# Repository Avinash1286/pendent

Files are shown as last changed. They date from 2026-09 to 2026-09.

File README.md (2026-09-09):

# AURA / pendent

**Capture the context of your life.**

[Explore the A03 showcase](https://pendent-eight.vercel.app) · [Watch the A03 film](https://pendent-eight.vercel.app/film/aura-launch.mp4) · [Download the A03 release](https://github.com/Avinash1286/pendent/releases/tag/a03-context-dev) · [Run the notes portal](portal/README.md)

An open product-development project for a compact necklace AI note-taking device. Electronics, printable industrial design, chip firmware, local transcription, a Next.js / Convex notes portal, an interactive Three.js showcase and a Hyperframes launch film live together here.

## A04 circular redesign — in progress

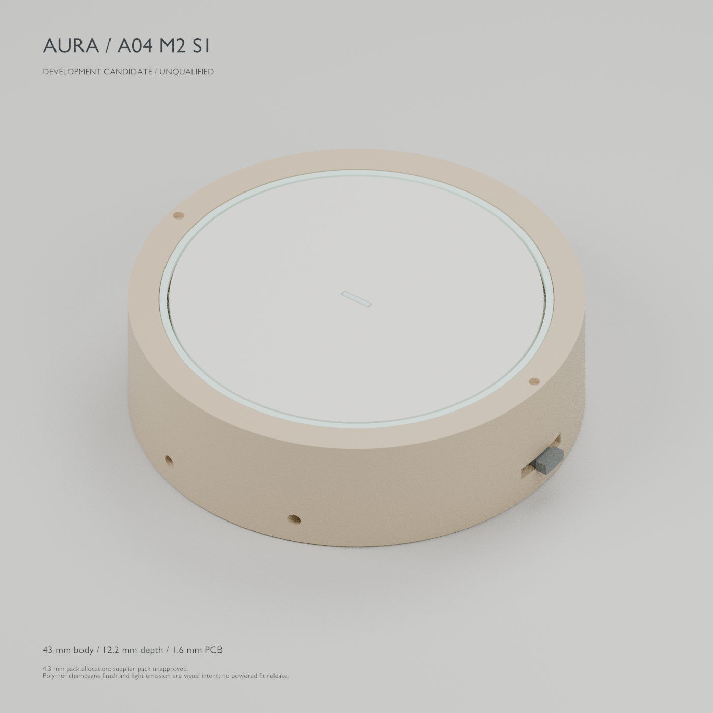
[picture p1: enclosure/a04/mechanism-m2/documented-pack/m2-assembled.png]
AURA A04 M2 S1: actual 43 mm circular development mechanism, pale face and champagne-looking polymer finish; unqualified engineering candidate


A04 is a fresh circular design created through **KiCad MCP**, with a physical microphone disconnect, separate update-storage hardware and a source-preserving audio protocol. The current M2 mechanism is **43 mm across and 12.2 mm deep**, accommodating the actual 1.6 mm draft PCB and a 4.3 mm pack allowance. An 11.2 mm variant requires an unselected thinner pack. The earlier 40 × 10 mm goal remains an aspiration, not the dimensions of these files. **A04 is not ready to fabricate, print as a complete device, wear or sell.**

[Full objective and evidence gates](docs/a04/requirements.md) · [New KiCad project](hardware/a04/aura-a04.kicad_pro) · [Mechanical contract](docs/a04/industrial-design.md) · [Software contract and recovery tests](docs/a04/software-contract.md) · [Omi source review](docs/research/omi-review.md)

The current checkpoint includes a **72-reference schematic candidate**, monitored microphone driver, bounded audio FIFO, recorder, shared C/Python Opus archive, recoverable NAND journal and SPI command core. The [storage owner and release outbox](firmware/a04/STORAGE.md) now reserve capture identities and release explicitly authorized recordings through a durable grant, with real C/Python audio round trips on modeled NAND. The nRF52840 DK build records linked memory and symbols in [the current wired-bench ELF resource report](firmware/a04/bench/verification/arm-resources.json). Host checks cover driver faults, privacy/stop ordering, capture boundaries, interrupted writes and preserved audio during storage reuse. The companion passes 131 tests; the earlier portal checkpoint retains 24. The schematic still has one ERC error, nine warnings and three net-name mismatches; the board is not placed or routed. [Native capture evidence](docs/a04/native-capture-verification.json) · [Firmware and audio evidence](firmware/a04/README.md) · [Route to your first physical wearable](docs/research/aura-first-wearable.md).

The working local software path now takes a **real C-generated audio archive through local Whisper transcription into Next.js/Convex**. It preserves the original capture, exact audio duration, bookmarks and transcript provenance. Interrupted captures remain explicit, and token rotation does not duplicate an existing source. These checks use synthetic speech; microphone, Bluetooth and worn-device behavior still need physical validation. [Try the archive importer](companion/README.md#a04-archive-import--040) · [Read the verification](companion/VERIFICATION.md) · [Portal provenance and recovery](docs/a04/portal-provenance.md).

The new [first spoken-note bench](firmware/a04/bench/README.md) provides a separate nRF52840 DK application, reviewed microphone/NAND wiring and a UART capture/export tool. It connects the actual drivers and storage code, with explicit recording permission and verified local publication. The image cross-builds; 31 host-client tests and five C orchestration groups cover its software behavior. **No physical audio has been recorded or board flashed.** This prepares the hardware experiment needed before the custom PCB and wearable can be qualified.

The [native Android companion](mobile/android/README.md) provides a local recording library: select an A04 archive, validate its original bytes and Opus audio, listen back, write context, and explicitly copy/share that context with an AI chat. The new [durable download store](mobile/android/DOWNLOADS.md) commits exact source records and resume metadata together, replays saved prefixes after reopening, and passes completed downloads through the library's actual decoder and publication checks. The current [development APK](https://github.com/Avinash1286/pendent/releases/tag/a04-android-recovery-dev) passed **29 Android emulator cases / 428 assertions**, with zero lint findings. The shared complete/incremental validator and transfer codecs pass **30 JVM groups / 82,213 checks**, including six incremental groups / 49,471 checks and 19 complete C-generated archives. The real Android GATT path also passed **four virtual-link cases / 33 assertions at each of MTU 23 and 517**, including a second connection without duplicate library entries. The peripheral is a Python fixture, not Zephyr firmware or physical radio. Original recordings and physical-OPEN provenance remain preserved. The Activity still exposes file import; Bluetooth download is not yet a user-facing feature. [Verification](mobile/android/VERIFICATION.md).

A [bounded journal cursor](firmware/a04/JOURNAL-CURSOR.md) prepares pendant-to-phone recovery: exact-record resume, at most one NAND read per step, source checks before streaming and again before completion, and cancellation that preserves the original recording. It is exercised through the wired DK export path. A portable [transfer command owner](docs/a04/transfer-wire-v1.md) adds ordered retries, owned capture selection and protection against stale response callbacks; 12 C test groups pass. Android now has the durable source store, library handoff and [foreground recovery owner with a native GATT client](mobile/android/RECOVERY.md). The device radio DK adapter is now implemented separately; owner enrollment, matching Android proof integration and consumer UI remain, followed by physical recovery and OS background qualification. [Transport integration plan](docs/a04/mobile-transport.md).

The new [authenticated Bluetooth DK application](firmware/a04/radio/README.md) integrates the actual transfer engine with the recording/storage owner. It adds a physically bounded pairing window, authenticated LE Secure Connections and fresh owner proof before archive access. Eighteen GATT/transfer groups, twelve C authentication groups and nine pairing-policy groups pass with their documented modeled boundaries. The ARM image uses 243,652 bytes RAM, leaving 18,492 bytes unallocated; runtime headroom is unmeasured. [Download the DK development build](https://github.com/Avinash1286/pendent/releases/tag/a04-radio-dk-dev). Consumer enrollment, the matching Android proof exchange and physical radio/capture trials remain; the older Android/Bumble tests do not execute this firmware.

The **M2 S1 mechanism** keeps the removable bezel and supported PCB, replacing inadequate resin bending links with a separate steel shoe/support and insulating contact pad. Each depth variant contains **12 polymer part models, three hardware form models and two unpowered gauges**. The metal/film forms are not functional resin-print instructions. Mesh and sampled motion checks cover the revised assembly; analytical force screening supports further unpowered joint testing. Materials, tolerances, switch endpoints, all 72 native PCB features, the battery and real assembly remain unqualified. [Blender source, parts and checks](enclosure/a04/mechanism-m2/README.md) · [Steel development drawings and 1:1 DXF profiles](enclosure/a04/mechanism-m2-manufacturing/README.md) · [Earlier process coupon kit](enclosure/a04/coupon/README.md).

<details>
<summary>Inspect the A04 M2 experimental parts</summary>

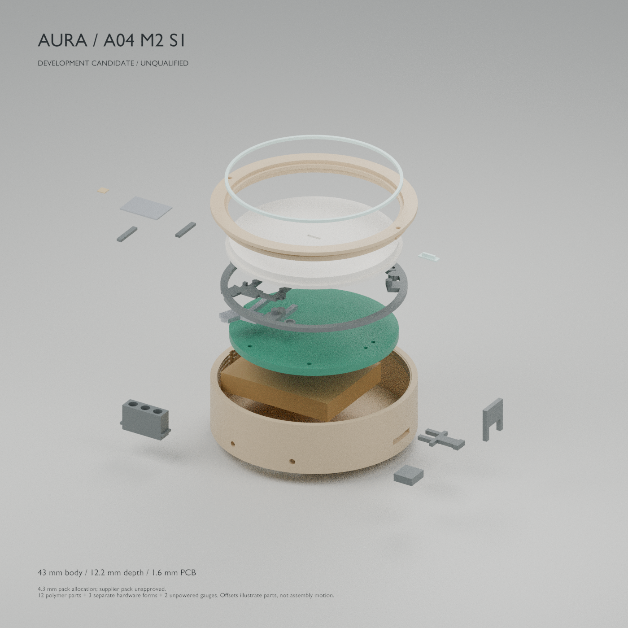
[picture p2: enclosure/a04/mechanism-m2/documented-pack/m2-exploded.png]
Actual A04 M2 S1 experimental part meshes; green board and ochre pack are unpowered fit gauges, not electronics


The exploded offsets show individual parts; separate motion reports check sampled assembly paths. Read the [remaining assembly and release gates](enclosure/a04/mechanism-m2/README.md#assembly-and-release-gates) before using these files. The [M1 experiment and its failures](enclosure/a04/mechanism/README.md) and [original 40 mm appearance study](enclosure/a04/study/aura-a04-study.png) remain available as earlier work.

</details>

The website, film, PCB and eight-part print kit linked below belong to the earlier **A03 development release**. They are retained for reproducibility and are not A04 deliverables.

## A03 development release

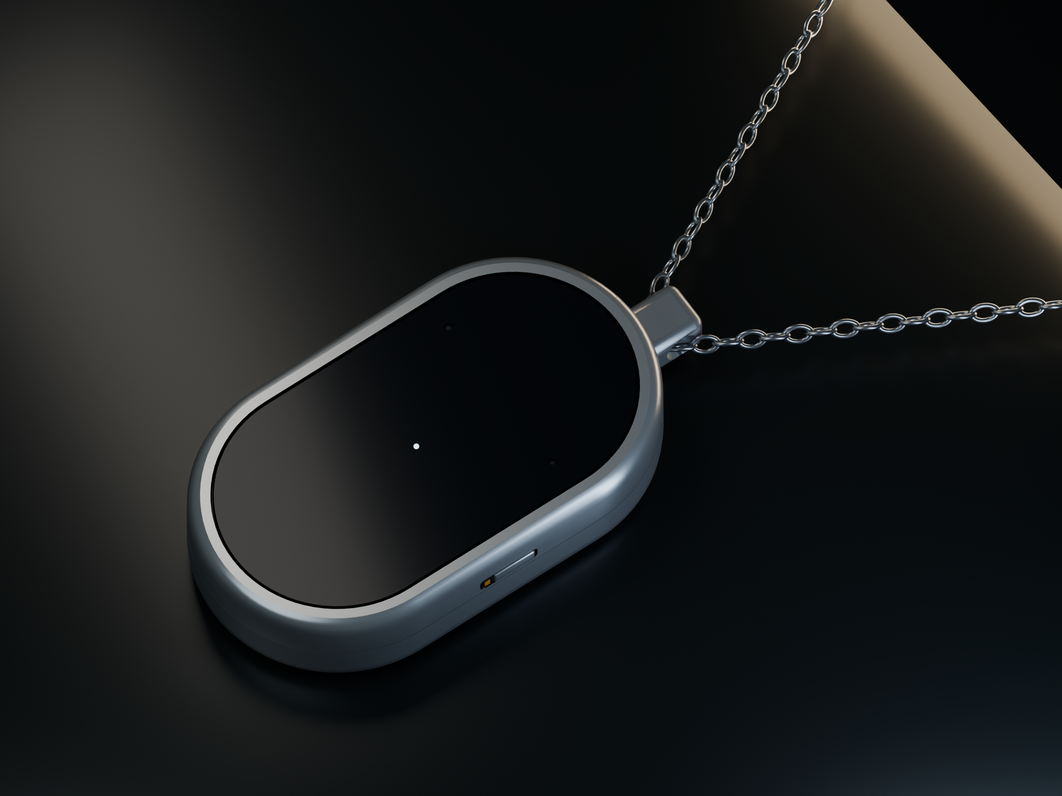
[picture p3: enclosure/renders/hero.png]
AURA A03 capsule pendant with a glossy black recording face, satin surround and necklace chain (https://pendent-eight.vercel.app)


## Launch film

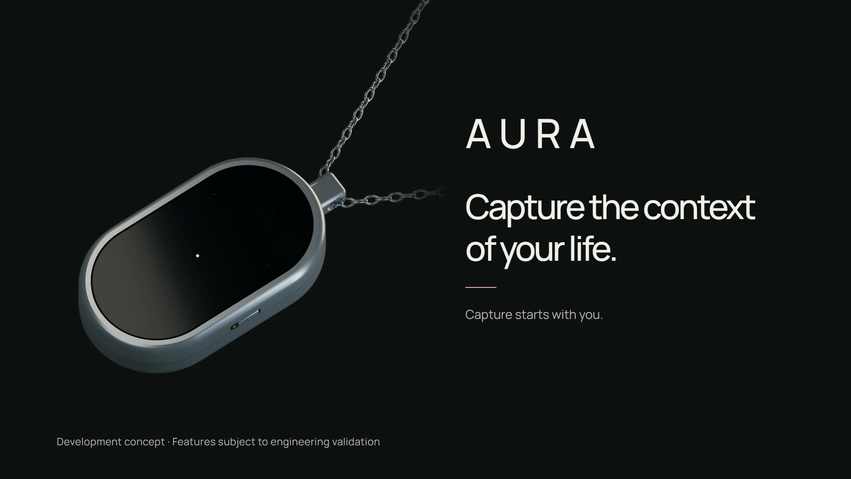
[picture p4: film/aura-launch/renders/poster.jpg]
Play the AURA launch film — Capture the context of your life (https://pendent-eight.vercel.app/film/aura-launch.mp4)


**[▶ Watch the 44-second film](https://pendent-eight.vercel.app/film/aura-launch.mp4)** · [Download the 1080p MP4](https://github.com/Avinash1286/pendent/releases/download/a03-context-dev/aura-launch.mp4) · [Hyperframes source](film/aura-launch/README.md)

See the pendant from the outside in, including its interior and assembly animation. Click the poster to play.

## 3D-printable parts

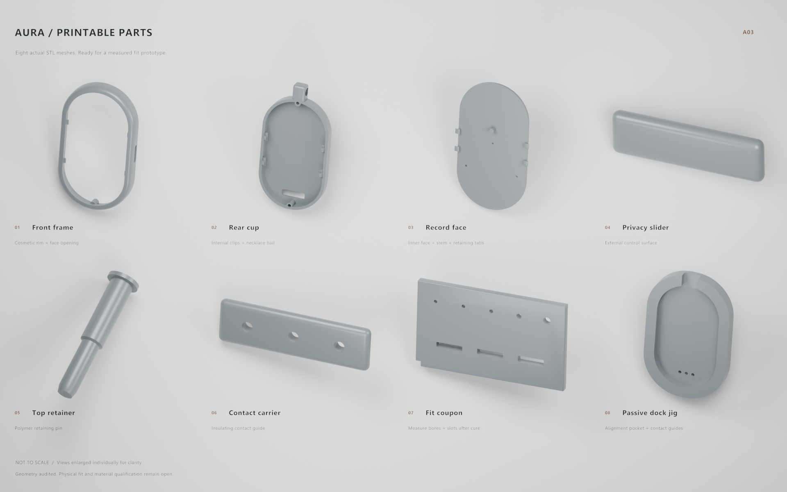
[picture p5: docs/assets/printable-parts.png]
The eight printable AURA parts: front shell, rear shell, recording face, privacy slider, top retainer, contact carrier, fit coupon and dock alignment jig


Rendered from the actual STL files; individual views are not to scale. The kit includes six device parts and two fit/alignment tools. STL units are millimetres; print orientation and material guidance are in the assembly guide.

[Download all eight STL files](enclosure/aura-a03-print-kit.zip) · [Print and assembly guide](enclosure/PRINTING.md) · [Editable Blender scene](enclosure/aura-product.blend)

## PCB

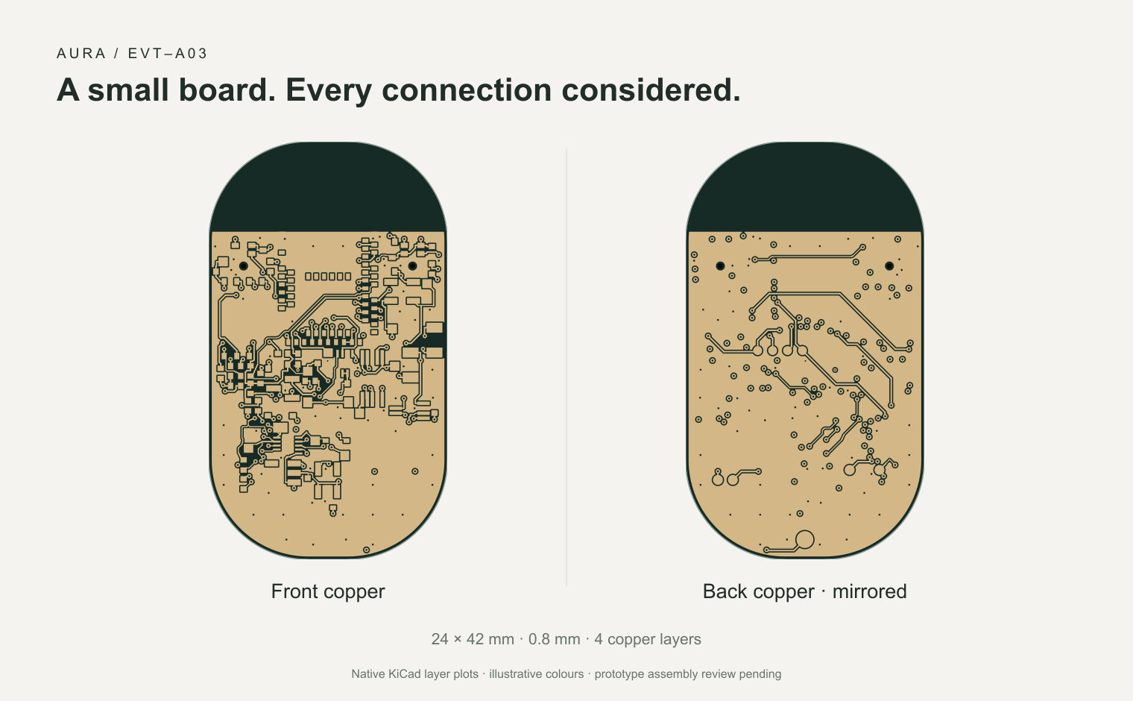
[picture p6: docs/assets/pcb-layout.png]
AURA A03 PCB front and mirrored back copper layouts, exported from the released KiCad board


The **24 × 42 × 0.8 mm, four-layer board**, shown directly from its native KiCad copper layers with illustrative colours. These are prototype files; the 78 courtyard findings still require assembly review.

[Editable KiCad project](hardware/native/aura-a03.kicad_pro) · [Prototype fabrication ZIP](hardware/output/aura-a03-prototype-fabrication.zip) · [Schematic and review files](hardware/native/review/)

## Project status

**A03 context and assembly edition.** [Prototype fabrication files](hardware/native/README.md) are exported from the paired KiCad project: zero unconnected items, schematic mismatches, ERC findings or bare-board DRC errors. **78 unsuppressed courtyard overlaps remain for assembly review.** The case has printable meshes with geometric audits; real fit, battery, acoustic and RF tests remain. Firmware is compiled for the nRF52840 but has not run on an assembled AURA. The notes portal uses real local Convex; cloud setup awaits account terms acceptance. This is not a manufactured or certified device, and no orders or payments are accepted. See the [current release guide](docs/release-a03-context.md) for downloads and verification.

## Project map

New: [Omi codebase review and AURA first-wear plan](docs/research/omi-review.md), with a source-based comparison, all 78 assembly collisions classified, and companion recovery improvements. This review identifies a real component-tolerance conflict that requires an A04 placement revision; it does not qualify A03 for assembled-unit ordering.

| Directory | Contents |
| --- | --- |
| `hardware/` | tscircuit source, routed native KiCad board, readable schematic, BOM and validation evidence |
| `enclosure/` | Blender source, editable generator, printable enclosure meshes, GLB and product renders |
| `firmware/` | Zephyr nRF52840 firmware, reproducible tool setup, flashable build artifacts and native tests |
| `companion/` | Bluetooth sync, CRC verification, local Whisper transcription and optional portal upload |
| `mobile/android/` | Native Kotlin local import, durable download storage and replay, verified playback, private context and explicit sharing; A04 wireless integration pending |
| `portal/` | Next.js / Convex private notes, profiles, Context Pack and read-only MCP endpoint |
| `website/` | Interactive React / Three.js product presentation, deployed directly to Vercel |
| `film/` | Hyperframes composition, original soundtrack and rendered launch video |
| `docs/` | Hardware and product engineering notes |

## Design direction

- 48 × 28 × 10 mm capsule body, 54 mm tall including the bail; 24 × 42 mm PCB.
- A glossy black recording paddle in a satin polymer surround, a bookmark gesture, visible microphone-power indication and a physical privacy slider.
- A physical microphone power disconnect, offline local audio storage and Bluetooth transfer to the companion.
- Dual digital microphones, a protected rechargeable-cell candidate and rear contacts for a magnetic charging dock; the complete dock remains to be designed and qualified.
- Local computer transcription and optional notes upload are implemented. The A04 Android source-import and durable download-storage foundation is available; device-to-phone wireless integration remains future work.
- 16 kHz mono PCM storage has an ideal capacity of about 66 minutes before bad blocks and metadata; battery runtime is unmeasured.

## Start exploring

- [Product and interaction specification](docs/product-design.md)
- [Hardware source and validation](hardware/README.md)
- [Print and assembly guide](enclosure/PRINTING.md) · [eight-part print kit](enclosure/aura-a03-print-kit.zip) · [editable Blender scene](enclosure/aura-product.blend)
- [Firmware build / flash / bring-up](firmware/README.md)
- [Install the local companion](companion/README.md)
- [Run AURA Notes and connect any AI](portal/README.md)
- [Launch film and reproducible Hyperframes source](film/aura-launch/README.md)

The portable **Context Pack** combines your selected notes, source excerpts, personal background and current goals into reviewed Markdown. Copy or attach it in ChatGPT, Claude, Gemini, Grok, or another chat. Compatible MCP clients can instead read explicitly approved live context through a revocable bearer token. Provider buttons do not send data automatically.

## Publication

Sources and generated deliverables are shared here. Website deployment uses Vercel directly; this project does not use GitHub Actions. Dependencies, signing keys, tokens, private local recordings and database files are intentionally excluded. Each workstream documents reproducible setup and the checks actually completed.

## Upstream tools

[tscircuit documentation](https://docs.tscircuit.com/) · [Blender](https://www.blender.org/) · [Three.js](https://threejs.org/docs/) · [Hyperframes](https://github.com/heygen-com/hyperframes) · [Vercel](https://vercel.com/docs)

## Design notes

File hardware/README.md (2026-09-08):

# AURA pendant electronics · EVT-A03

Start with the [paired native KiCad project and manufacturing guide](native/README.md). It contains the routed 24 × 42 × 0.8 mm four-layer board and readable six-sheet schematic for the 48 × 28 × 10 mm capsule.

**The board is connected; assembly qualification remains open.** Native schematic verification matches 61 references, 43 intended nets, 208 connected pins and 37 intentional NC pins, with zero ERC findings. Final native DRC, exports and their exact limitations are in [`native/review/`](native/review/). Courtyard/assembly findings remain visible. A connected board and valid fabrication files do not establish a qualified assembled wearable.

## Open or manufacture a prototype

Open [`native/aura-a03.kicad_pro`](native/aura-a03.kicad_pro) in KiCad 10. See [fabrication files](native/fabrication/), [BOM, positions and stencil files](native/assembly/) and [review PDFs/reports](native/review/). Read the native manufacturing guide before sending any files to a supplier. Use the matched Gerbers, PTH/NPTH drills and stack specification from the same package.

The native project carries exact per-reference footprint snapshots, portable library paths and schematic/PCB UUID links. The tscircuit export is a placement reference; it is not a substitute for the completed native routing. Keep the native project as the authority when changing copper, and reconcile source/firmware/enclosure contracts when changing circuitry or component placement.

## Reproduce the authored design

```sh
npm ci
npm run build
npm run export
npm run verify-export
npm run verify
```

Node 22+ and the project-local Bun runtime build the authored tscircuit schematic/placement and logical checks. The native reconstruction repairs the converter's electrical-label, NC, electrical-type and library-reference omissions; see the [schematic audit](../docs/schematic-audit.md). The generated `output/aura.kicad_sch` remains a superseded converter diagnostic, not the current schematic.

KiCad MCP was used for native schematic work. Its SES import returned an unexplained cancellation. The user explicitly authorized the source/CLI fallback, after which the native session was imported and the remaining routes, antenna exclusion and ground connectivity were completed. Historical KRT/Freerouting attempts are retained as evidence; they are not the current fabrication files.

## Files and verification

- `src/design.ts`, `AuraPendant.tsx`, `placement-overrides.json`: selected components, logical pin maps, mechanical contract and current component positions.
- `native/`: paired editable release project and its manufacturing/review exports.
- `library/`, `library.pretty/`, `pcb-snapshot.pretty/`: original lands, authored custom contacts/SiCap lands and exact native snapshots. [Attribution](library/NOTICE.md).
- `output/aura-a03-native-routing.kicad_pcb`: frozen working route used to create the paired project.
- `output/aura-a03-electrical.kicad_sch`: original native reconstruction, retained with its independent ERC and exact netlist audit.
- `scripts/pair-native-project.py`, `scripts/export-native-package.py`: native project pairing and guarded export entry points. KiCad's Python provides `pcbnew`.
- `scripts/package-status.mjs`, `scripts/package-native-archive.py`: verify current export hashes and produce the portable [prototype fabrication ZIP](output/aura-a03-prototype-fabrication.zip) with its [checksum report](output/aura-a03-prototype-fabrication-manifest.json).
- `scripts/audit-native-pad-spacing.py`, `scripts/audit-native-via-apertures.py`: actual native copper/paste geometry checks; both accept `--board native/aura-a03.kicad_pcb`.
- [Hardware dossier](../docs/hardware.md), [electrical review](../docs/electrical-review.md), [thermal review](../docs/thermal-review.md): rationale, source evidence and physical qualification work.

Optional routing-analysis scripts use the pinned packages in `requirements-native.txt`, installed into the ignored `tools/python/` directory with Python 3.11. They are dependencies, not design artifacts. The original routing experiments also use [Freerouting 2.4.1](https://github.com/freerouting/freerouting/releases/tag/v2.4.1) and Java 25. The JAR SHA-256 is `251101c3eeac22d7e7dfcf6796603279e5d1000283eb82d8f093780f7afc6aa9`; keep it in `tools/`. It is excluded from Git. See `scripts/route-freerouting.ps1` for bounded execution and optimization settings.

The [firmware](../firmware/README.md) performs local recording, recoverable storage and Bluetooth transfer. The [desktop companion](../companion/README.md) performs local transcription and optional transcript upload to [AURA Notes](../portal/README.md). No language model runs on the pendant. Physical power, battery, audio, RF, fit and security qualification remain outstanding; the supplied firmware keeps charging and haptics disabled pending those measurements.

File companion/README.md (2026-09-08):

# AURA local companion

Python3.12, Bleak3 and faster-whisper. The companion transfers committed audio from AURA, checks each packet and the complete recording, creates a normal WAV, and transcribes locally. It runs on Windows, macOS and Linux with a supported Bluetooth adapter. It is a desktop companion; this package is not an iOS/Android app.

## A04 archive import — 0.4.0

The new local file path connects the C Opus encoder's **experimental revision-3 archive** to verified audio, transcription and portal provenance. It does not provide A04 Bluetooth or firmware for a physical pendant. A03 `scan`/`sync` commands below still use their original v1 protocol; old experimental v2 and AOC1 test-container bytes are rejected by this importer.

From `companion/`, with the pinned dependencies installed:

```sh
uv run --locked aura import-capture ../firmware/a04/fixtures/capture-20ms.aura --output recordings
uv run --locked aura import-capture ../firmware/a04/fixtures/capture-20ms.aura --output recordings --transcribe --model tiny.en --language en
```

These checked-in fixtures contain synthetic test speech. The second command runs real local Whisper transcription; initial model download may require network access. Add `--upload` only when you want the resulting text and provenance sent to your configured portal. `--upload` requires `--transcribe`. Raw audio remains local.

Import verifies a bounded archive snapshot, commits the complete source and terminal receipt in SQLite, exports Ogg Opus/mono 16 kHz WAV and publishes `.capture.json` last. The `.aur`, `.wav`, `.capture.json` and `.receipts/` files together preserve the source and its verification; `.opus` is a portable listening export. Keep the bundle and back it up. A file-level commit does not establish physical flash/power-loss guarantees, and this command sends no receipt or deletion request to a pendant.

Each filename binds the device, capture and terminal revision digest. Repeat imports verify and reuse a committed bundle without re-decoding it. New exports record decoder/library versions. A missing final sidecar after interrupted publication can be repaired by reimport; conflicting or corrupt existing files are preserved and rejected. One OS-held lock serializes import into each output directory. The input bound is 320 MiB, the protocol payload bound 256 MiB and the metadata bound 1,000 bookmarks; production mobile/storage limits still need measurement.

Interrupted source recovery is explicit:

```sh
uv run --locked aura import-capture ../firmware/a04/fixtures/capture-20ms-interrupted.aura --output recordings --allow-interrupted
```

Only complete verified records are retained. The original total duration remains unknown; a bookmark in lost encoder-tail audio is labelled unavailable. A recovered prefix and a later finalized source remain separate local revisions. The portal currently returns a source conflict for those differing revisions under one capture identity until an explicit review/promotion workflow is implemented.

Transcription rechecks the sibling source archive, receipt, exact WAV hash/dimensions and recovery metadata before attaching provenance. Notes preserve segments, method/model/version, capture time confidence and bookmarks. Unknown time stays unknown. Existing note JSON is saved under `.note-revisions/` before a different current note replaces it, including when a sidecar was accidentally removed. Hashes and capture IDs detect inconsistency; they do not authenticate a physical device.

Inference reads a private WAV snapshot verified against the initial source, then rechecks the original bundle before attaching that identity. Temporary snapshots are removed on normal/error exit; an abrupt process termination may leave one in the operating system's temporary directory. Revision publication flushes files and, on POSIX, their directory chain before replacing the current note. Windows uses file flush and atomic replacement without an equivalent directory-persistence guarantee here. Preserve backups; these operations have not been physically power-cut qualified.

[Wire specification and C implementation](../firmware/a04/ARCHIVE.md) · [Portal source contract](../docs/a04/portal-provenance.md) · [Real synthetic transcription fixture](tests/assets/a04-capture.note.json) · [Local portal integration evidence](../portal/verification/a04-provenance-local.json).

## Install and run

Install [uv](https://docs.astral.sh/uv/getting-started/installation/), then from this directory:

```sh
uv sync --locked
uv run aura --help
uv run aura scan
uv run aura status --device DEVICE_ADDRESS
uv run aura sync --device DEVICE_ADDRESS --output recordings --transcribe
```

Hold the idle pendant's recording face for three seconds to open its pairing window. The operating system may ask to pair. Replace DEVICE_ADDRESS with the value returned by scan; on macOS this may be an OS-assigned UUID. A03 firmware implements the [shared protocol](../docs/ble-protocol.md). Real Bluetooth/board operation requires the hardware bring-up checks; tests here use a simulated GATT peer.

`sync` saves `.wav` and verified metadata `.json`. Stop recording and wait for saving to finish before syncing; A03 rejects audio reads during an active capture. It keeps partial PCM for resuming interrupted transfers and never deletes device recordings. Rerunning sync checks an existing WAV's complete PCM checksum, length, format and matching recording metadata, then reuses it without transferring its audio again. A missing WAV is downloaded even if a receipt exists. Corrupt or conflicting files are preserved and rejected; inspect them or choose a separate output directory before retrying.

Filenames contain the **recording ID** and audio CRC, not a unique hardware identity. Use a separate output directory for each pendant and one sync process per directory. AURA v1 does not provide an authenticated device identifier. CRC detects accidental corruption; it is not a cryptographic authenticity guarantee.

If a previous run stopped after writing the WAV but before publishing its receipt, sync verifies the WAV against the device's current recording metadata and repairs the missing receipt. Files are flushed before atomic publication. The device copy remains available until you explicitly delete it; file-level replacement does not guarantee an atomic transaction across all files or survival of every filesystem/power fault.

## Local transcription and notes

```sh
uv run aura transcribe recordings/your-recording.wav
uv run aura transcribe recordings/your-recording.wav --model tiny.en --language en
```

The default multilingual `base` Whisper model runs on the CPU with8-bit inference. The first transcription downloads model files from the upstream model host; after the cache is populated, audio processing is local. No audio is uploaded by these commands. `--model` can point to a local CTranslate2 Whisper model directory for an offline installation. Adding the explicit `--upload` flag uploads the resulting text note, as described below; the original audio stays local.

Each transcription creates `.note.json` and Markdown with timestamps. The default summary is an explicitly labeled extractive baseline that selects original sentences; it does not pretend to be an LLM. Suggested actions match explicit phrases in the speaker's words and remain drafts.

During `sync --transcribe`, the companion first transfers the recordings, closes the Bluetooth session, then processes verified WAVs locally. Slow transcription or an upload failure cannot keep the radio session open or prevent already downloaded later notes from being processed. Failures still produce a nonzero result with recovery guidance. Rerunning `sync --transcribe` reuses verified audio but currently processes the notes again; it is not an automatic work-queue service. To retry just an upload, run `aura upload PATH.note.json`.

A `.sync.json` receipt records the last processing stage and its started/completed/failed status with a bounded error code. It contains no transcript, credential or raw exception. “Completed” refers to the named stage, not necessarily the whole pipeline; a run interrupted after transcription may still need note generation. The receipt does not schedule uploads or retries.

Each note file is written through a flushed temporary file and atomic replacement. The `.note.json` file is authoritative, while Markdown is a regenerable presentation of it; the pair is not a multi-file filesystem transaction.

For a more flexible local summary, install [Ollama](https://ollama.com/) and a suitable model separately, then pass its installed name:

```sh
uv run aura transcribe recordings/your-recording.wav --ollama YOUR_INSTALLED_MODEL
```

This optional request goes only to `http://127.0.0.1:11434`. The result is schema-checked and labeled as model-generated. Review names, dates, numbers and suggested actions against the audio. No tasks, messages or calendar events are created automatically.

## Explicit deletion

```sh
uv run aura delete --device DEVICE_ADDRESS --metadata recordings/VERIFIED_RECORDING.json --confirm
```

The companion rechecks the local WAV's format, size and CRC before sending a deletion request. Firmware must also match the recording ID, length and CRC. Local audio is retained. Keep a separate backup before deleting an irreplaceable device recording.

## Reuse device storage

The first firmware release uses an append-only journal. Individual deletion adds a tombstone; capacity is reclaimed through explicit maintenance after every recording has been exported and deleted. It never automatically erases a live recording.

1. Sync and verify all recordings, then use `delete --metadata ... --confirm` for each one.
2. Hold the idle pendant face for ten seconds. This grants maintenance permission for thirty seconds; the hold alone does not erase anything.
3. Run the command below. Keep the unit on its reviewed power supply while all NAND blocks are erased and verified.

```sh
uv run aura format --device DEVICE_ADDRESS --confirm
```

The companion requires an empty device STATUS, and the firmware independently requires no active capture, committed deletion of all notes, and the recent physical hold. It retains Bluetooth bonds, recording-ID continuity and all local files. The operation can take up to ten minutes. If disconnected or timed out, do not automatically repeat the command: keep power connected and reconnect to inspect recovery. The MCU stores erase intent before starting and resumes an interrupted erase before exposing notes again. Do not mass-erase the MCU's NVS partition while that recovery is pending. This maintenance operation does not guarantee secure erasure of data in failed NAND blocks.

## Explicit portal upload

The portal stores text notes in its Next.js/Convex backend. Configure its private ingestion credential in your environment; never commit a real token. `.env.example` lists the names. `uv run --env-file .env.local ...` can load a local file, or set variables in your shell:

```powershell
$env:AURA_PORTAL_URL = 'https://YOUR-PORTAL.vercel.app'
$env:AURA_INGEST_TOKEN = 'YOUR-PRIVATE-INGESTION-TOKEN'
uv run aura upload recordings/your-recording.note.json
```

You can opt into upload after local processing:

```sh
uv run aura transcribe recordings/your-recording.wav --upload
uv run aura sync --device DEVICE_ADDRESS --output recordings --transcribe --upload
```

`sync --upload` requires `--transcribe`. There is no upload by default. The companion sends title, transcript, summary, suggested actions, tags and a recording timestamp to `/api/ingest` with a bearer token; it never sends the WAV. For legacy notes without capture provenance, the upload identity is a SHA-256 of the sibling WAV, so retrying or editing a note's title does not create another identity. If its audio file is absent, a canonical note hash supplies a stable fallback. Prefer retaining the WAV for a consistent identity across edits. Legacy `recordedAt` comes from explicit note metadata, then the verified recording's time, then source-file modification time when the capture time is unknown. A04 captured notes instead retain their manifest time/confidence (including unknown time as zero), immutable device/capture identity, archive receipt digest, segments, transcription method and bookmarks. Token rotation deduplicates these captures within the authenticated owner; a conflicting source revision is rejected for review. No source authenticity is inferred from an ID or checksum.

The client permits HTTPS, plus loopback HTTP for local development, and refuses redirects entirely so the bearer token cannot be forwarded to a different origin. A successful response must explicitly confirm `{id, stored:true}`. A failure preserves local files and is not silently retried. Public demonstration portals may lack private ingestion configuration; the command requires your configured backend credential.

## Verification

```sh
uv run python -m unittest discover -s tests -v
uv run aura transcribe tests/assets/sample.wav --model tiny.en --language en
```

Tests cover corrupt packets, metadata validation, interrupted-transfer resume, verified download reuse, incomplete-publication recovery, WAV formatting, complete CRC verification, atomic-file failure handling, no automatic device deletion, processing after disconnect, extractive-note provenance, explicit maintenance confirmation/magic/timeout, stable upload identity, URL validation and an actual loopback HTTP upload with redirect refusal. See [verification results](VERIFICATION.md) for the latest executed count. The synthetic speech fixture was generated locally through Windows speech synthesis solely for the transcription smoke test. These checks do not establish acoustic quality, the physical BLE link or a deployed production Convex backend.

Upstream: [Bleak](https://bleak.readthedocs.io/en/latest/) and [faster-whisper](https://github.com/SYSTRAN/faster-whisper). Installed versions are pinned by `uv.lock`.

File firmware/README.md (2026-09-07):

# AURA A03 firmware

An actual Zephyr application for the **Raytac MDBT50Q-1MV2 / nRF52840** on the A03 PCB. It records without a phone, saves recoverable audio to W25N01GV SPI NAND, and serves recordings over encrypted Bluetooth to the [companion](../companion/). This firmware does not run transcription or an LLM on the pendant.

This is engineering firmware, not a claim of tested physical hardware. The release image keeps charging permission and haptics disabled until the assembled battery, thermistor, charger and motor are qualified. The application, host tests, board source and resulting ARM artifacts are included for reproduction and bring-up.

## Build and flash

The tested Windows toolchain is Zephyr **v4.2.0** (`413b789deb391d3a37d06b463288a5fe765ee57e`), Zephyr SDK **0.17.2**, ARM GCC **12.2.0**, Python **3.12**, West **1.4.0**, CMake **3.31.6** and Ninja **1.11.1.4**. Setup downloads official pinned Zephyr modules and verifies SHA-256 hashes of the SDK archives. It needs Git, `uv`, Windows `tar` and `curl` on PATH. Tools and intermediates go in the repository's ignored `.tools/zephyr` directory.

From the repository root in PowerShell:

```powershell
./firmware/scripts/setup.ps1
./firmware/scripts/test.ps1
./firmware/scripts/build.ps1
```

The default build writes `release/aura-a03.hex`, `.bin`, `.elf`, `.map`, `build.config` and a SHA-256 manifest. HEX includes absolute MCU flash addresses; raw BIN starts at address `0x00000000`. ELF retains debugging information. The final 32 KiB of MCU flash is reserved for Bluetooth bonds and maintenance state. Do not mass-erase that partition during an interrupted storage format: its erase-intent marker protects recovery.

Connect a compatible SWD probe to J3: pad 1 target-reference 3.0 V, pad 2 SWDIO, pad 3 SWCLK, pad 4 RESET, pads 5/6 GND. A probe's target-reference input is not necessarily a power output. Use the reviewed current-limited supply arrangement during bring-up. With SEGGER J-Link and its software installed:

```powershell
$env:PATH = (Resolve-Path .tools/zephyr/venv/Scripts).Path + ';' + $env:PATH
west flash -d .tools/zephyr/build-aura --runner jlink
```

SWD flashing is implemented; signed boot, authenticated DFU and debug locking are not. Do not ship this image as a consumer security release. Reproduce on Linux/macOS by using the same Zephyr commit/modules and matching host SDK, then `west build -b aura_a03/nrf52840 firmware`; the included automation is Windows-specific.

## What the code does

| Area | Implemented behavior |
|---|---|
| Capture | Two interleaved PDM channels, arithmetic mono mix, PCM16 LE output at 16 kHz. Audio runs in its own thread with eight DMA buffers. |
| Clock | Module LFRC with Zephyr calibration. PDM is constrained to 1.280 MHz (32 MHz / 25) and Zephyr selects RATIO80, producing exactly 16,000 input samples/s. This falls within the microphone's standard-mode clock range. No resampling is needed. A 50 ms rail delay plus two discarded 40 ms DMA blocks allow microphone/decimator startup. |
| Gesture | Debounced face paddle; single press starts/stops after a 300 ms double-press window; double press while recording journals a bookmark; idle three-second hold opens pairing for 60 seconds. Ten-second hold opens maintenance permission for 30 seconds. |
| Privacy | OFF is P1.08 HIGH. The switch physically removes microphone power; a GPIO interrupt also drops microphone enable. Firmware never exposes a remote start command. The amber indicator is powered by the microphone rail. |
| Storage | Correct SPI NAND commands, JEDEC `EF AA 21` check, internal ECC, factory bad-block scan, readback after every page program, CRC-protected page journal and interrupted-note recovery. No overwrite of unique audio. |
| Transfer | Encrypted GATT, long reads, per-chunk CRC and full-record CRC, exact size/CRC deletion guard. Only completed or recovered notes are listed. The peripheral requests MTU 247; default-MTU clients can still use long reads. Stop recording before transferring audio. |
| Reuse | Explicit maintenance erase after all notes were explicitly deleted; MCU NVS intent guarantees interrupted erase resumes before notes become visible. Recording ID floor persists across maintenance. |
| Power | MAX17048 voltage reads, start threshold 3.5 V, active-record stop below 3.3 V or on gauge failure. Microphones are gated outside capture. Charger permission is default LOW, with a separate hardware hot cutoff. |
| Watchdog | 8-second reset watchdog after storage recovery; feeds require audio-thread progress. Privacy remains physically independent. |
| Haptic | Optional C08-00A initialization and auto-calibration, reduced engineering voltage targets, short RTP pulse. Disabled in the distributed image until measured qualification. |

At 32,000 PCM bytes/s, the ideal capacity is about **66 minutes** before note/marker overhead, factory bad blocks and reserve pages. This is an arithmetic upper bound, not measured endurance or battery runtime. At most 128 journaled note IDs are indexed per maintenance cycle, including deleted notes. Deletion hides a note and appends a tombstone; storage capacity returns only after the explicit maintenance erase. This conservative implementation does not claim wear leveling or online garbage collection.

Bookmarks are preserved as byte offsets in journal records. Protocol v1 does not yet export bookmark records; the transferred WAV contains the audio only. Time is set by the companion and advances from uptime. Before time synchronization, timestamp zero means unknown. Time does not survive full power loss; recording IDs and committed audio do.

## Pin map

| Signal | MCU pin | A03 function |
|---|---|---|
| PDM clock / data | P0.04 / P0.05 | Dual PDM microphones through Ioff buffer |
| Microphone enable | P0.06 | HIGH permits recording regulator |
| Record paddle | P0.08 | Active LOW |
| Privacy OFF | P1.08 | HIGH means microphones OFF |
| SPI MOSI / MISO | P0.14 / P0.13 | NAND |
| SPI SCK / CS | P0.16 / P0.15 | NAND, mode 0, 8 MHz |
| I2C SCL / SDA | P0.27 / P0.26 | MAX17048 at 0x36, DRV2605L at 0x5A |
| Haptic enable | P0.17 | Default LOW |
| Gauge alert | P0.19 | Routed; baseline polls voltage |
| Charge status 1 / 2 | P0.21 / P0.20 | Routed; not interpreted by baseline UI |
| Charge permission | P0.23 | HIGH only permits the independent thermal gate |
| Reset | P0.18 | SWD reset |

The authoritative circuit is [hardware/src/design.ts](../hardware/src/design.ts). The custom board does not inherit development-kit LEDs or UART pins that collide with NAND. There is no external LF crystal in this assembly.

## Storage and power-loss behavior

Each 2,048-byte NAND page contains a 40-byte header and up to 2,008 bytes of payload. A header identifies revision, record type, note ID, PCM offset, payload length, time, expected record CRC and flags. CRC32 covers the first 36 header bytes plus payload. Types are START, DATA, END, DELETE and MARK. Each page is programmed once and read back. The first two pages of every block remain unused so manufacturer main-area and spare-area bad-block markers stay intact.

Boot scans every usable page; an erased hole is not assumed to be the end of data. START creates an index entry. Contiguous valid DATA pages extend its size and CRC. A valid matching END commits it. Missing/torn END or last DATA page leaves a recovered note containing prior valid pages, flagged as interrupted. Uncorrectable ECC returns an error; the code does not silently recalculate a new CRC and pretend corrupted committed audio is intact. Runtime program/read failures stop capture and retain recoverable data. Faulty used blocks are not erased or remapped while they may contain unique audio.

The scan and full maintenance verification read the entire device and may take minutes; startup currently favors conservative recovery over instant readiness. Storage speed, read disturb, wear distribution, new bad-block retirement and crash injection on real NAND remain release work. Do not rely on this prototype as the sole copy of irreplaceable recordings.

READ is rejected with FORBIDDEN while capture is active or starting. This prevents a distant random seek from holding the NAND mutex long enough to exhaust audio DMA buffers. During a permitted read the unit briefly reports saving/busy and does not accept a new capture. Sequential requests retain a page cursor. An interrupted long seek can be retried after the previous command completes; no audio is deleted by a read timeout.

## Bluetooth and maintenance

The exact base contract is [docs/ble-protocol.md](../docs/ble-protocol.md). A03 adds opcode **6 FORMAT**, request payload little-endian `u32 0x53415245` (bytes `ERAS`), empty successful response. It is forbidden unless the unit is idle, every recording has a committed explicit-delete tombstone, and the user held the face paddle for ten seconds within the previous thirty seconds. Each attempt consumes that permission. Normal command timeout is 30 seconds; FORMAT may need up to 600 seconds while erasing and verifying every usable block. A disconnect does not cancel an accepted format. If power fails, reconnect after recovery; do not automatically resend a destructive command.

Before any erase, the MCU's NVS stores the next-ID floor and durable format intent. Recovery checks this state before mounting/exposing NAND notes. A failed/interrupted erase leaves intent set and resumes on reboot. Completion clears intent only after all good blocks were erased, read back and mounted as an empty journal. Bonds are preserved. Factory-bad blocks are skipped. This is not a cryptographic secure erase: data remnants in bad NAND blocks may remain.

Only physically opened pairing windows allow new Secure Connections bonds. Otherwise advertising uses the bonded-address accept list. The device has no display and uses Just Works association, so encryption is **not authenticated MITM protection**. Audio at rest in NAND and bond secrets in MCU flash are not protected against physical extraction. Secure boot, at-rest authenticated encryption, provisioning, debug lockdown, signed updates and a defined factory-reset policy are still required for a consumer release.

## Charging and haptic qualification

The distributed `prj.conf` intentionally has both `CONFIG_AURA_CHARGE_QUALIFIED=n` and `CONFIG_AURA_HAPTIC_QUALIFIED=n`. This image will not recharge a battery or vibrate. Its recording/transfer functions can be brought up with a reviewed, current-limited supply or already charged qualified pack. A deliberately separate configuration enables these paths:

```powershell
./firmware/scripts/build.ps1 -QualifiedHardware
```

That command builds into `build-aura-qualified`; it does not replace the default distributed release. Enable only after completing the following measurements and saving their evidence:

1. Confirm exact protected-pack dimensions, 4.221 V maximum charger acceptance, allowed peak system current and NTC attachment. Scope P0.23 LOW through boot/reset/brownout and the comparator-valid delay. Review [thermal-review.md](../docs/thermal-review.md).
2. Measure charge current and terminal voltage. Inject open/short NTC and hot/cold conditions in the closed enclosure. Confirm the independent TLV6700 path prevents firmware from overriding the hot stop. Confirm stable adapter-mode TS bias and thermal lag.
3. Verify depleted-cell startup from SYS and recovery through the qualified voltage range. The baseline inhibits charging if gauge reads fail or reports below 2.0 V/above 4.25 V; pack protection and BQ precharge/recovery behavior require bench verification. Do not defeat that guard to recover a damaged cell.
4. Verify the exact C08-00A variant, motor wiring, 240 Hz resonance and DRV2605L auto-calibration. The candidate is rated 1.2 Vrms, maximum 1.25 Vrms; source targets approximately 0.84 Vrms with a conservative clamp. Scope RMS and peak waveform throughout calibration and RTP playback; register arithmetic alone is not a voltage measurement. Qualify comfortable pulses and enclosure acoustics before enabling feedback.

## Verification and remaining bring-up

[verification/host-tests.txt](verification/host-tests.txt) records 14 actual native test cases using the same journal, gesture, PCM mixer and maintenance C code used in the firmware. Cases include known CRC vector, cross-page read, wrong delete metadata, missing END, torn program, uncorrectable ECC, bad block skip, capacity reserve, bounce/hold/double press, signed PCM mixing and interrupted erase. [verification/nand-tests.txt](verification/nand-tests.txt) adds four cases executing the production NAND serializer against a strict simulated SPI chip: JEDEC/features/markers, program order/readback, ECC/program failures and erase verification. These simulations do not test actual SPI silicon, soldering, RF performance or battery.

Bring up in this order: unpowered inspection; current-limited rails; SWD; gauge; NAND ID/features/markers; program/read/ECC injection; microphone OFF leakage and signal back-power; actual PDM timing and acoustic capture; repeated unplug during DATA/END/DELETE/FORMAT; BLE pairing/bond persistence and interrupted long reads; qualified charging and haptics; closed-enclosure thermal/RF/acoustic/ESD testing; measured sleep/capture/sync endurance. Verify the transfer/capture mutual-exclusion policy under rapid button presses and incoming requests. Run stack high-water instrumentation and long recordings before accepting the 4 KiB audio thread stack.

## Sources and licensing

Application code is MIT under the repository license. Zephyr is Apache-2.0 and includes separately licensed modules; the release links Nordic HAL, Mbed TLS and the SDK C library under their upstream terms. The setup pins upstream sources instead of checking third-party SDK binaries into GitHub. Release notices are in [THIRD_PARTY_NOTICES.md](THIRD_PARTY_NOTICES.md).

- [Zephyr 4.2.0 source and sample](https://github.com/zephyrproject-rtos/zephyr/tree/v4.2.0/samples/drivers/audio/dmic)
- [Zephyr SDK 0.17.2](https://github.com/zephyrproject-rtos/sdk-ng/releases/tag/v0.17.2)
- [Winbond W25N-GV official product/documentation](https://www.winbond.com/hq/product/code-storage-flash/qspi-nand/w25n-gv/index.html?__locale=en)
- [MAX17048 datasheet](https://www.analog.com/media/en/technical-documentation/data-sheets/MAX17048-MAX17049.pdf)
- [DRV2605L datasheet](https://www.ti.com/lit/ds/symlink/drv2605l.pdf)
- [BQ25185 datasheet](https://www.ti.com/lit/ds/symlink/bq25185.pdf)

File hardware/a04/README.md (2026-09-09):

# AURA A04 — fresh KiCad MCP project

Status: **incomplete engineering design, not a fabrication release**. This project starts from a new native KiCad project, schematic hierarchy and board; it does not import the routed A03 board as a template. All new CAD mutations are made through KiCad MCP. Existing exact-MPN library definitions may be consulted or reused after verification.

The [full A04 objective](../../docs/a04/requirements.md) includes the circular pendant, real manufacturing and printable-part checks, firmware, mobile/context workflow, website, film and physical launch qualification. These files are one workstream toward that objective.

## Native state

- `aura-a04.kicad_pro`, `aura-a04.kicad_sch` and `aura-a04.kicad_pcb` are the new project.
- Three primary subsheets separate power/charging, radio/storage and microphones/controls, with three nested sheets for battery/thermal sensing, NAND and interaction.
- The initial circular outline is Ø35.2 mm at native datum (100,100) mm, with four copper layers. Its native thickness is currently **1.6 mm**. The mechanical 0.8 mm target has not been applied.
- The schematic contains all **72 candidate PCB references** and is checked against **239 intended connected endpoints**. Three MCU net names still differ from the contract; the schematic is incomplete. The PCB has no imported components, placement, tracks or zones yet. Do not interpret an empty-board check as design verification.
- `AuraA04.kicad_sym` contains the MCP-authored BQ25186DLHR symbol, with eleven physical pads checked against TI SLUSF69A, plus four copper-contact symbols. `AuraA04.pretty` holds their newly authored contact footprints. See the [pin evidence](../../docs/a04/pin-definitions.json).
- `review/schematic/` contains an MCP export of a work-in-progress schematic, not an approved drawing.
- [The seven-page candidate PDF](review/a04-schematic-candidate.pdf) is the current complete-sheet export; `review/a04-candidate-2.net` is the current MCP XML netlist. Earlier small SVG exports are retained as development snapshots.

The separately authored [CUS-22TB candidate footprint](AuraA04.pretty/Nidec_CUS22TB_Candidate.kicad_mod) is **unassigned**. Its ten numbered lands and two locating holes were created through MCP and inspected with KiCad's native parser. [The review and M1 errata](../../docs/a04/cus22-candidate-review.md) document the proposed underside orientation, actuator offset, ground-tab uncertainty and an old mounting-notch collision. Native SW1 remains JS202011JCQN; candidate creation does not establish substitution, placement or fabrication readiness.

## Checks and unresolved tooling

KiCad declined `set_design_rules` twice with `cancelled: true`, `action: decline` and no reason. The second request only tightened clearance and courtyard checking. Neither request was executed; no alias, file patch or approval-setting change was used to bypass the decline. Routing is not authorized by a presumed rule set. The available MCP metadata exposes no board-thickness or dielectric-stackup setter.

During visual cleanup, `delete_schematic_net_label` was also declined. The first cleanup loop checked only the outer MCP error flag and missed the nested cancellation, then added outward-facing labels. The exported power sheet revealed eleven duplicate label pairs at U2. An inspected single-operation response confirmed the decline. These same-net duplicates and the inward-facing labels must be resolved before drawing approval; the loop was stopped and no equivalent deletion path was used. Subsequent operations inspect nested `success`/`cancelled` results as well as the outer error flag.

`update_symbol_from_library` was declined once as well, leaving four contact-symbol library mismatch warnings unresolved. These tool responses give no reason; they are recorded as unresolved operations, not proof that a particular approval policy rejected the design. Existing CAD was not patched through another route.

Project symbol registration currently writes **absolute local library URIs**. Embedded schematic symbols remain in the native schematic, but the library table is not yet a portable release configuration. On another machine, the corresponding libraries must be registered through KiCad MCP with that checkout's actual paths. Do not assume this work-in-progress table resolves unchanged after cloning.

The current native ERC reports **one error and nine warnings**, independently reproduced by KiCad CLI 10.0.4. [The raw report](../../docs/a04/native-erc.json) retains all findings. [The read-only capture audit](../../docs/a04/audit-native-capture.py) compares the MCP-exported XML netlist to the design contract and deliberately returns nonzero for the three net mismatches and eleven duplicate label positions. [Its report](../../docs/a04/native-capture-verification.json) binds those findings to source hashes. Intentional unused pins have explicit no-connect markers; power flags identify actual external or switched supply paths, not invented drivers for signal errors.

There is no DRC, assembly-clearance, copper/paste/drill, populated-board fit or supplier CAM sign-off. There are no A04 fabrication Gerbers or a manufacturing ZIP. The earlier A03 release remains separate.

The [assembly-attribute audit](../../docs/a04/assembly-attributes-review.md) identifies seven export risks among the 72 assignments: purchased D2/C3/C4 lack footprint-level SMD classification, while J1–J4 copper contact features retain component BOM/position inclusion. The expected purchased PCB set is 68 references, with four additional copper features. MCP `set_footprint_type` supports future placed-board corrections; actual saved-instance and exported BOM/CPL checks remain required. The audit's integrity passes while its assembly-policy result deliberately remains false.

Visual inspection of the candidate PDF also found reference/value text close to some symbol boundaries and long LED labels entering the interaction sheet's title area. Drawing layout cleanup remains part of the schematic gate. The current geometrical checks do not imply a professional final drawing or an assembled fit.

Before manufacturing: complete exact-part selection and schematic review, establish valid rules and actual stackup, verify footprint pads/courtyards/tolerances, import and place the circuit, route and inspect all nets, check real populated geometry against the case, then obtain the required qualified battery/RF review and supplier/first-article evidence. A successful export alone is not fabrication readiness.

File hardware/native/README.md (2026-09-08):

# AURA A03 native prototype project

Open **`aura-a03.kicad_pro` in KiCad 10**. This directory is the paired editable PCB and schematic used for the manufacturing exports. The working routing record remains in `../output/aura-a03-native-routing.kicad_pcb`; the original native schematic reconstruction remains in `../output/aura-a03-electrical.kicad_sch`.

The paired project preserves the verified copper and pads, links every footprint to its actual schematic sheet/symbol UUID, and uses project-relative `AURA_PCB` snapshots. Schematic footprint fields match those snapshots. The 37 intentional NC pads receive their schematic singleton net names while remaining physically isolated; internal numeric net codes may change. `project-linkage.json` records the source and packaged board hashes, unchanged routed geometry and unchanged assignments of all 208 intended connected pins. The source paths follow [KiCad's native netlist identity convention](https://docs.kicad.org/doxygen/common_2netlist__reader_2kicad__netlist__reader_8cpp_source.html).

After editing this paired project, regenerate its exports directly. Rebuilding the tscircuit placement does **not** reproduce the completed native routing and must not overwrite it. Review proposed changes in KiCad's Update PCB from Schematic dialog before applying them; preserve the paired UUIDs and exact snapshot land patterns.

## Manufacturing status

These are connected **prototype fabrication and assembly-review files**. Read `review/manufacturing-checks.json` and `review/drc.json` before submitting them. Native ERC, schematic parity, board connectivity and bare-board DRC each have **zero findings**. The complete DRC report retains **78 `courtyards_overlap` errors** for assembly review. This is not an assembly-approved or qualified consumer-device release.

| Directory / file | Purpose |
| --- | --- |
| `fabrication/gerbers/` | Four copper layers, front/back mask and silkscreen, routed outline and Gerber job metadata |
| `fabrication/drills/` | Separate metric plated/nonplated Excellon files, drill maps and tool report |
| `fabrication/aura-a03.ipc` | IPC-D-356 electrical test netlist |
| `assembly/stencil/` | Separate front/back solder-paste Gerbers; stencil/process review required |
| `assembly/bom.csv` | 57 component candidates with MPNs; the four custom copper-contact features are excluded |
| `assembly/component-centres.csv` | Component body/reference positions and source rotations, corrected for the converter origin offsets |
| `assembly/native-footprint-origins.csv` | Raw KiCad origins for audit; includes custom contacts and must not be substituted blindly for component centres |
| `review/board-layers.pdf` / `review/schematic.pdf` | Readable board layers and six schematic sheets |
| `review/erc.json` / `review/drc.json` | Native, unsuppressed check output |
| `review/native-smd-pad-spacing-audit.json` | 25,158 different-net SMD pad pairs checked against 0.15 mm; zero violations |
| `review/native-via-aperture-audit.json` | 177 vias and 88,500 comparisons against actual SMD copper/paste; zero intersections |
| `review/manufacturing-checks.json` | Final export scope, via inventory and file hashes |

All fabrication Gerbers, Excellon drills and component-centre coordinates use the board centre as origin, with positive Y toward the necklace bail. Do not mirror the bottom drill file or apply an additional origin offset. Confirm component zero-angle conventions, underside contact soldering, stencil apertures, panel rails and dense-placement acceptability with the selected assembler.

## Board specification

- Outline: 24 × 42 mm, R10 corners, nominal 0.8 mm FR-4, four copper layers.
- Stack: **JLC04081H-3313** — 35 µm outer copper / 99.4 µm 3313 prepreg / 15.2 µm inner copper / 500 µm core / 15.2 µm inner copper / 99.4 µm 3313 prepreg / 35 µm outer copper. Material sum 0.7992 mm, nominal finished-board order 0.8 mm. No controlled-impedance claim is made.
- Finish: ENIG; green solder mask; white legend. Use a nonconductive enclosure finish over the antenna region.
- Authored minimum trace width 0.10 mm, copper spacing 0.12 mm, hole-to-copper 0.20 mm, hole-to-hole 0.25 mm and copper-to-outline 0.30 mm. Actual different-net SMD pad spacing is separately checked against 0.15 mm.
- Routing vias use **175 plated 0.20 mm drills and two plated 0.15 mm drills**; the microphones also require two 0.50 mm NPTH holes. Order capability for these actual mixed tools, not a blanket 0.20 mm minimum. The smaller tool can incur a supplier surcharge. Vias are tented; no epoxy fill or copper cap is claimed.
- Ground lands use solid connections. Account for thermal mass in stencil/reflow and exposed-pad soldering; do not assume default thermal reliefs.
- The top antenna exclusion applies to copper on all four layers. Chain, enclosure, battery and wearing-position RF tests remain outstanding.

The stack and limits were checked against [JLCPCB's published capabilities](https://jlcpcb.com/capabilities/pcb-capabilities), its [stackup calculator](https://jlcpcb.com/impedance), and [component-spacing guidance](https://jlcpcb.com/help/article/minimum-spacing-for-smd-components). The preserved stackup response is `../sources/jlc-4layer-08mm-stackups.json`. These sources do not constitute factory approval of this particular design. This small board needs supplier-approved panelization and assembly access.

## Prototype bring-up

Use the [firmware bring-up guide](../../firmware/README.md) with current-limited supplies and verified parts. Charging and haptics remain disabled in the distributed firmware pending measurements with the selected battery, NTC and actuator. Battery voltage tolerance, thermal cutoff, audio, RF, physical fit and power consumption remain unqualified. The PCB contacts and alignment jig are supplied; a complete charging-dock production design is not included.

## Reproduce the package

Use KiCad's Python, which includes `pcbnew`, and KiCad 10's CLI. From `hardware/`, after a verified native routing/library freeze:

```powershell
$boardHash = (Get-FileHash output/aura-a03-native-routing.kicad_pcb).Hash
& 'C:/Program Files/KiCad/10.0/bin/python.exe' scripts/pair-native-project.py --expected-sha256 $boardHash
& 'C:/Program Files/KiCad/10.0/bin/python.exe' scripts/audit-native-pad-spacing.py --board native/aura-a03.kicad_pcb
& 'C:/Program Files/KiCad/10.0/bin/python.exe' scripts/audit-native-via-apertures.py --board native/aura-a03.kicad_pcb
& 'C:/Program Files/KiCad/10.0/bin/python.exe' scripts/export-native-package.py
node scripts/package-status.mjs
python scripts/package-native-archive.py
```

The pairing step is for rebuilding the packaged project from the frozen working sources; it overwrites generated files in this directory. For subsequent edits in the paired project, rerun the two clearance audits and the exporter without pairing again. The exporter rejects stale audit hashes and fails on unconnected nets, schematic mismatch, ERC findings or non-assembly DRC errors. The final commands verify file hashes and rebuild the portable prototype archive. These commands do not purchase boards, submit files to a factory, or deploy software.

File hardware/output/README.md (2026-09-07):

# A03 engineering outputs — unreleased

**This directory does not contain a fabrication-ready PCB release.** Do not order the placement export or standalone session.

| File | What it establishes |
|---|---|
| `engineering-package-manifest.json` | Byte hashes for 37 source/output files, explicit unreleased status and current routing/ERC evidence |
| `design-manifest.json`, `logical-netlist.json`, `logical-checks.json` | 61 authored references, 43 nets and checked logical invariants |
| `aura-placement.circuit.json` | Authored tscircuit placement/circuit data |
| `aura-placement.kicad_pcb` | Four-layer native placement only: zero tracks and vias |
| `export-checks.json` | 208 authored connected logical pins retain the intended numeric-pad net assignments in that placement |
| `kicad-a03-final-placement-drc.json` | 65 non-copper findings and 167 unconnected items; no copper/pad/hole/edge violation in the unrouted placement |
| `aura.kicad_sch`, `kicad-a03-schematic-erc.json` | Native schematic interchange draft; 968 ERC findings, including 220 unconnected-pin errors. It is not a validated connected native schematic |
| `aura-placement.schematic.svg` | tscircuit schematic drawing; drawing appearance is not ERC evidence |
| `aura-a03.dsn`, `aura-a03-routing-inputs.json` | Exact native routing input and source hashes |
| `aura-a03-route-attempt.ses` | First actual standalone A03 route: 542 wire paths / 109 vias, incomplete |
| `aura-a03-route-freerouting-drc.json` | Fresh first-session reload: nine disconnected net groups and one dangling-via warning |
| `aura-a03-route-refine.ses`, `aura-a03-refine-freerouting-drc.json` | Latest refined session: 545 wire paths / 109 vias. Router log: 10 gaps / 4 violations; reload DRC: eight disconnected net groups / one dangling-via warning |
| `aura-a03-routing-status.json` | Latest inspected standalone session, checksums and exact status |
| `aura-a03-route-study.svg`, `.png` | Actual standalone route geometry, explicitly marked unfinished |
| `assembly-plan.svg`, `.png` | Mechanical placement reference; does not display routed copper |
| `assembly-bom.csv`, `cpl-top.csv`, `external-bom.csv` | Candidate assembly/procurement review material; four PCB pad-feature references are excluded from the 57 SMT references |
| `fabrication-review-notes.md` | Manufacturing intent and outstanding release contents, expressly on HOLD |
| `attempts/` | Historical and superseded attempts, not current manufacturing evidence |

See `../../docs/hardware.md` for charging, cell, RF, acoustic, mechanical and software qualification limits. The earlier connector SES import was cancelled without an explanation. No alternative import was performed to bypass it. A standalone routing session is not an independently checked routed KiCad board.

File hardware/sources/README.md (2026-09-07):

# Component documentation provenance

Manufacturer PDFs downloaded for local review are excluded from this repository.
Use these original sources to reproduce the review. Retrieval took place on
7–8 September 2026; obtain the current revision before procurement.

| Source | Review scope / limitation |
|---|---|
| [tscircuit documentation](https://docs.tscircuit.com/) | Installation, CLI, board/chip/footprint/keepout APIs |
| [Raytac MDBT50Q-1MV2](https://www.raytac.com/product/ins.php?index_id=24) | Exact module selection; manufacturer PDF hosted by [Espruino](https://www.espruino.com/datasheets/MDBT50Q-1M.pdf) supplements a blocked direct download |
| [BQ25185 Rev.B, August 2026](https://www.ti.com/lit/ds/symlink/bq25185.pdf) | Power-path pins, 4.2 V setting, 53.38 mA nominal charge, TS thresholds and capacitor requirements |
| [TLV755P](https://www.ti.com/lit/ds/symlink/tlv755p.pdf) | 3V regulator family; final package/pin inspection required |
| [DRV2605L](https://www.ti.com/lit/ds/symlink/drv2605l.pdf) | Haptic driver pins and LRA interface |
| [SN74LVC2G125](https://www.ti.com/lit/ds/symlink/sn74lvc2g125.pdf) | Buffer pinout and partial-power-down Ioff behavior |
| [MAX17048 / MAX17049](https://www.analog.com/media/en/technical-documentation/data-sheets/max17048-max17049.pdf) | Gauge pin functions and application topology |
| [W25N01GV documentation index](https://www.winbond.com/hq/support/documentation/?__locale=en&pno=W25N01GV), [Winbond Rev.R PDF mirror](https://www.marthel.pl/katalog/W25N01GV%20Rev%20R%20070323.pdf) | Manufacturer content, 3 July 2023: pins and ZE 8 × 6 mm WSON, exposed pad 3.4 × 4.3 mm; EP may float or connect to ground; no exposed vias underneath |
| [Winbond 2025 selection guide](https://www.winbond.com/export/sites/winbond/product-selection-guide/file/2025-Product-Selection-Guide-Winbond-Code-Storage-Flash-Memory.pdf) | Confirms W25N01GVZEIG uses 8 × 6 mm WSON |
| [SPH0641LU4H-1 official Rev.B link](https://www.knowles.com/docs/default-source/model-downloads/sph0641lu4h-1-revb.pdf), [Knowles Rev.A PDF mirror](https://xonstorage.z8.web.core.windows.net/pdf/knowles_sph0641lu4h1_apr22_xonlink.pdf) | Official link unavailable. Manufacturer Rev.A content confirms pinout, timing and Class II capacitor warning; original KiCad land retained. Current revision/supply status remains a review item |
| [TLV6700 Rev.B](https://www.ti.com/lit/ds/symlink/tlv6700.pdf) | DDC pin map, comparator truth table, input-current/threshold bounds and 450 µs startup maximum |
| [DMG2302UK](https://www.diodes.com/assets/Datasheets/DMG2302UK.pdf) | SOT-23 gate/source/drain numbering and on-resistance at 2.5 V |
| [Semitec AT thermistor](https://www.semitec-global.com/uploads/2022/01/P12-13-AT-Thermistor.pdf) | 103AT-2 nominal resistance table. Assembled ±3% acceptance at 0°C/40°C is a design requirement, not an asserted vendor guarantee |
| [TI TS bias FAQ](https://e2e.ti.com/support/power-management-group/power-management/f/power-management-forum/1603144/faq-bq2518x-how-does-the-ts-pin-work-for-battery-temperature-moni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), [TI threshold discussion](https://e2e.ti.com/support/power-management-group/power-management/f/power-management-forum/1472003/bq25185-ntc-temperature-threshold) | Adapter-mode TS bias and why simple series/parallel compensation does not independently set both limits |
| [FPBattery DNK302025-150 preliminary sheet](https://www.fpbattery.com/wp-content/uploads/2024/06/fpbattery-302025-3.7V-150mAh-Lithium-Polymer-Battery-Specification.pdf) | Protected pack candidate, actual 27 ± 1 mm length including PCM, 75 mA charge maximum and 0–45°C range; controlled tolerances/NTC/voltage acceptance unresolved |
| [Precision Microdrives C08-00A](https://www.precisionmicrodrives.com/datasheets/C08-00A%20-%20datasheet%20-%20002.pdf) | 8 mm LRA candidate; 1.2 Vrms rated, 1.25 Vrms maximum, 240 Hz; prototype supply and drive calibration require qualification |
| [C&K KMR2](https://www.ckswitches.com/media/1479/kmr2.pdf), [KMR211NGULCLFS product](https://www.ckswitches.com/products/switches/product-details/Tactile/KMR2/KMR211NGULCLFS%C2%A0/) | No-ground-tab, ultra-low-current variant; 1.2 N and 0.20 ± 0.10 mm electrical travel |
| [Murata BBSC 0402 100 nF Rev.3.00](https://www.murata.com/products/productdata/8814108606494/SICAP-BBSC424610.pdf?1632454218000=), [manufacturer-page mirror](https://www.alldatasheet.com/html-pdf/1397988/MURATA1/939113424610-T3N/2141/6/939113424610-T3N.html) | Exact 939113424610-T3N order code, 3.8 V rating, 1.2 × 0.7 × 0.4 mm die and 0.7 mm pad pitch; direct PDF intermittently unavailable |
| [Murata reflow assembly Rev.1.42](https://www.murata.com/-/media/webrenewal/products/capacitor/siliconcapacitors/assemblynotepdf/assembly-reflow.ashx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) | Mask-defined/NSMD guidance and Table 1 minimum land dimensions. Authored land requires actual mask-registration and stencil qualification |
| [KEMET C0805C106K8PACTU](https://search.kemet.com/download/specsheet/C0805C106K8PACTU) | Exact 10 µF / 10 V / 0805 X5R SYS reservoir candidate; effective biased capacitance and aging remain validation requirements |
| [Freerouting 2.4.1](https://github.com/freerouting/freerouting/releases/tag/v2.4.1), [CLI source](https://github.com/freerouting/freerouting/blob/v2.4.1/docs/command_line_arguments.md) | Local headless routing, DSN/SES interchange, bounded passes and standalone DRC |

Ordinary resistor selection uses Yageo RC0402FR 1% parts. Manufacturer sheets follow `https://yageogroup.com/component-documentation/download/specsheet/<MPN>`; examples checked include RC0402FR-0710KL, RC0402FR-07100KL, RC0402FR-074K7L, RC0402FR-071KL and RC0402FR-0733RL. Values added for the reviewed thermal circuit follow the same ordering system and require purchasing confirmation.

Ordinary capacitor candidates are KEMET C0402C104K4RACTU, C0402C103K5RACTU, C0603C105K4RACTU, C0603C225K8RACTU and C0603C475K8PACTU. Manufacturer spec sheets are under `https://yageogroup.com/download/specsheet/<MPN>`. Do not substitute a smaller package or dielectric without electrical, bias and acoustic review.

The public repository includes authored design sources and review reports, plus
KiCad footprints with their upstream library license/attribution in
[`../library/NOTICE.md`](../library/NOTICE.md). Inclusion is not a purchasing,
manufacturing or certification approval.

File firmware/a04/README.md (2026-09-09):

# AURA A04: microphone ingress, Opus capture and recoverable storage

This directory contains a monitored PDM driver, bounded reader FIFO, serialized recorder, actual libopus encoder, revision-3 archive writer, recoverable NAND journal and W25N01GV command core/Zephyr SPI adapter. A serialized storage owner combines authenticated release commands, durable identity reservations and control snapshots for host-tested capture reclamation. A matching Python reader, durable receiver and release outbox complete the tested source-to-release path. Host failure/round-trip tests and a Cortex-M4 integration build exercise these layers. It is **not the complete A04 wearable firmware**. It does not alter the published A03 firmware or establish physical microphones, NAND storage, BLE, signed updates or measured battery life.

The separate [first spoken-note bench](bench/README.md) now connects these layers to the nRF52840 DK's actual PDM/SPI/GPIO drivers and a bounded local UART host. It has explicit microphone permission, recording, cold-open recovery and verified archive export. The [wiring review](bench/WIRING.md) names microphone fixtures matching A04 and a W25N01GV fixture; the [bench ELF report](bench/verification/arm-resources.json) checks the separate target and pins. Its 31 UART-client tests and five C orchestration groups cover the new integration. It has been cross-built, **not flashed or physically tested**. The original ARM probe below remains a different synthetic integration target.

## Implemented behavior

The separate [authenticated radio DK application](radio/README.md) now connects
the same physical-driver/storage owner to the actual transfer command engine.
It includes a bounded pairing window, L4 enforcement, per-connection ASC1 owner
proof, immutable GATT responses and immediate revocation. This is development
source with host-tested boundaries, not an executed physical radio link or
consumer enrollment. The wired bench and the synthetic ARM probe remain
separate targets; their existing resource reports do not measure this radio image.

- The [storage owner](STORAGE.md) durably reserves capture IDs, verifies exact finalized source and [RLS1 authentication](RELEASE-AUTH.md), then commits original release extents through [control snapshots](CONTROL-LEDGER.md) before invoking a privileged erase. It preserves unacknowledged recordings and supports catalog reuse in the host model. The W25N adapter separately supports restricted control-block rotation; a production populated-audio erase callback and secure owner enrollment remain unimplemented. An interrupted authority write can require recovery and block further operations. Authentication success alone never permits deletion.
- The [microphone adapter](AUDIO.md) separates its higher-priority PDM reader from the encoder/storage owner with a bounded FIFO. The local Zephyr/nrfx driver exposes sticky faults and DMA ownership; overflow, missing blocks, privacy cancellation or uncertain STOP completion cannot masquerade as a clean recording. Startup, publication and cutoff ordering have deterministic host tests. Real interrupt latency and microphone continuity remain unmeasured.
- The [recorder](RECORDER.md) binds each block to an epoch, sequence and exact source offset. A clean stop checks the producer's final watermark before flushing and sealing; interrupted captures retain their verified complete-packet prefix. It reports separate source and storage-close errors and prevents retrying PCM already consumed on a failed call.
- Arbitrary mono PCM16 chunks are accumulated into 16 kHz frames. The selected profile is 32 kbps constrained VBR, complexity 3, wideband, `OPUS_APPLICATION_RESTRICTED_LOWDELAY`; 20 ms is the primary profile and 10 ms is also tested. DTX and in-band FEC are disabled. This chooses the CELT low-delay mode, so it must be compared against the speech-optimized Opus modes on actual voices before the product profile is locked.
- The application queries `opus_encoder_get_size(1)` and initializes caller-provided, correctly aligned memory. It never hard-codes Omi's older, modified encoder-state sizes. The current fixed-point host build reports **15,268 bytes**. A 32 KiB upper-bound reservation is checked before initialization.
- A failed sink commit retains the exact encoded packet for retry. New input waits while that packet is pending. `*consumed` tells the producer exactly which PCM samples were copied before a failure; resubmit only the unconsumed remainder. The sink must make retries idempotent by stream identity, sequence and payload hash.
- Finish flushes the encoder lookahead and partial final frame. The seal records source length, encoded length, pre-skip and end-trim. Repeated finish after a commit failure does not re-encode that packet. No further source audio is accepted after closing begins.
- The archive layer binds immutable device/capture metadata, packet CRCs, SHA256 chain, source bookmarks and the exact finalized/interrupted terminal seal. It retains exact bytes and file offsets across uncertain sink writes. A real host file sink flushes each committed record; a Python SQLite receiver batches import into one transaction and returns its receipt only after commit. [ARCHIVE.md](ARCHIVE.md) defines the complete byte contract and integration API.
- The [packed NAND journal](NAND-JOURNAL.md) uses separate staged initializers, full page readback and replay-derived committed receipts, metadata-only mount, strict gap/checkpoint recovery, and lazy full verification before export. Version-2 allocation headers/checkpoints bind storage incarnation and generation to each part. Its host model covers power-cut program/erase cases. A [Zephyr SPI adapter](W25N-ADAPTER.md) accepts the eventual reviewed board configuration without choosing GPIOs. Media-full stops recording; connecting the authorized reclamation path to physical audio storage remains a product gap.
- Allocation and scratch storage are bounded in the embedded application. The upstream fixed-point implementation uses stack `alloca`; the probe provides a separate 48 KiB codec thread stack, initializes stack memory and enables the MPU guard and stack-space query. Runtime stack headroom is still unmeasured.

The capture object and sink have **one serialized owner**. They are not ISR-safe or thread-safe. The audio adapter provides a separate bounded queue and an explicit overflow policy; the embedding product still needs its real task scheduler. Pending codec audio survives a retry in RAM. The codec-only test sink stores in memory; the archive test sink performs host file writes and `_commit`/`fsync`; the synthetic embedded probe uses a small volatile RAM NAND and discards only its verified export. It retains the physical SPI adapter without initializing a flash device. Host file tests do not establish NAND persistence on a physical device. Persist the returned seal before treating a recording as closed.

## Reproduce on the existing Windows toolchain

From the repository root:

```powershell
# Once, if the repository's pinned Zephyr tools are not installed:
./firmware/scripts/setup.ps1

# Installs/verifies the local Opus dependency, then builds and tests:
./firmware/a04/scripts/build.ps1 -Mode all

# Independent subsets:
./firmware/a04/scripts/build.ps1 -Mode host
./firmware/a04/scripts/build.ps1 -Mode arm

# Once when migrating an older generated codec-only build:
./firmware/a04/scripts/build.ps1 -Mode arm -Pristine
```

The setup uses Python 3.12, Zephyr v4.2.0, SDK 0.17.2, CMake 3.31.6, Ninja 1.11.1.4 and Zig 0.14.1 from the existing repository setup. Host round trips additionally require `ffmpeg` on PATH. Build products stay under `.tools/a04-opus/`; the scripts do not flash, copy artifacts into `firmware/release/`, or change A03 board files. First builds compile the full unmodified source and take several minutes.

The ARM target is `nrf52840dk/nrf52840`. It checks the MCU ABI and linker budget while the A04 hardware contract is being finalized; **do not flash this DK probe onto AURA**. On a matching Nordic DK, a future manual run will print codec version, state size, worst encode time, late frames and stack free space to the console. No such run has been performed for the checked-in evidence.

## Verification and inspectable audio

The integrated verification covers **25 SPI command/integration groups, 19 journal groups, 13 storage-owner groups (745 cases), 10 recorder groups, 10 audio-adapter groups, 20 monitored-driver groups and 33 Python archive/receiver tests**. Six real-Opus journal recovery cases and five recorder cases pass export, SQLite restart/replay and independent FFmpeg decode. The additional [storage round trip](verification/storage-roundtrip.json) sends real C-encoded audio through a committed Python receiver and persisted release outbox back to C, proving exact authorization, cold recovery, reclaimed-block reuse and byte-identical retained audio. The complete [companion suite](../../companion/verification/release.json) passes 131 tests, including 36 release tests. The [adapter report](verification/audio-host.json) and [driver report](drivers/tests/verification.json) bind their tested sources. These are host tests with simulated boundaries; none establishes physical flash or microphone operation.

The host test covers state size/alignment, unsupported profiles, missing sink, empty capture, arbitrary chunk boundaries, repeated sink failure, byte-identical retry, failure while flushing a final partial frame, exact duration and rejection of input after closing. The speech fixture is encoded using the real fixed-point encoder, decoded by the linked libopus decoder, then independently decoded by FFmpeg through standards-compatible Ogg Opus files.

| Profile | Packets | Payload | Payload bitrate on this fixture | Exact decoded samples | Source-to-host waveform SNR |
|---|---:|---:|---:|---:|---:|
| 10 ms | 756 | 27,365 bytes | 28.98 kbps | 120,847 | 11.981 dB |
| 20 ms | 378 | 26,998 bytes | 28.60 kbps | 120,847 | 11.918 dB |

Both use 40 samples of pre-skip and 73 samples of final trim at 16 kHz for this 7.553-second synthetic speech input. Constrained VBR is not a constant packet-size guarantee. Waveform SNR is only a regression check for this exact fixture; it does not establish perceptual quality or transcription accuracy. FFmpeg outputs have the same exact duration. Full metrics, hashes and exclusions are in [host-roundtrip.json](verification/host-roundtrip.json).

The current synthetic nRF52840 probe links the new transfer owner and all nine
of its APIs: **227,488 bytes of flash (21.70%)** and **224,768 bytes of RAM
(85.74%)**, leaving 37,376 bytes unallocated in this specific configuration.
The [resource report](verification/arm-resources.json) binds the actual ARM ELF
and [unchanged build inputs](verification/arm-inputs.json). The owner occupies
**4,440 bytes** on ARM, including its cursor and response buffer, and remains
uninitialized in this probe. This establishes compilation and allocation, not
transfer execution or production Bluetooth headroom. The probe also contains
synthetic RAM NAND and a maximum control snapshot reservation.

The separate [wired bench report](bench/verification/arm-resources.json) covers
actual peripheral-driver code and cursor-based UART EXPORT; it does not include
the new command owner. Neither report measures physical runtime timing or stack
high-water, and neither is a complete wearable firmware budget. Production
Bluetooth, enrollment, audio-release capability, signed updates and real
workload measurements remain outstanding.

The [bounded export cursor](JOURNAL-CURSOR.md) adds exact-record resume, an owned
page buffer and at most one NAND read per step. It independently verifies source
before streaming and again before completion. Its host tests check source
mutation, interrupted tails, chunk sizes, exact resume boundaries and volatile
cancellation. The wired bench uses it for EXPORT; its UART protocol still has
no resumable command or concurrent command preemption.

The portable [transfer command owner](include/aura_transfer.h) adds HELLO, LIST,
SELECT, READ, FINISH and CANCEL above that cursor. Its
[exact wire contract](../../docs/a04/transfer-wire-v1.md) separates immutable
response delivery from durable phone storage, binds exports to owned allocation
identities and rejects stale connection/source/delivery callbacks. Its
[12 host test groups](verification/transfer-host.json) exercise real journal and
cursor code with modeled NAND, unchanged Opus packets and generation-derived
identities. Tests generate [exact replies and fragments](verification/transfer-wire-golden.tsv)
for the matching Android codec. Reproduce with
`python firmware/a04/scripts/verify_transfer.py` after configuring the host build;
the normal `scripts/build.ps1 -Mode host` loop includes it. This new owner is
linked as a resource reservation in the synthetic ARM probe and is now integrated
into the separate radio DK application's owner loop. The wired bench still uses
its UART cursor. Durable phone download and the Android GATT client exist with
virtual-peripheral tests; matching ASC1 client integration, consumer enrollment
and a physical hardware-to-phone recovery trial remain outstanding.

Listen or inspect: [input WAV](fixtures/source-speech-16k.wav), [20 ms Opus](fixtures/speech-20ms.opus), [20 ms independent decode](fixtures/speech-20ms-ffmpeg.wav), [10 ms Opus](fixtures/speech-10ms.opus). Host-generated `.aoc` files retain individual packets for debugging. Ogg files use 48 kHz granule units and encode both pre-skip and exact final length.

The `.aoc` container is **AOC1, a codec-debug format only**. Integers are little-endian: header `<4sHHIQQIHH>` contains magic, version, frame milliseconds, rate, source samples, encoded samples, packet count, pre-skip and end-trim; each packet uses `<IQHH>` for sequence, encoded sample offset, sample count and payload bytes, followed by that payload. It has no journal CRC, identity or durable receipt mechanism. It is rejected by the real archive reader.

The real `.aura` fixtures use [experimental wire revision 3](ARCHIVE.md): [10 ms finalized](fixtures/capture-10ms.aura), [20 ms finalized](fixtures/capture-20ms.aura), [20 ms interrupted](fixtures/capture-20ms-interrupted.aura) and [20 ms unsealed prefix](fixtures/capture-20ms-open.aura). Their adjacent `.receipt` files are independently serialized by C. Python verifies the exact C terminal receipts, imports/replays after restart, and reconstructs Opus for independent FFmpeg decode. Finalized fixtures preserve exactly 120847 source samples; interrupted fixtures retain 120600 samples with original duration unknown. A tail bookmark at sample 120640 remains recorded but unavailable in the interrupted audio. [archive-roundtrip.json](verification/archive-roundtrip.json) records exact file/terminal/prefix hashes and results. This is an explicit version change; there is no revision-2 conversion or BLE wire compatibility claim.

## Evidence required before wearable integration

The underlying primitives add **13 authentication groups and four independent Python comparisons**, plus **12 control-ledger groups covering 712 fault/rotation cases**. [Authentication evidence](verification/release-auth.json) covers standard HMAC vectors, every message-bit mutation, canonical fields, exact receipts and replay checks. [Control evidence](verification/control-ledger.json) covers power cuts, stale contexts, bounded output, generation conflicts and preserved unrelated source, with independent wire/hash decoding. The storage-owner tests combine these layers, but secure enrollment and physical audio-release integration remain outstanding.

1. Final A04 pin map and Zephyr board definition, actual PDM mono/channel selection, clocking, gain, DC/clipping behavior and microphone power gating.
2. Device measurements of encode latency and stack high-water with representative voice, long recordings, flash writes and concurrent BLE; tune complexity/profile only from those results.
3. Physically validate the implemented journal/SPI adapter, power-loss reconstruction and media-full behavior; integrate the separate authorized audio-erase driver capability, trusted enrollment and recovery of ambiguous control/unassociated blocks. The current 128-live-capture bound and short-block tail waste are quantified in NAND-JOURNAL.md. Test storage stalls against the PCM queue budget and measure control-block wear.
4. Actual BLE fragmentation, flow control, disconnect/reconnect and mobile-background recovery against the receiving implementation; the codec wrapper does not supply transport.
5. Signed boot/OTA, authenticated ownership, privacy controls, indication/haptics, bookmarks and orderly battery/charger shutdown integrated with the hardware contract.
6. End-to-end transcription, memory/context provenance, search/tasks, live and offline flows, controlled continuous capture and phone/earbud interaction. These remain part of AURA's full feature objective; this encoder experiment does not replace them.

## Sources and license

The [official Opus downloads page](https://opus-codec.org/downloads/) supplies the pinned 1.6.1 checksum; the [encoder API reference](https://opus-codec.org/docs/opus_api-1.6/group__opus__encoder.html) documents supported frame lengths, state sizing, lookahead and low-delay behavior. The actual selected controls were also checked against the 1.6.1 headers. [Third-party notices](THIRD_PARTY_NOTICES.md) and [the full upstream license](licenses/Opus-COPYING.txt) accompany this integration.

The Omi comparison used [`BasedHardware/omi` at f42089f53c8010dd971b3702ece05a231c9c0c66](https://github.com/BasedHardware/omi/tree/f42089f53c8010dd971b3702ece05a231c9c0c66). Its 10 ms, 32 kbps, complexity-3 fixed-point approach informed the profile experiment. AURA uses an unmodified current upstream dependency and queried state sizes; no Omi codec source was copied.

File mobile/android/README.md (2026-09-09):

# AURA for Android

A native, local library for experimental A04 recordings: import an original archive, listen to its verified audio, add your own context, and choose what to copy or share with an AI chat. Android 10 / API 29 or newer is required.

[Download the development APK](https://github.com/Avinash1286/pendent/releases/download/a04-android-recovery-dev/aura-a04-android-debug.apk) · [Release files and checksums](https://github.com/Avinash1286/pendent/releases/tag/a04-android-recovery-dev) · [Verification](VERIFICATION.md)

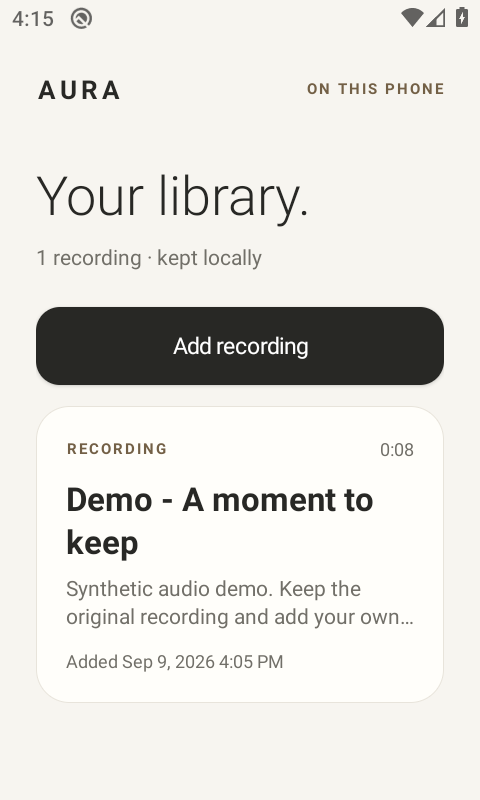
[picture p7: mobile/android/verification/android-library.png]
Actual Android local library with a clearly labeled synthetic demo recording
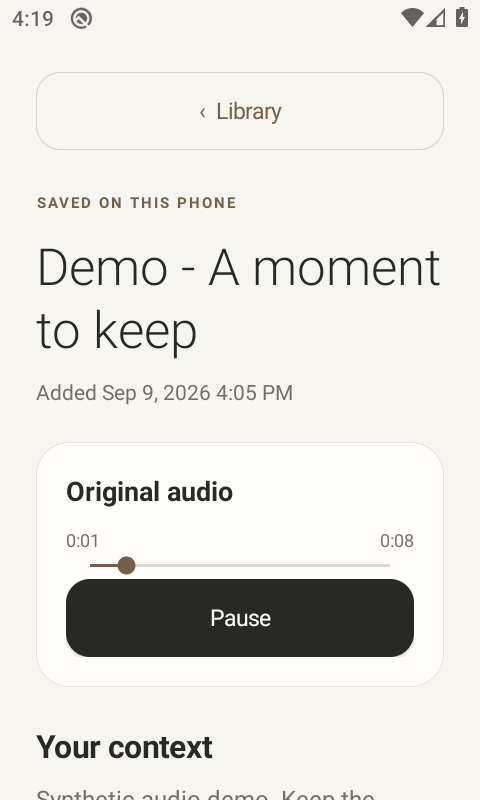
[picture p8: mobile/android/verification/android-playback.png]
Actual playback of the synthetic demo recording on Android
 

The consumer Activity remains the phone-side file-import foundation for A04. It does **not** yet connect to a pendant over BLE, enroll a device, download recordings over the air, transcribe speech, sync with the web portal, or record in the background. The implemented transport components and remaining integration are documented in [mobile-transport.md](../../docs/a04/mobile-transport.md). This app is not evidence that a fabricated wearable is ready to use.

The current APK also contains the [durable download store](DOWNLOADS.md): validated transfer records and resume metadata commit together in SQLite, and a completed source can enter this same playable library. Its storage and decoding paths have passed Android runtime checks. The new [foreground recovery owner and Android GATT client](RECOVERY.md) connect that storage foundation to a serialized transport lifecycle. The separate [Zephyr radio DK service](../../firmware/a04/radio/README.md) is now implemented and requires [ASC1 owner proof](../../docs/a04/session-auth-v1.md). Android still needs that proof exchange, trusted owner-context custody, consumer enrollment and Activity integration before accessing the DK service. See the [verification record](VERIFICATION.md) for the executed scripted-link and virtual-radio scope; those earlier tests do not execute the Zephyr service, its proof handshake or physical pairing. The screenshots above show the earlier local-import UI, which this change does not replace.

## Use the local library

1. Tap **Add recording**. In Android's document picker, select one complete A04 archive and, optionally, its matching physical receipt in the same selection. Typical filenames are `.aura` and `.physical.ack3`; the app identifies **AUR3** and **ACK3** bytes, not a filename or MIME type.
2. Wait for validation. The app first copies the selected sources into private storage. For nonempty Opus recordings, it validates the complete archive, builds a derived Ogg, decodes through the platform decoder's output end-of-stream, and verifies the exact retained sample count before publishing playable audio.
3. Open the recording to play, pause, seek, and edit its title or **Your context**. Context is written by you; the app does not invent a transcript. A valid empty capture is retained and explicitly has no playable audio.
4. Use **Copy context for AI** to paste into ChatGPT, Claude, Gemini, Grok, or another text interface. **Share context…** opens Android's chooser. Both actions send only the context you chose, with the original archive's SHA-256, retained duration, and an interrupted-recording qualification when applicable. They do not automatically contact an AI service or attach audio.
5. Use **Export original recording…** to write the unchanged archive to a destination you choose. This exports the archive only: editable context and the optional physical receipt are not included. Keep the original receipt separately and copy/share context you want to preserve outside the app.

Playback is tied to the visible activity. Leaving the app stops playback. The implementation releases audio focus when playback ends, pauses on focus loss, and pauses when headphones disconnect so a pending or playing recording does not deliberately continue through the phone speaker. The API 29 UI check exercised playback to completion; physical headset routing and other-app audio-focus behavior still need the broader runtime checks described below.

## Understand recording and receipt status

The archive's terminal seal and a physical device receipt answer different questions:

| Imported evidence | Meaning shown or retained by the app |
| --- | --- |
| Complete finalized archive, no physical receipt | The file declares an exact completed duration; device-side termination provenance remains unknown. |
| Complete interrupted archive | Only the retained portion is known. The original recording's full duration is unknown. |
| Matching finalized or interrupted physical ACK3 | The supplied receipt must exactly match the independently verified terminal archive receipt. |
| Physical **OPEN** ACK3 plus a complete interrupted export | The physical receipt covers the unsealed prefix before the export's derived interrupted seal. It does not establish that the device physically wrote that seal. |

A raw unsealed prefix is not a complete importable archive. The Android parser rejects it, along with truncated records, trailing bytes, malformed metadata, and mismatched receipts; it does not silently repair the source.

If you later obtain a receipt for an already imported archive, select **the same archive and that receipt together**. An exact retry is idempotent. Unknown physical provenance can acquire a strictly matching receipt; a conflicting receipt is refused. Different terminal digests are distinct capture revisions. CRCs and SHA-256 establish byte consistency, not authenticated device identity. Importing or exporting a file does not issue a device durable-ACK or authorize deletion from a pendant.

The byte contract is defined in [ARCHIVE.md](../../firmware/a04/ARCHIVE.md), with parser details in the [Kotlin core guide](core/README.md).

## Storage, recovery, and limits

The app stores its library under Android's private `noBackupFilesDir/captures`:

```text
captures/
  inventory.sqlite               # Editable titles/context and source inventory
  store.lock                     # Serialized publisher/recovery ownership
  .pending/<unique-import>/      # Copied sources awaiting successful publication
  complete/<device>_<capture>_<terminal-digest>/
    source.aura                  # Unchanged original
    physical.ack                 # Optional strictly matched receipt
    bundle.json                  # Source identity and completed decode metadata
    source.opus                  # Derived Ogg Opus, for nonempty captures
    playback.wav                 # Validated PCM playback, for nonempty captures
```

One worker owns app operations, with a process/file lock around store mutations. The publication sequence syncs completed files, renames the private bundle, syncs the affected directories, and then commits its SQLite inventory row with FULL-or-stronger synchronization. A late physical receipt is a new validated sidecar; it does not rewrite the original archive or base bundle metadata. Title and context edits change SQLite only.

On a fresh store opening, recovery scans published complete bundles, revalidates original hashes/receipts and retained playback metadata/files, and rebuilds missing inventory rows. Existing title/context edits are preserved when their database is readable. A changed source, missing previously known receipt, or conflicting bundle is retained and excluded from the usable inventory. Rebuilding an absent database can recover capture inventory from complete bundles, but cannot reconstruct lost manual notes.

An import that fails parsing, decoding, limits, or publication leaves its private pending files in place; bytes already copied from an oversized or interrupted input are retained too. Selected external files are never rewritten. Exact duplicate retries also leave the extra pending copy. There is currently no automatic pending cleanup or in-app pending recovery/export interface, so repeated retries and long decoded recordings consume storage. Recovery ordering is implemented and testable; it is not a claim that sudden power loss has been physically tested.

| Bound | Current implementation |
| --- | --- |
| Selected inputs | One `content://` archive, optionally one receipt; at most two selections |
| Archive copy/file size | 128 MiB; combined input allowance is 128 MiB plus 94 receipt bytes |
| Physical receipt | Exactly 94 bytes |
| Archive records | At most 1,000,000 audio/bookmark records |
| App playback format | A04 mono Opus at a 16 kHz source rate; PCM archives are retained as failed imports with an unsupported-format message |
| Derived Ogg | At most 160 MiB, further bounded by archive payload and record limits |
| Derived WAV | At most 2 GiB including its 44-byte header; preflight allows for the platform's possible 48 kHz PCM output |
| Platform decode | PCM16 mono at 16 or 48 kHz, complete output EOS, exact retained duration, one remaining terminal trim when required |
| Decode time | Ten-second no-progress bound and a duration-based total budget capped at ten minutes |
| Editable text | Title up to 120 characters; context up to 20,000 characters |

The library is excluded from Android cloud backup and device transfer through `noBackupFilesDir`, `allowBackup=false`, and extraction rules. **Uninstalling the app or clearing its storage removes private recordings, pending imports, and manual context.** Keep independent copies using the explicit export/copy/share actions and retain your original external receipts. The app's private storage is not an external backup.

## Build on Windows

Run these commands from the repository root. The provided scripts use a workspace-local JDK, Gradle, Android SDK, and caches under `.tools/android`; they do not require Android Studio or an NDK.

Prerequisites are PowerShell, `curl.exe`, [`uv`](https://docs.astral.sh/uv/getting-started/installation/), and a working `ffmpeg` on `PATH`. The default verification command uses the locked companion Python environment, whose Python requirement is 3.12 or 3.13. Internet access is needed for the initial tool and dependency downloads.

```powershell
.\mobile\android\setup.ps1
.\mobile\android\build.ps1
```

`setup.ps1` verifies the pinned JDK, Gradle, and command-line-tools archives, accepts the SDK licenses as part of installation, and installs platform 37.0, build tools 36.0.0, and platform tools. It does not select a phone, flash firmware, or change Windows virtualization settings. Version and download background is in [TOOLCHAIN.md](TOOLCHAIN.md) and [toolchain-lock.json](toolchain-lock.json); that review document describes its earlier inspection, not a later runtime result.

`build.ps1` first runs the cross-language core verification, then builds the debug app, builds the test APK, and runs Android lint. The outputs are:

```text
mobile/android/app/build/outputs/apk/debug/app-debug.apk
mobile/android/app/build/outputs/apk/androidTest/debug/app-debug-androidTest.apk
mobile/android/app/build/reports/lint-results-debug.html
```

For a focused rebuild after unchanged core checks have already passed:

```powershell
.\mobile\android\build.ps1 -SkipCore
```

`-SkipCore` skips verification; it is not evidence that those checks passed. The debug APK uses local development signing and is not a Play Store/release-signed artifact. SDKs, caches, local signing material, and build outputs belong outside Git.

To retain the exact build inputs, APK hashes, lint result and runtime output in the verification directory:

```powershell
uv run --project companion --locked python mobile/android/scripts/verify_android.py build
uv run --project companion --locked python mobile/android/scripts/verify_android.py runtime --serial '<device-serial>'
```

The runtime command first checks that the current sources and APKs match the successful build report, then installs both development APKs on that explicit target and runs the isolated instrumentation. It does not wipe or uninstall the target. It refuses a failed or missing instrumentation result even when `adb` itself returns zero.

To install on a deliberately selected emulator or Android phone with debugging enabled:

```powershell
$auraAdb = '.\.tools\android\sdk\platform-tools\adb.exe'
& $auraAdb devices -l
& $auraAdb -s '<device-serial>' install -r '.\mobile\android\app\build\outputs\apk\debug\app-debug.apk'
```

Replace `<device-serial>` with the intended listed target. Installation over an existing compatible app preserves its private library; uninstalling to resolve a signing mismatch does not.

## Verification status and runtime checks

The current [JVM transcript](core/verification/jvm-host.txt) records **30 groups / 82,213 checks**, including 49,471 incremental-validator checks, 32,159 response-fragment checks, 338 transfer-wire checks and 245 complete-archive checks. It uses **19 complete C-generated archives** and rejects an additional raw prefix. File import and partial-download replay share one canonical validator. The [source-bound report](core/verification/kotlin-core.json) compares C archives and receipts, an independent Python parser/muxer, the Kotlin parser/muxer, exact Ogg bytes, and actual FFmpeg decoded sample counts. The transfer codec checks 14 actual C-generated replies and four SELECT fragment chains, alongside malformed identity/length/CRC/receipt cases. JVM/host checks remain separate from Android storage and MediaCodec evidence; neither establishes a working BLE link.

**Android API 29 emulator execution passed: 19 cases / 366 assertions.** The real `OMX.google.opus.decoder` produced 48 kHz mono PCM with exact retained durations. The original nine library cases pass alongside ten download cases covering complete-record resume, actual SQLite transaction rollback, corruption retention, session ownership and finalized/OPEN handoff to the playable library. Physical OPEN provenance and byte-identical source exports remain intact after publication. Both APKs build with zero Android lint findings. [Build report](verification/android-build.json) · [Runtime report](verification/android-runtime.json) · [Detailed verification and limits](VERIFICATION.md). These checks use synthetic C fixtures on an emulator; physical-phone, Bluetooth and wearable qualification remain open.

The [Android smoke instrumentation guide](app/src/androidTest/README.md) describes tests against real Android SQLite, filesystem synchronization, MediaExtractor, and MediaCodec. They use public synthetic C fixtures and a test-only content provider, with a separate private test namespace; they do not operate on the user's library. After building and installing both APKs on the selected target:

```powershell
& $auraAdb -s '<device-serial>' install -r '.\mobile\android\app\build\outputs\apk\androidTest\debug\app-debug-androidTest.apk'
& $auraAdb -s '<device-serial>' shell am instrument -w -r com.aura.notes.test/com.aura.notes.SmokeInstrumentation
```

Require the instrumentation's final `Activity.RESULT_OK` and `resultdetailJSON.passed == true`, not just a successful `adb` launch. The runner checks full decode/sample counts, source preservation, receipt upgrades and conflicts, idempotent imports, manual edits, and concrete cold-recovery conditions. It does not simulate an actual sudden power failure, validate a physical pendant, or establish BLE/background behavior. Separately verify document-picker interactions, audio focus, headset removal, rotation, Back navigation, copy/share, and exported bytes on the target Android versions before relying on the app with personal recordings.

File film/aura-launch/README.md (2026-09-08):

# AURA launch film

An original 44-second product concept film built around **“Capture the context of your life.”** The story connects life's passing thoughts and moments with personal choice and new possibilities. Hyperframes 0.8.31, actual A03 Blender enclosure renders, a real animated inside view, and an original local soundtrack preserve the quiet, cinematic presentation.

## Deliverables

- `renders/aura-launch.mp4` — final 1920×1080, 30 fps H.264/AAC video.
- `captions.vtt` — English captions describing the on-screen message and illustrative note.
- `renders/poster.jpg`, `renders/contact-sheet.jpg` — website poster and scene overview.
- `index.html` — editable Hyperframes composition, one paused seekable GSAP timeline.
- `STORYBOARD.md`, `BRIEF.md`, `frame.md` — narrative, product constraints, and visual direction.
- `assets/aura-score.wav`, `scripts/score.mjs` — original soundtrack and reproducible source.
- `assets/aura-device.glb`, `scripts/assembly-scene.mjs`, `scripts/assembly-model.mjs` — actual enclosure geometry and seekable Three.js assembly shot.
- `qa/` — visual and tool validation evidence.

Final output metadata, strict Hyperframes checks, full decoding, audio, captions, and visual verification are recorded in `qa/VERIFICATION.md`.

Verified final MP4: **44.000 seconds, 1,320 frames, 13,469,070 bytes**. SHA-256: `1F208827348028C6ABA7508524E1D1DA0FFA45779663BF3BF75E97FB6CDFAEE0`. Strict checks have zero findings; all frames decode successfully.

## Reproduce locally

Requires Node.js 22+ and FFmpeg/FFprobe on PATH. From this directory:

```powershell
npm ci
npx hyperframes browser ensure
npm run score
npm run build:assembly
node scripts/verify-context.mjs
npm run check
npm run render
npm run dev
```

The preview command starts managed Hyperframes Studio in the background. The final film uses only staged local assets and a packaged font; rendering requires no HeyGen account, voice service, remote music catalog, or media generation API.

To regenerate the detail and profile photographs, `scripts/render_a03_still.py` loads the saved `../../enclosure/aura-product.blend` scene in Blender 5.2.1 LTS. Run each view in its own Blender process using the commands in that script's header. It changes only camera, render visibility, and output settings; it does not rebuild or save geometry. Source-scene hashes, camera poses, output sizes, and image hashes are recorded in `qa/plate-detail.json` and `qa/plate-profile.json`.

On the installed Windows environment, Blender is at `C:/Program Files/Blender Foundation/Blender 5.2/blender.exe`. For example, from this directory:

```powershell
& 'C:/Program Files/Blender Foundation/Blender 5.2/blender.exe' --background '../../enclosure/aura-product.blend' --python 'scripts/render_a03_still.py' -- detail
```

Replace `detail` with `profile` for the second plate.

## Design truth

The object and its controls come from the actual A03 Blender case built alongside the PCB. The complete black front face is the recording paddle; the physical microphone disconnect is on the silver side frame. The film presents intended interactions and an explicitly illustrative phone-and-cloud notes interface. It makes no claim of production readiness, validated battery life, certification, availability, or a shipping date.

The verified original A01 film and complete source are preserved in `../archive/A01`. The unreleased A02 source draft is preserved in `../archive/A02-draft`. The current source is A03.

The preceding A03 film and source remain in Git commit `1569645a292b8bd147bb208ccc96d9fe8081adc5`. This revision preserves the product photographs and established scene motion, adds an eight-second inside/assembly sequence, and extends the original score. It creates no additional media archive. The latest-CLI probe confirmed Hyperframes 0.8.31 remains current.

## Audio

Original stereo ambient score: 48 kHz/16-bit PCM, 44 s. A locally synthesized suspended harmonic progression, sparse bell tones, and controlled delay, with no sampled music, external voices, or unlicensed audio. Fades are baked into the source to make output deterministic; final encoded levels are recorded in `qa/VERIFICATION.md`.

## Inside and assembly sequence

The actual A03 GLB opens into five opaque groups, holds an angled view of its board and cell, then reassembles. Group classification and local-axis separation match the website's assembly explorer. The camera and part transforms are pure functions of film time, making reverse and random seeks repeatable. The sequence illustrates design structure; internal shapes include reference component envelopes and do not prove production fit.

The latest model incorporates the frozen nine-component PCB placement corrections and dimension-driven internal package proxies. Its 89 nodes preserve the same five animation groups. The case's eight print files are byte-for-byte unchanged; the enclosure package independently verifies 56 exported package transforms and 50 body dimensions. This film refresh changes only the internal model and its rendered sequence. The story, exterior photographs, score, timing and captions remain unchanged. See [mechanical package details](../../enclosure/PACKAGE-ENVELOPES.md) and [final film verification](qa/VERIFICATION.md).

The subsequent C18 orientation-only source correction records 270° while retaining its symmetric visual body at 90°. The model audit explicitly reports **55 exact rotations plus one proven C18 body-symmetry match**, with no unintended deviations. Complete triangle and shading-normal invariance is verified in all three GLBs. The saved models and this already-verified film remain byte-for-byte unchanged; PCB pin orientation remains explicit in the hardware source.

The prior assembly film/source checkpoint is Git commit `4d62c6b2f379fb410dc97941b622431bd6104f9b`. Current model/media handoff hashes are in [mechanical-sync-release.json](qa/mechanical-sync-release.json). No additional video archive was created for this sync.

Three.js and its addons are bundled locally with esbuild. A fixed studio environment is prefiltered once and stored locally as a half-float texture. This preserves the reflections and avoids procedural environment convolution during video rendering. `npm run bake:environment` regenerates it using the bundled Chrome runtime (or a `CHROME_PATH` override); ordinary rendering uses the supplied texture. Strict checking remains enabled. No diagnostic overlays appear in the movie.

## Sources

- Hyperframes: https://github.com/heygen-com/hyperframes
- Hyperframes quickstart: https://hyperframes.heygen.com/quickstart
- Manrope: https://github.com/google/fonts/tree/main/ofl/manrope

See `LICENSES.md` for asset provenance. No public publishing command was executed.

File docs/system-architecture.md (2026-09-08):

# From a thought to useful context

```mermaid
flowchart LR
  A[Face paddle + physical privacy switch] --> B[nRF52840: dual PDM capture]
  B --> C[Recoverable PCM journal in NAND]
  C -->|Encrypted BLE + CRC| D[Local Python companion]
  D --> E[Verified WAV + local Whisper]
  E --> F[Transcript + editable note]
  F -->|Explicit upload / add-only token| G[Convex owner-scoped storage]
  H[Next.js AURA Notes] <-->|Authenticated realtime queries| G
  H --> I[Selected notes + personal profile]
  I --> J[Reviewed Markdown Context Pack]
  J -->|Copy or attach| K[ChatGPT / Claude / Gemini / Grok / any chat]
  G -->|Approved notes / read-only token| L[MCP get_aura_context]
  L --> M[Compatible AI client]
```

The pendant captures audio; transcription runs on the local computer. The portal receives text only through the supplied upload path. Nothing opens an AI provider or sends context merely because a recording is captured. The owner controls live-note inclusion; a device token may opt future uploads into live context only when created with that explicit choice. A context token can read the profile and enabled notes but cannot write them.

## Interfaces

- [Hardware and physical pin mapping](hardware.md)
- [Bluetooth command, response and CRC contract](ble-protocol.md)
- [Firmware storage recovery and maintenance](../firmware/README.md)
- [Companion installation, transcription and upload](../companion/README.md)
- [Portal setup, HTTP schema and MCP connection](../portal/README.md)

## Data lifecycle

Capture closes on a physical press, privacy cutoff, low voltage or storage error. Committed journal pages can recover an interrupted recording. Sync copies bytes, verifies per-chunk and whole-record CRC, then writes a WAV. The device copy remains until an explicit verified delete. Reclaiming NAND requires every record to be deleted plus a physical maintenance hold and confirmed command.

Companion 0.3.1 revalidates previously saved WAVs and capture metadata to avoid repeat radio downloads. Missing receipts can be repaired after validating the whole WAV. The Bluetooth session closes before local transcription and optional upload, with individual processing failures retained for explicit recovery. Notes and receipts use atomic file replacement. These improvements do not add mobile background sync or automatic device deletion. See the [Omi comparison and first-wear plan](research/omi-review.md) for the evidence and remaining hardware work.

Whisper produces a local transcript. Default summaries are extractive; optional local Ollama output stays editable. Upload sends a note with a stable source identity, making retries idempotent within the configured ingestion token. Uploaded originals are stored independently from exported Context Packs. Archiving removes a note from live context immediately and can be reversed.
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

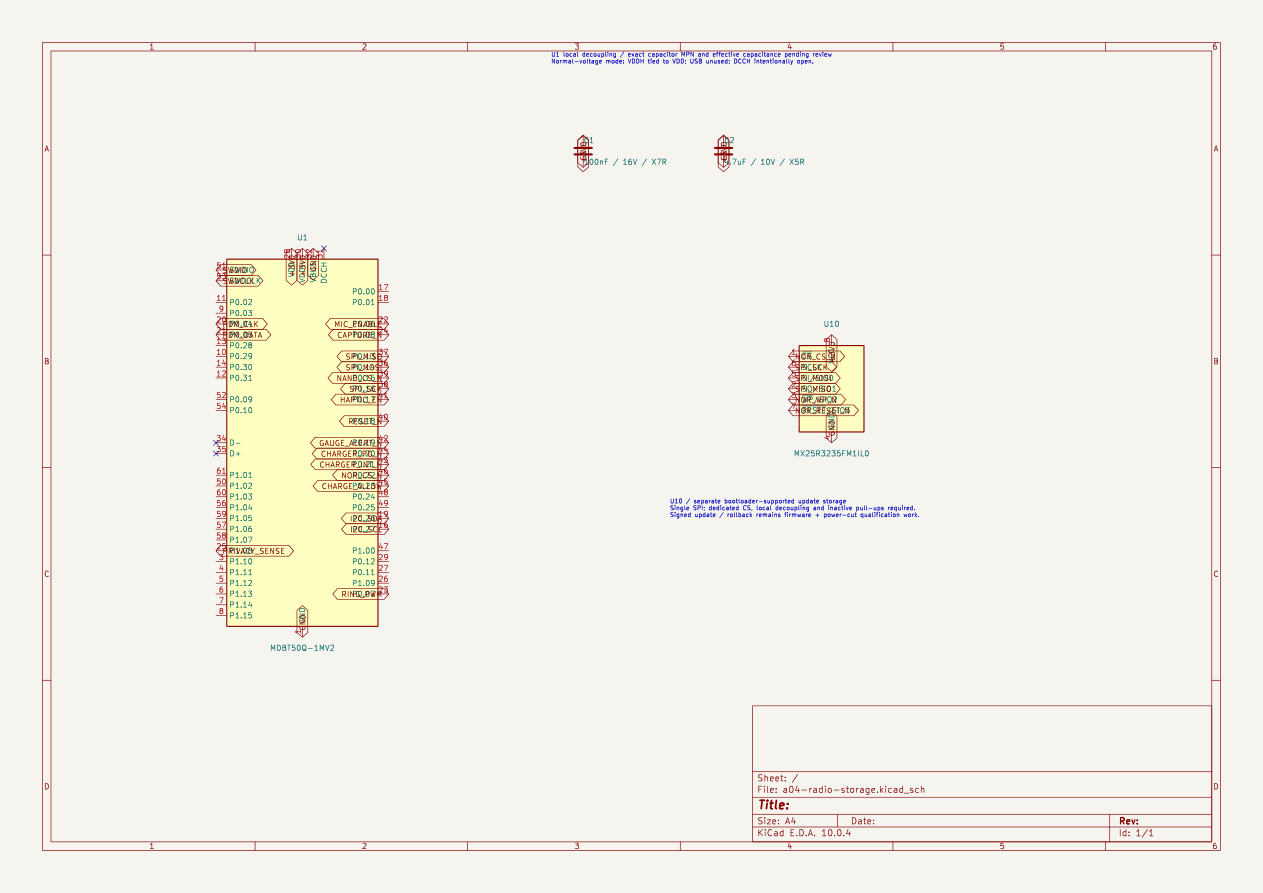
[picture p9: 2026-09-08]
hardware/a04/review/radio-storage/a04-radio-storage.png

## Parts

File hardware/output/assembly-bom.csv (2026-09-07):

References | Quantity | ManufacturerPartNumber | Description | FootprintKey | Status | ReviewNotes
U1 | 1 | MDBT50Q-1MV2 | nRF52840 BLE module | radio | ENGINEERING CANDIDATE - NOT APPROVED FOR PURCHASE | Normal-voltage mode: VDD and VDDH tied3.0V; DCCH open; unused VBUS grounded; internal LFRC initial firmware. Antenna keepout Y>11.95 per Raytac Version L.
MK1 MK2 | 2 | SPH0641LU4H-1 | Left PDM microphone | mic | ENGINEERING CANDIDATE - NOT APPROVED FOR PURCHASE
U2 | 1 | W25N01GVZEIG | 1Gbit SPI NAND /128MiB | flash | ENGINEERING CANDIDATE - NOT APPROVED FOR PURCHASE | Corrected ZE package8×6mm, EP3.4×4.3mm. RevR permits EP floating or GND; GND chosen. No exposed vias under EP. Internal ECC/bad-block handling required.
U3 | 1 | BQ25185DLHR | 53mA Li-ion powerpath charger | charger | ENGINEERING CANDIDATE - NOT APPROVED FOR PURCHASE | R_ISET5.62k gives53.38mA nominal. R22 seriesNTC and U9 hardwarehot cutoff; Q1 requires firmwarepermission, defaultoff. Thermal calculation is conditional on selected NTC and pack qualification.
U4 U7 | 2 | TLV75530PDBVR | 3.0V system regulator | ldo | ENGINEERING CANDIDATE - NOT APPROVED FOR PURCHASE
U5 | 1 | MAX17048G+T10 | ModelGauge fuel gauge | gauge | ENGINEERING CANDIDATE - NOT APPROVED FOR PURCHASE
U6 | 1 | DRV2605LDGSR | LRA closed-loop haptics | haptic | ENGINEERING CANDIDATE - NOT APPROVED FOR PURCHASE
U8 | 1 | SN74LVC2G125DCUR | Ioff protected PDM isolation | buffer | ENGINEERING CANDIDATE - NOT APPROVED FOR PURCHASE
U9 | 1 | TLV6700DDCR | Independent charge hot cutoff | comparator | ENGINEERING CANDIDATE - NOT APPROVED FOR PURCHASE | INB- above400mV sinks OUTB; falling below~394.5mV opens chargepermission. Require1ms stableVSYS before CHG_ALLOW. C18 bypass nearVDD.
Q1 | 1 | DMG2302UK-7 | Default-off charge permission | nmos | ENGINEERING CANDIDATE - NOT APPROVED FOR PURCHASE | Gate1 drivenMCUwithR3pulldown; source2 comparatorOUTB; drain3 active-lowchargerCE. Bodydiode source-to-drain prevents OFF drain pullinglow.
SW1 | 1 | JS202011JCQN | Mechanical DPDT microphone OFF | privacy | ENGINEERING CANDIDATE - NOT APPROVED FOR PURCHASE | Center commons2,5. OFF connects2-3 and5-6. Break-before-make; verify actuator orientation on first article.
SW2 | 1 | KMR211NGULCLFS | Flush face record / stop | record | ENGINEERING CANDIDATE - NOT APPROVED FOR PURCHASE | C&K KMR211 NG ULC: no groundtab, lowcurrent contacts,1.2N,0.20±0.10mm electricaltravel,1.9mm actuatorheight. A03 face0.35mm travel/.02mm restgap; returngasket/overtravel needqualification. Singlepressrecord/stop,doublepressbookmark.
D1 | 1 | BAT54WS-7-F | Reverse-dock Schottky | diode | ENGINEERING CANDIDATE - NOT APPROVED FOR PURCHASE
D2 | 1 | PESD5V0S1BA,115 | Dock transient suppression | diode | ENGINEERING CANDIDATE - NOT APPROVED FOR PURCHASE
LED1 | 1 | LTST-C190KFKT | Amber hard recording indicator | led | ENGINEERING CANDIDATE - NOT APPROVED FOR PURCHASE | Indicator receives microphone rail power, has no independent firmware-off command.
R1 | 1 | RC0402FR-075K62L | 5.62k | r0402 | ENGINEERING CANDIDATE - NOT APPROVED FOR PURCHASE | YageoRC0402 1%,63mW at70C,50V,100ppm/C. Manufacturer series/specsheet crosscheck; supplier availability to confirm.
R2 | 1 | RC0402FR-0724KL | 24k | r0402 | ENGINEERING CANDIDATE - NOT APPROVED FOR PURCHASE | YageoRC0402 1%,63mW at70C,50V,100ppm/C. Manufacturer series/specsheet crosscheck; supplier availability to confirm.
R3 R4 R5 R11 R13 R18 R19 R20 R21 R23 | 10 | RC0402FR-0710KL | 10k | r0402 | ENGINEERING CANDIDATE - NOT APPROVED FOR PURCHASE | YageoRC0402 1%,63mW at70C,50V,100ppm/C. Manufacturer series/specsheet crosscheck; supplier availability to confirm.
R6 R7 | 2 | RC0402FR-074K7L | 4.7k | r0402 | ENGINEERING CANDIDATE - NOT APPROVED FOR PURCHASE | YageoRC0402 1%,63mW at70C,50V,100ppm/C. Manufacturer series/specsheet crosscheck; supplier availability to confirm.
R8 R9 R10 R15 | 4 | RC0402FR-07100KL | 100k | r0402 | ENGINEERING CANDIDATE - NOT APPROVED FOR PURCHASE | YageoRC0402 1%,63mW at70C,50V,100ppm/C. Manufacturer series/specsheet crosscheck; supplier availability to confirm.
R14 | 1 | RC0402FR-071KL | 1k | r0402 | ENGINEERING CANDIDATE - NOT APPROVED FOR PURCHASE | YageoRC0402 1%,63mW at70C,50V,100ppm/C. Manufacturer series/specsheet crosscheck; supplier availability to confirm.
R16 R17 | 2 | RC0402FR-0733RL | 33 | r0402 | ENGINEERING CANDIDATE - NOT APPROVED FOR PURCHASE | YageoRC0402 1%,63mW at70C,50V,100ppm/C. Manufacturer series/specsheet crosscheck; supplier availability to confirm.
R22 | 1 | RC0402FR-073K3L | 3.3k | r0402 | ENGINEERING CANDIDATE - NOT APPROVED FOR PURCHASE | YageoRC0402 1%,63mW at70C,50V,100ppm/C. Manufacturer series/specsheet crosscheck; supplier availability to confirm.
C1 C5 C11 C16 C18 | 5 | C0402C104K4RACTU | 100nF | c0402 | ENGINEERING CANDIDATE - NOT APPROVED FOR PURCHASE | KEMET candidate,10% tolerance;1uF/100nF16V,10nF50V,2.2uF/4.7uF10V.4.7uF is X5R; other assigned parts X7R. Verify effective capacitance at bias/temperature;10uF part remains unqualified.
C2 C6 C8 | 3 | C0603C475K8PACTU | 4.7uF | c0603 | ENGINEERING CANDIDATE - NOT APPROVED FOR PURCHASE | KEMET candidate,10% tolerance;1uF/100nF16V,10nF50V,2.2uF/4.7uF10V.4.7uF is X5R; other assigned parts X7R. Verify effective capacitance at bias/temperature;10uF part remains unqualified.
C3 C4 | 2 | 939113424610-T3N | 100nF silicon | sicap | ENGINEERING CANDIDATE - NOT APPROVED FOR PURCHASE | Murata BBSC silicon,100nF±15%,3.8V rated,1.2×0.7×0.4mm. Replaces ClassII ceramic at mic. Rev3.00 pads/MPN and assemblyRev1.42 checked; mask/paste registration, assembly leakage and acousticperformance needqualification.
C7 C10 | 2 | C0603C225K8RACTU | 2.2uF | c0603 | ENGINEERING CANDIDATE - NOT APPROVED FOR PURCHASE | KEMET candidate,10% tolerance;1uF/100nF16V,10nF50V,2.2uF/4.7uF10V.4.7uF is X5R; other assigned parts X7R. Verify effective capacitance at bias/temperature;10uF part remains unqualified.
C9 | 1 | C0805C106K8PACTU | 10uF | c0805 | ENGINEERING CANDIDATE - NOT APPROVED FOR PURCHASE | KEMET candidate,10% tolerance;1uF/100nF16V,10nF50V,2.2uF/4.7uF10V.4.7uF is X5R; other assigned parts X7R. Verify effective capacitance at bias/temperature;10uF part remains unqualified.
C12 C13 C14 C15 | 4 | C0603C105K4RACTU | 1uF | c0603 | ENGINEERING CANDIDATE - NOT APPROVED FOR PURCHASE | KEMET candidate,10% tolerance;1uF/100nF16V,10nF50V,2.2uF/4.7uF10V.4.7uF is X5R; other assigned parts X7R. Verify effective capacitance at bias/temperature;10uF part remains unqualified.
C17 | 1 | C0402C103K5RACTU | 10nF | c0402 | ENGINEERING CANDIDATE - NOT APPROVED FOR PURCHASE | KEMET candidate,10% tolerance;1uF/100nF16V,10nF50V,2.2uF/4.7uF10V.4.7uF is X5R; other assigned parts X7R. Verify effective capacitance at bias/temperature;10uF part remains unqualified.

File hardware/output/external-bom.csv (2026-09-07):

Item | Qty | Candidate | Status
Protected 150mAh pack | 1 | FPBattery/DNK302025-150 | Preliminary pack drawing; voltage tolerance, maximum dimensions, swelling and supplier approval unresolved
Pack temperature sensor | 1 | Semitec103AT-2 | Thermal attachment, assembled R/T acceptance and lead routing unqualified
LRA motor | 1 | Precision MicrodrivesC08-00A | Prototype datasheet; source availability and calibrated drive unqualified
Rear contact assembly | 1 | Custom 3-contact carrier/tails | Exact contacts/material/retention/current/wear not selected
Magnetic dock | 1 | Custom keyed 5V100mA dock | Electrical/mechanical design and qualification incomplete

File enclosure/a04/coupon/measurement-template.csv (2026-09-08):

specimen | quantity | nominal_mm | measured_direction_1_mm | measured_direction_2_mm | instrument_uncertainty_mm | process_material_orientation | finish_stage | fit_observation | operator_date
F352 | working_face_diameter | 35.20
R15 | bore_diameter | 35.50
R20 | bore_diameter | 35.60
R25 | bore_diameter | 35.70
R30 | bore_diameter | 35.80
10 | wall_thickness | 1.00
12 | wall_thickness | 1.20
15 | wall_thickness | 1.50
B26 | transverse_bore | 2.60
P24 | straight_shaft_diameter | 2.40
P25 | straight_shaft_diameter | 2.50
P26 | straight_shaft_diameter | 2.60

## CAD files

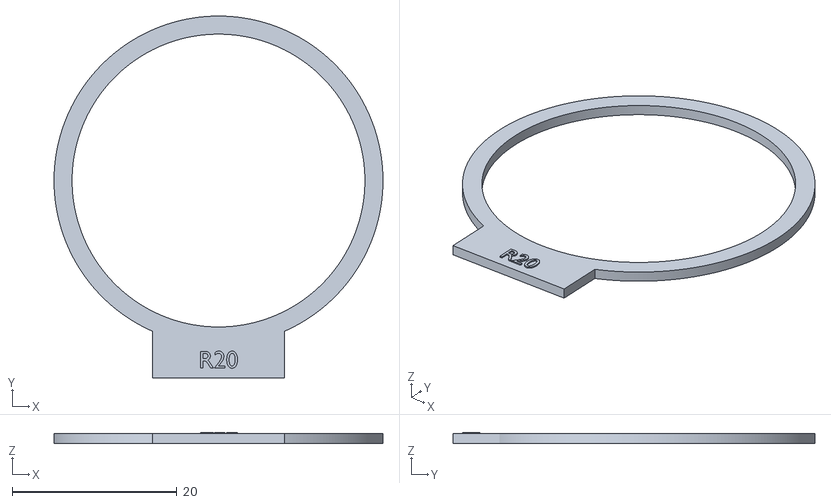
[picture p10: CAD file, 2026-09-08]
enclosure/a04/coupon/a04-face-ring-r20.stl
40.0 x 44.0 x 1.35

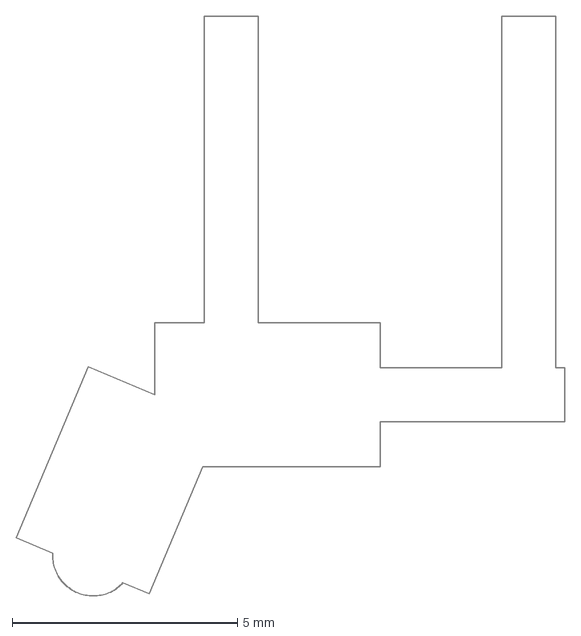
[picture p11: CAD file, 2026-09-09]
enclosure/a04/mechanism-m2-manufacturing/m2-s1-lower-support-profile.dxf
12.2 x 12.9 mm

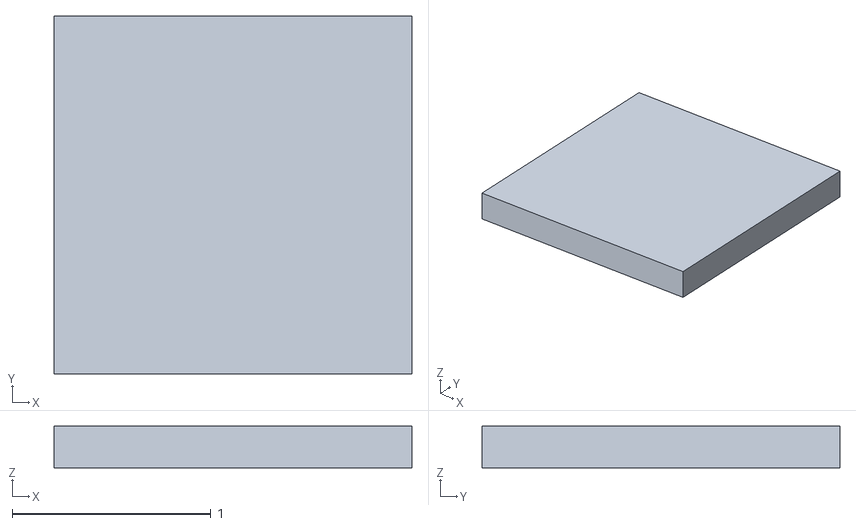
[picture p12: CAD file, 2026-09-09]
enclosure/a04/mechanism-m2/documented-pack/14_insulating_contact_pad.stl
1.80 x 1.80 x 0.21

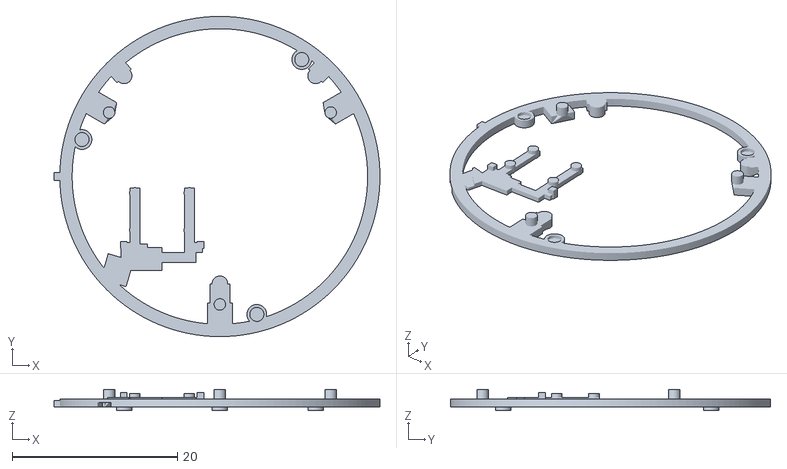
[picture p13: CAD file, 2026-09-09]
enclosure/a04/mechanism-m2/thin-cell/03_pcb_clamp_and_face_guide.stl
39.5 x 38.8 x 2.55

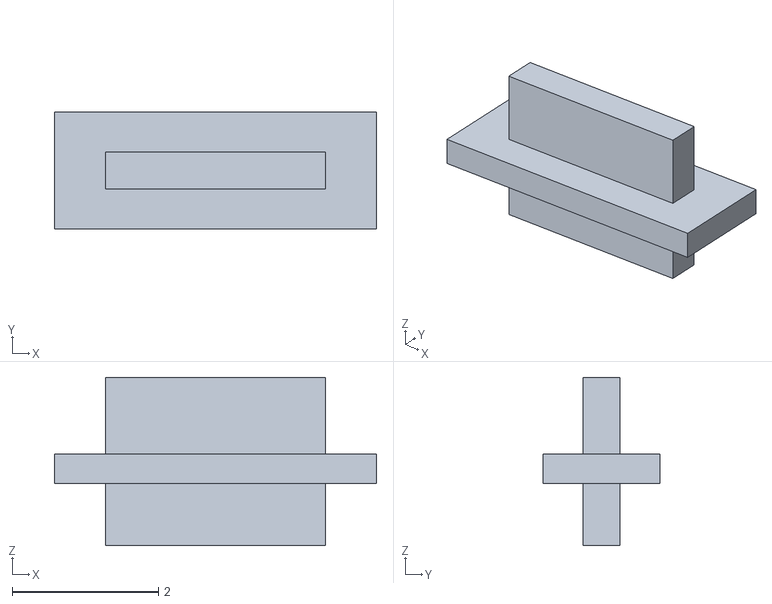
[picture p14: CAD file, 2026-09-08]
enclosure/a04/mechanism/documented-pack/05_moving_status_lightpipe.stl
4.40 x 1.60 x 2.30

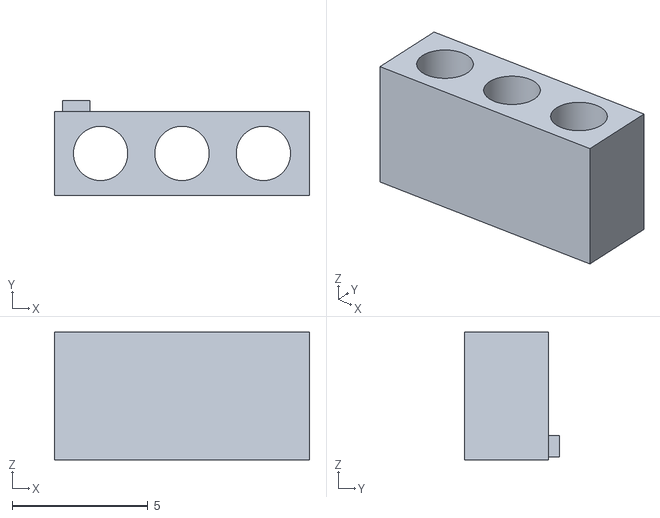
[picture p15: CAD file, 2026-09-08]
enclosure/a04/mechanism/thin-cell/10_dock_contact_access_carrier.stl
9.40 x 3.50 x 4.70

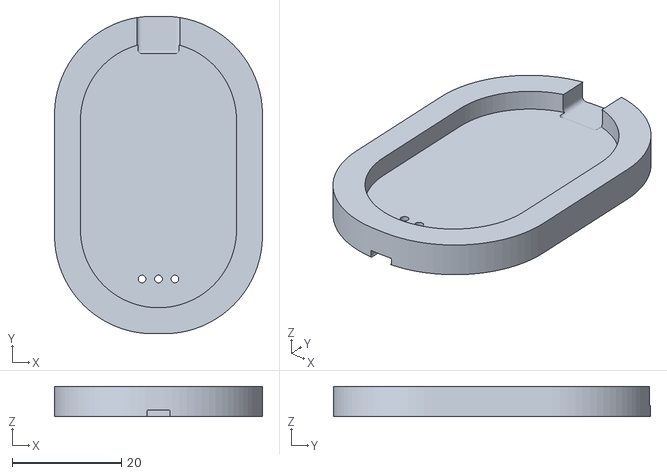
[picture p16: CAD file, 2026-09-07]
enclosure/aura-dock-alignment-jig.stl
38.0 x 58.0 x 5.50

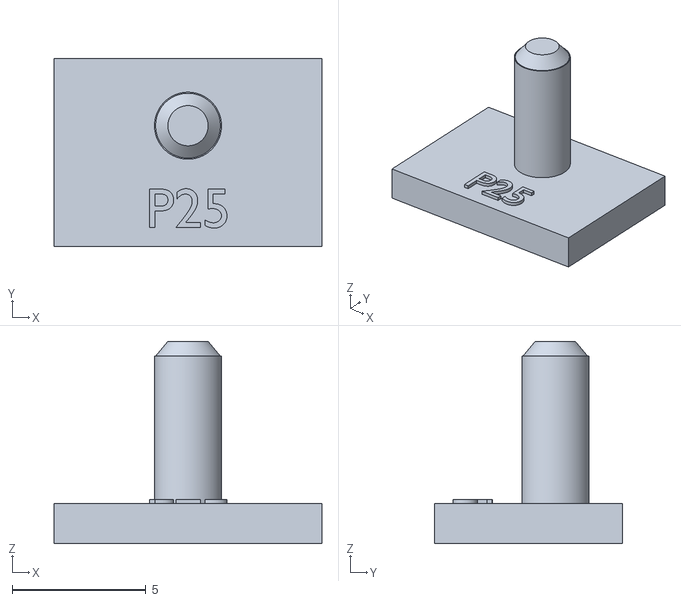
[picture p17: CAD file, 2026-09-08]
enclosure/a04/coupon/a04-relative-pin-25.stl
10.0 x 7.00 x 7.55

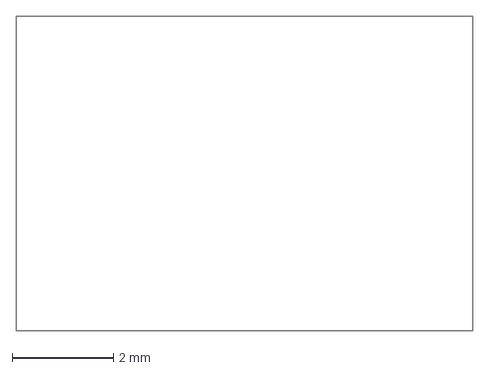
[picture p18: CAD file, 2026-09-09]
enclosure/a04/mechanism-m2-manufacturing/m2-s1-shoe-profile.dxf
9.00 x 6.20 mm

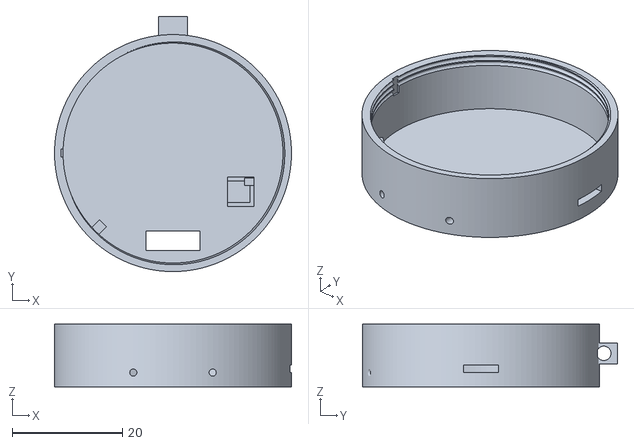
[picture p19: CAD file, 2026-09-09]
enclosure/a04/mechanism-m2/documented-pack/01_fixed_cup.stl
43.0 x 46.3 x 11.4

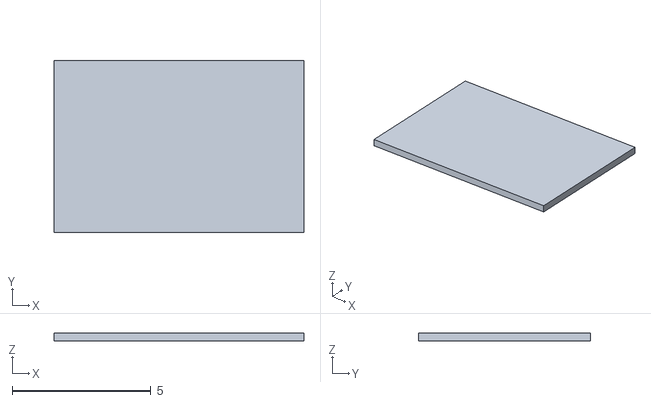
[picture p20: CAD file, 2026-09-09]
enclosure/a04/mechanism-m2/thin-cell/08_measured_plunger_shoe.stl
9.00 x 6.20 x 0.3

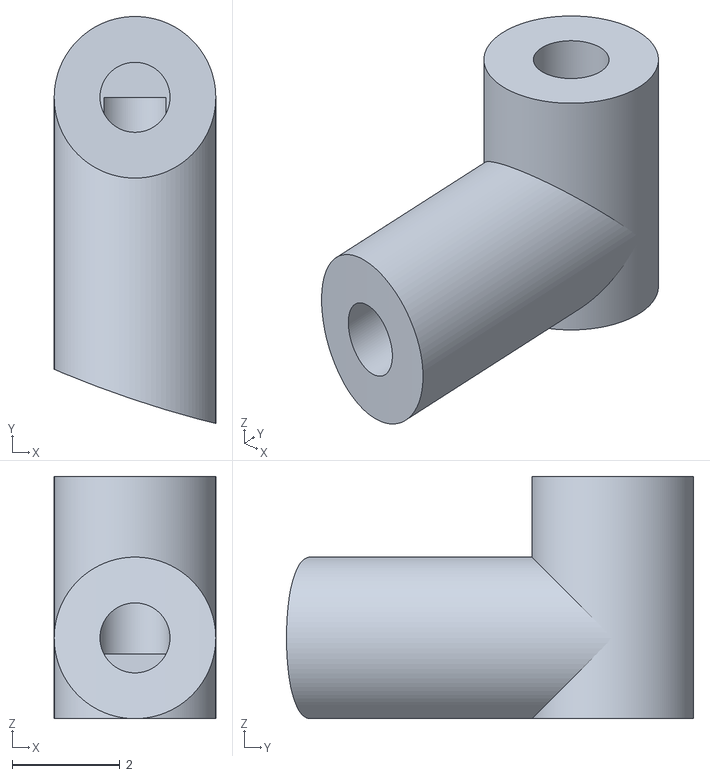
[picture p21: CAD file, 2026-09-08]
enclosure/a04/mechanism/documented-pack/09_acoustic_duct_left.stl
3.00 x 7.56 x 4.50

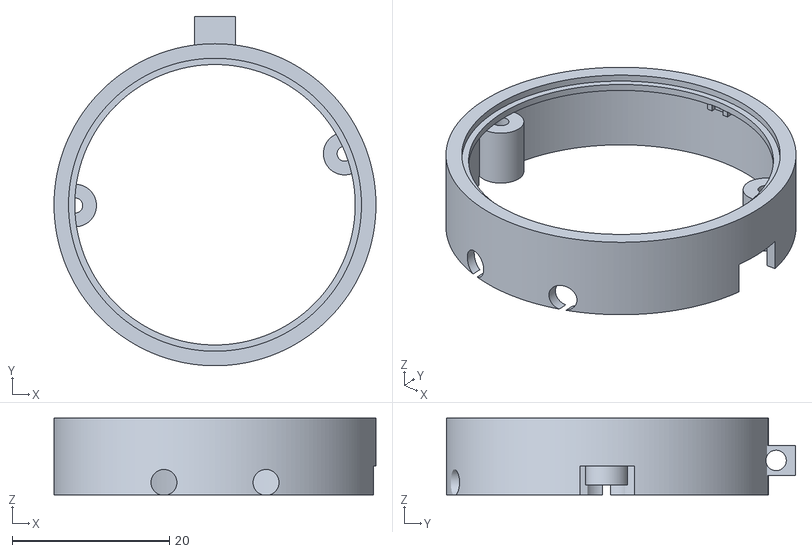
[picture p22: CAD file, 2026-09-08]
enclosure/a04/mechanism/thin-cell/01_front_housing_with_bail.stl
41.0 x 44.5 x 9.80

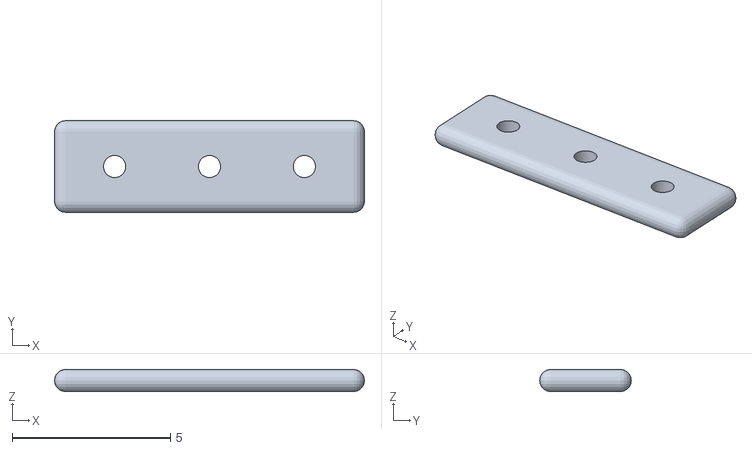
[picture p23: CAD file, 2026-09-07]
enclosure/aura-contact-carrier.stl
9.80 x 2.90 x 0.7

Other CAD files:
enclosure/a04/coupon/a04-face-ring-r30.stl
enclosure/a04/mechanism-m2/documented-pack/07_cartridge_keeper_left.stl
enclosure/a04/mechanism-m2/thin-cell/13_lower_steel_stiffener.stl
enclosure/a04/mechanism/documented-pack/11_right_lower_sensor_carrier.stl
enclosure/a04/coupon/a04-coupon-layout.blend
enclosure/a04/coupon/a04-face-gauge-35p2.stl
enclosure/a04/coupon/a04-face-ring-r15.stl
enclosure/a04/coupon/a04-face-ring-r25.stl
enclosure/a04/coupon/a04-relative-pin-24.stl
enclosure/a04/coupon/a04-relative-pin-26.stl
enclosure/a04/coupon/a04-wall-bail-card.stl
enclosure/a04/mechanism-m2/documented-pack/02_threaded_bezel.stl
enclosure/a04/mechanism-m2/documented-pack/03_pcb_clamp_and_face_guide.stl
enclosure/a04/mechanism-m2/documented-pack/04_captive_face.stl
enclosure/a04/mechanism-m2/documented-pack/05_flush_status_window.stl
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

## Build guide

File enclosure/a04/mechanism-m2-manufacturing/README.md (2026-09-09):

# M2 S1 steel development drawings and cutting profiles

**For development quoting and unpowered fixtures only. No fabrication, strength, native PCB fit or wearable release.** These artifacts are derived from the two actual frozen S1 steel meshes. They do not revise the enclosure or substitute new geometry.

The two-sheet `m2-s1-steel-development-drawings.pdf` shows top and edge views, nominal dimensions, material/process notes and hashes. The separate `m2-s1-shoe-profile.dxf` and `m2-s1-lower-support-profile.dxf` are 1:1 millimetre cutting profiles. Matching SVGs provide a simple 1:1 visual profile. The PDF is an 8:1 view at A4 / 100%; dimensions are nominal and the mesh-derived DXF controls the contour. Do not scale a print to create toolpaths.

| Form | Mesh thickness reference | Defined actual incoming metal acceptance | Exterior profile |
|---|---:|---:|---|
| 08 metal plunger shoe | 0.300 mm | 0.28-0.32 mm | 9.000 x 6.200 mm rectangle, 4 vertices |
| 13 lower steel support | 1.000 mm | 0.95-1.00 mm | 12.174617 x 12.864318 mm envelope, 71 vertices |

These thickness values concern the separate steel, before adhesive and insulation. Preserve the minimum finished metal thickness and net CAD section after processing. Numerical extraction/round-trip tolerances in the verifier are computational checks, not approved manufacturing tolerances.

## Profile coordinates and exact source correspondence

Each DXF has one closed R2000 `LWPOLYLINE`, no holes, no extra construction entities, and `$INSUNITS=4` / `$MEASUREMENT=1`. The coordinates use a lower-left XY envelope origin, which is not a physical machined datum. CAD +Y is up, viewed from +Z. Restore assembly coordinates with `CAD XY = profile XY + origin`:

- Shoe origin: (-11.500000, -7.600000) mm.
- Support origin: (-15.074617, -14.264318) mm.

SVG Y is reflected for normal screen display; the DXF coordinate system is unchanged. The 71-vertex support includes the frozen mesh's faceted root curve. No new radius, smoothing, corner relief, kerf offset or geometric compensation has been applied. Quote any proposed contour/edge change for engineering review before manufacture.

`extract_profiles.py` reads the original BLEND files without saving them. It matches the two selected world-geometry hashes to each source manifest, extracts actual top-cap boundary edges, confirms a single closed boundary and two-plane extrusion, compares top and bottom profiles, checks volume against area times thickness, and independently compares the exported STL cap after its recorded transformation. It also verifies that both depth variants share the same XY forms. Full coordinates and source hashes are in `profiles.json`.

`manufacturing-verification.json` records independent ezdxf 1.4.4 reading without recovery, zero audit fixes/errors, one closed polyline per file, no self-intersections, area agreement and vertex round-trip error below 0.000001 mm. The PDF has two A4 landscape pages, required text and an explicit visual review of both final Poppler renders. It binds all supplied outputs plus their frozen source files. This proves digital correspondence only.

## Material, processing and interfaces

The candidate is cold-rolled ASTM A666 Type 301 / UNS S30100 half-hard, explicitly ordered and lot-certified for 0.2% yield at least 110 ksi / 758 MPa. A temper/hardness description alone is insufficient: the manufacturer's standard production guarantee can be tensile strength, yield or hardness. The listed 0.02-1.57 mm strip capability encompasses both thicknesses but is not a verified stock lot, width, MOQ or supply commitment. See [Elgiloy 301 material data](https://www.elgiloy.com/wp-content/uploads/2024/06/301-Alloy-Stainless-Steel-Data-Sheet-06042024.pdf) and [strip capability](https://www.elgiloy.com/wp-content/uploads/2024/05/ESM-Stainless-Strip-LineCard-DIGITAL-5.30.2024-compressed-1.pdf).

Preserve the supplied cold-worked temper. Controlled cold blanking or cool machining/deburring are proposed engineering process choices, without universal approved tool settings. No anneal, weld or hot straightening is credited without requalification; laser/EDM edges require finished-edge/property qualification. Parent-stock certification does not establish heat-affected edge properties. [Ulbrich discusses loss of cold-work strength with annealing](https://www.ulbrich.com/blog/understanding-the-difference-between-annealing-and-tempering/); [Alleima discusses welding effects for a 301-equivalent strip](https://www.alleima.com/en/technical-center/material-datasheets/strip-steel/alleima-12r11/).

No numeric XY tolerance, flatness, burr-height or edge-radius limit has been approved. Request the achievable values and proposed edge condition for review; do not silently add a general tolerance. No sharp edge or burr may damage the fitted insulation. Perform metal work before adhesive/dielectric assembly, preserving the net source section and accepted thickness.

The insulating contact pad and liner are excluded from these two cutting profiles. Existing S1 interface allocations remain references: the shoe contact pad is nominally 0.21 mm including adhesive and must be measured/finished per mounted switch. The nominal remaining allocation is 0.19-0.23 mm before printed and mounted-height uncertainty. The lower support liner is proposed at 0.08-0.10 mm, with a 1.10 mm nominal root packet and measured 0-0.07 mm shim allocation. These figures do not approve actual coverage, dielectric performance, edge protection, retention, flatness, clamp preload or assembled fit.

All 72 native PCB features / 68 purchased PCB references, actual board fit, supplier pack, root-joint displacement, switch endpoint and physical structural qualification remain open. The frozen S1 strength screening and its limitations still apply. No supplier message, order or fabrication instruction has been sent.

## Reproduce and verify

From this folder, use Blender 5.2 for extraction and Python with ReportLab for drawing creation:

```powershell
blender -b -t 2 --python extract_profiles.py
python make_drawings.py
```

A full data audit uses `pypdf` and `ezdxf==1.4.4` and requires a fresh exact-PDF visual review record after regenerating the PDF. Poppler `pdftoppm` creates the review images. The extraction script deliberately requires the frozen S1 readiness hash; a different source checkpoint needs a new engineering review, not a bypassed assertion.

To verify the delivered package and its source bindings with standard Python only:

```powershell
python verify_manufacturing.py --verify
```

The original M2 package remains untouched and still has its separate `package_m2.py --verify` check. Fabrication, material lot/process, native fit and physical qualification flags remain false throughout this package.

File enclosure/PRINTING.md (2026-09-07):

# AURA A03 — printing and assembly

Start with a mechanical fit prototype. All eight STL parts use millimetres at 100% scale. Closed meshes do not prove process accuracy, material strength, skin-contact suitability or electrical safety.

## Parts and print setup

| Part / quantity | Initial print orientation and process |
|---|---|
| Front frame /1 | Tough SLA/MSLA or comparable detail service; tilt 25–40°, support hidden inner/rear surfaces, protect cosmetic rim and small openings. |
| Rear cup /1 | Tough SLA/MSLA, tilt 25–40° with cavity open; support bail as needed. Keep PCB shelves, clips and fastener bores clean. |
| Record face /1 | Tough opaque resin; supplied face-down atZ0, stem/tabs up. Use a sacrificial support arrangement if direct-bed peel distorts it; tilted printing may improve flatness but needs cosmetic finishing. |
| Privacy slider /1 | Tough resin; flat inner face toward bed and exterior face up in export. Only the exterior part is provided; internal switch coupling remains engineering. |
| Top retainer /1 | Tough dimensionally stable polymer, head atZ0 and shank up. Brittle decorative resin is unsuitable for press-fit retention. |
| Contact carrier /1 | Tough insulating polymer; flat outer face atZ0. Inspect the 0.7 mm body for warp and preserve lead-hole insulation. |
| Fit coupon /1 | Same resin, exposure/cure and orientation class as small features. Print flat and measure after full cure. |
| Passive dock jig /1 | PETG or tough resin, flat bottom.28.5×48.5 pocket gives 0.25 mm side allowance. Contact guides are nominalØ1.4 and must match selected pins. |

Use qualified printer exposure and cure settings;25–50µm resin layers are an initial resolution target. Measure actual XY accuracy. Ordinary 0.4 mm-nozzle FDM is a poor match for 0.3 mm tabs,0.2 mm face gaps,0.62 mm LED opening and 0.96 mm pilots. The passive dock may be printed by FDM separately. Compensate individual dimensions in source rather than scaling the whole assembly to fix a hole.

Nominal walls: face 0.9 mm, rear 1.0 mm, straight sides 1.2 mm. Retaining tabs and clip lips are 0.3 mm prototype features; they may need thickening for the chosen process. The 0.11 mm seam and 0.20 mm paddle gap must remain free after cure/finish. No process-specific tolerance validation has been done.

Coupon datum is the lower-left notch. Top row bores, left-to-right:Ø0.90,0.96,1.02,1.36,2.04. Lower row:7 mm-long slots of widths 1.4,1.6,1.8. Use pin gauges and fit trials; do not force a retainer into a shrunken pilot.

## Mechanical BOM

| Item | Provisional specification |
|---|---|
| Printed parts | One of each eight STLs; coupon is a process aid. |
| Lower case screw | One M1.2-class micro screw, approximately 6 mm under-head length. Select exact pitch/head/profile; head must fitØ2.04 seat. Check engagement and avoid bottoming out. |
| Upper polymer retainer | Supplied printable geometry; approximatelyØ1.0 gripping shank inØ0.96 pilot is an intentional 0.04 mm diametral interference trial. Tune on coupon. |
| Face return gasket | Custom compliant nonconductive gasket, modeled 0.47 mm height. Durometer, preload and compression remain unqualified. |
| Seam gasket |0.08 mm visual reference; select a film/adhesive or redesign a molded seal. No IP rating. |
| Microphone boots /2; lightpipe /1 | Custom compliant sealed interfaces; Blender routing curves are only proxies. |
| Cell insulation |0.05 mm film; fixation must not constrain cell swelling. |
| Haptic carrier |0.05 mm insulating adhesive underØ8.1 motor; validate vibration coupling. |
| Protected cell |150 mAh target; provisional 20.5×28×3.3 allowance, not a qualified cell part. |
| Rear contacts /3 |Ø1.7 visible contact area at 3 mm pitch; actual contact/tail, travel and current rating unresolved. |
| Chain and breakaway | Render uses~0.46 mm wire links. Select a tested wearable breakaway and validate RF. |
| Finish | Fully cured, suitable skin-contact material; nonconductive silver frame and polished black face. Qualification pending. |

## Assembly and checks

1. Wash, cure, deburr and measure empty prints. Verify body 28×48×10, flatness, intact tabs, free face motion and shell mating. Remove supports without unpredictably enlarging gaps.
2. Insert the face from behind the frame. Tabs capture under the ledge; check target 0.35 inward travel against all four stops. Fit the selected return gasket and verify off-axis presses cannot reach components.
3. Start with a nonpowered dummy PCB and cell gauge. PCB24×42×0.8R10 sits on four shelves; clip underside is 0.15 above board top. Check flex/insertion forces without bending a populated board.
4. Fit contact carrier atY−19 below the cell, then select/terminate real contacts and validate polarity/insulation against hardware documentation. The passive dock contains no power electronics.
5. Install qualified cell fixation, insulation, board, haptic film, acoustic boots, lightpipe and engineered privacy linkage. Keep cell/PCM/leads clear of screws, clips and contact tails. KeepY>11.95 free of conductive material near antenna.
6. Close the rear cup with polymer upper retainer and selected lower screw at low torque. Stop if force is needed or the cell becomes a structural spacer. Verify remaining space against supplier swelling limits.
7. Qualify an instrumented test unit for switch feel, recording indication, true mic disconnect, acoustics, thermal shutdown/charge behavior, drop/chain loads and worn RF before treating it as a wearable product.

`assembly-audit.json` reports nominal digital checks only. A physical assembled prototype has not been printed or tested. Battery capacity, control behavior and sealing remain design targets until qualified.

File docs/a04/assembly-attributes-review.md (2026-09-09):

# A04 assembly attributes review

Read-only native audit, 2026-09-09. **Seven references need assembly-attribute corrections before manufacturing exports:** D2/C3/C4 lack the footprint-level SMD classification, and J1–J4 copper contact features remain included in BOM/position intent. The current design has **72 assigned PCB references, comprising 68 purchased PCB components and four copper-contact features**. It is not ready for an assembly release.

[The reproducible audit](audit-assembly-attributes.py) reads the candidate 2 netlist, all seven native schematic files, the actual assigned footprint files and the native board. KiCad `pcbnew` 10.0.4 parses the 25 assigned footprint definitions and board; a structural S-expression parser distinguishes schematic instances from cached library symbols. [The JSON evidence](assembly-attributes-verification.json) records each reference, definition, native flags and SHA256 identities. All 38 recorded source files remained unchanged during execution. The script writes only that JSON; its successful exit means the audit completed consistently, not that the attribute policy passed. `assembly_attribute_policy_pass` is **false**.

| References | Actual native footprint attributes | Native paste geometry | Assembly implication |
|---|---|---|---|
| D2 — `AuraA04:TI_DYA0002A_TPD1E10B06` | `0`: neither SMD nor through-hole; no position/BOM exclusions | Two front-paste pads | Purchased SMD diode can be omitted by the SMD-only placement filter |
| C3, C4 — `AuraVerified:AURA_SiCap_1.2x0.7mm_P0.7mm` | `0`: neither SMD nor through-hole; no position/BOM exclusions | Two front-paste pads per definition | Purchased silicon capacitors can be omitted by the same filter |
| J1, J2, J3, J4 — DockContacts, BatteryPads, SWDPads, MotorPads | `0`; no position/BOM exclusions | No paste pads or paste graphics | Unfiltered component lists can include four fictitious connector purchases/placements |
| Remaining 65 purchased references / 19 definitions | `2`: `FP_SMD` set | Recorded per definition in JSON | SMD classification is present; this is not an orientation or process qualification |

Pad-level `smd` geometry does not set the footprint-level `FP_SMD` bit. KiCad's SMD-only position filter uses the footprint fabrication attribute, while the position exclusion flag suppresses a footprint independently. This makes omission of D2/C3/C4 a prediction **if these library attributes reach placed board instances**, not a verified CPL export result. [KiCad 10 PCB Editor manual, component placement files](https://docs.kicad.org/10.0/en/pcbnew/pcbnew.pdf)

All 72 native schematic instances explicitly have `in_bom=yes`, `on_board=yes`, `in_pos_files=yes`, `dnp=no`. J1–J4's library and cached symbols say `in_bom=no`, but their placed schematic instances override that intent to `yes`. Those four references must retain their PCB copper and `on_board=yes`, while component BOM and position exclusions must be made explicit and preserved through schematic-to-board synchronization. Their labels describe lands, not four procured connectors. The actual motor, protected battery pack, mating dock and programming-fixture hardware require separate product/fixture BOM accounting.

The native board still contains **zero footprints** and has **1.6 mm thickness**. No placement file or BOM was exported or inspected by this audit; no placement, side, rotation, stackup, solder-process, electrical or enclosure-fit approval follows. `AuraA04:Nidec_CUS22TB_Candidate` is **unassigned and excluded from the 72-reference count**, with its own [separate candidate review](cus22-candidate-review.md).

The exposed MCP schemas provide a supported future board-instance correction: `set_footprint_type` accepts a placed PCB reference, `type` (`smd`, `through_hole` or `unspecified`), and optional `exclude_from_bom` and `exclude_from_pos_files`. The separate `create_footprint` and `edit_footprint_pad` schemas do not expose a **library footprint-level** attribute setter. This audit only inspected those tool descriptions; it made no MCP calls or CAD edits. Native library correction therefore remains a separate capability question; direct file patching is not a substitute in this workflow.

After the 72 references are placed through the authorized native workflow, set/read back D2/C3/C4 as SMD and J1–J4 as excluded from component BOM/position files while retaining their copper features. Verify the saved board instances after schematic synchronization and library refresh. Then compare actual BOM and CPL reference sets against the intended **68 purchased PCB references**; confirm D2/C3/C4 are present, J1–J4 absent, and all expected quantities, sides, rotations and origins match the assembler's requirements. This must use real exported files, not the current library-derived count.

To reproduce from the repository root in PowerShell:

```powershell
& 'C:/Program Files/KiCad/10.0/bin/python.exe' 'docs/a04/audit-assembly-attributes.py'
```

The optional `--stock-library-root` accepts a different installed KiCad footprint directory. Repository source keys use relative slash paths; `kicad_stock/` keys are relative to the reported stock-library root. Actual footprint bytes are hashed, so another installation can identify any source differences before relying on the result.

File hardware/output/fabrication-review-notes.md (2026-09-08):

# AURA EVT-A03 fabrication review notes

Historical notes for the earlier placement/session package. The current connected native project, exports, stack and remaining assembly-review constraints are in [the native manufacturing guide](../native/README.md). The HOLD and routing status below describe the superseded pre-import snapshot.

**HOLD — engineering intent only. Do not submit the present placement board or standalone session for fabrication.** The session has not been imported into KiCad, copper completion and independent routed-board DRC are outstanding, and battery/RF/assembly qualification remains incomplete. The authoritative status is `aura-a03-routing-status.json` together with `kicad-a03-final-placement-drc.json` and `../../docs/hardware.md`.

## Board intent

| Feature | Authored intent / review requirement |
|---|---|
| Outline | 24 × 42 mm rounded rectangle, R10 corners; no mounting holes |
| Thickness | 0.80 mm finished target; fabricator tolerance and complete enclosure stack must be approved together |
| Copper layers | F.Cu, In1.Cu, In2.Cu, B.Cu; layer functions and continuous return planes are not yet released |
| Smallest routing rule | 0.15 mm track width, 0.12 mm clearance; power widths and thermal paths still require review |
| Through via | 0.45 mm diameter / 0.20 mm drill routing intent; manufacturing drill/plating capability must be approved |
| Board-edge clearance | 0.30 mm minimum intent |
| RF exclusion | No copper on any layer above Y11.95 to the board top Y21; inspect module ground-pad boundary at Y11.95 |
| Contact finish | ENIG candidate on J1 rear contacts; actual contact mating material, wear and skin/environmental exposure are unqualified |
| Acoustic holes | Two Ø0.50 mm NPTH at (−8.5, 8.5) and (8.5, 8.5); no solder, paste, adhesive or cleaning residue may obstruct them |
| NAND exposed pad | Correct ZE 8 × 6 mm WSON, 3.4 × 4.3 mm exposed pad on GND; no exposed vias under the pad |

A fabricator-approved four-layer stackup, copper weights, material, surface finish thickness, soldermask registration, finished-hole tolerance, impedance/return-path strategy and panel tooling are not supplied as approved specifications. A numerical router clearance is not a supplier process qualification.

## Assembly review

`assembly-bom.csv` groups 57 candidate SMT references. `cpl-top.csv` gives their authored body-centre coordinates and rotations. J1–J4 are custom PCB features and intentionally excluded from SMT purchase/placement quantities. `external-bom.csv` lists the battery pack, attached NTC, motor and contact/dock qualification items separately.

The CPL coordinates use board centre (0,0), with positive Y toward the necklace loop. Before assembly, reconcile this convention and rotations against the released Gerber origin and the assembler's machine. Do not infer pin 1 from a body-centre rendering. Review IC, diode, LED, microphone, switch and SiCap orientations against exact manufacturer drawings.

C3/C4 Murata 939113424610-T3N silicon capacitors use an authored mask-defined footprint. Copper is 0.50 × 0.70 mm on 0.70 mm pitch, with intended 0.40 × 0.60 mm mask openings and 0.30 × 0.50 mm paste apertures. Check those dimensions in the eventual manufacturing outputs; approve stencil thickness and process with the assembler. Other nearby Class II capacitors still need the acoustic-placement review described in the hardware report.

The native microphone annular ground land and four paste arcs must be retained. The portable tscircuit ring approximation alone is not the final stencil geometry. Protect the bottom sound ports and qualify reflow, board cleaning, acoustic gasket adhesive and leak performance against the microphone documentation.

The cell candidate is a protected FPBattery/DNK302025 150 mAh pack, with a separate Semitec 103AT-2 NTC. The 20.5 × 28 × 3.3 mm enclosure allowance is an engineering allowance, not an approved assembled pack drawing. Supplier approval of maximum width/thickness/swelling, attached sensor/leads and 4.221 V worst-case charging voltage is required. Charging and haptics remain inhibited in the unqualified firmware build. Do not energize an assembled pack before the thermal and power review gates are completed.

## Required release contents

After resolving the current HOLD, generate and review Gerbers for all copper, soldermask, paste, legend and board-outline layers; separate PTH/NPTH drill outputs; the exact source revision and checksums; IPC netlist if supported; approved stackup and notes; assembly drawings; approved BOM and CPL; stencil files; and a clean independent imported-board connectivity/DRC report. No empty or placement-only copper exports are provided as a substitute for this release.

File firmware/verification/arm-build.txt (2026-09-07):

Loading Zephyr default modules (Zephyr base (cached)).
-- Application: F:/circuit/firmware
-- CMake version: 3.31.6
-- Cache files will be written to: F:/circuit/.tools/zephyr/zephyr/.cache
-- Zephyr version: 4.2.0 (F:/circuit/.tools/zephyr/zephyr)
-- Found west (found suitable version "1.4.0", minimum required is "0.14.0")
-- Board: aura_a03, qualifiers: nrf52840
-- Found host-tools: zephyr 0.17.2 (F:/circuit/.tools/zephyr/zephyr-sdk-0.17.2)
-- Found toolchain: zephyr 0.17.2 (F:/circuit/.tools/zephyr/zephyr-sdk-0.17.2)
-- Could NOT find Dtc (missing: DTC) (Required is at least version "1.4.6")
Hint: The project() command has not yet been called.  It sets up system-specific search paths.
-- Found BOARD.dts: F:/circuit/firmware/boards/aura/aura_a03/aura_a03.dts
-- Generated zephyr.dts: F:/circuit/.tools/zephyr/build-aura/zephyr/zephyr.dts
-- Generated pickled edt: F:/circuit/.tools/zephyr/build-aura/zephyr/edt.pickle
-- Generated devicetree_generated.h: F:/circuit/.tools/zephyr/build-aura/zephyr/include/generated/zephyr/devicetree_generated.h
Parsing F:/circuit/firmware/Kconfig
Loaded configuration 'F:/circuit/.tools/zephyr/build-aura/zephyr/.config'
No change to configuration in 'F:/circuit/.tools/zephyr/build-aura/zephyr/.config'
No change to Kconfig header in 'F:/circuit/.tools/zephyr/build-aura/zephyr/include/generated/zephyr/autoconf.h'
-- Found gen_kobject_list: F:/circuit/.tools/zephyr/zephyr/scripts/build/gen_kobject_list.py
CMake Warning at F:/circuit/.tools/zephyr/zephyr/CMakeLists.txt:2240 (message):
  __ASSERT() statements are globally ENABLED

-- Configuring done (81.1s)
-- Generating done (1.8s)
-- Build files have been written to: F:/circuit/.tools/zephyr/build-aura
[0/1] Re-running CMake...
[1/238] Generating misc/generated/syscalls.json, misc/generated/struct_tags.json
[2/232] Building C object zephyr/CMakeFiles/offsets.dir/arch/arm/core/offsets/offsets.c.obj
[3/232] Generating include/generated/zephyr/offsets.h
[4/232] Building C object zephyr/CMakeFiles/zephyr.dir/lib/os/printk.c.obj
[5/232] Building C object zephyr/CMakeFiles/zephyr.dir/lib/os/sem.c.obj
[6/232] Building C object zephyr/CMakeFiles/zephyr.dir/lib/os/thread_entry.c.obj
[7/232] Building C object CMakeFiles/app.dir/src/nand.c.obj
[8/232] Building C object zephyr/CMakeFiles/zephyr.dir/lib/os/clock.c.obj
[9/232] Building C object CMakeFiles/app.dir/src/protocol.c.obj
[10/232] Building C object zephyr/CMakeFiles/zephyr.dir/lib/heap/heap.c.obj
[11/232] Building C object zephyr/CMakeFiles/zephyr.dir/lib/os/cbprintf_packaged.c.obj
[12/232] Building C object zephyr/CMakeFiles/zephyr.dir/lib/os/cbprintf_complete.c.obj
[13/232] Building C object CMakeFiles/app.dir/src/main.c.obj
[14/232] Building C object zephyr/CMakeFiles/zephyr.dir/lib/os/poweroff.c.obj
[15/232] Building C object zephyr/CMakeFiles/zephyr.dir/lib/os/reboot.c.obj
[16/232] Building C object zephyr/CMakeFiles/zephyr.dir/lib/os/assert.c.obj
[17/232] Building C object zephyr/CMakeFiles/zephyr.dir/lib/utils/notify.c.obj
[18/232] Building C object zephyr/CMakeFiles/zephyr.dir/lib/utils/rb.c.obj
[19/232] Building C object zephyr/CMakeFiles/zephyr.dir/subsys/mem_mgmt/mem_attr.c.obj
[20/232] Linking C static library app\libapp.a
[21/232] Building C object zephyr/CMakeFiles/zephyr.dir/lib/utils/bitarray.c.obj
[22/232] Building C object zephyr/CMakeFiles/zephyr.dir/lib/utils/onoff.c.obj
[23/232] Building C object zephyr/CMakeFiles/zephyr.dir/subsys/storage/flash_map/flash_map.c.obj
[24/232] Building C object zephyr/CMakeFiles/zephyr.dir/subsys/storage/flash_map/flash_map_layout.c.obj
[25/232] Building C object zephyr/CMakeFiles/zephyr.dir/subsys/fs/nvs/nvs.c.obj
[26/232] Building C object zephyr/CMakeFiles/zephyr.dir/subsys/storage/flash_map/flash_map_default.c.obj
[27/232] Building C object zephyr/CMakeFiles/zephyr.dir/subsys/tracing/tracing_none.c.obj
[28/232] Building C object zephyr/CMakeFiles/zephyr.dir/subsys/settings/src/settings_store.c.obj
[29/232] Building C object zephyr/CMakeFiles/zephyr.dir/subsys/settings/src/settings_init.c.obj
[30/232] Building C object zephyr/CMakeFiles/zephyr.dir/subsys/settings/src/settings_line.c.obj
[31/232] Building C object zephyr/CMakeFiles/zephyr.dir/subsys/settings/src/settings.c.obj
[32/232] Building C object zephyr/arch/common/CMakeFiles/isr_tables.dir/isr_tables.c.obj
[33/232] Building C object zephyr/arch/common/CMakeFiles/arch__common.dir/sw_isr_common.c.obj
[34/232] Building C object zephyr/CMakeFiles/zephyr.dir/subsys/settings/src/settings_nvs.c.obj
[35/232] Building C object zephyr/CMakeFiles/zephyr.dir/drivers/flash/flash_util.c.obj
[36/232] Generating linker_zephyr_pre0.cmd
[37/232] Building C object zephyr/arch/arch/arm/core/CMakeFiles/arch__arm__core.dir/fatal.c.obj
[38/232] Building C object zephyr/arch/arch/arm/core/CMakeFiles/arch__arm__core.dir/nmi.c.obj
[39/232] Building C object zephyr/arch/arch/arm/core/cortex_m/CMakeFiles/arch__arm__core__cortex_m.dir/exc_exit.c.obj
[40/232] Building ASM object zephyr/arch/arch/arm/core/cortex_m/CMakeFiles/arch__arm__core__cortex_m.dir/reset.S.obj
[41/232] Linking C static library zephyr\arch\common\libisr_tables.a
[42/232] Building C object zephyr/arch/arch/arm/core/CMakeFiles/arch__arm__core.dir/tls.c.obj
[43/232] Building C object zephyr/arch/arch/arm/core/cortex_m/CMakeFiles/arch__arm__core__cortex_m.dir/fpu.c.obj
[44/232] Building C object zephyr/arch/arch/arm/core/cortex_m/CMakeFiles/arch__arm__core__cortex_m.dir/scb.c.obj
[45/232] Building C object zephyr/arch/arch/arm/core/cortex_m/CMakeFiles/arch__arm__core__cortex_m.dir/fault.c.obj
[46/232] Building C object zephyr/arch/arch/arm/core/cortex_m/CMakeFiles/arch__arm__core__cortex_m.dir/thread_abort.c.obj
[47/232] Linking C static library zephyr\libzephyr.a
[48/232] Building ASM object zephyr/arch/arch/arm/core/cortex_m/CMakeFiles/arch__arm__core__cortex_m.dir/swap_helper.S.obj
[49/232] Building C object zephyr/arch/arch/arm/core/cortex_m/CMakeFiles/arch__arm__core__cortex_m.dir/irq_manage.c.obj
[50/232] Linking C static library zephyr\arch\common\libarch__common.a
[51/232] Linking C static library zephyr\arch\arch\arm\core\libarch__arm__core.a
[52/232] Building C object zephyr/arch/arch/arm/core/cortex_m/CMakeFiles/arch__arm__core__cortex_m.dir/prep_c.c.obj
[53/232] Building C object zephyr/arch/arch/arm/core/cortex_m/CMakeFiles/arch__arm__core__cortex_m.dir/irq_init.c.obj
[54/232] Building C object zephyr/arch/arch/arm/core/cortex_m/CMakeFiles/arch__arm__core__cortex_m.dir/thread.c.obj
[55/232] Building C object zephyr/arch/arch/arm/core/cortex_m/CMakeFiles/arch__arm__core__cortex_m.dir/cpu_idle.c.obj
[56/232] Building C object zephyr/arch/arch/arm/core/cortex_m/CMakeFiles/arch__arm__core__cortex_m.dir/isr_wrapper.c.obj
[57/232] Building C object zephyr/arch/arch/arm/core/mpu/CMakeFiles/arch__arm__core__mpu.dir/arm_mpu_regions.c.obj
[58/232] Building C object zephyr/arch/arch/arm/core/mpu/CMakeFiles/arch__arm__core__mpu.dir/arm_core_mpu.c.obj
[59/232] Building C object zephyr/arch/arch/arm/core/mpu/CMakeFiles/arch__arm__core__mpu.dir/arm_mpu.c.obj
[60/232] Building C object zephyr/lib/libc/picolibc/CMakeFiles/lib__libc__picolibc.dir/cbprintf.c.obj
[61/232] Building C object zephyr/lib/libc/picolibc/CMakeFiles/lib__libc__picolibc.dir/assert.c.obj
[62/232] Building C object zephyr/lib/libc/picolibc/CMakeFiles/lib__libc__picolibc.dir/chk_fail.c.obj
[63/232] Building C object zephyr/lib/libc/picolibc/CMakeFiles/lib__libc__picolibc.dir/errno_wrap.c.obj
[64/232] Building C object zephyr/lib/libc/picolibc/CMakeFiles/lib__libc__picolibc.dir/exit.c.obj
[65/232] Building C object zephyr/lib/libc/picolibc/CMakeFiles/lib__libc__picolibc.dir/locks.c.obj
[66/232] Building C object zephyr/lib/libc/common/CMakeFiles/lib__libc__common.dir/source/stdlib/abort.c.obj
[67/232] Building C object zephyr/lib/libc/picolibc/CMakeFiles/lib__libc__picolibc.dir/stdio.c.obj
[68/232] Linking C static library zephyr\arch\arch\arm\core\cortex_m\libarch__arm__core__cortex_m.a
[69/232] Building C object zephyr/lib/libc/common/CMakeFiles/lib__libc__common.dir/source/stdlib/malloc.c.obj
[70/232] Linking C static library zephyr\arch\arch\arm\core\mpu\libarch__arm__core__mpu.a
[71/232] Building C object zephyr/soc/soc/nrf52840/CMakeFiles/soc__nordic.dir/validate_base_addresses.c.obj
[72/232] Building C object zephyr/soc/soc/nrf52840/CMakeFiles/soc__nordic.dir/validate_enabled_instances.c.obj
[73/232] Building C object zephyr/soc/soc/nrf52840/CMakeFiles/soc__nordic.dir/nrf52/soc.c.obj
[74/232] Building C object zephyr/lib/net_buf/CMakeFiles/lib__net_buf.dir/buf.c.obj
[75/232] Building C object zephyr/soc/soc/nrf52840/CMakeFiles/soc__nordic.dir/common/reboot.c.obj
[76/232] Building C object zephyr/soc/soc/nrf52840/CMakeFiles/soc__nordic.dir/common/poweroff.c.obj
[77/232] Building C object zephyr/lib/net_buf/CMakeFiles/lib__net_buf.dir/buf_simple.c.obj
[78/232] Linking C static library zephyr\lib\libc\picolibc\liblib__libc__picolibc.a
[79/232] Linking C static library zephyr\lib\libc\common\liblib__libc__common.a
[80/232] Building C object zephyr/subsys/random/CMakeFiles/subsys__random.dir/random_entropy_device.c.obj
[81/232] Building C object zephyr/subsys/bluetooth/common/CMakeFiles/subsys__bluetooth__common.dir/dummy.c.obj
[82/232] Building C object zephyr/subsys/bluetooth/common/CMakeFiles/subsys__bluetooth__common.dir/bt_str.c.obj
[83/232] Building C object zephyr/subsys/bluetooth/common/CMakeFiles/subsys__bluetooth__common.dir/rpa.c.obj
[84/232] Linking C static library zephyr\soc\soc\nrf52840\libsoc__nordic.a
[85/232] Building C object zephyr/subsys/bluetooth/host/CMakeFiles/subsys__bluetooth__host.dir/long_wq.c.obj
[86/232] Linking C static library zephyr\lib\net_buf\liblib__net_buf.a
[87/232] Building C object zephyr/subsys/bluetooth/host/CMakeFiles/subsys__bluetooth__host.dir/buf.c.obj
[88/232] Building C object zephyr/subsys/bluetooth/host/CMakeFiles/subsys__bluetooth__host.dir/settings.c.obj
[89/232] Linking C static library zephyr\subsys\random\libsubsys__random.a
[90/232] Building C object zephyr/subsys/bluetooth/host/CMakeFiles/subsys__bluetooth__host.dir/data.c.obj
[91/232] Building C object zephyr/subsys/bluetooth/host/CMakeFiles/subsys__bluetooth__host.dir/hci_common.c.obj
[92/232] Linking C static library zephyr\subsys\bluetooth\common\libsubsys__bluetooth__common.a
[93/232] Building C object zephyr/subsys/bluetooth/host/CMakeFiles/subsys__bluetooth__host.dir/ecc.c.obj
[94/232] Building C object zephyr/subsys/bluetooth/host/CMakeFiles/subsys__bluetooth__host.dir/adv.c.obj
[95/232] Building C object zephyr/subsys/bluetooth/host/CMakeFiles/subsys__bluetooth__host.dir/hci_core.c.obj
[96/232] Building C object zephyr/subsys/bluetooth/host/CMakeFiles/subsys__bluetooth__host.dir/id.c.obj
[97/232] Building C object zephyr/subsys/bluetooth/host/CMakeFiles/subsys__bluetooth__host.dir/l2cap.c.obj
[98/232] Building C object zephyr/subsys/bluetooth/host/CMakeFiles/subsys__bluetooth__host.dir/conn.c.obj
[99/232] Building C object zephyr/subsys/bluetooth/host/CMakeFiles/subsys__bluetooth__host.dir/keys.c.obj
[100/232] Building C object zephyr/subsys/bluetooth/crypto/CMakeFiles/subsys__bluetooth__crypto.dir/bt_crypto_psa.c.obj
[101/232] Building C object zephyr/subsys/bluetooth/host/CMakeFiles/subsys__bluetooth__host.dir/att.c.obj
[102/232] Building C object zephyr/subsys/bluetooth/controller/CMakeFiles/subsys__bluetooth__controller.dir/util/memq.c.obj
[103/232] Building C object zephyr/subsys/bluetooth/crypto/CMakeFiles/subsys__bluetooth__crypto.dir/bt_crypto.c.obj
[104/232] Building C object zephyr/subsys/bluetooth/controller/CMakeFiles/subsys__bluetooth__controller.dir/util/dbuf.c.obj
[105/232] Building C object zephyr/subsys/bluetooth/controller/CMakeFiles/subsys__bluetooth__controller.dir/util/mayfly.c.obj
[106/232] Building C object zephyr/subsys/bluetooth/controller/CMakeFiles/subsys__bluetooth__controller.dir/util/util.c.obj
[107/232] Building C object zephyr/subsys/bluetooth/host/CMakeFiles/subsys__bluetooth__host.dir/smp.c.obj
[108/232] Building C object zephyr/subsys/bluetooth/controller/CMakeFiles/subsys__bluetooth__controller.dir/ll_sw/ll_feat.c.obj
[109/232] Building C object zephyr/subsys/bluetooth/controller/CMakeFiles/subsys__bluetooth__controller.dir/ll_sw/ll_addr.c.obj
[110/232] Linking C static library zephyr\subsys\bluetooth\crypto\libsubsys__bluetooth__crypto.a
[111/232] Building C object zephyr/subsys/bluetooth/controller/CMakeFiles/subsys__bluetooth__controller.dir/ll_sw/lll_common.c.obj
[112/232] Building C object zephyr/subsys/bluetooth/controller/CMakeFiles/subsys__bluetooth__controller.dir/ll_sw/ll_tx_pwr.c.obj
[113/232] Building C object zephyr/subsys/bluetooth/host/CMakeFiles/subsys__bluetooth__host.dir/gatt.c.obj
[114/232] Building C object zephyr/subsys/bluetooth/controller/CMakeFiles/subsys__bluetooth__controller.dir/ll_sw/ull.c.obj
[115/232] Building C object zephyr/subsys/bluetooth/controller/CMakeFiles/subsys__bluetooth__controller.dir/ticker/ticker.c.obj
[116/232] Building C object zephyr/subsys/bluetooth/controller/CMakeFiles/subsys__bluetooth__controller.dir/hci/hci_driver.c.obj
[117/232] Building C object zephyr/subsys/bluetooth/controller/CMakeFiles/subsys__bluetooth__controller.dir/ll_sw/ull_llcp_enc.c.obj
[118/232] Linking C static library zephyr\subsys\bluetooth\host\libsubsys__bluetooth__host.a
[119/232] Building C object zephyr/subsys/bluetooth/controller/CMakeFiles/subsys__bluetooth__controller.dir/ll_sw/ull_llcp_phy.c.obj
[120/232] Building C object zephyr/subsys/bluetooth/controller/CMakeFiles/subsys__bluetooth__controller.dir/ll_sw/ull_adv.c.obj
[121/232] Building C object zephyr/subsys/bluetooth/controller/CMakeFiles/subsys__bluetooth__controller.dir/ll_sw/ull_llcp.c.obj
[122/232] Building C object zephyr/subsys/bluetooth/controller/CMakeFiles/subsys__bluetooth__controller.dir/ll_sw/ull_conn.c.obj
[123/232] Building C object zephyr/subsys/bluetooth/controller/CMakeFiles/subsys__bluetooth__controller.dir/hci/hci.c.obj
[124/232] Building C object zephyr/subsys/bluetooth/controller/CMakeFiles/subsys__bluetooth__controller.dir/ll_sw/ull_llcp_common.c.obj
[125/232] Building C object zephyr/subsys/bluetooth/controller/CMakeFiles/subsys__bluetooth__controller.dir/ll_sw/ull_llcp_pdu.c.obj
[126/232] Building C object zephyr/subsys/bluetooth/controller/CMakeFiles/subsys__bluetooth__controller.dir/ll_sw/ull_llcp_local.c.obj
[127/232] Building C object zephyr/subsys/bluetooth/controller/CMakeFiles/subsys__bluetooth__controller.dir/ll_sw/ull_llcp_conn_upd.c.obj
[128/232] Building C object zephyr/subsys/bluetooth/controller/CMakeFiles/subsys__bluetooth__controller.dir/crypto/crypto.c.obj
[129/232] Building C object zephyr/subsys/bluetooth/controller/CMakeFiles/subsys__bluetooth__controller.dir/ll_sw/ull_llcp_chmu.c.obj
[130/232] Building C object zephyr/subsys/bluetooth/controller/CMakeFiles/subsys__bluetooth__controller.dir/ll_sw/lll_chan.c.obj
[131/232] Building C object zephyr/subsys/bluetooth/controller/CMakeFiles/subsys__bluetooth__controller.dir/ll_sw/ull_llcp_remote.c.obj
[132/232] Building C object zephyr/subsys/bluetooth/controller/CMakeFiles/subsys__bluetooth__controller.dir/ll_sw/ull_peripheral.c.obj
[133/232] Building C object zephyr/subsys/bluetooth/controller/CMakeFiles/subsys__bluetooth__controller.dir/flash/soc_flash_nrf_ticker.c.obj
[134/232] Building C object zephyr/subsys/bluetooth/controller/ll_sw/nordic/CMakeFiles/subsys__bluetooth__controller__ll_sw__nordic.dir/lll/lll_clock.c.obj
[135/232] Building C object zephyr/subsys/bluetooth/controller/CMakeFiles/subsys__bluetooth__controller.dir/ll_sw/ull_filter.c.obj
[136/232] Building C object zephyr/subsys/bluetooth/controller/ll_sw/nordic/CMakeFiles/subsys__bluetooth__controller__ll_sw__nordic.dir/lll/lll.c.obj
[137/232] Building C object zephyr/subsys/bluetooth/controller/ll_sw/nordic/CMakeFiles/subsys__bluetooth__controller__ll_sw__nordic.dir/lll/lll_peripheral.c.obj
[138/232] Building C object zephyr/subsys/bluetooth/controller/ll_sw/nordic/CMakeFiles/subsys__bluetooth__controller__ll_sw__nordic.dir/hal/nrf5/cntr.c.obj
[139/232] Building C object zephyr/subsys/bluetooth/controller/ll_sw/nordic/CMakeFiles/subsys__bluetooth__controller__ll_sw__nordic.dir/lll/lll_adv.c.obj
[140/232] Building C object zephyr/subsys/bluetooth/controller/ll_sw/nordic/CMakeFiles/subsys__bluetooth__controller__ll_sw__nordic.dir/hci/hci_vendor.c.obj
[141/232] Building C object zephyr/subsys/bluetooth/controller/ll_sw/nordic/CMakeFiles/subsys__bluetooth__controller__ll_sw__nordic.dir/hal/nrf5/mayfly.c.obj
[142/232] Building C object zephyr/subsys/bluetooth/controller/ll_sw/nordic/CMakeFiles/subsys__bluetooth__controller__ll_sw__nordic.dir/lll/lll_conn.c.obj
[143/232] Building C object zephyr/subsys/bluetooth/controller/ll_sw/nordic/CMakeFiles/subsys__bluetooth__controller__ll_sw__nordic.dir/hal/nrf5/ticker.c.obj
[144/232] Building C object zephyr/subsys/bluetooth/controller/ll_sw/nordic/CMakeFiles/subsys__bluetooth__controller__ll_sw__nordic.dir/hal/nrf5/ecb.c.obj
[145/232] Linking C static library zephyr\subsys\bluetooth\controller\libsubsys__bluetooth__controller.a
[146/232] Building C object zephyr/drivers/flash/CMakeFiles/drivers__flash.dir/flash_page_layout.c.obj
[147/232] Building C object zephyr/drivers/entropy/CMakeFiles/drivers__entropy.dir/entropy_nrf5.c.obj
[148/232] Building C object zephyr/drivers/clock_control/CMakeFiles/drivers__clock_control.dir/nrf_clock_calibration.c.obj
[149/232] Building C object zephyr/drivers/clock_control/CMakeFiles/drivers__clock_control.dir/clock_control_nrf.c.obj
[150/232] Building C object zephyr/subsys/bluetooth/controller/ll_sw/nordic/CMakeFiles/subsys__bluetooth__controller__ll_sw__nordic.dir/hal/nrf5/radio/radio.c.obj
[151/232] Building C object zephyr/drivers/audio/CMakeFiles/drivers__audio.dir/dmic_nrfx_pdm.c.obj
[152/232] Building C object zephyr/drivers/flash/CMakeFiles/drivers__flash.dir/soc_flash_nrf.c.obj
[153/232] Building C object zephyr/drivers/hwinfo/CMakeFiles/drivers__hwinfo.dir/hwinfo_weak_impl.c.obj
[154/232] Building C object zephyr/drivers/i2c/CMakeFiles/drivers__i2c.dir/i2c_common.c.obj
[155/232] Building C object zephyr/drivers/hwinfo/CMakeFiles/drivers__hwinfo.dir/hwinfo_nrf.c.obj
[156/232] Linking C static library zephyr\drivers\entropy\libdrivers__entropy.a
[157/232] Linking C static library zephyr\drivers\clock_control\libdrivers__clock_control.a
[158/232] Building C object zephyr/drivers/i2c/CMakeFiles/drivers__i2c.dir/i2c_nrfx_twim.c.obj
[159/232] Building C object zephyr/drivers/gpio/CMakeFiles/drivers__gpio.dir/gpio_nrfx.c.obj
[160/232] Building C object zephyr/drivers/pinctrl/CMakeFiles/drivers__pinctrl.dir/common.c.obj
[161/232] Linking C static library zephyr\subsys\bluetooth\controller\ll_sw\nordic\libsubsys__bluetooth__controller__ll_sw__nordic.a
[162/232] Linking C static library zephyr\drivers\flash\libdrivers__flash.a
[163/232] Linking C static library zephyr\drivers\audio\libdrivers__audio.a
[164/232] Linking C static library zephyr\drivers\hwinfo\libdrivers__hwinfo.a
[165/232] Building C object zephyr/drivers/i2c/CMakeFiles/drivers__i2c.dir/i2c_nrfx_twim_common.c.obj
[166/232] Building C object zephyr/drivers/pinctrl/CMakeFiles/drivers__pinctrl.dir/pinctrl_nrf.c.obj
[167/232] Building C object zephyr/drivers/timer/CMakeFiles/drivers__timer.dir/sys_clock_init.c.obj
[168/232] Building C object zephyr/drivers/sensor/nordic/temp/CMakeFiles/drivers__sensor__nordic__temp.dir/temp_nrf5.c.obj
[169/232] Linking C static library zephyr\drivers\gpio\libdrivers__gpio.a
[170/232] Building C object zephyr/drivers/timer/CMakeFiles/drivers__timer.dir/nrf_rtc_timer.c.obj
[171/232] Building C object modules/hal_nordic/nrfx/CMakeFiles/modules__hal_nordic__nrfx.dir/F_/circuit/.tools/zephyr/modules/hal/nordic/nrfx/mdk/system_nrf52840.c.obj
[172/232] Building C object zephyr/drivers/watchdog/CMakeFiles/drivers__watchdog.dir/wdt_nrfx.c.obj
[173/232] Building C object zephyr/drivers/spi/CMakeFiles/drivers__spi.dir/spi_nrfx_common.c.obj
[174/232] Linking C static library zephyr\drivers\i2c\libdrivers__i2c.a
[175/232] Linking C static library zephyr\drivers\sensor\nordic\temp\libdrivers__sensor__nordic__temp.a
[176/232] Building C object modules/hal_nordic/nrfx/CMakeFiles/modules__hal_nordic__nrfx.dir/nrfx_glue.c.obj
[177/232] Linking C static library zephyr\drivers\pinctrl\libdrivers__pinctrl.a
[178/232] Building C object modules/hal_nordic/nrfx/CMakeFiles/modules__hal_nordic__nrfx.dir/F_/circuit/.tools/zephyr/modules/hal/nordic/nrfx/helpers/nrfx_flag32_allocator.c.obj
[179/232] Linking C static library zephyr\drivers\timer\libdrivers__timer.a
[180/232] Linking C static library zephyr\drivers\watchdog\libdrivers__watchdog.a
[181/232] Building C object modules/hal_nordic/nrfx/CMakeFiles/modules__hal_nordic__nrfx.dir/F_/circuit/.tools/zephyr/modules/hal/nordic/nrfx/helpers/nrfx_ram_ctrl.c.obj
[182/232] Building C object modules/hal_nordic/nrfx/CMakeFiles/modules__hal_nordic__nrfx.dir/F_/circuit/.tools/zephyr/modules/hal/nordic/nrfx/drivers/src/nrfx_clock.c.obj
[183/232] Building C object modules/hal_nordic/nrfx/CMakeFiles/modules__hal_nordic__nrfx.dir/F_/circuit/.tools/zephyr/modules/hal/nordic/nrfx/drivers/src/nrfx_nvmc.c.obj
[184/232] Building C object modules/hal_nordic/nrfx/CMakeFiles/modules__hal_nordic__nrfx.dir/F_/circuit/.tools/zephyr/modules/hal/nordic/nrfx/drivers/src/nrfx_wdt.c.obj
[185/232] Building C object modules/hal_nordic/nrfx/CMakeFiles/modules__hal_nordic__nrfx.dir/F_/circuit/.tools/zephyr/modules/hal/nordic/nrfx/drivers/src/nrfx_spim.c.obj
[186/232] Building C object modules/hal_nordic/nrfx/CMakeFiles/modules__hal_nordic__nrfx.dir/F_/circuit/.tools/zephyr/modules/hal/nordic/nrfx/drivers/src/nrfx_pdm.c.obj
[187/232] Building C object modules/mbedtls/CMakeFiles/mbedTLSBase.dir/zephyr_init.c.obj
[188/232] Building C object modules/hal_nordic/nrfx/CMakeFiles/modules__hal_nordic__nrfx.dir/F_/circuit/.tools/zephyr/modules/hal/nordic/nrfx/drivers/src/nrfx_twi_twim.c.obj
[189/232] Building C object zephyr/drivers/spi/CMakeFiles/drivers__spi.dir/spi_nrfx_spim.c.obj
[190/232] Building C object zephyr/kernel/CMakeFiles/kernel.dir/main_weak.c.obj
[191/232] Building C object modules/mbedtls/CMakeFiles/mbedTLSBase.dir/zephyr_entropy.c.obj
[192/232] Building C object modules/hal_nordic/nrfx/CMakeFiles/modules__hal_nordic__nrfx.dir/F_/circuit/.tools/zephyr/modules/hal/nordic/nrfx/drivers/src/nrfx_twim.c.obj
[193/232] Building C object zephyr/kernel/CMakeFiles/kernel.dir/banner.c.obj
[194/232] Building C object zephyr/kernel/CMakeFiles/kernel.dir/device.c.obj
[195/232] Building C object zephyr/kernel/CMakeFiles/kernel.dir/busy_wait.c.obj
[196/232] Building C object zephyr/kernel/CMakeFiles/kernel.dir/errno.c.obj
[197/232] Building C object modules/hal_nordic/nrfx/CMakeFiles/modules__hal_nordic__nrfx.dir/F_/circuit/.tools/zephyr/modules/hal/nordic/nrfx/drivers/src/nrfx_gpiote.c.obj
[198/232] Linking C static library zephyr\drivers\spi\libdrivers__spi.a
[199/232] Building C object zephyr/kernel/CMakeFiles/kernel.dir/fatal.c.obj
[200/232] Building C object zephyr/kernel/CMakeFiles/kernel.dir/init.c.obj
[201/232] Linking C static library modules\mbedtls\libmbedTLSBase.a
[202/232] Building C object zephyr/kernel/CMakeFiles/kernel.dir/idle.c.obj
[203/232] Building C object zephyr/kernel/CMakeFiles/kernel.dir/float.c.obj
[204/232] Building C object zephyr/kernel/CMakeFiles/kernel.dir/mem_slab.c.obj
[205/232] Building C object zephyr/kernel/CMakeFiles/kernel.dir/kheap.c.obj
[206/232] Building C object zephyr/kernel/CMakeFiles/kernel.dir/mailbox.c.obj
[207/232] Linking C static library modules\hal_nordic\nrfx\libmodules__hal_nordic__nrfx.a
[208/232] Building C object zephyr/kernel/CMakeFiles/kernel.dir/queue.c.obj
[209/232] Building C object zephyr/kernel/CMakeFiles/kernel.dir/msg_q.c.obj
[210/232] Building C object zephyr/kernel/CMakeFiles/kernel.dir/mutex.c.obj
[211/232] Building C object zephyr/kernel/CMakeFiles/kernel.dir/system_work_q.c.obj
[212/232] Building C object zephyr/kernel/CMakeFiles/kernel.dir/sem.c.obj
[213/232] Building C object zephyr/kernel/CMakeFiles/kernel.dir/stack.c.obj
[214/232] Building C object zephyr/kernel/CMakeFiles/kernel.dir/condvar.c.obj
[215/232] Building C object zephyr/kernel/CMakeFiles/kernel.dir/spinlock_validate.c.obj
[216/232] Building C object zephyr/kernel/CMakeFiles/kernel.dir/thread.c.obj
[217/232] Building C object zephyr/kernel/CMakeFiles/kernel.dir/xip.c.obj
[218/232] Building C object zephyr/kernel/CMakeFiles/kernel.dir/timeslicing.c.obj
[219/232] Building C object zephyr/kernel/CMakeFiles/kernel.dir/pipe.c.obj
[220/232] Building C object zephyr/kernel/CMakeFiles/kernel.dir/work.c.obj
[221/232] Building C object zephyr/kernel/CMakeFiles/kernel.dir/sched.c.obj
[222/232] Building C object zephyr/kernel/CMakeFiles/kernel.dir/timeout.c.obj
[223/232] Building C object zephyr/kernel/CMakeFiles/kernel.dir/mempool.c.obj
[224/232] Building C object zephyr/kernel/CMakeFiles/kernel.dir/dynamic_disabled.c.obj
[225/232] Building C object zephyr/kernel/CMakeFiles/kernel.dir/poll.c.obj
[226/232] Building C object zephyr/kernel/CMakeFiles/kernel.dir/timer.c.obj
[227/232] Linking C static library zephyr\kernel\libkernel.a
[228/232] Linking C executable zephyr\zephyr_pre0.elf
[229/232] Generating linker.cmd
[230/232] Generating isr_tables.c, isr_tables_vt.ld, isr_tables_swi.ld
[231/232] Building C object zephyr/CMakeFiles/zephyr_final.dir/isr_tables.c.obj
[232/232] Linking C executable zephyr\zephyr.elf
Memory region         Used Size  Region Size  %age Used
           FLASH:      219108 B       992 KB     21.57%
             RAM:       83452 B       256 KB     31.83%
        IDT_LIST:          0 GB        32 KB      0.00%
Generating files from F:/circuit/.tools/zephyr/build-aura/zephyr/zephyr.elf for board: aura_a03
{
  "revision": "A03",
  "status": "ARM-built engineering firmware; not bench validated",
  "zephyr": "v4.2.0",
  "zephyr_commit": "413b789deb391d3a37d06b463288a5fe765ee57e",
  "sdk": "0.17.2",
  "target": "aura_a03/nrf52840",
  "charging_enabled": false,
  "haptics_enabled": false,
  "source_sha256": "f44413b52d016c7da7478ea33288dd66d249a48c7aa6e394ef470873895e77ce",
  "files": {
    "aura-a03.bin": {
      "bytes": 219108,
      "sha256": "cf3b32c688537ce48575260b3c993c980eae5410aef9a080df693749f4b707cf"
    },
    "aura-a03.elf": {
      "bytes": 3993676,
      "sha256": "3d52c3f219cad8a8c8bcc179b4cc4e736866a49ea54467e29ac3f7cf49ab409b"
    },
    "aura-a03.hex": {
      "bytes": 616429,
      "sha256": "94a72d7d68decde347c0619d4564a80548defff8fb68da6ce57a53e4a12192f8"
    },
    "aura-a03.map": {
      "bytes": 1214117,
      "sha256": "956d46fced1feb34baf7d464e4b6af534965a1dfbc33fe34b28f3677d9263a41"
    },
    "build.config": {
      "bytes": 55180,
      "sha256": "e093f31f9de70fe385ecf37da48d861c5d7372dafe32f45cb3fb3778b3bb6eba"
    }
  }
}

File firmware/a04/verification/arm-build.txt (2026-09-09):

-- west build: generating a build system
Loading Zephyr default modules (Zephyr base (cached)).
-- Application: F:/circuit/firmware/a04
-- CMake version: 3.31.6
-- Cache files will be written to: F:/circuit/.tools/zephyr/zephyr/.cache
-- Zephyr version: 4.2.0 (F:/circuit/.tools/zephyr/zephyr)
-- Found west (found suitable version "1.4.0", minimum required is "0.14.0")
-- Board: nrf52840dk, qualifiers: nrf52840
-- Found host-tools: zephyr 0.17.2 (F:/circuit/.tools/zephyr/zephyr-sdk-0.17.2)
-- Found toolchain: zephyr 0.17.2 (F:/circuit/.tools/zephyr/zephyr-sdk-0.17.2)
-- Could NOT find Dtc (missing: DTC) (Required is at least version "1.4.6")
Hint: The project() command has not yet been called.  It sets up system-specific search paths.
-- Found BOARD.dts: F:/circuit/.tools/zephyr/zephyr/boards/nordic/nrf52840dk/nrf52840dk_nrf52840.dts
-- Found devicetree overlay: F:/circuit/firmware/a04/drivers/probe/nrf52840dk_nrf52840.overlay
-- Generated zephyr.dts: F:/circuit/.tools/a04-opus/arm/zephyr/zephyr.dts
-- Generated pickled edt: F:/circuit/.tools/a04-opus/arm/zephyr/edt.pickle
-- Generated devicetree_generated.h: F:/circuit/.tools/a04-opus/arm/zephyr/include/generated/zephyr/devicetree_generated.h
Parsing F:/circuit/firmware/a04/Kconfig
Loaded configuration 'F:/circuit/.tools/a04-opus/arm/zephyr/.config'
No change to configuration in 'F:/circuit/.tools/a04-opus/arm/zephyr/.config'
No change to Kconfig header in 'F:/circuit/.tools/a04-opus/arm/zephyr/include/generated/zephyr/autoconf.h'
-- Found gen_kobject_list: F:/circuit/.tools/zephyr/zephyr/scripts/build/gen_kobject_list.py
CMake Warning at F:/circuit/.tools/zephyr/zephyr/CMakeLists.txt:1028 (message):
  No SOURCES given to Zephyr library: drivers__audio

  Excluding target from build.

CMake Warning at F:/circuit/.tools/zephyr/zephyr/CMakeLists.txt:2240 (message):
  __ASSERT() statements are globally ENABLED

CMake Warning at F:/circuit/.tools/zephyr/zephyr/CMakeLists.txt:2271 (message):

        The CMake build type was set to 'Release', but the optimization flag was set to '-Os'.
        This may be intentional and the warning can be turned off by setting the CMake variable 'NO_BUILD_TYPE_WARNING'

-- Opus package version from package_version file: 1.6.1
-- Opus project version: 1.6.1
-- Performing Test VLA_SUPPORTED -- failed to compile
-- The following features have been enabled:

 * OPUS_DISABLE_INTRINSICS, disable all intrinsics optimizations.
 * OPUS_FIXED_POINT, compile as fixed-point (for machines without a fast enough FPU).
 * OPUS_HARDENING, run-time checks that are cheap and safe for use in production.
 * OPUS_USE_ALLOCA, use alloca for stack arrays (on non-C99 compilers).

-- The following OPTIONAL packages have been found:

 * HostTools
 * TargetTools
 * Deprecated
 * Git

-- The following REQUIRED packages have been found:

 * Python3 (required version >= 3.10)
 * Zephyr-sdk (required version >= 0.16)
 * GnuLd
 * Zephyr

-- The following features have been disabled:

 * OPUS_BUILD_SHARED_LIBRARY, build shared library.
 * OPUS_BUILD_TESTING, build tests.
 * OPUS_CUSTOM_MODES, enable non-Opus modes, e.g. 44.1 kHz & 2^n frames.
 * OPUS_BUILD_PROGRAMS, build programs.
 * OPUS_ENABLE_FLOAT_API, compile with the floating point API (for machines with float library).
 * OPUS_FLOAT_APPROX, enable floating point approximations (Ensure your platform supports IEEE 754 before enabling).
 * OPUS_ASSERTIONS, additional software error checking.
 * OPUS_FUZZING, causes the encoder to make random decisions (do not use in production).
 * OPUS_CHECK_ASM, enable bit-exactness checks between optimized and c implementations.
 * OPUS_DNN_FLOAT_DEBUG, Run DNN computations as float for debugging purposes.
 * OPUS_INSTALL_PKG_CONFIG_MODULE, install pkg-config module.
 * OPUS_INSTALL_CMAKE_CONFIG_MODULE, install CMake package config module.
 * OPUS_DRED, enable DRED.
 * OPUS_OSCE, enable OSCE.
 * OPUS_FIXED_POINT_DEBUG, debug fixed-point implementation.
 * OPUS_VAR_ARRAYS, use variable length arrays for stack arrays.
 * OPUS_NONTHREADSAFE_PSEUDOSTACK, use a non threadsafe pseudostack when neither variable length arrays or alloca is supported.
 * OPUS_FAST_MATH, enable fast math (unsupported and discouraged use, as code is not well tested with this build option).
 * OPUS_STACK_PROTECTOR, use stack protection.
 * OPUS_FORTIFY_SOURCE, add protection against buffer overflows.

-- The following OPTIONAL packages have not been found:

 * Dtc (required version >= 1.4.6)
 * ScaTools

-- Configuring done (15.9s)
-- Generating done (0.9s)
-- Build files have been written to: F:/circuit/.tools/a04-opus/arm
-- west build: building application
[1/141] Generating misc/generated/syscalls.json, misc/generated/struct_tags.json
[2/14] Building C object CMakeFiles/app.dir/src/aura_recorder.c.obj
[3/14] Building C object CMakeFiles/app.dir/src/aura_journal.c.obj
F:/circuit/firmware/a04/src/aura_journal.c: In function 'allocation':
F:/circuit/firmware/a04/src/aura_journal.c:43:5: warning: this 'if' clause does not guard... [-Wmisleading-indentation]
   43 |     if(out)*out=id;return true;
      |     ^~
F:/circuit/firmware/a04/src/aura_journal.c:43:20: note: ...this statement, but the latter is misleadingly indented as if it were guarded by the 'if'
   43 |     if(out)*out=id;return true;
      |                    ^~~~~~
F:/circuit/firmware/a04/src/aura_journal.c: In function 'scan':
F:/circuit/firmware/a04/src/aura_journal.c:506:5: warning: this 'if' clause does not guard... [-Wmisleading-indentation]
  506 |     if(!r&&identity)*identity=walk.identity;return r;
      |     ^~
F:/circuit/firmware/a04/src/aura_journal.c:506:45: note: ...this statement, but the latter is misleadingly indented as if it were guarded by the 'if'
  506 |     if(!r&&identity)*identity=walk.identity;return r;
      |                                             ^~~~~~
[4/14] Building C object CMakeFiles/app.dir/src/aura_storage.c.obj
F:/circuit/firmware/a04/src/aura_storage.c: In function 'reload':
F:/circuit/firmware/a04/src/aura_storage.c:85:5: warning: this 'if' clause does not guard... [-Wmisleading-indentation]
   85 |     if(r)return fail(s,r);s->bytes=bytes;
      |     ^~
F:/circuit/firmware/a04/src/aura_storage.c:85:27: note: ...this statement, but the latter is misleadingly indented as if it were guarded by the 'if'
   85 |     if(r)return fail(s,r);s->bytes=bytes;
      |                           ^
[5/14] Building C object CMakeFiles/app.dir/src/aura_audio_zephyr.c.obj
[6/14] Building C object CMakeFiles/app.dir/src/aura_transfer.c.obj
[7/14] Building C object CMakeFiles/app.dir/src/zephyr_probe.c.obj
[8/14] Generating linker_zephyr_pre0.cmd
[9/14] Linking C static library app\libapp.a
[10/14] Linking C executable zephyr\zephyr_pre0.elf
[11/14] Generating linker.cmd
[12/14] Generating isr_tables.c, isr_tables_vt.ld, isr_tables_swi.ld
[13/14] Building C object zephyr/CMakeFiles/zephyr_final.dir/isr_tables.c.obj
[14/14] Linking C executable zephyr\zephyr.elf
Memory region         Used Size  Region Size  %age Used
           FLASH:      227488 B         1 MB     21.69%
             RAM:      224768 B       256 KB     85.74%
        IDT_LIST:          0 GB        32 KB      0.00%

Generating files from F:/circuit/.tools/a04-opus/arm/zephyr/zephyr.elf for board: nrf52840dk

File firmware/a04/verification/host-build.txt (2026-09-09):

[1/24] Building C object CMakeFiles/aura_recorder_test.dir/F_/circuit/firmware/a04/src/aura_recorder.c.obj
[2/24] Building C object CMakeFiles/aura_recorder_test.dir/host_recorder.c.obj
[3/24] Building C object CMakeFiles/aura_w25n01gv_host.dir/F_/circuit/firmware/a04/src/aura_journal.c.obj
[4/24] Building C object CMakeFiles/aura_journal_test.dir/F_/circuit/firmware/a04/src/aura_journal.c.obj
[5/24] Building C object CMakeFiles/aura_w25n01gv_host.dir/host_w25n01gv.c.obj
[6/24] Building C object CMakeFiles/aura_journal_test.dir/host_journal.c.obj
[7/24] Linking C executable aura_w25n01gv_host.exe
[8/24] Building C object CMakeFiles/aura_audio_test.dir/F_/circuit/firmware/a04/src/aura_recorder.c.obj
[9/24] Building C object CMakeFiles/aura_audio_test.dir/F_/circuit/firmware/a04/src/aura_audio_zephyr.c.obj
[10/24] Building C object CMakeFiles/aura_recorder_test.dir/F_/circuit/firmware/a04/src/aura_journal.c.obj
[11/24] Linking C executable aura_journal_test.exe
[12/24] Building C object CMakeFiles/aura_audio_test.dir/host_audio.c.obj
[13/24] Linking C executable aura_recorder_test.exe
[14/24] Building C object CMakeFiles/aura_storage_test.dir/F_/circuit/firmware/a04/src/aura_storage.c.obj
[15/24] Building C object CMakeFiles/aura_storage_roundtrip.dir/host_storage_roundtrip.c.obj
[16/24] Building C object CMakeFiles/aura_audio_test.dir/F_/circuit/firmware/a04/src/aura_journal.c.obj
[17/24] Building C object CMakeFiles/aura_storage_test.dir/host_storage.c.obj
[18/24] Building C object CMakeFiles/aura_storage_test.dir/F_/circuit/firmware/a04/src/aura_journal.c.obj
[19/24] Linking C executable aura_audio_test.exe
[20/24] Building C object CMakeFiles/aura_storage_roundtrip.dir/F_/circuit/firmware/a04/src/aura_storage.c.obj
[21/24] Building C object CMakeFiles/aura_storage_roundtrip.dir/F_/circuit/firmware/a04/src/aura_recorder.c.obj
[22/24] Linking C executable aura_storage_test.exe
[23/24] Building C object CMakeFiles/aura_storage_roundtrip.dir/F_/circuit/firmware/a04/src/aura_journal.c.obj
[24/24] Linking C executable aura_storage_roundtrip.exe

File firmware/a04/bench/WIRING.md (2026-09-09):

# A04 external bench wiring review

This is an **unpowered design review for an nRF52840 DK bench fixture**, dated 2026-09-09. No fixture has been assembled, powered, flashed or measured. These connections are not the AURA PCB pinout, a fabrication release or permission to wear a battery-powered prototype. The separate bench application must remain an explicitly selected build target.

The first useful experiment is two external PDM microphones recording into a real W25N01GV, with physical microphone power control and UART export. Use a USB-powered DK and a common low-voltage rail; no battery, charger or dock is part of this experiment.

## Pins agreed with the bench application

Signal names, rather than physical header pin numbers, are authoritative. Match the actual PCA10056 board revision and silkscreen before wiring. Nordic identifies P1 as the power/ground connector and P2–P6/P24 as GPIO access; default UART, crystal, NFC, button/LED and onboard flash connections must be preserved. [Nordic connector reference](https://docs.nordicsemi.com/r/bundle/ug_nrf52840_dk/page/ug/dk/connector_if.html)

| Function | DK GPIO / Arduino name | External connection | Reset / idle requirement |
| --- | --- | --- | --- |
| PDM clock | P0.30 / A4 | Clock-buffer input A; buffer output to both mic CLK pins | External 100 kΩ pulldown at A; firmware stops PDM before normal power-off |
| PDM data | P0.31 / A5 | Both mic DAT pins, shared stereo bus | Input only, no MCU pull-up; 100 kΩ pulldown on the shared bus |
| NAND SCK | P1.15 / D13 | W25N CLK | SPI mode 0; begin characterization at 1 MHz |
| NAND MOSI | P1.13 / D11 | W25N DI / IO0 | No other bus master |
| NAND MISO | P1.14 / D12 | W25N DO / IO1 | Input only |
| NAND CS | P1.12 / D10 | W25N /CS | Active low; external 10 kΩ pull-up to NAND VCC |
| Mic power command | P1.03 / D2 | Physical allow contact, then load-switch ON | Active high; load-switch ON has an external 100 kΩ pulldown |
| Physical permission sense | P1.04 / D3 | Second linked contact to GND | Pull-up; low means allow, high/open means privacy or disconnected switch |
| Capture status | P0.13 / onboard LED1 (`led0`) | Existing DK LED/resistor | Active low; no extra external LED load |
| UART console | P0.06 TX, P0.08 RX, P0.05 RTS, P0.07 CTS | Existing interface MCU / USB virtual serial port | UART0 at 115200; do not connect these to the fixture |

The SPI mapping is Zephyr's `spi3` Arduino mapping. Disable default `spi1`, whose pinctrl otherwise claims P0.30/P0.31, and disable `pwm0`, which otherwise claims the status LED. Keep `i2c1` and `uart1` disabled. Do not share these pins with shields, trace outputs or another overlay. The original PDM sample enables PDM without disabling `spi1`; copying that sample alone is insufficient for this combined application. [Zephyr 4.2.0 DK DTS](https://raw.githubusercontent.com/zephyrproject-rtos/zephyr/v4.2.0/boards/nordic/nrf52840dk/nrf52840dk_nrf52840.dts), [pinctrl](https://raw.githubusercontent.com/zephyrproject-rtos/zephyr/v4.2.0/boards/nordic/nrf52840dk/nrf52840dk_nrf52840-pinctrl.dtsi), [PDM sample](https://raw.githubusercontent.com/zephyrproject-rtos/zephyr/v4.2.0/samples/drivers/audio/dmic/boards/nrf52840dk_nrf52840.overlay).

Do not substitute the DK's onboard MX25R64 QSPI NOR for W25N01GV NAND. Its wiring, command set and storage geometry differ. This fixture does not require cutting the onboard-memory solder bridges. [Nordic onboard-memory reference](https://docs.nordicsemi.com/r/bundle/ug_nrf52840_dk/page/ug/dk/hw_external_memory.html)

## Supply and actual component route

Use the DK's **VDD and GND**, with its SoC supply selection in the VDD position and normal USB/interface operation. Confirm the actual revision's switch names against its manual. The USB-derived VDD supply is nominally 3 V. Do not connect the fixture to 5 V, VDDH, a lithium cell, or an independently powered 3.3 V rail while the DK GPIO rail remains 3 V. All fixture grounds return to DK GND. The initial supply check target is **2.85–3.15 V at each powered device**; this is a project bench window, not a manufacturer tolerance. Measure at load, including NAND program/erase transients. [Nordic DK power description](https://infocenter.nordicsemi.com/pdf/nRF52840_DK_User_Guide_v1.4.1.pdf)

| Item | Named route | Review result |
| --- | --- | --- |
| Microphones | One **KAS-700-0164** two-pack of SPH0641LU4H-1 microphones on flex, with **two KCA2733** assembled flex-to-coupon adapters | Matches MK1/MK2 in the actual A04 schematic and architecture. Explicit output-level specifications permit a positive static DAT margin at the common 3 V rail. |
| NAND | W25N01GVSFIG, 16-pin SOIC, on a passive pin-numbered SOIC16-to-header adapter | Winbond operating supply 2.7–3.6 V. Identify the package and orientation; do not use the eight-pad WSON numbering for SOIC16. |
| Mic load switch | TPS22918DBVR on a passive SOT23-6 adapter or an electrically equivalent reviewed fixture | GPIO controls ON only; the switched current comes from VDD. |
| Clock isolation | SN74LVC1G125DBVR on a passive SOT23-5 adapter | Buffer supply follows MIC_VDD. Its powered-off protection is required for the proposed physical power cut. |

The KAS-700-0164 two-pack is listed as the assembled SPH0641LU4H-1 flex route; KCA2733 provides its passive adapter. Both were listed in stock when checked on 2026-09-09 (32 packs and 194 adapters). This is availability evidence, not a reservation or delivery guarantee. No parts have been ordered. [Exact microphone kit](https://www.digikey.com/en/products/detail/syntiant/KAS-700-0164/17878612), [exact adapter](https://www.digikey.com/en/products/detail/syntiant/KCA2733/16644481), [manufacturer kit selection guide](https://www.knowles.com/docs/default-source/default-document-library/mic-selection-guide-v121222.pdf).

Use the **KCA2733 six-position coupon interface**, not the eight-position flex connector numbering:

| Coupon contact | Marking / signal | Bench connection |
| --- | --- | --- |
| 1 | P / power | MIC_VDD |
| 2 | O / digital DATA | Shared DAT to P0.31 |
| 3 | G / ground | Common GND |
| 4 | LR / SELECT | GND on one adapter, MIC_VDD on the other |
| 5 | Unused for PDM | Leave disconnected |
| 6 | K / bit clock | Isolated clock-buffer output |

AN18 explicitly defines this pinout and distinguishes the assembled KCA2733 from its bare KCB2734 PCB. It includes a 100 nF bypass capacitor. Use the adapter's marked contacts with strain-relieved flying wires, or the specified Sullins EBM03DSEN-S243 mating connector; confirm continuity to the marked nets before applying power. [Manufacturer AN18, pages 1–2](https://www.knowles.com/docs/default-source/default-document-library/an18-knowles-flex-circuit-and-coupons-for-testing_updated.pdf). Insert each flex with copper contacts face down and latch closed as shown in the [manufacturer Muskie guide, page 5](https://www.mouser.com/catalog/specsheets/knowles%20corp_06052019_KAS-33100-0004%20Muskie%20Users%20Guide%20rev29may19.pdf). The Muskie controller itself is not needed and must not simultaneously drive these nets.

The selected microphone accepts 1.62–3.6 V. Normal PDM clock is **1.024–2.475 MHz**, with 40–60% duty below 2.4 MHz and a 3 ns maximum clock edge time. Startup allowance is 50 ms. A 1.032 MHz or 1.280 MHz PDM setting is within that range; **1.000 MHz is not**. NAND SCK remains a separate 1 MHz signal. Verify the compiled driver's selected clock/decimation and actual PCM rate; a requested 16 kHz alone does not prove either. Keep acoustic ports clear, retain local 100 nF bypassing, and characterize both channels separately. [Knowles SPH0641LU4H-1 Rev B, electrical/interface tables](https://www.mouser.com/datasheet/2/218/sph0641lu4h_1_revb-3313002.pdf)

The same interface table specifies DATA **VOH ≥ MIC_VDD − 0.45 V** and **VOL ≤ 0.45 V** at 2 mA. Against Nordic's VIH ≥0.7×VDD and VIL ≤0.3×VDD, the equal-rail static high and low margins are each `0.3 × VDD − 0.45 V`, at least **0.405 V** for VDD≥2.85 V. Requiring MIC_VDD to remain no more than 50 mV below DK VDD leaves **0.355 V** high margin; ground shift, noise and transient loading consume that budget. These are calculated interface margins using published limits, not measurements or a full-temperature production guarantee. Scope the actual DATA half-cycles and clock edges, confirm load/current limits, and measure rail difference. [Nordic GPIO limits](https://docs-be.nordicsemi.com/bundle/nRF52-Series-PS/raw/resource/enus/nRF52840_PS_v1.0.pdf?save_local=true).

The initially considered Adafruit/MP34DT01-M route is **not selected**: its combined 0.65×VDD /0.35×VDD I/O table did not establish positive margin against Nordic's input limits. It must not be substituted without a new interface review. [ST MP34DT01-M table 3](https://www.st.com/resource/en/datasheet/mp34dt01-m.pdf)

## Physical microphone privacy fixture

Use a **mechanically linked two-pole maintained switch**, wired so both contacts close only in the allow position. An ordinary momentary button or a firmware input alone does not implement this power cut.

```text
DK VDD ---- TPS22918 VIN             VOUT ---- MIC_VDD ---- both adapters P
DK GND ---- TPS22918 GND                         +--------- clock-buffer VCC
P1.03 ----- switch pole A ---- ON
                             +-- 100 kΩ -- GND
P1.04 ----- switch pole B ---- GND
  +-------- pull-up to DK VDD (configured GPIO; external 10 kΩ recommended)

P0.30 ----- buffer A          buffer Y --------- both microphone CLK
  +-- 100 kΩ -- GND           +-- 100 kΩ -- GND
                             buffer /OE ------- GND
                             buffer GND ------- GND
```

TPS22918 DBV pins are VIN1, GND2, ON3, CT4, QOD5, VOUT6. Place at least 1 µF ceramic on VIN, leave CT unconnected for the first fixture, and connect QOD to VOUT. Keep total switched capacitance below 200 µF for this QOD connection; the proposed microphone and adapter bypassing is below that limit. Its ON thresholds are ≥1 V high and ≤0.5 V low. The external pulldown makes reset and an open contact disable the switch. Check adapter orientation and continuity before power. [TI TPS22918 Rev C, pin functions and QOD](https://www.ti.com/lit/ds/symlink/tps22918.pdf)

SN74LVC1G125 DBV pins are /OE1, A2, GND3, Y4, VCC5. Add 100 nF directly across VCC/GND. The buffer operates from 1.65–5.5 V and specifies powered-off leakage with VCC=0; this prevents treating a live MCU clock wired directly to an unpowered mic as valid isolation. It does **not** prove isolation throughout rail decay, contact bounce, or every component fault. Measure cutoff timing and backfeed with P0.30 deliberately toggling while the physical switch is off. The application's normal stop sequence remains necessary. [TI SN74LVC1G125 Rev U, sections 5 and 7.3.2](https://www.ti.com/lit/ds/symlink/sn74lvc1g125.pdf)

Privacy sense is fail-closed for an open wire; a short to ground is not diagnosed by this two-wire sense. DAT is directly connected to a high-impedance MCU input in this fixture: accidentally configuring that pin as an output or enabling a pull-up can back-power the microphones and is not covered by the clock buffer. A04's proposed dual buffer also isolates DATA; this bench fixture has not implemented that additional fault boundary. The status LED reports application state and is not an independent electrical witness of microphone power. Do not claim instantaneous cutoff, fault-tolerant privacy, or verified recording indication from this wiring review.

## W25N01GV connections

For the **SOIC16 SF package only**: /HOLD1 and /WP9 each get 10 kΩ to VCC2; GND10 goes to common ground; /CS7 goes to P1.12; DO8 to P1.14; DI15 to P1.13; CLK16 to P1.15. Leave NC3–6 and NC11–14 disconnected. Place 100 nF ceramic and 4.7 µF local bulk bypass across VCC/GND as fixture starting values. These capacitance values and the initial 1 MHz bus are engineering choices requiring measurement, not a vendor-qualified layout. Keep wiring short with adjacent ground returns.

Use standard single-data-line SPI, mode 0, active-low CS. Pulling WP/HOLD high avoids unintentional hold/protection assertions; it does not override software/OTP protection. The driver must validate chip identity, ECC/configuration, factory bad-block markers and BBM state. Preserve unknown source contents; never mass-erase a populated chip to make initialization pass. [Winbond manufacturer datasheet Rev R, sections 3.4, 4 and 7, hosted by Mouser](https://www.mouser.com/datasheet/2/949/Winbond_Electronics_09072023_W25N01GV_Rev_R_070323-3313374.pdf)

## Evidence required before calling the bench functional

1. Record exact DK revision, component markings, adapter continuity, opposite SEL straps, supply polarity and absence of shorts with power removed.
2. Measure VDD/MIC_VDD and current with microphones disabled, enabled, and during NAND traffic. Verify rail limits, local decoupling and absence of backfeed. A shared USB console is not a wearable power measurement.
3. Scope clock frequency/duty/edge integrity and DAT setup/hold plus high/low levels at the receiving pin. Confirm the calculated static budget survives actual rail difference, loading and noise; a decoded audio file alone does not prove those conditions.
4. Verify the physical switch removes mic power despite a stuck-high software command and a toggling upstream clock, then verify firmware stops capture on a rising/open permission input. Record measured cutoff and rail discharge timing; no result is assumed here.
5. Capture distinguishable left/right sound, export the actual NAND-backed archive, independently decode it, compare exact receipts and repeat cold recovery without deleting the original capture. Apply power-fault tests only to explicitly disposable test recordings.

The local source identities and the unmeasured review status are recorded in [wiring-review.json](wiring-review.json). Supply compatibility and pin ownership have been reviewed; complete electrical, acoustic, privacy, flash-endurance and physical operation remain unverified.

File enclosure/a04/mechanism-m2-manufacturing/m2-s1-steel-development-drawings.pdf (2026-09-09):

# AURA / A04 M2 S1

### METAL PLUNGER SHOE | MFG-D01 | SHEET 1 OF 2

## DEVELOPMENT

QUOTE / UNPOWERED FIXTURE ONLY

TOP VIEW FROM +Z / CAD +Y UP / NO HOLES | MATERIAL / CERTIFICATE
| ASTM A666 Type 301 / UNS S30100, HALF-HARD. Explicit lot certificate: 0.2% yield >= 110 ksi (758 MPa). Temper or hardness alone is insufficient.
| THICKNESS / DEFINED ACCEPTANCE
| Actual incoming metal: 0.28-0.32 mm. Preserve this minimum finished metal thickness after processing. Mesh thickness is a geometry gauge.
| CUTTING / EDGES
| Preserve the supplied cold-worked temper. Quote cold cutting or cool machining and deburring. No anneal, weld or hot straightening without requalification. Thermal-cut edges require retained-property qualification.
| PROFILE / FLATNESS
| No kerf compensation is included. Exact source facets are retained; no fitted arcs, fillets or chamfers are authorized. Preserve net CAD section after finishing. Quote achievable XY tolerance, edge condition and flatness for review; no numeric limits are approved here.
| INSULATION / RELEASE GATES
| No burr or sharp edge may damage fitted insulation. Complete metal work before adhesive/insulation assembly. Coverage, retention, dielectric adequacy and finished packet fit remain unqualified. Native PCB fit and physical strength are not approved.
| SUPPLIER DATA / NO STOCK CONFIRMATION
| 0.02-1.57 mm strip capability covers these thicknesses. This does not establish stock, lot, width, MOQ or process acceptance. R1 - Elgiloy 301 material data (https://www.elgiloy.com/wp-content/uploads/2024/06/301-Alloy-Stainless-Steel-Data-Sheet-06042024.pdf) R2 - Elgiloy strip capability (https://www.elgiloy.com/wp-content/uploads/2024/05/ESM-Stainless-Strip-LineCard-DIGITAL-5.30.2024-compressed-1.pdf)

9.000

6.200

O

O = lower-left envelope intersection; not a machined datum.

EDGE VIEW / NO BENDS

t = 0.300 MESH REF

VIEW SCALE 8:1 AT A4 / 100%. NOMINAL DIMENSIONS IN mm; DO NOT SCALE FOR FABRICATION.

Origin in assembly CAD XY: -11.500000, -7.600000 mm. DXF is 1:1, INSUNITS = 4 (mm).

BLEND SHA256 3409634192e4be88350e3d758d46225f96e341f8e857ea225b55178e15054cd9
DXF SHA256 | 6669b0bb49ea843bb250d72d0fa6c623d7b310a487fc08e510ff3ea9aa35dcea
Frozen source profiles verified against both depth variants and STL caps. Full concordance: profiles.json / manufacturing-verification.json. | 1/2

# AURA / A04 M2 S1

### LOWER STEEL SUPPORT | MFG-D01 | SHEET 2 OF 2

## DEVELOPMENT

QUOTE / UNPOWERED FIXTURE ONLY

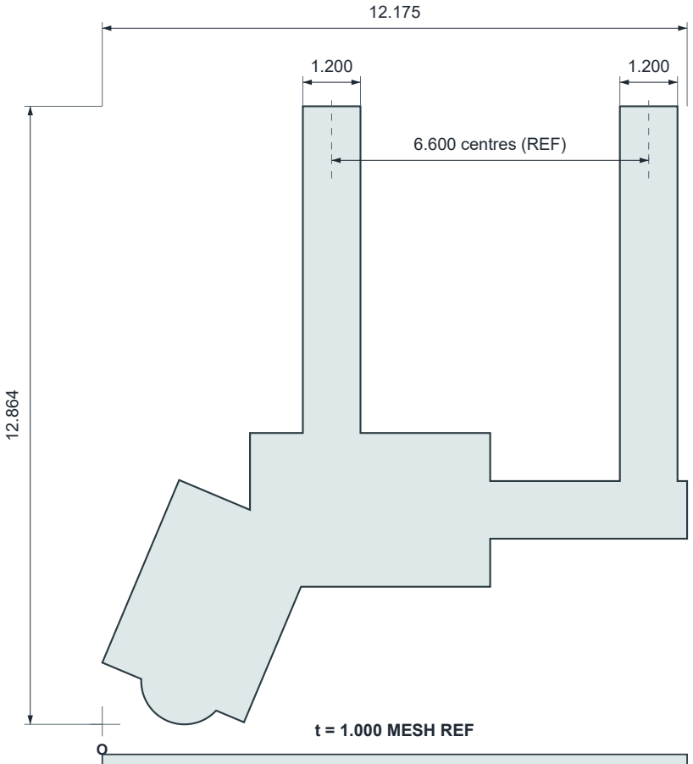
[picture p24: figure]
6.600 centres (REF); t = 1.000 MESH REF

TOP VIEW FROM +Z / CAD +Y UP / NO HOLES | MATERIAL / CERTIFICATE
| ASTM A666 Type 301 / UNS S30100, HALF-HARD. Explicit lot certificate: 0.2% yield >= 110 ksi (758 MPa). Temper or hardness alone is insufficient.
| THICKNESS / DEFINED ACCEPTANCE
| Actual incoming metal: 0.95-1.00 mm; no plus tolerance beyond 1.00 mm. Preserve this minimum finished metal thickness after processing. Mesh thickness is a geometry gauge.
| CUTTING / EDGES
| Preserve the supplied cold-worked temper. Quote cold cutting or cool machining and deburring. No anneal, weld or hot straightening without requalification. Thermal-cut edges require retained-property qualification.
| PROFILE / FLATNESS
| No kerf compensation is included. Exact source facets are retained; no fitted arcs, fillets or chamfers are authorized. Preserve net CAD section after finishing. Quote achievable XY tolerance, edge condition and flatness for review; no numeric limits are approved here.
| INSULATION / RELEASE GATES
| No burr or sharp edge may damage fitted insulation. Complete metal work before adhesive/insulation assembly. Coverage, retention, dielectric adequacy and finished packet fit remain unqualified. Native PCB fit and physical strength are not approved.
| SUPPLIER DATA / NO STOCK CONFIRMATION
| 0.02-1.57 mm strip capability covers these thicknesses. This does not establish stock, lot, width, MOQ or process acceptance. R1 - Elgiloy 301 material data (https://www.elgiloy.com/wp-content/uploads/2024/06/301-Alloy-Stainless-Steel-Data-Sheet-06042024.pdf) R2 - Elgiloy strip capability (https://www.elgiloy.com/wp-content/uploads/2024/05/ESM-Stainless-Strip-LineCard-DIGITAL-5.30.2024-compressed-1.pdf)

O = lower-left envelope intersection; not a machined datum.

EDGE VIEW / NO BENDS

VIEW SCALE 8:1 AT A4 / 100%. NOMINAL DIMENSIONS IN mm; DO NOT SCALE FOR FABRICATION.

Origin in assembly CAD XY: -15.074617, -14.264318 mm. DXF is 1:1, INSUNITS = 4 (mm).

BLEND SHA256 3409634192e4be88350e3d758d46225f96e341f8e857ea225b55178e15054cd9
DXF SHA256 | 77bcf16addb7a588ffd2e97a96ff95e48bdbd65f98982af6cd2d5ca0d71a4b86
Frozen source profiles verified against both depth variants and STL caps. Full concordance: profiles.json / manufacturing-verification.json. | 2/2

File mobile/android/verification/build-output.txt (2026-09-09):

To honour the JVM settings for this build a single-use Daemon process will be forked. For more on this, please refer to https://docs.gradle.org/9.4.1/userguide/gradle_daemon.html#sec:disabling_the_daemon in the Gradle documentation.
Daemon will be stopped at the end of the build 
Reusing configuration cache.
> Task :app:preBuild UP-TO-DATE
> Task :core:checkKotlinGradlePluginConfigurationErrors SKIPPED
> Task :app:preDebugBuild UP-TO-DATE
> Task :app:mergeDebugNativeDebugMetadata NO-SOURCE
> Task :core:processResources NO-SOURCE
> Task :app:generateDebugResources UP-TO-DATE
> Task :app:packageDebugResources UP-TO-DATE
> Task :app:processDebugNavigationResources UP-TO-DATE
> Task :app:parseDebugLocalResources UP-TO-DATE
> Task :core:compileKotlin UP-TO-DATE
> Task :app:generateDebugRFile UP-TO-DATE
> Task :core:compileJava NO-SOURCE
> Task :core:classes UP-TO-DATE
> Task :app:javaPreCompileDebug UP-TO-DATE
> Task :app:generateDebugAssets UP-TO-DATE
> Task :app:mergeDebugAssets UP-TO-DATE
> Task :app:compressDebugAssets UP-TO-DATE
> Task :core:jar UP-TO-DATE
> Task :app:generateDebugGlobalSynthetics UP-TO-DATE
> Task :app:checkDebugDuplicateClasses UP-TO-DATE
> Task :app:desugarDebugFileDependencies UP-TO-DATE
> Task :app:mergeExtDexDebug UP-TO-DATE
> Task :app:mergeLibDexDebug UP-TO-DATE
> Task :app:checkDebugAarMetadata UP-TO-DATE
> Task :app:mapDebugSourceSetPaths UP-TO-DATE
> Task :app:compileDebugNavigationResources UP-TO-DATE
> Task :app:mergeDebugResources UP-TO-DATE
> Task :app:createDebugCompatibleScreenManifests UP-TO-DATE
> Task :app:extractDeepLinksDebug UP-TO-DATE
> Task :app:processDebugMainManifest UP-TO-DATE
> Task :app:processDebugManifest UP-TO-DATE
> Task :app:processDebugManifestForPackage UP-TO-DATE
> Task :app:processDebugResources UP-TO-DATE
> Task :app:mergeDebugJniLibFolders UP-TO-DATE
> Task :app:mergeDebugNativeLibs NO-SOURCE
> Task :app:stripDebugDebugSymbols NO-SOURCE
> Task :app:validateSigningDebug UP-TO-DATE
> Task :app:writeDebugAppMetadata UP-TO-DATE
> Task :app:writeDebugSigningConfigVersions UP-TO-DATE
> Task :app:preDebugAndroidTestBuild SKIPPED
> Task :app:generateDebugAndroidTestResources UP-TO-DATE
> Task :app:packageDebugAndroidTestResources UP-TO-DATE
> Task :app:processDebugAndroidTestNavigationResources UP-TO-DATE
> Task :app:parseDebugAndroidTestLocalResources UP-TO-DATE
> Task :app:generateDebugAndroidTestRFile UP-TO-DATE
> Task :app:javaPreCompileDebugAndroidTest UP-TO-DATE
> Task :app:generateDebugAndroidTestAssets UP-TO-DATE
> Task :app:mergeDebugAndroidTestAssets UP-TO-DATE
> Task :app:compressDebugAndroidTestAssets UP-TO-DATE
> Task :app:generateDebugAndroidTestGlobalSynthetics UP-TO-DATE
> Task :app:checkDebugAndroidTestDuplicateClasses UP-TO-DATE
> Task :app:desugarDebugAndroidTestFileDependencies UP-TO-DATE
> Task :app:mergeExtDexDebugAndroidTest UP-TO-DATE
> Task :app:mergeLibDexDebugAndroidTest UP-TO-DATE
> Task :app:checkDebugAndroidTestAarMetadata UP-TO-DATE
> Task :app:mapDebugAndroidTestSourceSetPaths UP-TO-DATE
> Task :app:compileDebugAndroidTestNavigationResources UP-TO-DATE
> Task :app:mergeDebugAndroidTestResources UP-TO-DATE
> Task :app:processDebugAndroidTestManifest UP-TO-DATE
> Task :app:processDebugAndroidTestResources UP-TO-DATE
> Task :app:mergeDebugAndroidTestJniLibFolders UP-TO-DATE
> Task :app:mergeDebugAndroidTestNativeLibs NO-SOURCE
> Task :app:stripDebugAndroidTestDebugSymbols NO-SOURCE
> Task :app:validateSigningDebugAndroidTest UP-TO-DATE
> Task :app:writeDebugAndroidTestSigningConfigVersions UP-TO-DATE
> Task :app:extractProguardFiles UP-TO-DATE
> Task :app:preDebugUnitTestBuild UP-TO-DATE
> Task :app:compileDebugKotlin
> Task :app:compileDebugJavaWithJavac NO-SOURCE
> Task :app:processDebugJavaRes UP-TO-DATE
> Task :app:mergeDebugJavaResource UP-TO-DATE
> Task :app:bundleDebugClassesToCompileJar
> Task :app:dexBuilderDebug
> Task :app:mergeProjectDexDebug
> Task :app:packageDebug
> Task :app:createDebugApkListingFileRedirect UP-TO-DATE
> Task :app:assembleDebug
> Task :app:generateDebugAndroidTestLintModel
> Task :app:generateDebugLintReportModel
> Task :app:generateDebugUnitTestLintModel
> Task :app:compileDebugAndroidTestKotlin
> Task :app:compileDebugAndroidTestJavaWithJavac UP-TO-DATE
> Task :app:processDebugAndroidTestJavaRes UP-TO-DATE
> Task :app:mergeDebugAndroidTestJavaResource UP-TO-DATE
> Task :app:dexBuilderDebugAndroidTest
> Task :app:mergeProjectDexDebugAndroidTest
> Task :app:packageDebugAndroidTest
> Task :app:createDebugAndroidTestApkListingFileRedirect UP-TO-DATE
> Task :app:assembleDebugAndroidTest
> Task :app:lintAnalyzeDebug
> Task :app:lintAnalyzeDebugAndroidTest
> Task :app:lintAnalyzeDebugUnitTest
> Task :app:lintReportDebug
> Task :app:lintDebug

BUILD SUCCESSFUL in 1m 42s
76 actionable tasks: 17 executed, 59 up-to-date
Configuration cache entry reused.

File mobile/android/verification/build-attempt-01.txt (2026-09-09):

To honour the JVM settings for this build a single-use Daemon process will be forked. For more on this, please refer to https://docs.gradle.org/9.4.1/userguide/gradle_daemon.html#sec:disabling_the_daemon in the Gradle documentation.
Daemon will be stopped at the end of the build 
Reusing configuration cache.
> Task :core:checkKotlinGradlePluginConfigurationErrors SKIPPED
> Task :app:preBuild UP-TO-DATE
> Task :app:preDebugBuild UP-TO-DATE
> Task :app:mergeDebugNativeDebugMetadata NO-SOURCE
> Task :core:processResources NO-SOURCE
> Task :core:compileKotlin UP-TO-DATE
> Task :core:compileJava NO-SOURCE
> Task :core:classes UP-TO-DATE
> Task :core:jar UP-TO-DATE
> Task :app:processDebugNavigationResources
> Task :app:generateDebugResources
> Task :app:javaPreCompileDebug UP-TO-DATE
> Task :app:generateDebugAssets UP-TO-DATE
> Task :app:mergeDebugAssets UP-TO-DATE
> Task :app:compressDebugAssets UP-TO-DATE
> Task :app:generateDebugGlobalSynthetics UP-TO-DATE
> Task :app:checkDebugDuplicateClasses UP-TO-DATE
> Task :app:desugarDebugFileDependencies UP-TO-DATE
> Task :app:mergeExtDexDebug UP-TO-DATE
> Task :app:mergeLibDexDebug UP-TO-DATE
> Task :app:checkDebugAarMetadata UP-TO-DATE
> Task :app:mapDebugSourceSetPaths
> Task :app:compileDebugNavigationResources UP-TO-DATE
> Task :app:packageDebugResources
> Task :app:parseDebugLocalResources
> Task :app:mergeDebugResources
> Task :app:createDebugCompatibleScreenManifests UP-TO-DATE
> Task :app:extractDeepLinksDebug UP-TO-DATE
> Task :app:generateDebugRFile
> Task :app:processDebugMainManifest UP-TO-DATE
> Task :app:processDebugManifest UP-TO-DATE
> Task :app:processDebugManifestForPackage UP-TO-DATE
> Task :app:processDebugResources
> Task :app:mergeDebugJniLibFolders UP-TO-DATE
> Task :app:mergeDebugNativeLibs NO-SOURCE
> Task :app:stripDebugDebugSymbols NO-SOURCE
> Task :app:validateSigningDebug UP-TO-DATE
> Task :app:writeDebugAppMetadata UP-TO-DATE
> Task :app:writeDebugSigningConfigVersions UP-TO-DATE
> Task :app:preDebugAndroidTestBuild SKIPPED
> Task :app:generateDebugAndroidTestResources UP-TO-DATE
> Task :app:packageDebugAndroidTestResources UP-TO-DATE
> Task :app:processDebugAndroidTestNavigationResources UP-TO-DATE
> Task :app:parseDebugAndroidTestLocalResources UP-TO-DATE
> Task :app:generateDebugAndroidTestRFile UP-TO-DATE
> Task :app:javaPreCompileDebugAndroidTest UP-TO-DATE
> Task :app:generateDebugAndroidTestAssets UP-TO-DATE
> Task :app:mergeDebugAndroidTestAssets UP-TO-DATE
> Task :app:compressDebugAndroidTestAssets UP-TO-DATE
> Task :app:generateDebugAndroidTestGlobalSynthetics UP-TO-DATE
> Task :app:checkDebugAndroidTestDuplicateClasses UP-TO-DATE
> Task :app:desugarDebugAndroidTestFileDependencies UP-TO-DATE
> Task :app:mergeExtDexDebugAndroidTest UP-TO-DATE
> Task :app:mergeLibDexDebugAndroidTest UP-TO-DATE
> Task :app:checkDebugAndroidTestAarMetadata UP-TO-DATE
> Task :app:mapDebugAndroidTestSourceSetPaths UP-TO-DATE
> Task :app:compileDebugAndroidTestNavigationResources UP-TO-DATE
> Task :app:mergeDebugAndroidTestResources UP-TO-DATE
> Task :app:processDebugAndroidTestManifest UP-TO-DATE
> Task :app:processDebugAndroidTestResources UP-TO-DATE
> Task :app:mergeDebugAndroidTestJniLibFolders UP-TO-DATE
> Task :app:mergeDebugAndroidTestNativeLibs NO-SOURCE
> Task :app:stripDebugAndroidTestDebugSymbols NO-SOURCE
> Task :app:validateSigningDebugAndroidTest UP-TO-DATE
> Task :app:writeDebugAndroidTestSigningConfigVersions UP-TO-DATE
> Task :app:extractProguardFiles UP-TO-DATE
> Task :app:preDebugUnitTestBuild UP-TO-DATE
> Task :app:compileDebugKotlin
> Task :app:compileDebugJavaWithJavac NO-SOURCE
> Task :app:processDebugJavaRes UP-TO-DATE
> Task :app:mergeDebugJavaResource UP-TO-DATE
> Task :app:bundleDebugClassesToCompileJar
> Task :app:compileDebugAndroidTestKotlin
> Task :app:compileDebugAndroidTestJavaWithJavac NO-SOURCE
> Task :app:processDebugAndroidTestJavaRes UP-TO-DATE
> Task :app:mergeDebugAndroidTestJavaResource UP-TO-DATE
> Task :app:dexBuilderDebugAndroidTest UP-TO-DATE
> Task :app:mergeProjectDexDebugAndroidTest UP-TO-DATE
> Task :app:packageDebugAndroidTest UP-TO-DATE
> Task :app:createDebugAndroidTestApkListingFileRedirect UP-TO-DATE
> Task :app:assembleDebugAndroidTest UP-TO-DATE
> Task :app:generateDebugAndroidTestLintModel
> Task :app:generateDebugLintReportModel
> Task :app:generateDebugUnitTestLintModel
> Task :app:dexBuilderDebug
> Task :app:mergeProjectDexDebug
> Task :app:packageDebug
> Task :app:createDebugApkListingFileRedirect UP-TO-DATE
> Task :app:assembleDebug
> Task :app:lintAnalyzeDebug
> Task :app:lintAnalyzeDebugAndroidTest
> Task :app:lintAnalyzeDebugUnitTest
> Task :app:lintReportDebug
> Task :app:lintDebug

BUILD SUCCESSFUL in 1m 18s
75 actionable tasks: 22 executed, 53 up-to-date
Configuration cache entry reused.

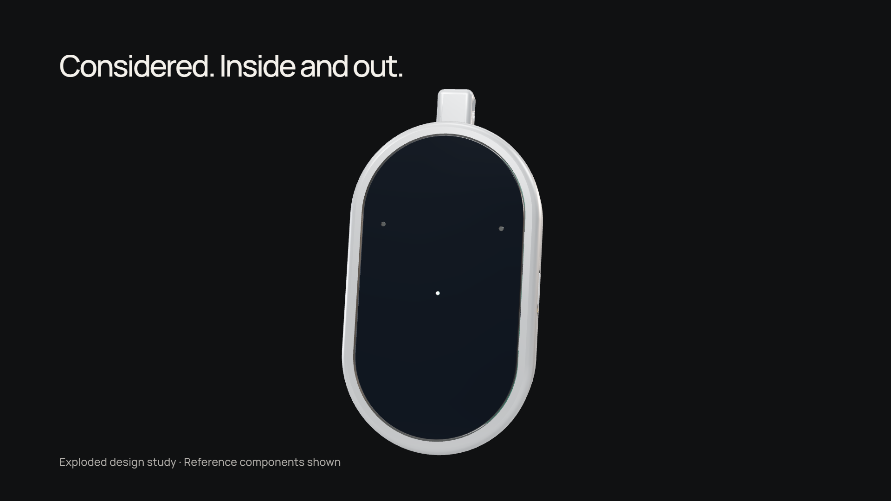
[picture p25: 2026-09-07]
film/aura-launch/qa/assembly-snapshots-final/frame-02-at-28.4s.png

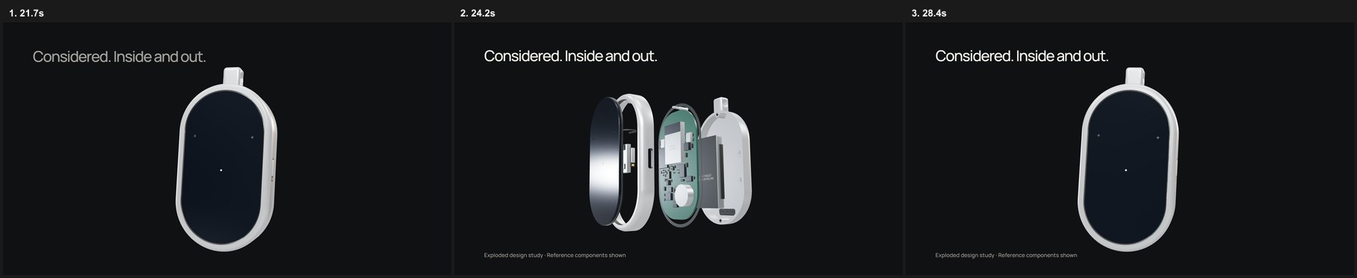
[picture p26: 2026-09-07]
film/aura-launch/qa/assembly-snapshots-final/contact-sheet.jpg

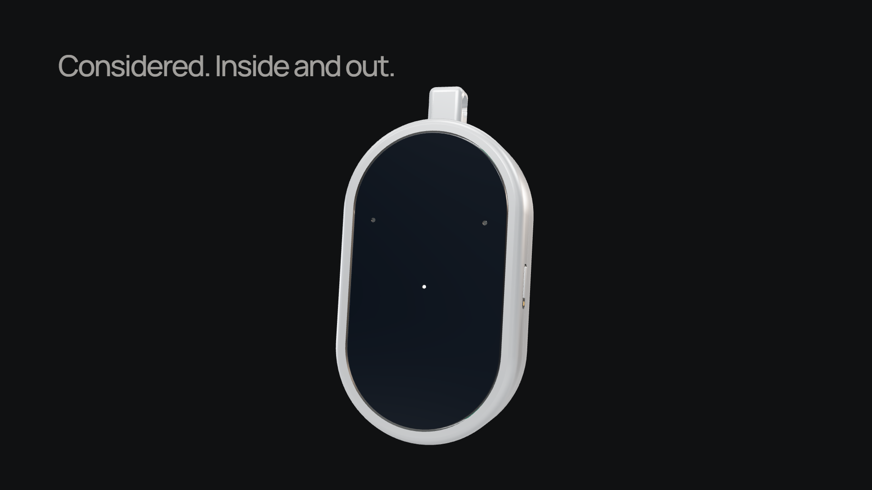
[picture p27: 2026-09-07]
film/aura-launch/qa/assembly-snapshots/frame-00-at-21.7s.png

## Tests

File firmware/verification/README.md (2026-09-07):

# A03 engineering firmware verification

Verified locally on 2026-09-08. No physical PCB was connected.

| Check | Result |
|---|---|
| Actual ARM build | PASS, Zephyr v4.2.0 / SDK 0.17.2 / ARM GCC 12.2.0, custom `aura_a03/nrf52840` board |
| Application flash | **219,108 bytes / 992 KiB** (21.57%); final 32 KiB reserved for persistent settings |
| Static RAM and configured stacks/buffers | **83,452 bytes / 256 KiB** (31.83%); runtime stack high-water remains a bench check |
| Shared C journal/gesture/PCM/maintenance tests | **14 passed** |
| Production NAND command serializer tests | **4 passed** against a strict simulated SPI device |
| Release identity/configuration checks | **5 passed**, including matching ELF/HEX/BIN and safe qualification gates |
| Physical audio/BLE/NAND/charger/haptic/thermal tests | **Not performed** |

Evidence: `arm-build.txt`, `host-tests.txt`, `nand-tests.txt` and `release-checks.txt`. `../release/manifest.json` contains the exact hashes; source hashing normalizes CRLF to LF, and `.gitattributes` preserves binary release bytes through Git.

The checked BIN is 219,108 bytes, SHA-256 `cf3b32c688537ce48575260b3c993c980eae5410aef9a080df693749f4b707cf`. The HEX SHA-256 is `94a72d7d68decde347c0619d4564a80548defff8fb68da6ce57a53e4a12192f8`.

The final configuration requests 1.280 MHz PDM with RATIO80 for exactly 16 kHz, two channels mixed to mono, 50 ms rail settling and two discarded 40 ms startup DMA blocks. The nRF52840's documented ratio capability was checked in the pinned Nordic MDK and Zephyr driver; the clock is within the microphone's retrieved standard-mode limits. First-article scope/acoustic measurements are still required.

The distributed image disables charge permission and haptics. It requires physical pairing, encrypted characteristics and a separate physical hold plus explicit command for storage reuse. Firmware code, successful compilation and simulated fault tests do not establish a safe assembled battery product, manufacturing readiness, or consumer security certification.

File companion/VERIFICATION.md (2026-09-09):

# Companion verification

## A04 explicit release outbox — 2026-09-09

The current complete suite passes **131 tests**, including **36 release/outbox tests** and the existing **33 archive/receiver tests**. [Source-bound evidence and exact commands](verification/release.json) record the runtime and successful no-skip results. Run `./.venv/Scripts/python.exe scripts/verify_release.py --report verification/release.json` from `companion/` to reproduce.

The [release module](RELEASE.md) requires explicit permission for an exact finalized capture, revalidates its committed SQLite source, and durably stores the authenticated command before returning it. Tests cover source corruption, concurrent issuance, transaction interruption, lost replies, exact retries, floor exhaustion and completed-history integrity. The separate [firmware storage integration](../firmware/a04/STORAGE.md) exercises real C-encoded audio through this receiver/outbox back to the actual C release controller on modeled NAND. Neither suite supplies secure enrollment, authenticated Bluetooth completion, mobile recovery or physical-device evidence. The 0.4.0 importer checkpoint below remains historical evidence for its earlier 95-test suite.

## 0.4.0 — real archive import and source preservation, 2026-09-09

The complete suite passed **95 tests** on Python **3.12.13**: 28 baseline, 33 revision-3 protocol/receiver, 11 import/decode/publication and 23 source/notes/upload tests. The actual command and result are retained in [companion-integration.txt](../firmware/a04/verification/companion-integration.txt). These tests use the companion environment, including pinned PyAV 18.1.0; the firmware tool environment alone does not include the desktop decoder.

The new path reads actual C-generated Opus archives, verifies immutable manifests/packets/seals, commits their records to an on-disk SQLite transaction, compares the C receipt, publishes a verified raw archive/WAV/source bundle, and checks exact duration. Independent FFmpeg decoding agrees with the desktop decoder. Finalized 10/20 ms fixtures retain exactly **120,847 samples**; the interrupted fixture retains **120,600 samples** with the original duration explicitly unknown. Synthetic source audio and checked-in fixtures make this reproducible without private recordings.

Fault tests cover interrupted publication and repair, corrupt existing files, decoder failure, exclusive importer ownership, replay after reopening, torn archives, preserved interrupted/final revisions, source-metadata substitution and preservation of previous note JSON. An independent review caught a temporary SQLite database accepting a receipt; empty/in-memory paths are now rejected and regression-tested. SQLite/file flush calls are exercised, but these tests do not qualify a storage device against physical power loss.

The final independent review added 11 regressions for source replacement during inference and revision publication ordering. Transcription now consumes a private snapshot matching the initially verified WAV; changing the original source or its sidecar cannot attach another identity. A swap-and-restore during lazy inference cannot change the snapshot consumed by the model. Prior note revisions are flushed and their POSIX directory chain synced before the current note is replaced. Preparation failures preserve the current note, and retries verify/resync an existing revision. POSIX call ordering/failure handling was simulated on this Windows host; Windows file flush and replacement were exercised directly, without a directory-durability or physical power-loss guarantee. A repeat real Whisper run after these fixes produced the identical public fixture hash below.

The actual CLI imported `firmware/a04/fixtures/capture-20ms.aura` and ran local **faster-whisper 1.2.1 / tiny.en**. The resulting [synthetic note fixture](tests/assets/a04-capture.note.json) retains source identity, unknown capture time, bookmarks at samples 8,000 and 32,000, transcript segments and method metadata. Its SHA-256 is `dc0af0515c69fec8a981fac732c1d9e056559b1de547e89d4c642618024c652c`.

The real Python uploader then sent that note through local Next.js and Convex. [The integration report](../portal/verification/a04-provenance-local.json) records successful owner authentication, token rotation without duplication, token revocation, owner isolation, source-conflict rejection, retained original text after owner edits and consent-controlled context retrieval. This exercised the real local services and synthetic HTTP account flow; it was not a browser or production-cloud test. Synthetic notes were archived, tokens revoked and sessions signed out.

Run the suite from `companion/` with `uv run --locked python -m unittest discover -s tests -v`. [Import commands and bundle/recovery semantics](README.md#a04-archive-import--040) describe the working path. A04 PDM/NAND/BLE, mobile lifecycle, physical-device identity, account cloud deployment and real pendant execution remain outstanding. No importer operation sends an ACK or deletion request to a pendant.

`uv build --out-dir ../.scratch/omi-review/companion-dist` built the **0.4.0 source distribution and wheel** successfully. The importer help command and pinned lockfile also resolve successfully; generated packages are local reproducible build outputs.

## 0.3.1 — recovery changes, 2026-09-09

`uv run --locked python -m unittest discover -s tests -v` passed **28 tests** on Python **3.12.13**: the 12 previous cases, eight download/publication recovery cases and eight CLI lifecycle cases. The new suite verifies repeat sync without Bluetooth audio reads, corrupt/truncated WAV rejection, conflicting receipt rejection, missing-WAV re-download, repair after interrupted receipt publication, and preservation of a previous file when atomic replacement fails.

CLI tests use a fake async connection and synthetic model/upload functions. They verify that all transfers and disconnect precede processing, later records continue after a failure at each processing stage, interrupted inventory preserves already verified work, disconnect cleanup failure prevents processing, active capture blocks sync, and plain sync never processes or uploads. Failure receipts and aggregate errors exclude injected transcript/token strings. These are controlled failure simulations, not physical power-cut or radio tests.

`uv build --out-dir ../.scratch/omi-review/companion-dist` successfully built the **0.3.1 source distribution and wheel**. `uv run --locked aura sync --help` also passed. Dependency versions stayed fixed; only the local package version changed in the lockfile.

Sync writes a `.sync.json` receipt describing the **last processing stage**, its started/completed/failed status and a bounded error code. A completed transcription stage alone does not mean notes or cloud storage completed. A status receipt is not a scheduler: no upload or retry is initiated on restart. WAVs, notes and the pendant's recordings remain available for explicit recovery. Markdown and JSON replacement are individually atomic, not a multi-file transaction.

The code received a separate static review with no must-fix data-loss regressions found within these changes. Independent writers to one output directory, physical filesystem/power-loss durability, mobile behavior and production backend operation remain outside this verification.

## Earlier baseline — 2026-09-08

On 2026-09-08, `uv run --locked python -m unittest discover -s tests -v` completed **12 tests successfully** on Python 3.12. The tests include five existing transfer/transcription-structure cases and seven maintenance/upload cases.

The upload integration test started an actual loopback HTTP server, sent the JSON contract and bearer header, checked the confirmed note ID, then returned a redirect and verified no redirected request was made. Source WAV hashing is stable across note-title edits. A missing WAV uses a canonical note hash. Unsafe HTTP origins, embedded URL credentials, malformed note arrays and missing upload configuration are rejected.

Maintenance tests confirm that no FORMAT is sent without explicit confirmation and an empty idle STATUS. The accepted request contains exactly `ERAS` and uses the special 600-second timeout. Firmware independently enforces the physical hold and committed tombstones.

`aura --help`, `aura format --help` and `aura upload --help` were exercised. The earlier locally synthesized speech fixture and Whisper transcription smoke result remain under `tests/assets/`.

No physical pendant, radio transfer or deployed Convex backend was exercised by these tests. Live portal integration requires the matching server route and private ingestion credential; it is not silently replaced by a mock in the shipping companion.

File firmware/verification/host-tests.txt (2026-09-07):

PASS CRC IEEE known vector and incremental chaining
PASS record, bookmark, commit, mount and cross-page read
PASS EOF and explicit size/CRC matching tombstone
PASS power loss without end preserves pages and unique next ID
PASS torn page is skipped and prior committed PCM recovered
PASS uncorrectable ECC cannot silently repair recording CRC
PASS factory bad block skipped across recording and replay
PASS full storage reserves END page and never overwrites audio
PASS button bounce, delayed single press and no duplicate event
PASS three second hold does not become record press on release
PASS double press emits one bookmark gesture
PASS dual-microphone mono mix preserves signed range without overflow
PASS maintenance refuses live audio and no erase before durable intent
PASS interrupted erase resumes before mount and restores recording capacity
14 tests passed

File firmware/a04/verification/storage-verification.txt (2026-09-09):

PASS storage 1 durable grant precedes erase; exact retry and retained source survive reboot
PASS storage 2 capture generation committed before binding; cancellation/reset never reuses IDs or formats audio
PASS storage 3 forged/replayed/gapped/nonfinal commands and missing erase capability cannot release
PASS storage 4 260 acknowledged releases recycle bounded catalog while unacknowledged source remains unchanged
PASS storage 5 wrapped multiblock grant fences every extent until durable completion
PASS storage 6 every grant header/body/commit program cut preserves source before committed permission
PASS storage 7 released-block erase cuts resume only the committed fenced set, with no early reuse
PASS storage 8 completion-write cuts preserve unrelated source and never publish an uncertain old floor
PASS storage 9 a coherent newer allocation at an old grant block is never erased
PASS storage 10 private output aliases fail before IO; overwritten input scratch and caller in-place manifests are copied safely
PASS storage 11 provision copies trusted authority before blank-media scans overwrite journal scratch
PASS storage 12 foreign surviving checkpoints/data defeat stale grants despite original, erased or damaged headers and page gaps
PASS storage 13 prepared capture and failed counter/reopen/reload/provision transitions invalidate buffered export without changing retained source
RESULT storage groups=13 cases=745 owner_context=288 journal_context=36048 snapshot_bytes=45408
READY durable receiver authorization required
PASS real storage roundtrip samples=120847 erased_blocks=1 reused_block=1 retained_catalog=2
PASS retained: 120847 samples, SNR 11.919 dB
PASS release: 120847 samples, SNR 11.919 dB
PASS replacement: 120847 samples, SNR 11.919 dB

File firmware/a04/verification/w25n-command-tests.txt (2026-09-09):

Empty-chip startup: 12306 commands, 12383 received bytes, 2048 marker-page loads, 0 payload scans
CONTROL pair: 5 groups PASS; isolated callbacks, real ledger cycles/cold recovery, 8 erase faults
W25N01GV production command core: 25 groups PASS; no physical SPI test
Portable driver context: 4432 bytes

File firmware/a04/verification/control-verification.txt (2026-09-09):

PASS 01 explicit provision, max/empty snapshots, alternating generations, bounded mount
PASS 02 bounds, alias/capacity guards, read-only backend, no non-control erase
PASS 03 all main pages checked before explicit provision; populated/dirty/ECC media never formatted
PASS 04 provision header/body/commit power cuts preserve blank-or-incomplete state
PASS 05 replacement header/body/commit power cuts preserve sole prior snapshot and fail closed
PASS 06 before/every partial-page boundary/after control erases preserve current; fresh erase required
PASS 07 lost program completion resolved once; PFAIL and lost/EFAIL/dirty erase never promoted
PASS 08 six marker bytes/LUT reservations, corrected/uncorrectable ECC, hidden later material
PASS 09 canonical page fields, body header124, generation/domain/parent conflicts and rollover bound
PASS 10 stale-small load canaries, stale store, exact expected digest at final snapshot verification
PASS 11 older-erasure exception requires intact bound commit and no contradictory newer candidate
PASS 12 260 replacements/reopens preserve unrelated source; raw-pair rollback limitation explicit
RESULT {"groups":12,"fault_and_rotation_cases":712,"context_bytes":4272,"guarded_erases":1077}
Independent Python wire/CRC/SHA256 verification passed: F:\circuit\firmware\a04\verification

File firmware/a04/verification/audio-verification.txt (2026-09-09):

Audio adapter deterministic host interleavings: 10 groups PASS, 0 failed; context=21080 bytes
Actual adapter/recorder/Opus/journal code; no physical PDM, DMA or concurrent-thread proof

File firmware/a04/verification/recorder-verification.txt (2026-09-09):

PASS real_recorder mode=0 accepted_source_samples=120847 wire_bytes=37014 state=2 reason=0 close_error=0
PASS real_recorder mode=1 accepted_source_samples=48017 wire_bytes=16082 state=3 reason=-504 close_error=0
PASS real_recorder mode=2 accepted_source_samples=48017 wire_bytes=16082 state=3 reason=-503 close_error=0
PASS real_recorder mode=3 accepted_source_samples=48017 wire_bytes=15627 state=4 reason=-505 close_error=-305
PASS real_recorder mode=4 accepted_source_samples=48017 wire_bytes=16082 state=3 reason=-503 close_error=0
PASS recorder groups=10 recorder_context=3600 external_encoder_arena=32768
PASS clean_stop: 120847 decoded samples, SNR 11.919 dB
PASS queue_overflow: 47960 decoded samples, SNR 12.258 dB
PASS block_gap: 47960 decoded samples, SNR 12.258 dB
PASS source_fault_and_seal_power_cut: 46360 decoded samples, SNR 12.267 dB
PASS missing_final_block: 47960 decoded samples, SNR 12.258 dB

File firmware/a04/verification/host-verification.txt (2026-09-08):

PASS state size/alignment, bad profile/reinit invalidation, empty capture, 10/20ms chunking, repeated commit failure, exact retry, final-tail retry, trim and closed-input tests; opus=libopus 1.6.1-fixed state=15268
{"frame_ms":10,"source_samples":120847,"encoded_samples":120960,"packets":756,"pre_skip":40,"end_trim":73,"encoded_bytes":27365,"max_packet_bytes":61,"state_bytes":15268}
{"frame_ms":20,"source_samples":120847,"encoded_samples":120960,"packets":378,"pre_skip":40,"end_trim":73,"encoded_bytes":26998,"max_packet_bytes":118,"state_bytes":15268}
{
  "status": "host_passed_device_unmeasured",
  "opus_version": "1.6.1",
  "source": "AURA's pre-existing synthetic speech fixture, resampled to mono PCM16 16 kHz",
  "source_sha256": "845096068f1fb6a944ba1aecdb7cc6a1f27d0096a5a78b60b09011c310dbe46e",
  "ffmpeg_version": "ffmpeg version 8.1.1-full_build-www.gyan.dev Copyright (c) 2000-2026 the FFmpeg developers",
  "profiles": [
    {
      "frame_ms": 10,
      "sample_rate": 16000,
      "source_samples": 120847,
      "encoded_samples": 120960,
      "packets": 756,
      "pre_skip": 40,
      "end_trim": 73,
      "encoded_bytes": 27365,
      "max_packet_bytes": 61,
      "host_snr_db": 11.981,
      "ffmpeg_snr_db": 11.982,
      "decoder_agreement_snr_db": 49.938,
      "measured_payload_bitrate": 28984.749,
      "archive_sha256": "e30164d994cdaf47e5e70e0dcfa8591a3947c4e176ee4450acb0a80984915f1a"
    },
    {
      "frame_ms": 20,
      "sample_rate": 16000,
      "source_samples": 120847,
      "encoded_samples": 120960,
      "packets": 378,
      "pre_skip": 40,
      "end_trim": 73,
      "encoded_bytes": 26998,
      "max_packet_bytes": 118,
      "host_snr_db": 11.918,
      "ffmpeg_snr_db": 11.919,
      "decoder_agreement_snr_db": 49.298,
      "measured_payload_bitrate": 28596.026,
      "archive_sha256": "0618514a55ed9fd6aaa8c9f55903413f9f1697fbee68454c5f7b44fef94b49e0"
    }
  ],
  "not_verified": [
    "MCU encode deadline",
    "MCU stack high-water",
    "power",
    "PDM input",
    "durable flash sink",
    "BLE concurrency",
    "physical microphone quality",
    "language/transcription benchmark"
  ]
}

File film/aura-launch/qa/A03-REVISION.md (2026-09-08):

# A03 film revision

Historical record of the original 36-second A03 film, before the context and assembly edition. The current 44-second film and model synchronization are documented in [VERIFICATION.md](VERIFICATION.md). References to the active source and final output below describe that earlier revision.

The active source uses the user's selected capsule direction: glossy black full-face recording paddle, satin silver frame, and fine necklace chain. The original A01 video and complete source are preserved in `../../archive/A01`. The unrendered A02 source draft is preserved in `../../archive/A02-draft`.

The edit has been redesigned beyond plate replacement: profile first, fewer words, slower photographic movement, physical privacy shown in the actual object, and an extended final beauty hold. The illustrated notes surface explicitly identifies the phone-and-cloud architecture. Final development and engineering-validation labeling remains readable.

The source remains 36 seconds at 1920×1080 and 30 fps, using one deterministic paused GSAP timeline. The original local soundtrack is retained. There are no numerical battery, thickness, reliability, availability, or shipping claims.

Status: **Complete.** The corrected detail and profile were rendered from the saved Blender scene without geometry edits, then visually inspected. Final strict Hyperframes validation passes with zero findings. The A03 MP4, poster, captions, and scene overview are delivered, with full decode and visual QA recorded in `VERIFICATION.md`.

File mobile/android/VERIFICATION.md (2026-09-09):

# Android verification — 2026-09-09

The current native A04 app built with **zero Android lint findings**. Its source
storage, playback and foreground recovery suite passed **29 Android runtime
cases / 428 assertions** on an Android 14 / API 34 x86-64 emulator. The nine
local-import and ten durable-download cases are retained; ten new recovery
cases exercise the actual coordinator with scripted logical replies, real
SQLite and the platform decoder.

The final smoke run took 65.355 seconds and binds the same final APKs as both
virtual-link runs below.

The separate virtual Bluetooth suite passed **4 cases / 33 assertions at each of MTU
23 and MTU 517** using the real Android GATT stack and a Python Bumble peripheral through
Netsim. It recovered both original C-generated recordings, decoded them into the
library, and revalidated them on a second connection without duplicate entries.
See the virtual-link evidence below for the exact scope and retained first failure.

The current Kotlin core passes **30 groups / 82,213 checks**, including six
incremental-validator groups / 49,471 checks, seven response-fragment groups /
32,159 checks, seven transfer-wire groups / 338 checks and the complete-archive
checks. It uses 19 complete C-generated archives and rejects an additional raw
prefix. Exact ACK3/Ogg comparisons and independent FFmpeg sample counts pass.
Both file import and partial-download replay now use one canonical validator.

The [earlier local-import checkpoint](https://github.com/Avinash1286/pendent/tree/1a790597da5095423fdada9d86425f1ce4654a62/mobile/android)
and its `a04-android-local-dev` release remain available with their original
nine-case evidence. The current development APK includes the new storage and
protocol classes, [foreground recovery coordinator and Android GATT client](RECOVERY.md). The Activity still exposes local file import. Consumer access requires ownership enrollment, a matching device radio service and Activity integration.

These results cover the source and development APKs identified below. They establish an exercised Android file-import, storage, recovery, and platform-decoding foundation. They do not establish a working physical pendant or a qualified release.

## Evidence map

| Evidence | Observed result and scope |
| --- | --- |
| [Installed toolchain](verification/installed-toolchain.json) | Actual executable versions, SDK package metadata, archive/executable hashes, and usable WHPX acceleration; this installation snapshot alone does not claim app execution. |
| [Runtime emulator boot](verification/emulator-ble-runtime-boot.json) | Separate preserved `AuraApi34Ble`, `emulator-5556`, API 34, observed boot completion and Bluetooth ON. Exact Netsim/VM identity and terminal observations are retained; boot alone is not a test. |
| [Build report](verification/android-build.json) and [build log](verification/build-output.txt) | Both debug APKs built; lint Fatal 0, Error 0, Warning 0, Information 0. Build inputs were unchanged during the build. |
| [Final Android runtime report](verification/android-runtime.json) and [instrumentation output](verification/instrumentation-output.txt) | Both APK installations reported success; 29 cases and 428 assertions passed. The report retains per-case and total execution time. Inputs were unchanged during the test. |
| [Current JVM report](core/verification/kotlin-core.json) and [JVM transcript](core/verification/jvm-host.txt) | 30 groups / 82,213 checks: shared complete/incremental validation, C/Python/Kotlin byte-contract comparisons, actual C command/reply/fragments and independent FFmpeg sample-count validation. No Android decoding or GATT claim from this report. |

The reports retain their exact UTC generation times. The instrumentation transcript contains both `resultdetailJSON.passed=true` and `INSTRUMENTATION_CODE: -1` (`Activity.RESULT_OK`). A zero `adb` process exit code by itself is not the success criterion.

## Environment actually used

The installed environment records Temurin **JDK/Javac 17.0.20.1**, **Gradle 9.4.1**, SDK platform **37.0 revision 2**, build tools **36.0.0**, platform tools **37.0.1**, and emulator **37.1.11**. The app compiles/targets API 37 and has minimum API 29; execution in the current report used the **API 34 default x86-64 system image**. Its official r04 archive advertises revision 4, while its shipped `source.properties` and installed SDK metadata identify revision 2; [the setup record](verification/ble-toolchain.json) preserves that discrepancy and exact archive hashes.

The emulator fingerprint was:

```text
Android/sdk_phone64_x86_64/emu64x:14/UE1A.230829.036.A1/11228894:userdebug/test-keys
```

Boot evidence records WHPX CPU acceleration, SwiftShader graphics, 1,536 MiB RAM, one virtual CPU, and a 480×800 display at 240 dpi. The emulator ran headless with host audio disabled. Windows virtualization settings were not changed by this setup. Successful PCM decoding here is therefore not evidence of audible playback through a phone speaker or headphones.

## Exact build and runtime binding

The build and runtime reports contain the same **57 source/configuration/fixture
hashes**, including the verification runner. Both APK hashes match the build
report and runtime installation entries. The runtime's referenced build-report
digest matches the actual JSON file. The core report separately binds 61 current
source/fixture files before and after its JVM/FFmpeg run. Android's download
fixture copies match the exact owned C archive/physical-receipt files.

The [build report's `artifacts` entries](verification/android-build.json) give both APK byte lengths and SHA-256 values. The [runtime report](verification/android-runtime.json) repeats the installed APK digests and binds the exact build-report bytes through `build_report_sha256`. Use those machine-readable values when comparing a download; the development signing key on another machine can produce different APK bytes.

The retained local-import fixture-index digest is `7c089eaaeb7ad233e36c93138f6c7fd21a93d9adc1592085925dbddf29d7617f`; the new download fixture-index digest is `a160804c8090e09ecd2b13436e27d2ed334b65cdf819b12ad715b3d3882d96cd`. Full source, WAV, log, and verification-script hashes are retained in the machine-readable reports; the table does not replace them.

These hashes bind the observed local build and test run. They are not publisher signatures, device attestation, or a claim that another machine's development signing key will produce identical APK bytes. The APKs use development debug signing, not production release signing.

## What the Android tests exercised

The [instrumentation implementation](app/src/androidTest/kotlin/com/aura/notes/SmokeInstrumentation.kt) used actual Android `ContentResolver`, filesystem synchronization, SQLite, `MediaExtractor`, and `MediaCodec`. It did not substitute fake SQLite or a mocked decoder. A context wrapper redirected only the private files/database namespace to isolated test storage. The test-only content provider served fixed public synthetic fixtures and could not read the user's normal library.

The nine retained local-library cases passed:

1. Immutable C fixture asset identities.
2. Real platform Opus decoding through output EOS and exact WAV durations.
3. Preservation of an existing decoder destination and refusal of incomplete Ogg input.
4. Import through a real content provider into the actual store and SQLite inventory.
5. Idempotent retry and reopening through a fresh store instance.
6. Manual context surviving reopen without changing the original source or immutable bundle evidence.
7. Late physical **OPEN** receipt attachment remaining distinct from the export's derived interrupted seal.
8. Retention of corrupt sources, raw unsealed prefixes, and conflicting proof without publishing a new ready capture.
9. Cold inventory rebuilding from a complete decoded bundle, including refusal to silently downgrade missing known provenance and retention of changed source bytes.

Ten additional download cases passed: exact owned C SELECT/FINISH metadata;
complete-record resume and export; duplicate/conflicting READs; actual SQLite
INSERT/metadata/FINISH ABORT rollback; retained corrupt metadata/records; split
and concatenated row rejection; lifetime ownership and failed-open cleanup;
separate immutable source revisions; premature/conflicting FINISH rejection;
and finalized/OPEN handoff through the real library decoder. The process-owner
guard rejects a second opener before creating another file channel. Tests also
exercise failed file/database construction and stale double-close cleanup.

The recovery cases construct concrete filesystem/database conditions in the
isolated namespace. They are not cross-process contention, process-kill,
kernel-crash, flash-controller or sudden-power-loss tests. Android READ replies
are constructed from exact C exports and passed through `TransferWire`; the
test does not run C firmware over Bluetooth. Original export is checked through
the store API; this does not prove every document-provider UI destination works.

## Actual decoder and trim results

All three current audio fixtures used **`c2.android.opus.decoder`**, which returned mono PCM16 at **48,000 Hz**. The source archives use a 16,000 Hz source clock; retained PCM frame counts were compared at the actual decoder rate. The decoder's applied pre-skip was not removed a second time.

| Fixture | Physical receipt | Raw output frames | Retained frames | App applied remaining end trim |
| --- | --- | ---: | ---: | --- |
| `journal-0` | FINALIZED | 362,760 | 362,541 | Yes: 219 frames |
| `journal-2` | OPEN | 349,320 | 349,320 | No |
| `recorder-1` | INTERRUPTED | 143,880 | 143,880 | No |

The finalized fixture exercises a recording that ends inside its last encoded frame. The OPEN fixture exercises a complete interrupted export whose physical receipt covers only the prefix before its derived seal. Interrupted original duration remains unknown. Full output EOS, WAV shape, nonzero audio, exact retained counts, decoder identity, and resulting WAV hashes were checked or recorded.

These are generated test signals from the portable C fixture writer, not audio captured through an A04 microphone. Passing this specific platform decoder does not qualify every vendor codec, Android version, long recording, storage-pressure condition, or malformed future input.

The new owned finalized and OPEN fixtures also passed `CaptureStore.importDownload`
through `c2.android.opus.decoder` at 48 kHz, preserving 120,847 and 116,440 source
samples respectively. Both became playback-ready; duplicate imports retained a
single library revision. The OPEN recording retained physical status OPEN,
export status INTERRUPTED and unknown original duration. Its SQLite source
remained byte-identical and exportable after library publication.

## Foreground recovery and virtual Bluetooth

The ten coordinator cases cover exact finalized/OPEN recovery, transaction-space
rollover, background cancellation and foreground resume, coalesced wakes,
identity/FINISH mismatch, finite reconnect/catalog budgets, unavailable sources,
source pinning across reconnect and revoked access, resolved failure counts,
and bounded failure when tiny READs cannot advance a complete record. They use
scripted connections; their timings are not radio performance measurements.

The [MTU 517 report](verification/ble-517/verification.json),
[Android transcript](verification/ble-517/instrumentation-output.txt) and
[peripheral report](verification/ble-517/peripheral.json) record four real-GATT
cases / 33 assertions in 36.540 seconds. The first connection transferred
73,674 original bytes using 298 notifications; the second used nine notifications
and no source payload bytes to repeat SELECT, explicit EOF READ and FINISH.
Both source receipts remained exact, including physical OPEN / export INTERRUPTED.
Both connections negotiated MTU 517; the peripheral reported no errors or retries.
Elapsed time includes virtual connection, SQLite and decoding work, and is not a
physical-radio throughput claim.

The [MTU 23 report](verification/ble-23/verification.json),
[Android transcript](verification/ble-23/instrumentation-output.txt) and
[peripheral report](verification/ble-23/peripheral.json) passed the same four
cases / 33 assertions in 36.538 seconds. Both connections negotiated MTU 23.
The first delivered the same 73,674 bytes across 6,985 notifications; the second
revalidated completed sources across 76 notifications without payload reread.
No peripheral errors or exact command retries were observed. These success
runs do not exercise deliberate packet loss, authentication or physical RF.

The Android client did encounter transient setup failures during the second
pass: MTU 517 recorded a command-write failure and a missing-service result;
MTU 23 recorded one command-write failure. Its bounded recovery created four
and three client connection attempts respectively, entered `RETRY_WAIT`, and
then completed both passes. Each peripheral report contains two established
connections. These client reconnects are distinct from exact-command retries
within a connection, whose peripheral counters remained zero. Their cause is
not established by this evidence; the successful recovery does not mean every
connection attempt succeeded.

The virtual peripheral is **Python protocol fixture code**, not the Zephyr
firmware or a real microphone/NAND recording. It permits only the fixed public
synthetic fixture address. It does not implement encrypted ownership enrollment.
The production caller still needs separately trusted enrollment credentials;
HELLO, addresses and bonds are not ownership proof. The runner installs only on
an explicitly selected API33+ emulator, owns its Bumble child, stops it at the
end, and binds the build report, APKs, fixture source and output logs. The
[pinned setup evidence](verification/ble-toolchain.json),
[fixture procedure](ble-fixture/README.md) and [recovery contract](RECOVERY.md)
provide reproduction details.

The [first virtual attempt](verification/recovery-attempt-01/ble-517/verification.json)
failed **before test execution**: Android could not find a separately declared
instrumentation component because the Gradle manifest pipeline replaced its
registration with the configured smoke runner. The associated passing smoke run,
build report and transcripts are retained in that directory. The fixed test APK
uses the registered `SmokeInstrumentation` with explicit `suite=virtualBle`,
delegating to the same Bluetooth checks with the runner's attached context.
The failed attempt is not counted as a transport test or pass.

## Retained first failing attempt

The [first runtime report](verification/android-runtime-attempt-01.json), [first instrumentation transcript](verification/instrumentation-attempt-01.txt), and [associated build report](verification/android-build-attempt-01.json) are retained. That attempt is explicitly **failed**. The direct decoder checks passed, but the real provider/store import case failed with `FileNotFoundException: No content provider` after 109 assertions.

The issue was in the test fixture provider's process/classloader: its Kotlin implementation depended on runtime classes available to the target APK's instrumentation process, but not to the provider's separate test-APK process. The fixture provider was replaced with [Java using Android/Java APIs only](app/src/androidTest/java/com/aura/notes/FixtureProvider.java), retaining its fixed allowlist and read-only `content://` boundary. The production import path was not weakened to accept arbitrary file URIs, and SQLite/MediaCodec were not replaced with test doubles.

Both APKs were rebuilt and reinstalled, and the full suite was rerun. The passing report binds that final source set and those final APKs; the earlier partial pass is not counted as successful store validation.

## Earlier local-import UI smoke check

The [UI smoke record](verification/ui-smoke.json) belongs to the earlier
local-import APK. It records seven real-screen checks with synthetic fixtures:
update/restart preservation, document-picker retry, playback to completion,
keyboard layout, share-sheet payload, exact original export and system Back.
No receiving application was selected. The current change adds no download UI;
that earlier visual record is not a new APK UI test.

The first new import, saved title/context and clipboard copy occurred in the preceding passing build. A small-screen editor issue found during that UI check was then corrected with a scrollable body and resize behavior. The final APK was rebuilt, all nine instrumentation cases passed again, and the affected editor plus the flows above were checked. The [preceding passing runtime](verification/android-runtime-attempt-02.json) is retained alongside the earlier failing provider attempt. The UI record binds each screenshot to its actual APK, including the earlier empty-library image.

These are agent-driven UI observations and byte comparisons, not a claim that a generic UI automation suite or every provider has passed. The [library](verification/android-library.png), [playback](verification/android-playback.png), and [keyboard-open editor](verification/android-context-editor.png) screenshots are actual emulator captures. Returning from another activity can reset the detail scroll position; retaining that position is a remaining UI refinement.

## Limits of this result

No physical pendant, microphone/PDM input, NAND hardware, battery, charging,
privacy-switch timing, PCB fabrication, enclosure fit or wear test is covered.
Virtual GATT uses Android 14 and a Python peripheral; it does not execute the
Zephyr adapter, prove physical-radio reliability or authenticate device ownership.
The Activity still imports selected local archives and does not expose consumer
Bluetooth downloads, automatic transcription, portal sync or background capture.

The earlier API29 storage/playback checkpoint remains available in the
[a04-android-download-dev release](https://github.com/Avinash1286/pendent/releases/tag/a04-android-download-dev).
Current runtime coverage is API34. The new GATT client's API29–32 callback branches,
real app process death, permission/bond transitions, physical out-of-range return,
OEM codecs, long recordings, storage pressure, audio-focus/route changes and broad
phone compatibility remain unqualified. Scripted cancellation tests do not
replace physical disconnect or OS process-kill evidence. Zero lint findings are
not a certification or store-release approval.

## Reproduce and extend

The [app guide](README.md) contains setup prerequisites and build/install instructions. From the repository root, the evidence runner can rebuild both APKs and run lint, then execute the isolated suite on an explicitly selected available target:

```powershell
uv run --project companion --locked python mobile/android/scripts/verify_android.py build
uv run --project companion --locked python mobile/android/scripts/verify_android.py runtime --serial '<device-serial>'
```

The build phase uses `build.ps1 -SkipCore`; run the default `mobile/android/build.ps1` separately when reproducing the JVM/FFmpeg checks too. The runtime phase refuses changed source inputs or APKs relative to its successful build report, installs both development APKs with `adb install -r`, and records the actual result. It does not choose a target implicitly, wipe user data, uninstall an app, or flash device firmware. Preserve previous evidence before replacing a report if comparing runs, and report each platform's actual decoder, sample counts, and remaining limitations.

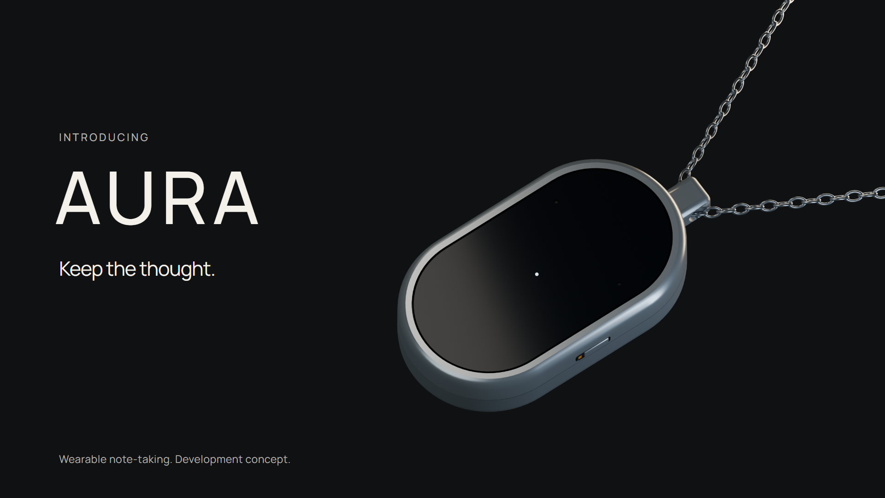
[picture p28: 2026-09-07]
film/aura-launch/qa/a03-preflight/frame-01-at-8.8s.png

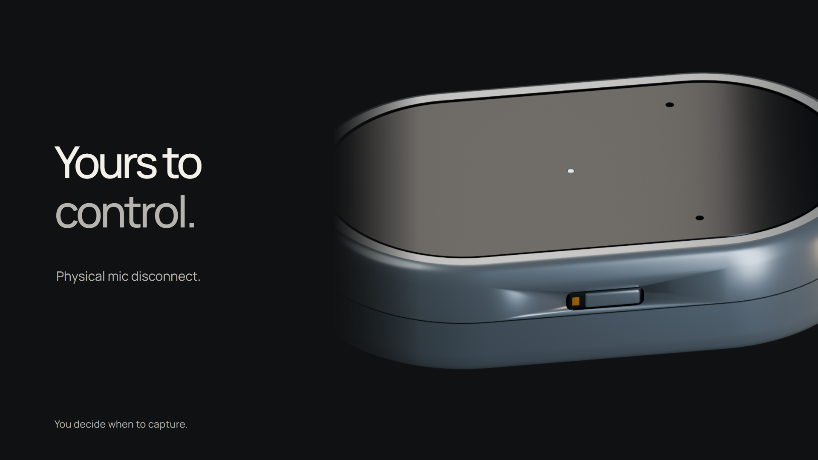
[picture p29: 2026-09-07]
film/aura-launch/qa/a03-preflight/frame-03-at-19.5s.png

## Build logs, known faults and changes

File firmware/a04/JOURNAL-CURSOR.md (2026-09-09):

# Bounded A04 journal export

The [cursor API](include/aura_journal_cursor.h) supplies the storage foundation
for resumable phone transfer. It is a read-only, statically allocated C state
machine over the existing AUR3 journal. It does not implement BLE, phone
enrollment, a durable Android download transaction or source deletion.

## Selection, streaming and completion

`open(cursor, journal, device_and_capture_id)` copies the exact 32-byte identity
from the caller and selects its catalog entry without reading NAND. A catalog
index is never a persistent identity. Active captures, pending capture bindings,
journal faults and unassociated quarantined material deny selection.

Call `verify_step()` until READY. Each call reads at most one NAND page and
replays at most that page's 1980-byte record area. It checks the entire selected
chain, including every remaining data slot, continuation header and checkpoint.
READY binds the exact manifest, independently verified physical ACK3, physical
byte length, v1/v2 allocation identity and expected export length. This is source
verification; nothing has been saved to a phone.

After READY, call `seek()` once with zero or a retained complete-record boundary.
Then call `read()` with a caller-owned buffer of 1–256 bytes. The cursor makes one
linear replay from the beginning, validates the requested boundary against real
records, skips its verified prefix and copies the remaining bytes. A seek into a
manifest, AFR3 or ASE3 fails instead of rounding. Seeking to physical EOF or
export EOF is supported and still performs verification. Records and NAND pages
may span several chunks. The cursor keeps its own bounded page payload; no
returned bytes alias NAND scratch, DMA memory or its internal buffer.

`read()` returns DATA with an absolute offset and length, PENDING with zero
bytes, a negative failure, or zero for FINISHED. **The final DATA response is not
FINISHED.** After replay it checks the selected physical receipt and allocation,
then performs a third complete bounded source scan before returning FINISHED.
This detects source changes behind the replay cursor as well as changes to later
pages. All output remains temporary until FINISHED. The transport must cache its
own immutable command response for retries; calling sequential `read()` again
advances the cursor and is not a command retry.

For a physical OPEN prefix, an interrupted ASE3 is synthesized only in the
export buffer. Its extra 120 bytes do not become NAND data or a physical receipt.
`get_info()` returns the same physical ACK and allocation after completion as at
selection. A derived interrupted export keeps unknown original duration and
never grants release authority.

## Failure and ownership

All calls run under one serialized storage owner. A local capture request must
cancel/preempt the cursor before beginning other work. Journal mount, writes,
preparation, ownership binding and storage ownership/error transitions invalidate
its volatile epoch. The process-wide counter prevents same-address remount from
reusing an epoch; exhaustion fails closed. Idle clock servicing and verification
do not invalidate it. Check the epoch before every step, including draining
buffered bytes and returning cached completion.

Any external media operation must call `aura_journal_invalidate_exports()` before
changing storage. This is not a lock: raw concurrent access, DMA races, malicious
media substitution and unsignalled ownership replacement are outside the API
contract. Three scans do not create an atomic flash snapshot. The future BLE
owner must serialize its operations and invalidate connection handles/cache on
disconnect, cancellation and media transition.

Cancellation and stale handles clear only volatile state. They do not invalidate
a healthy capture or alter its bytes. An actual failed selected-source validation
invalidates its old cached journal receipt, so callers cannot reuse that receipt
as fresh evidence. Invalid seek positions and argument errors confer no rights.

The shared walker preserves the legacy journal's torn-tail rule: one ECC-readable
blank or CRC-invalid tail slot may end an OPEN prefix only if all later slots and
metadata remain consistent. A later valid/nonblank page, contradictory checkpoint
or valid-CRC malformed record fails. The new cursor is deliberately stricter than
legacy salvage: **any unreadable selected-chain slot and any globally unassociated
quarantined block deny successful transfer**. Corrected ECC is accepted and
counted. This does not scan all unowned chip payloads or prove total media health.

## Integration and evidence

The wired DK bench uses this cursor for EXPORT while retaining its existing
request/response format. It remains a synchronous UART command: cooperative
kernel yields do not add wire-level resume, command preemption or BLE scheduling.
The [mobile transport proposal](../../docs/a04/mobile-transport.md) still needs
its command codec, GATT service, authenticated enrollment and Android recovery
coordinator. The separate Kotlin response-fragment parser is not a connected
radio path.

Run the focused cursor host suite with:

```powershell
.tools/zephyr/venv/Scripts/python.exe firmware/a04/scripts/verify_cursor.py
```

Its [report](verification/journal-cursor.json) and
[transcript](verification/journal-cursor-host.txt) bind tested sources and
execution. Eighteen host groups pass, with at most one NAND read per call. The
finalized real Opus fixture exports exactly 37,040 bytes; the OPEN fixture retains
its exact 36,514-byte physical prefix and exports 36,634 bytes with its derived
seal. The cursor uses 3,808 bytes on the host ABI and 3,800 in the actual ARM ELF.
The existing journal/recorder/audio/storage regressions also pass; rerun them
when changing the shared page walker. The separate bench's
[ELF report](bench/verification/arm-resources.json) checks actually linked cursor
functions and allocated objects. Host read counts are operation bounds, not
measured NAND, radio, STOP latency, runtime stack or wearable qualification.

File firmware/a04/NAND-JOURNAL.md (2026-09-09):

# A04 packed NAND journal

Status: **implemented and host-model tested; cross-built for Cortex-M4; not physically tested**. The portable journal connects real Opus 1.6.1 to canonical [AUR3 records](ARCHIVE.md). The W25N01GV command core and Zephyr SPI adapter are compiled alongside it. Existing A03 source and release artifacts remain unchanged.

## Device and ownership contract

The W25N01GV has 1024 blocks, 64 pages per block, 2048 main bytes and 64 spare bytes per page. The adapter uses buffer mode and internal ECC, checks WEL/BUSY/P-FAIL/E-FAIL, verifies full programmed main pages, and reports corrected versus uncorrectable reads. Factory exclusion checks main byte 0 and spare bytes 2048/2049 on **both pages 0 and 1**, with ECC disabled for raw marker inspection, before re-enabling ECC. It reads the A5 bad-block mapping table and reserves both logical and physical endpoints of enabled entries; it does not modify the LUT. See the [manufacturer Rev.R datasheet mirrored by Mouser](https://www.mouser.com/datasheet/2/949/Winbond_Electronics_09072023_W25N01GV_Rev_R_070323-3313374.pdf), sections 7.3, 8.2 and 10.

`aura_w25n01gv_zephyr_init` takes a caller-supplied `spi_dt_spec`. No final board node, chip-select, microphone or GPIO assignment is invented here. One mutex serializes each complete NAND operation, including its cache accesses. Journal/codec/archive calls also require one serialized owner outside an ISR. The owner must establish stable power before cold initialization and bound the SPI transport timeout. Hardware timings and electrical power-cut behavior remain unmeasured.

## Staging and commit boundary

Use the separately named `aura_opus_init_staged` and `aura_archive_begin_staged` initializers with `aura_journal_stage`. Callback success means bounded RAM acceptance. The original durable initializers retain their original callback contract. **A staged archive writer cannot issue a receipt.** The journal replays every accepted canonical record into its own validator; it never copies the outer producer state, which has not yet applied the callback result. This matters when one Opus push emits many records or a capacity flush happens before the current record is appended.

A page becomes committed only after Program Execute completes (or uncertain completion is resolved), a full 2048-byte ECC-readable readback exactly matches, and its expected page CRC is present. The independent replay state at that exact page end then becomes the committed snapshot. A P-FAIL stops the active capture even if bytes happen to match. The page is never reprogrammed. Prior verified pages remain available after reopen and full verification.

Records are packed without crossing pages. Flush triggers are capacity, first audio, explicit flush, the 400 ms service deadline, and a terminal seal. Except for the intentional first-audio page, there is no one-small-Opus-packet-per-page policy. Call `aura_journal_service` once **before** starting a staged producer; an uninitialized service clock is rejected. Continue calling it with monotonic wall milliseconds while recording and paused. The embedding scheduler must guarantee its cadence: this synchronous library cannot force a deadline while its owner is blocked/asleep. A timestamp preceding actual record arrival makes the flush conservative. Input copied into a partial PCM frame, encoder lookahead, pending packets and staged pages may be lost on power failure.

Typical lifecycle:

```c
// Caller-owned bounded objects and correctly aligned encoder arena.
aura_journal_mount(&journal, initialized_nand_io);
// Preparation may be scheduled before a capture; RETRY_PREPARE inspects one
// candidate per call and permits trying another. All return values are checked.
aura_journal_prepare(&journal);
aura_journal_service(&journal, monotonic_ms);
aura_opus_init_staged(&codec, arena, arena_bytes, 20,
                      aura_archive_opus_commit, &writer);
aura_archive_begin_staged(&writer, &new_unique_manifest,
                         aura_journal_stage, &journal);
// Push PCM; preserve consumed/pending semantics. Service while paused too.
aura_opus_finish(&codec, &seal);
aura_archive_finalize(&writer, &seal); // flushes terminal page/checkpoint
// Only the journal can return the physically verified receipt.
aura_journal_receipt(&journal, capture_index, receipt);
```

The snippet omits error branches for readability. Production callers must stop accepting PCM on media-full or an unresolved I/O fault, retain the exact `consumed` count, and use the codec's pending retry route only for retryable staging/preparation failures. An uncertain programmed page is never retried through Program Execute. Reboot always allocates a new ID and block; it does not resume an old Opus encoder or the unused pages of a pre-boot partial block.

## Exact block and page format

All multibyte fields are little-endian; wire bytes never depend on C struct layout. CRC32 is the AUR3 reflected IEEE CRC. Each block belongs to one capture. Page 2 precedes all data writes, and page 63 is last. Each page has at most one program attempt after a successful erase, in increasing order.

| Pages | Role |
|---|---|
| 0–1 | Reserved; never journal-programmed |
| 2 | `A4NH` identity/continuation header |
| 3–62 | Up to 60 `A4ND` packed data pages |
| 63 | `A4NC` checkpoint |

Header/checkpoint metadata occupy the first 256 bytes, with CRC32 at 252; bytes 256–2047 are FF when written. Both start with magic at 0, metadata version 1 or 2 at 4, zero at 5, size 256 at 6, and physical block number at 8. Legacy writing remains version 1 unless the caller explicitly enables an owned profile.

`A4NH`: previous block uint32 at 12 (`FFFFFFFF` for first), part uint32 at 16, starting archive byte offset uint64 at 20, device/capture IDs at 28, exact 68-byte AUR3 manifest at 60, 94-byte preceding committed-state declaration at 128 (all zero for first). Version 1 requires zero bytes 222–251. Version 2 stores a nonzero 16-byte storage incarnation at **222–237**, a nonzero uint64 allocation generation at **238–245**, and zeros at 246–251. The declaration is metadata, never an old-audio receipt.

`A4NC`: part uint32 at 12, valid data-page count uint16 at 16, zero at 18–19, committed archive byte end uint64 at 20, 94-byte page-end declaration at 28. Version 1 requires zeros at 122–251. Version 2 stores the same incarnation at **122–137**, the same allocation generation at **138–145**, and zeros at 146–251. It closes either a full block or a terminal short capture.

`A4ND`: magic at 0, version 1 at 4, zero at 5, header size 64 at 6, physical block uint32 at 8, part uint32 at 12, archive byte offset uint64 at 16, IDs at 24, payload length uint16 at 56, record count uint16 at 58, zero uint32 at 60. The payload at 64 holds up to **1980 bytes** of complete manifest/audio/bookmark/seal records. Unused payload bytes are FF; the last four bytes at 2044 are the CRC over bytes 0–2043. Canonical record CRC, sequence, sample offsets, manifest fields and SHA256-chain/seal semantics are independently replayed.

Version 2 changes only allocation metadata. `A4ND`, AUR3/AFR3/ASE3 and ACK3 remain unchanged. Every header and complete checkpoint of one capture must have the same metadata version, incarnation and allocation generation. Physical block, part and the exact header hash distinguish the individual extents of that allocation. Mixed-version chains, different namespaces/generations and noncanonical reserved bytes are corruption; independently identifying checkpoints still reconcile ownership even when allocation metadata is wrong.

## Owned allocation binding

After mount, a serialized owner can call `aura_journal_set_owned_profile(journal, incarnation)` to enable v2 writing. The namespace is nonzero and cannot change or be disabled until a fresh mount. Selecting the profile reads header/checkpoint prefixes of non-excluded blocks and raises a volatile generation floor from matching readable v2 metadata. It performs no audio scan. Unreadable metadata makes this conservative setup fail rather than inventing a floor.

Before `aura_recorder_start`, the owner calls `aura_journal_bind_capture(journal, exact_manifest68, generation)` with an already durably reserved nonzero generation. Only one binding can be pending. Its manifest is copied, and the next start must match all 68 bytes, not just device/capture IDs. A different valid manifest rejects and discards the binding. Preparation retries retain it; the successful start path consumes it **before the first header program attempt**, even if that attempt fails or loses completion. All continuation blocks then use the same capture generation. `aura_journal_discard_binding` cancels an unused idle binding without resetting the generation guard. Unbound owned starts and reused/lower generations are rejected before source programming.

The journal's volatile floor and observed metadata do not provide durable uniqueness after earlier allocations are erased or unreadable. The external storage owner must reserve generations durably, derive nonrepeating capture IDs, and preserve that reservation across reboot and catalog eviction. The journal does not authenticate the generation or derive IDs itself.

`aura_journal_get_allocation_identity` repeats full source and metadata verification before returning `version`, `owned`, `incarnation` and `allocation_generation`. Version 1 returns `owned=false` and zero allocation fields and is not eligible for an owned-release policy. For version 2, `owned=true` means identifiable allocation metadata only. It is **not deletion authority**, and can describe an open or interrupted prefix whose original duration remains unknown. Authenticated explicit owner release, exact local receipt, finalized-source policy and fenced erase decisions belong to the external controller. No identity result releases unassociated material.

The added state is one profile, one pending 68-byte manifest and scalar generations/flags. There are no added arrays per capture or block. The host context grows by **120 bytes**. The namespace and allocation generation are copied to local scratch during metadata walks, so mixed legacy/v2 inventories remain bounded.

## Mount, recovery and export

Mount validates bounds **1–1024 before indexing** and reads factory/LUT inventory through the initialized backend, plus header/checkpoint prefixes. It never scans all 128 MiB of source audio during startup. A completely factory-good 1024-block portable-model mount performs **2048 reads of 256 bytes = 524288 bytes, zero payload reads, zero programs and zero erases**. These portable counters exclude the adapter's separate raw-marker/LUT command scan. The test with 128 short captures on 129 blocks performs **386 metadata reads / 98816 bytes**, measured from the model, and zero payload reads. Device wall-clock startup is unmeasured.

Physical block order is independent of recording order. Mount collects predecessor claims, then rereads one 256-byte header per reachable owned block to establish each unique contiguous chain. Existing bounded owner/link tables suffice; no extra per-block RAM table or payload scan is added. Duplicate heads or successors, skipped/repeated parts, cycles, foreign predecessors and orphaned parts invalidate the affected captures. The allocator visits at most one full circuit of the block inventory to find a FREE candidate, including blocks below its cursor. This supports wraparound; it does **not** authorize reclamation of populated blocks.

The host regression uses the real writer to fill an unrelated block 2, then write a recording through **3 → 0 → 1**, obeying once-per-page and ascending writes within each block. Reopen performs 12 metadata reads / 3072 bytes across those four blocks; full verification/export preserves the exact 162813 archive bytes and receipt. Twelve deliberately damaged or conflicting chain layouts are refused with zero additional programs or erases. Catalog indices are discovery-local; persistent references must use device/capture IDs.

The corresponding mixed inventory with one v1 capture and a three-block v2 capture performs **18 metadata reads / 4608 bytes**, still with zero payload reads at mount. V2 header/checkpoint identity comparisons add bounded prefix reads. Explicit owned-profile selection adds two prefix reads per non-excluded block; identity retrieval later performs full verification on demand. Legacy-only mount counts above remain unchanged.

Existing entries are `UNVERIFIED` after mount. Neither metadata nor a saved checkpoint can authorize their receipt. Full verification checks every data page in each associated block, including every slot after the first blank, unreadable or torn page; it also checks all continuation headers and terminal checkpoints. A single torn final page can terminate an interrupted prefix. Later nonblank/unreadable material, a valid continuation after a gap, a contradictory record, or a valid checkpoint declaring more committed data than the readable prefix is **corruption**. Corrected ECC is usable and counted; uncorrectable bytes cannot establish a commit.

A valid checkpoint can associate a damaged identity header with a known capture; that capture is marked faulty and export fails. Checkpoint ownership is reconciled on every non-excluded block, including blocks whose headers appear valid. A continuation relabeled as a canonical head for another recording still faults both recordings when its checkpoint identifies the original one. Tests cover increasing and wrapped physical order. An otherwise valid checkpoint with an unknown identity faults its header owner and increments `unassociated_blocks`; unidentifiable candidates remain quarantined. An explicitly interrupted prefix does **not** prove that unassociated blocks contain no additional source audio. They are preserved for a future forensic/recovery tool; no normal finalized capture or deletion authority is inferred from them. This is a stated recovery limit of the bounded port.

`aura_journal_export` first fully verifies, then streams and verifies again. Its destination must stay temporary until success, because a later corrupt page or I/O failure can invalidate earlier emitted bytes. An unsealed physical prefix receives an export-only `ASE3` interrupted seal with original duration unknown. That synthesized seal never changes the local physical-prefix receipt into a terminal NAND receipt. Export failure invalidates the cached verification state.

A header-blank candidate is eligible for erase only after **all 64 main pages** are fully readable and FF. A successful fresh erase and a second full FF check are mandatory, even if an interrupted all-FF program attempt left no visible data. Lost/partial erase completion quarantines the candidate for the current mount; after reboot it is eligible only if the full blank check and a new erase succeed. The adapter applies its own blank-before-erase guard too. At most one candidate is inspected per `prepare` call. No populated or unidentifiable source block is erased.

## Capacity costs and product gap

The fixed catalog holds **128 captures**. One short capture consumes a 128 KiB block until a future reclamation design exists. A 20 ms one-packet capture uses two data pages (first audio, then terminal), one identity and one checkpoint; the **58 unused data pages = 118784 bytes** are stranded, in addition to reserved and metadata capacity. Across 128 such captures, those short tails alone strand **15204352 bytes (14.5 MiB)**; all 128 blocks consume 16 MiB and exhaust the catalog even if 896 physical blocks remain. This cost is intentional and tested, not the finished product's storage policy.

For a full block, 60 × 1980 = **118800 archive bytes** fit before record-boundary padding, out of 131072 main bytes (90.64%). The 7.553 s real speech fixture packs 378 Opus packets plus manifest/bookmark/seal into **22 data pages, 24 total programs, 37040 archive bytes**. It still owns the rest of its final block. Worst-case legal 1275-byte Opus packets require one 1301-byte record per page; tests use that case to cross block boundaries and fill media.

The journal itself has **no populated-block reclamation**, including after host acknowledgement, and no catalog eviction or automatic format. Media-full stops recording and preserves prior audio; verified receipts and export remain available for synchronization. V2 allocation metadata is used by the separate [storage owner](STORAGE.md), which now tests durable authenticated grants, catalog reuse and retained-source preservation on host NAND. The metadata alone is not an erase permission. Production audio-erase integration, enrollment and recovery handling for unassociated material remain outstanding.

## Tested evidence

Run `scripts/build.ps1 -Mode all` with the existing pinned toolchain and FFmpeg. The host model tracks cells, once-per-page attempts across reset, ordering, all six factory markers, remapped exclusions, corrected/uncorrectable ECC, program and erase failures, partial writes/erases and lost completion. Short-capture cuts cover each identity/audio/tail/checkpoint program at seven byte boundaries. Further tests cover first-audio/service/finish flushes, capacity snapshots before producer callback completion, malformed canonical records/padding, gaps with later material, checkpoint claims, damaged continuation identities, unassociated quarantine, no overwrite, media-full and the 128-capture bound.

The current journal suite passes **19 groups**, including 13 v2 metadata/cross-owner corruption cases and **52 v2 program-cut cases** around header/checkpoint identity boundaries. It also verifies exact one-use binding, caller-manifest mutation, preparation retry, stale generation refusal, mixed legacy/v2 reading and identity revalidation after a previously verified checkpoint changes.

[Journal host transcript](verification/journal-host.txt) and [roundtrip evidence](verification/journal-roundtrip.json) bind tested source hashes. The latter runs real Opus through NAND model → power interruption/reopen → AUR3 export → existing Python 3.12 receiver/SQLite restart and replay → independent FFmpeg decode:

| Case | Decoded source samples | Original duration | Local receipt |
|---|---:|---|---|
| Finalized then reboot | 120847 | Exact | Physical terminal |
| Buffered tail lost | 116440 | Unknown | Physical open prefix |
| Partial final-page program | 116440 | Unknown | Physical open prefix |
| Full page, lost completion | 120600 | Unknown | Physical open prefix |
| Finalized across blocks 7 → 0, then reboot | 483388 | Exact | Physical terminal |
| V2 owned allocation across blocks 7 → 0, then reboot | 483388 | Exact | Physical terminal |

The four original cases have 11.919 dB waveform SNR against the available source prefix; both longer wrapped recordings have 12.003 dB. The v2 fixture also exports its two header/checkpoint pairs for independent Python CRC, exact namespace, 64-bit generation, continuation declaration and receipt checks. This is a deterministic regression metric, not perceptual/acoustic qualification. The portable host journal context is **36048 bytes**, including the new volatile export epoch; the test-only sparse NAND model is 666712 bytes and is never part of embedded firmware. The current [wired bench ARM ELF](bench/verification/arm-resources.json) measures the journal at **36008 bytes** and its separate export cursor at **3800 bytes**. The command-level simulator additionally passes **25 groups**, including combined driver/journal and restricted control-pair cases; see [its transcript](verification/w25n-command-tests.txt) and [adapter details](W25N-ADAPTER.md). The 48 KiB codec stack reservation has not been measured on silicon.

The [bounded cursor](JOURNAL-CURSOR.md) shares the same page walker and adds
strict unreadable/unassociated-source rejection, exact-record resume and a third
source-verification pass before completion. Its separate host suite passes
**18 groups**, including byte-identical real Opus exports, all chunk capacities
1–256, allocation/source mutation, canonical manifest binding and late
cancellation. The shared walker now explicitly requires the first physical AUR3
to equal the complete catalog/header manifest. A legacy sink's nonzero callback
result is also tested to propagate exactly, including positive values.

Physical PDM/SPI integration, electrical NAND power failures, encode/storage deadlines, concurrent BLE, mobile lifecycle, authenticated ownership, signed OTA, current/battery measurements, and the complete live/offline context workflows remain unverified. No host file, sparse RAM model, cross-build or command simulator is described as a physically functioning wearable.

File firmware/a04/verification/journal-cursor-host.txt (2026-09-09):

CASE all_chunk_capacities_final_interrupted_open PASS
CASE record_boundary_resume_and_single_linear_replay PASS
CASE wrapped_three_block_chain_maximum_AFR_and_bookmark PASS
CASE exact_device_and_capture_identity_copied_at_open PASS
CASE corrected_ECC_and_every_selected_unreadable_slot PASS
CASE torn_tail_prefix_and_torn_checkpoint_policy PASS
CASE valid_CRC_bad_framing_padding_and_holes PASS
CASE global_unassociated_source_denies_selection_without_read PASS
CASE source_mutation_between_verify_and_export_rejected PASS
CASE third_verify_detects_mutation_of_already_emitted_source PASS
CASE active_capture_epoch_remount_profile_and_binding_preempt PASS
CASE cancel_all_phases_and_argument_bounds_no_NAND_writes PASS
CASE coherent_v2_allocation_mutation_before_replay_and_after_DATA PASS
CASE cancel_and_epoch_preempt_during_third_verify_and_after_DONE PASS
CASE empty_interrupted_and_manifest_only_derived_archives PASS
CASE OPEN_physical_manifest_bound_to_full_header_catalog_manifest PASS
FIXTURE physical_open=0 export_bytes=37040 physical_bytes=37040 Opus_packets=378 exact_file_and_receipt=true
CASE real_Opus_fixture_finalized_export PASS
FIXTURE physical_open=1 export_bytes=36634 physical_bytes=36514 Opus_packets=364 exact_file_and_receipt=true
CASE real_Opus_fixture_physical_OPEN_derived_export PASS
PASS cursor cases=18 checks=27057379 verify_calls=54594 read_calls=188117 max_reads_per_call=1 cursor_bytes=3808 host_model_only=true

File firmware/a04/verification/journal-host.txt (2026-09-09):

MOUNT empty blocks=1024 metadata_reads=2048 read_bytes=524288 payload_reads=0
MOUNT 128_short_captures blocks=129 metadata_reads=386 payload_reads=0 reads_bytes=98816
PASS wrapped_chain 3->0->1 captures=2 metadata_reads=12 payload_reads_at_mount=0 export_bytes=162813 exact_digest_and_receipt=true
PASS conflicting_chains cases=12 no_source_erase=true
PASS reclassified_continuation physical_orders=2 both_owners_faulted=true no_source_erase=true
PASS owned_bindings exact_manifest=true one_use=true legacy_preserved=true durable_reservation_external=true
PASS owned_chain_identity corruption_cases=13 wrapped_order=3->0->1 metadata_reads=18 legacy_crossowners_preserved=true
PASS owned_power_cuts cases=52 header_checkpoint_identity=true no_binding_reuse=true
PASS real_opus_journal mode=0 physical_programs=24 wire_bytes=37040 committed_bytes=37040 source_input_samples=120847 metadata_reads=23 payload_reads=180
PASS real_opus_journal mode=1 physical_programs=22 wire_bytes=36634 committed_bytes=36514 source_input_samples=120847 metadata_reads=23 payload_reads=180
PASS real_opus_journal mode=2 physical_programs=23 wire_bytes=36634 committed_bytes=36514 source_input_samples=120847 metadata_reads=23 payload_reads=180
PASS real_opus_journal mode=3 physical_programs=23 wire_bytes=37011 committed_bytes=36891 source_input_samples=120847 metadata_reads=23 payload_reads=180
PASS real_opus_journal mode=4 physical_programs=88 wire_bytes=147504 committed_bytes=147504 source_input_samples=483388 metadata_reads=30 payload_reads=360
PASS real_opus_journal mode=5 physical_programs=88 wire_bytes=147504 committed_bytes=147504 source_input_samples=483388 metadata_reads=38 payload_reads=480
PASS journal groups=19 journal_context=36048 model_is_host_only=666712

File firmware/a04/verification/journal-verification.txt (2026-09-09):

MOUNT empty blocks=1024 metadata_reads=2048 read_bytes=524288 payload_reads=0
MOUNT 128_short_captures blocks=129 metadata_reads=386 payload_reads=0 reads_bytes=98816
PASS wrapped_chain 3->0->1 captures=2 metadata_reads=12 payload_reads_at_mount=0 export_bytes=162813 exact_digest_and_receipt=true
PASS conflicting_chains cases=12 no_source_erase=true
PASS reclassified_continuation physical_orders=2 both_owners_faulted=true no_source_erase=true
PASS owned_bindings exact_manifest=true one_use=true legacy_preserved=true durable_reservation_external=true
PASS owned_chain_identity corruption_cases=13 wrapped_order=3->0->1 metadata_reads=18 legacy_crossowners_preserved=true
PASS owned_power_cuts cases=52 header_checkpoint_identity=true no_binding_reuse=true
PASS real_opus_journal mode=0 physical_programs=24 wire_bytes=37040 committed_bytes=37040 source_input_samples=120847 metadata_reads=23 payload_reads=180
PASS real_opus_journal mode=1 physical_programs=22 wire_bytes=36634 committed_bytes=36514 source_input_samples=120847 metadata_reads=23 payload_reads=180
PASS real_opus_journal mode=2 physical_programs=23 wire_bytes=36634 committed_bytes=36514 source_input_samples=120847 metadata_reads=23 payload_reads=180
PASS real_opus_journal mode=3 physical_programs=23 wire_bytes=37011 committed_bytes=36891 source_input_samples=120847 metadata_reads=23 payload_reads=180
PASS real_opus_journal mode=4 physical_programs=88 wire_bytes=147504 committed_bytes=147504 source_input_samples=483388 metadata_reads=30 payload_reads=360
PASS real_opus_journal mode=5 physical_programs=88 wire_bytes=147504 committed_bytes=147504 source_input_samples=483388 metadata_reads=38 payload_reads=480
PASS journal groups=19 journal_context=36048 model_is_host_only=666712
PASS finalized_reboot: 120847 decoded samples, SNR 11.919 dB
PASS staged_tail_lost: 116440 decoded samples, SNR 11.919 dB
PASS partial_page_power_cut: 116440 decoded samples, SNR 11.919 dB
PASS lost_program_completion: 120600 decoded samples, SNR 11.919 dB
PASS wrapped_finalized_reboot: 483388 decoded samples, SNR 12.003 dB
PASS owned_v2_wrapped_finalized_reboot: 483388 decoded samples, SNR 12.003 dB

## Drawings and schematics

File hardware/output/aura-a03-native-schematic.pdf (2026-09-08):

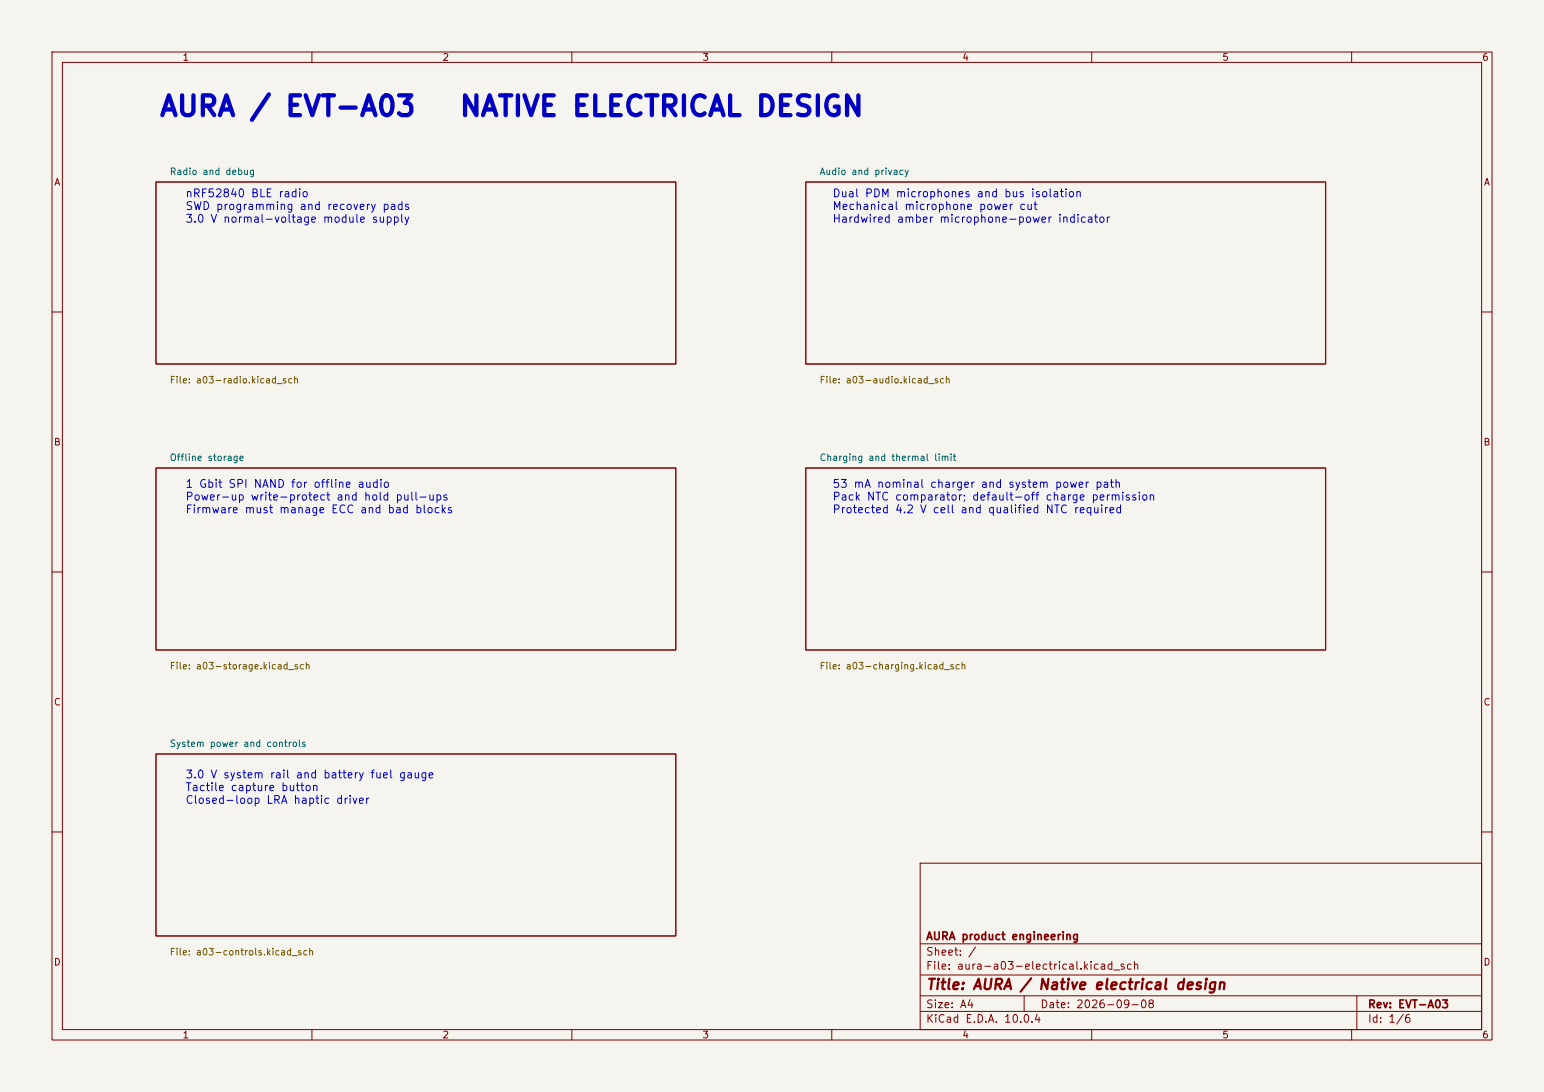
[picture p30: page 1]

Radio and debug
nRF52840 BLE radio
SWD programming and recovery pads
3.0 V normal-voltage module supply

Audio and privacy File: a03-audio.kicad_sch Charging and thermal limit File: a03-charging.kicad_sch
Dual PDM microphones and bus isolation
Mechanical microphone power cut
Hardwired amber microphone-power indicator

File: a03-radio.kicad_sch Offline storage

1 Gbit SPI NAND for offline audio
Power-up write-protect and hold pull-ups
Firmware must manage ECC and bad blocks

53 mA nominal charger and system power path
Pack NTC comparator; default-off charge permission
Protected 4.2 V cell and qualified NTC required

3.0 V system rail and battery fuel gauge
Tactile capture button
Closed-loop LRA haptic driver

AURA product engineering
Sheet: /
File: aura-a03-electrical.kicad_sch
Title: AURA / Native electrical design

Size: A4 | Rev: EVT-A03
KiCad E.D.A. 10.0.4 | Id: 1/6

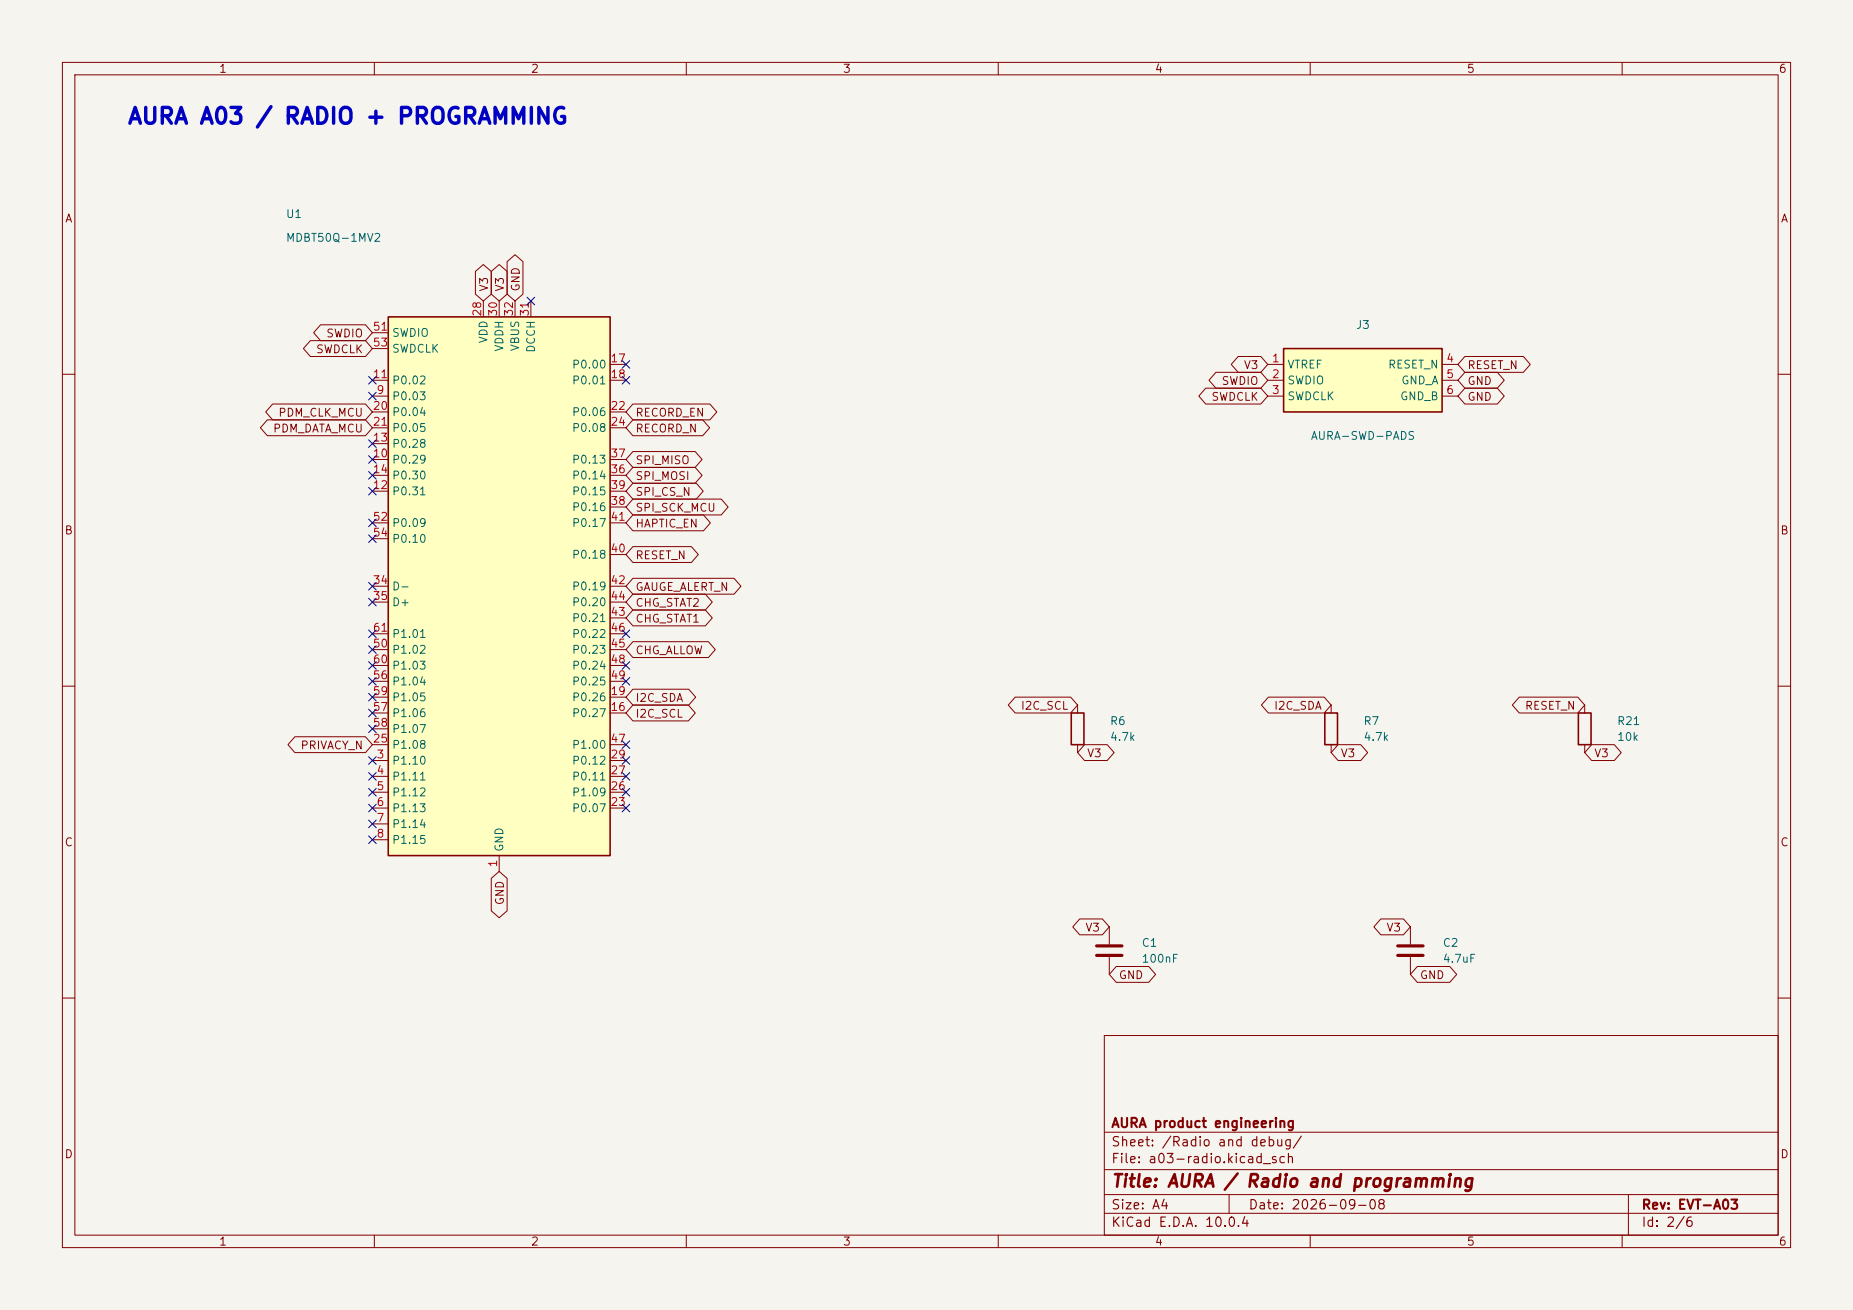
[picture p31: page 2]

1 P1.10 3 P1.11 4 P1.12 5 P1.13 6 P1.14 7 P1.15 8 P0.03 9 P0.29 10 P0.02 11 P0.31 12 P0.28 13 P0.30 14 P0.27 16 P0.00 17 P0.01 18 P0.26 19 P0.04 20 P0.05 21 P0.06 22 P0.07 23 P0.08 24 P1.08 25 P1.09 26 P0.11 27 VDD 28 P0.12 29 VDDH 30 DCCH 31 VBUS 32 D- 34 D+ 35 P0.14 36 P0.13 37 P0.16 38 P0.15 39 P0.18 40 P0.17 41 P0.19 42 P0.21 43 P0.20 44 P0.23 45 P0.22 46 P1.00 47 P0.24 48 P0.25 49 P1.02 50

AURA product engineering
Sheet: /Radio and debug/
File: a03-radio.kicad_sch
Title: AURA / Radio and programming

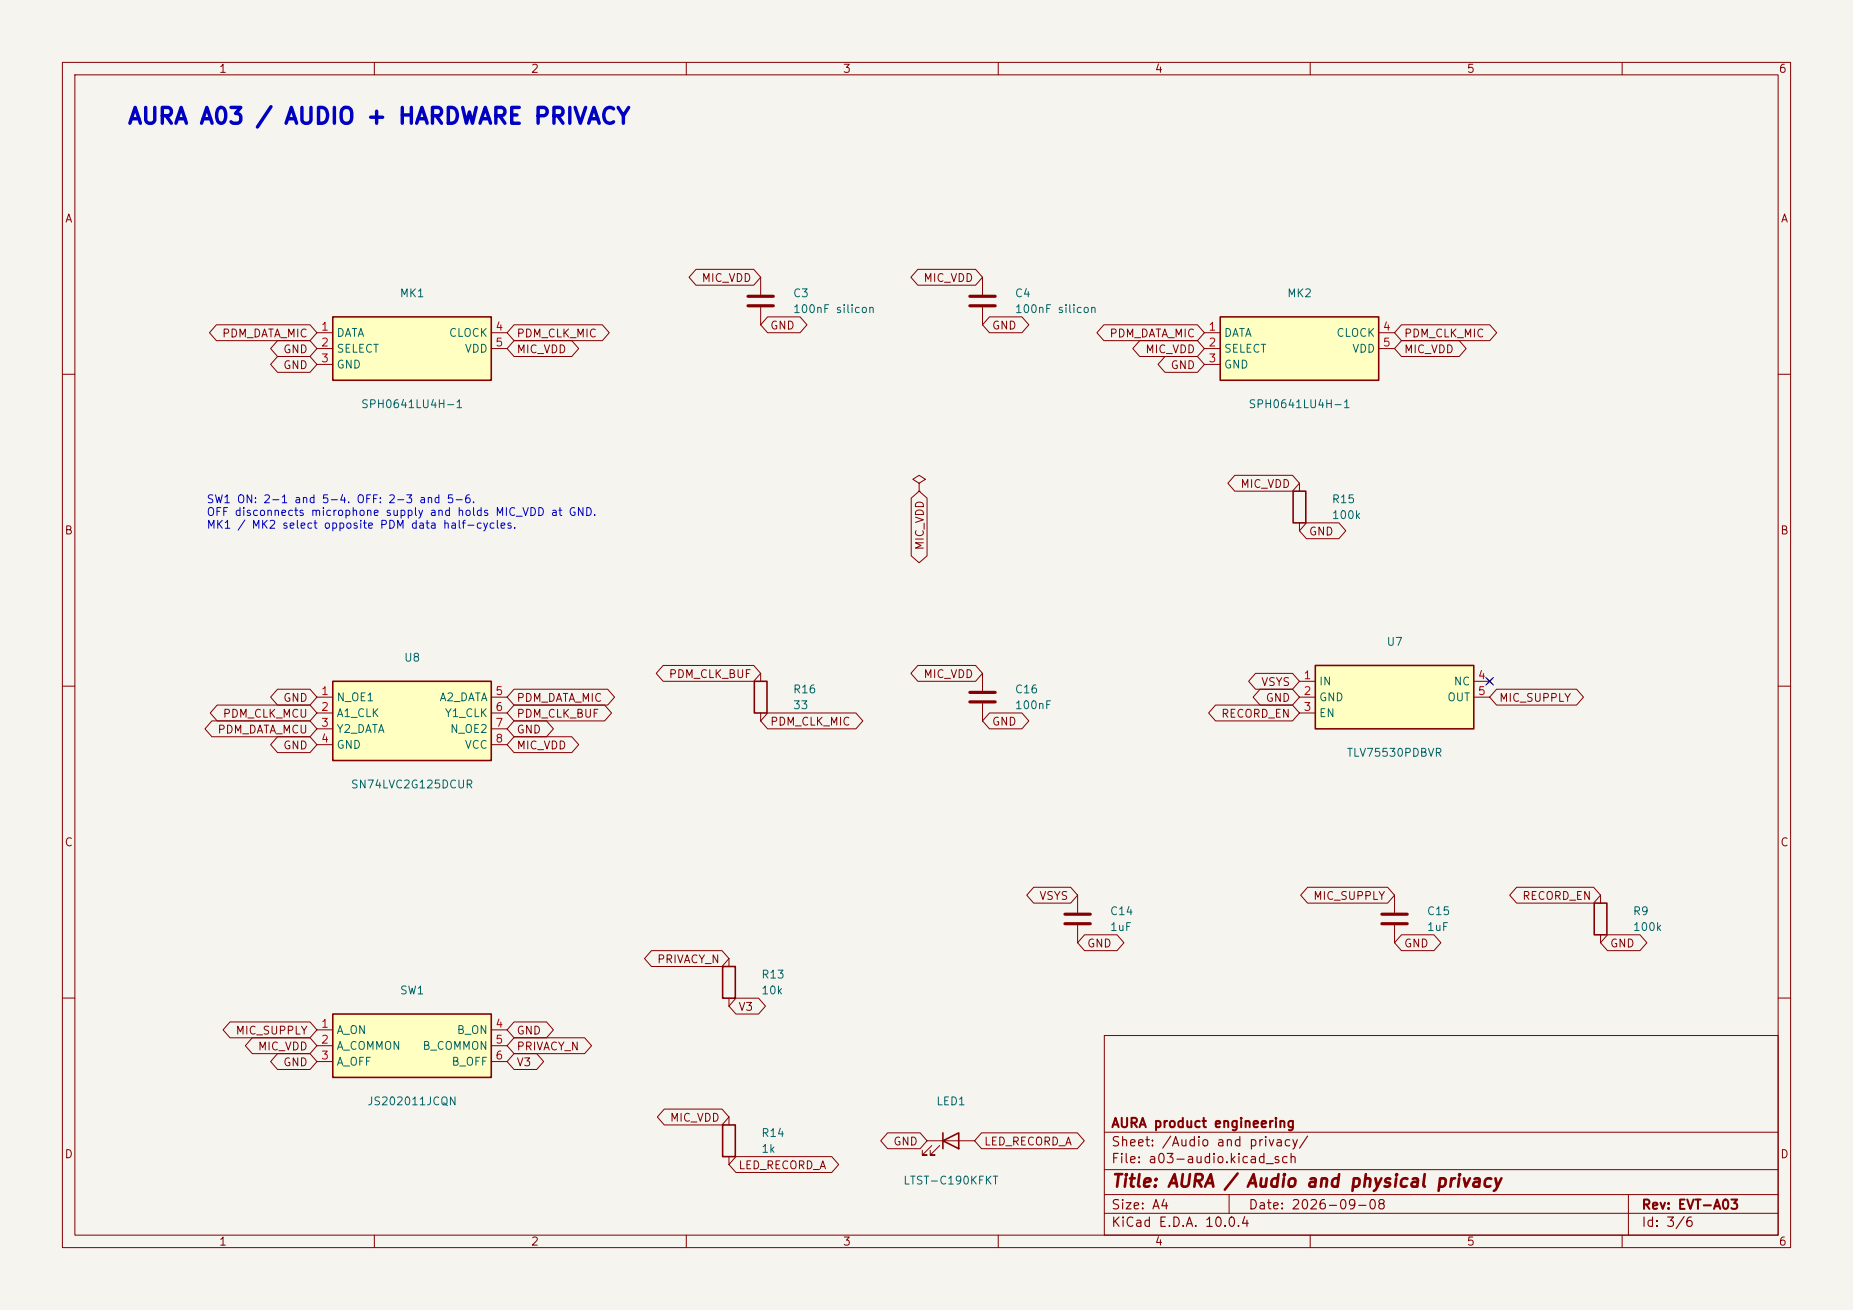
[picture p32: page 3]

PRIVACY_N AURA A03 / AUDIO + HARDWARE PRIVACY

SW1 ON: 2-1 and 5-4. OFF: 2-3 and 5-6. OFF disconnects microphone supply and holds MIC_VDD at GND. MK1 / MK2 select opposite PDM data half-cycles.

AURA product engineering
Sheet: /Audio and privacy/
File: a03-audio.kicad_sch
Title: AURA / Audio and physical privacy

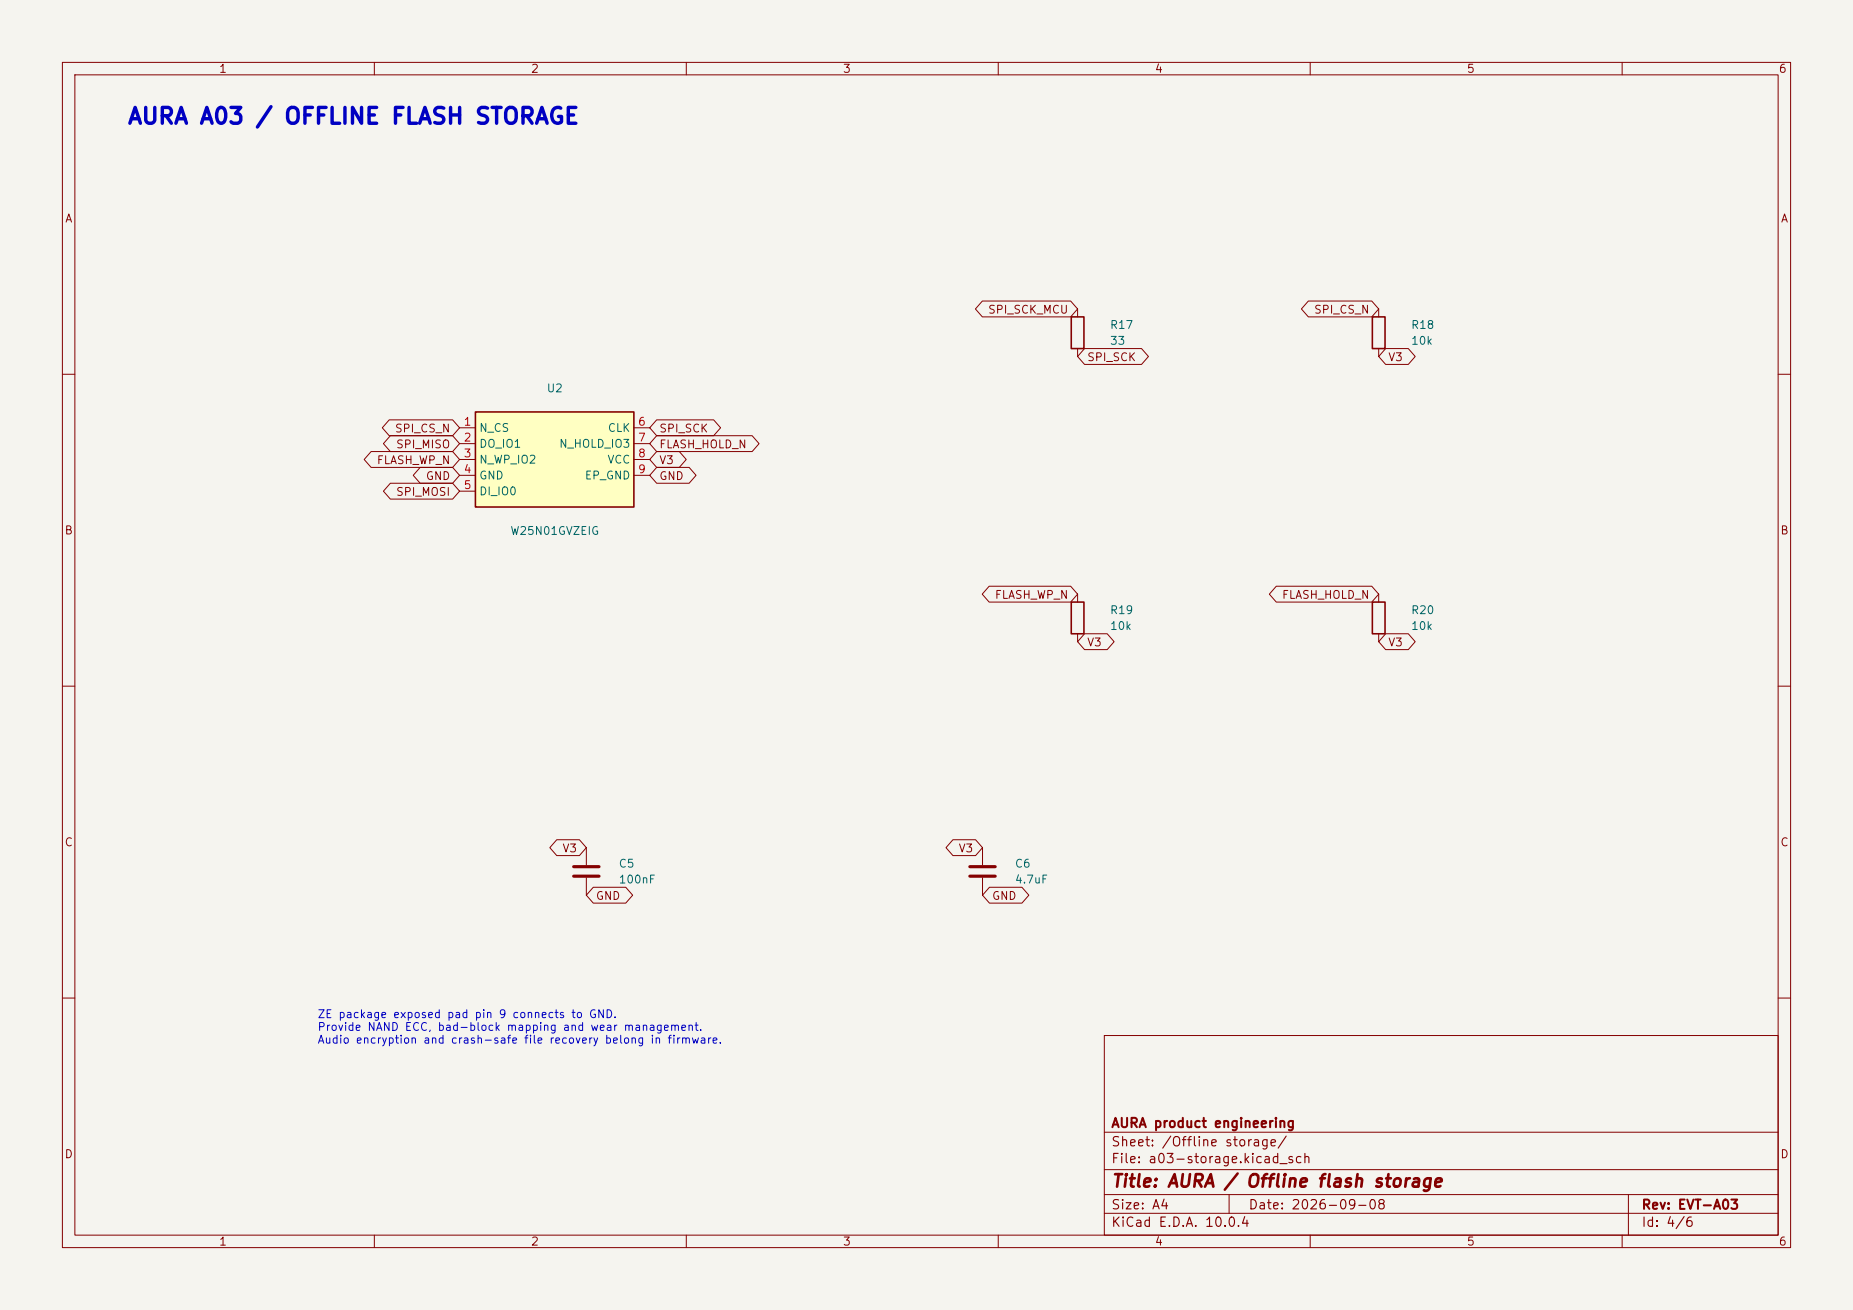
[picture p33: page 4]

ZE package exposed pad pin 9 connects to GND. Provide NAND ECC, bad-block mapping and wear management. Audio encryption and crash-safe file recovery belong in firmware. AURA A03 / OFFLINE FLASH STORAGE

AURA product engineering
Sheet: /Offline storage/
File: a03-storage.kicad_sch
Title: AURA / Offline flash storage

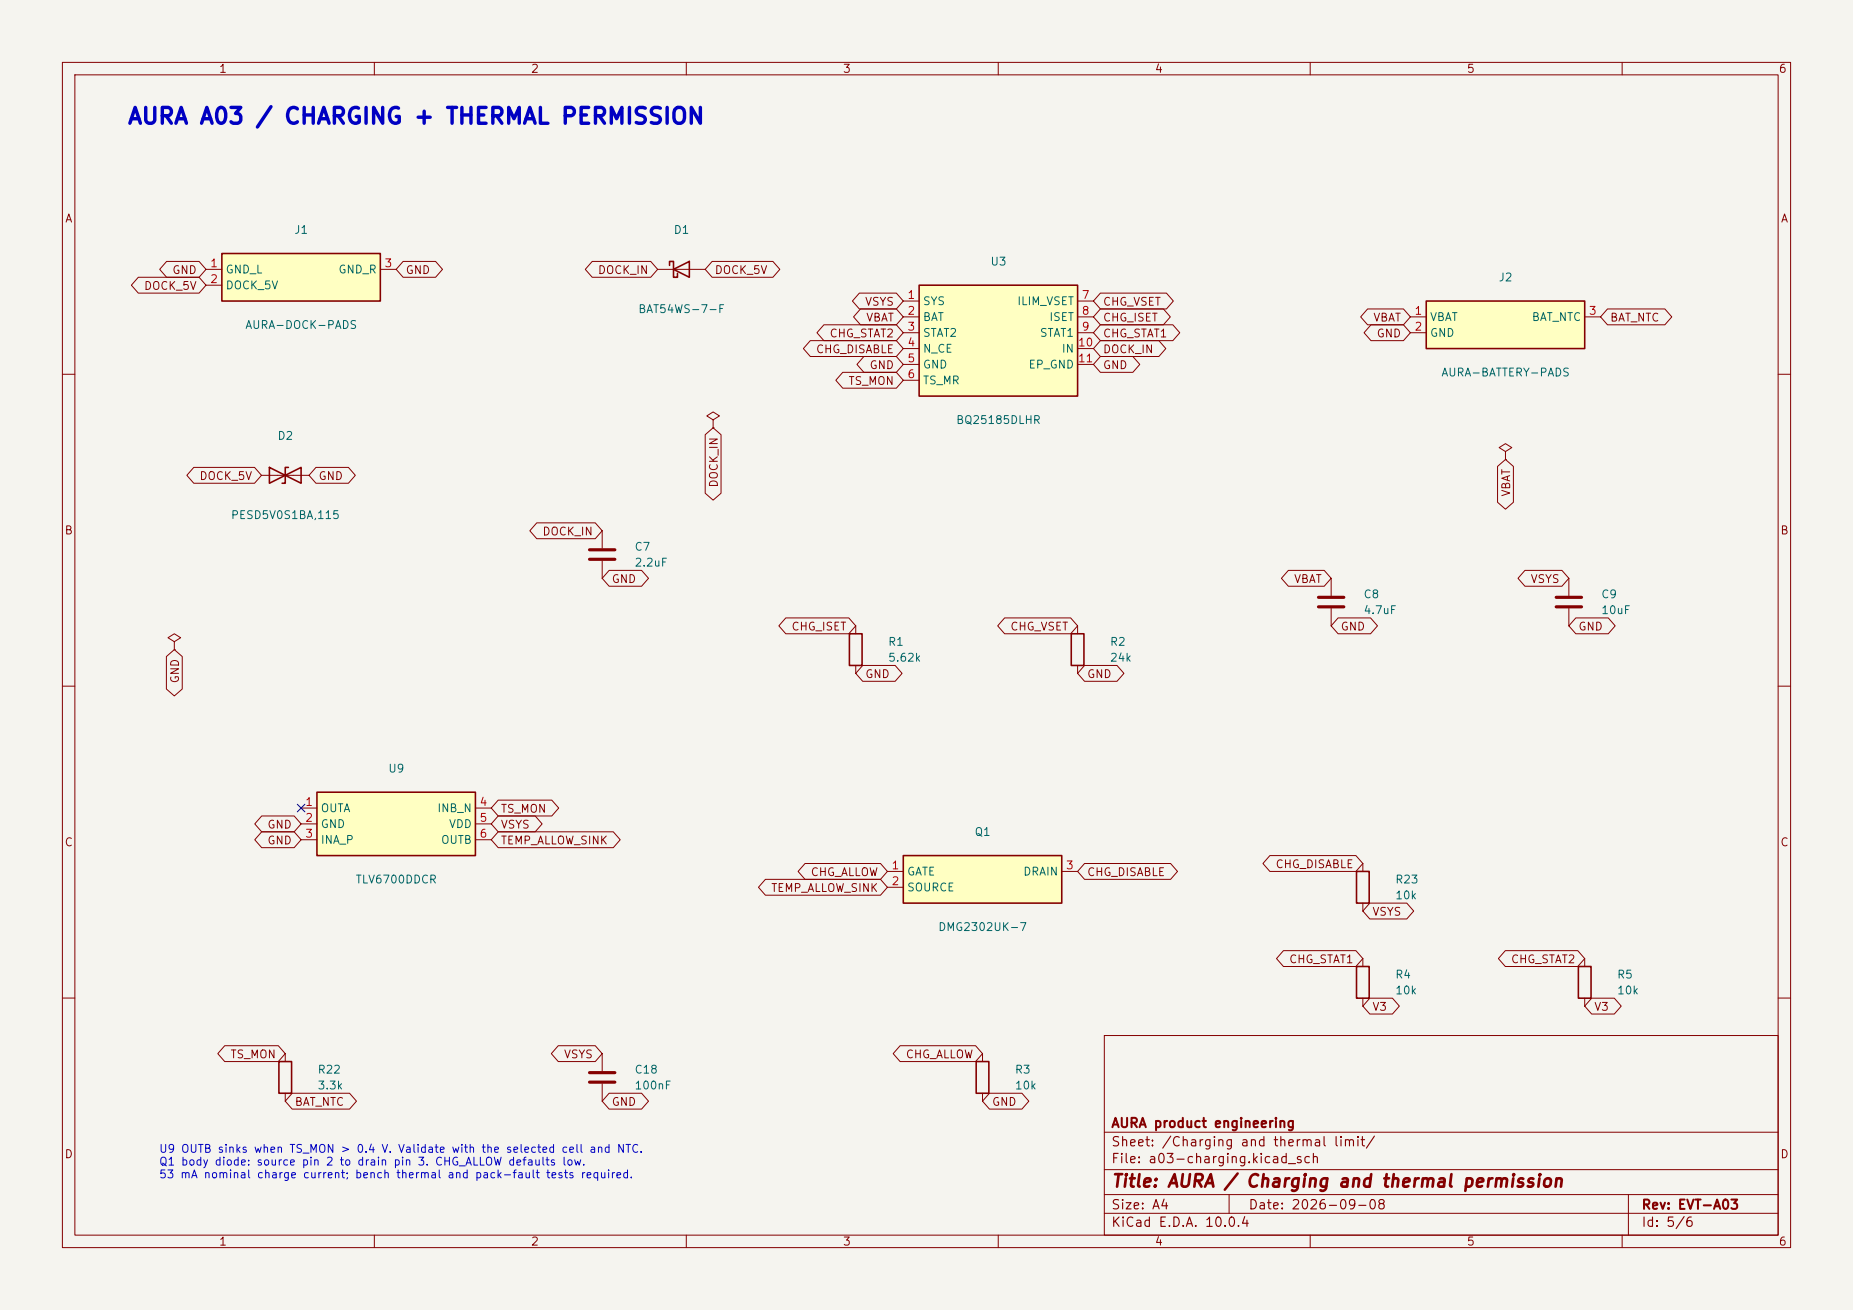
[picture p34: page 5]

AURA A03 / CHARGING + THERMAL PERMISSION

GND U9 OUTB sinks when TS_MON > 0.4 V. Validate with the selected cell and NTC. Q1 body diode: source pin 2 to drain pin 3. CHG_ALLOW defaults low. 53 mA nominal charge current; bench thermal and pack-fault tests required.

AURA product engineering
Sheet: /Charging and thermal limit/
File: a03-charging.kicad_sch
Title: AURA / Charging and thermal permission

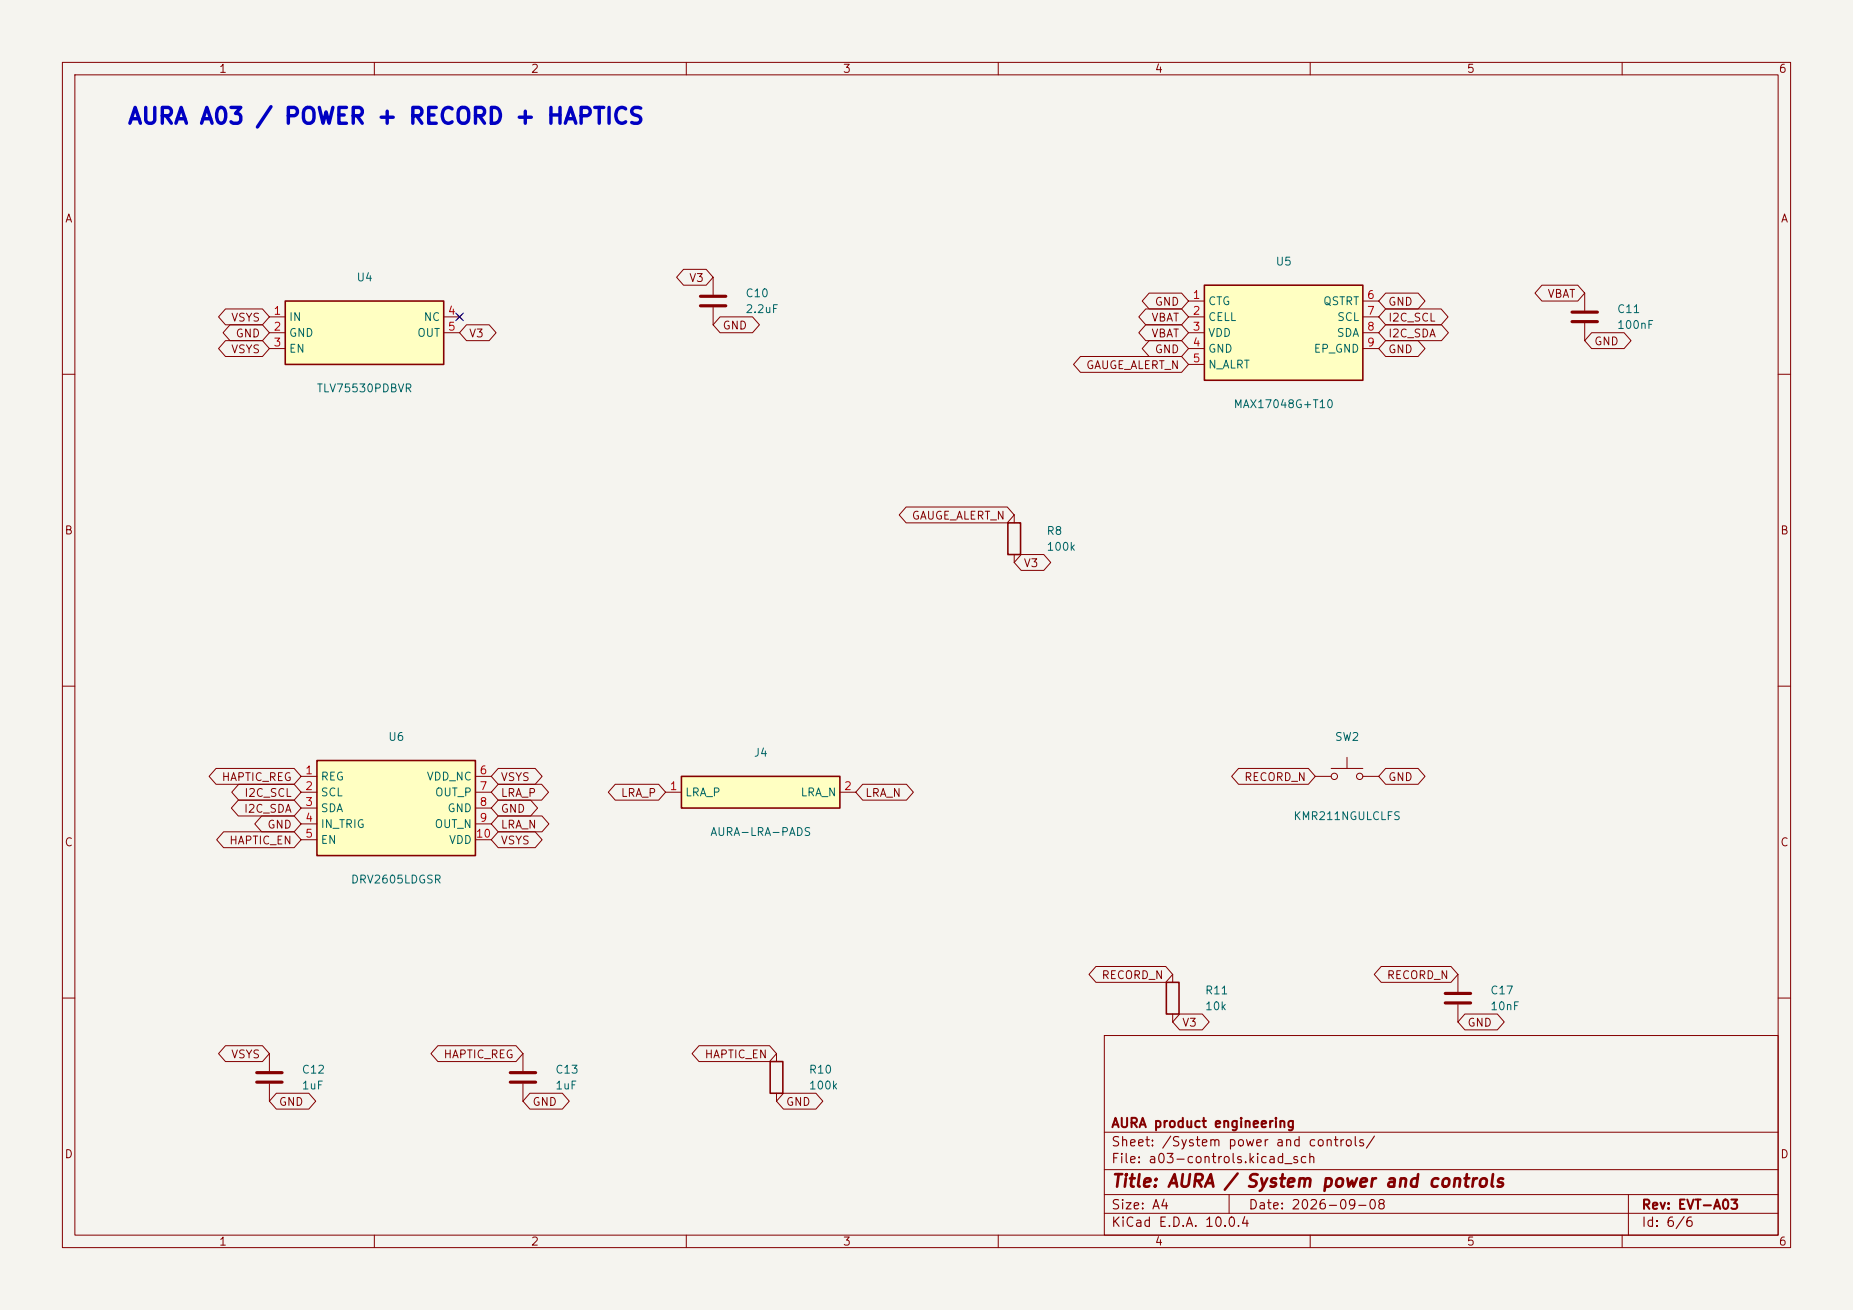
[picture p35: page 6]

AURA A03 / POWER + RECORD + HAPTICS

AURA product engineering
Sheet: /System power and controls/
File: a03-controls.kicad_sch
Title: AURA / System power and controls

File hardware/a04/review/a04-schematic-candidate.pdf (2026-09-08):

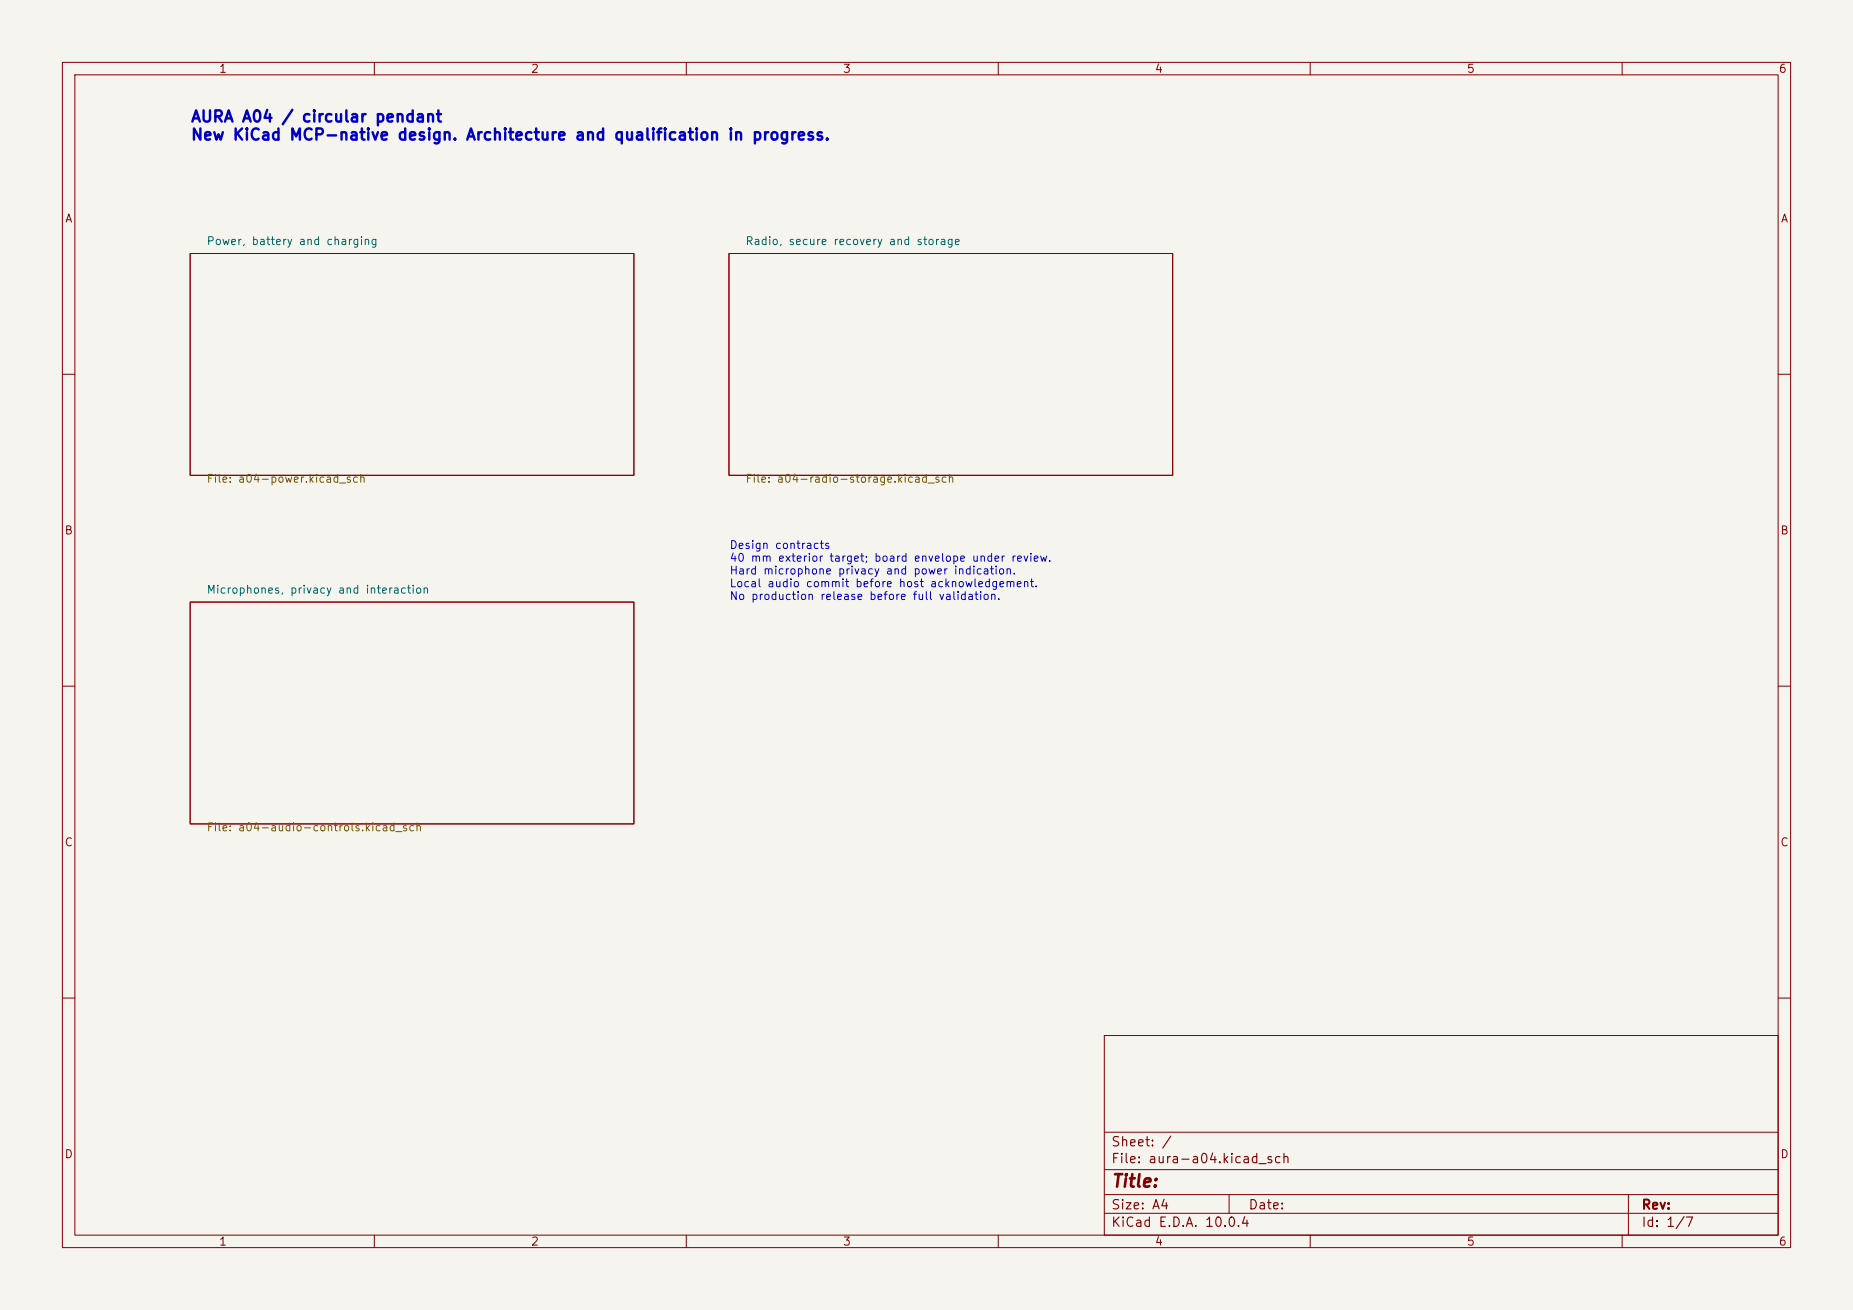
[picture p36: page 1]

AURA A04 / circular pendant
New KiCad MCP-native design. Architecture and qualification in progress.

Power, battery and charging

Radio, secure recovery and storage

Design contracts 40 mm exterior target; board envelope under review. Hard microphone privacy and power indication. Local audio commit before host acknowledgement. No production release before full validation.

Microphones, privacy and interaction

Size: A4 | Rev:
KiCad E.D.A. 10.0.4 | Id: 1/7

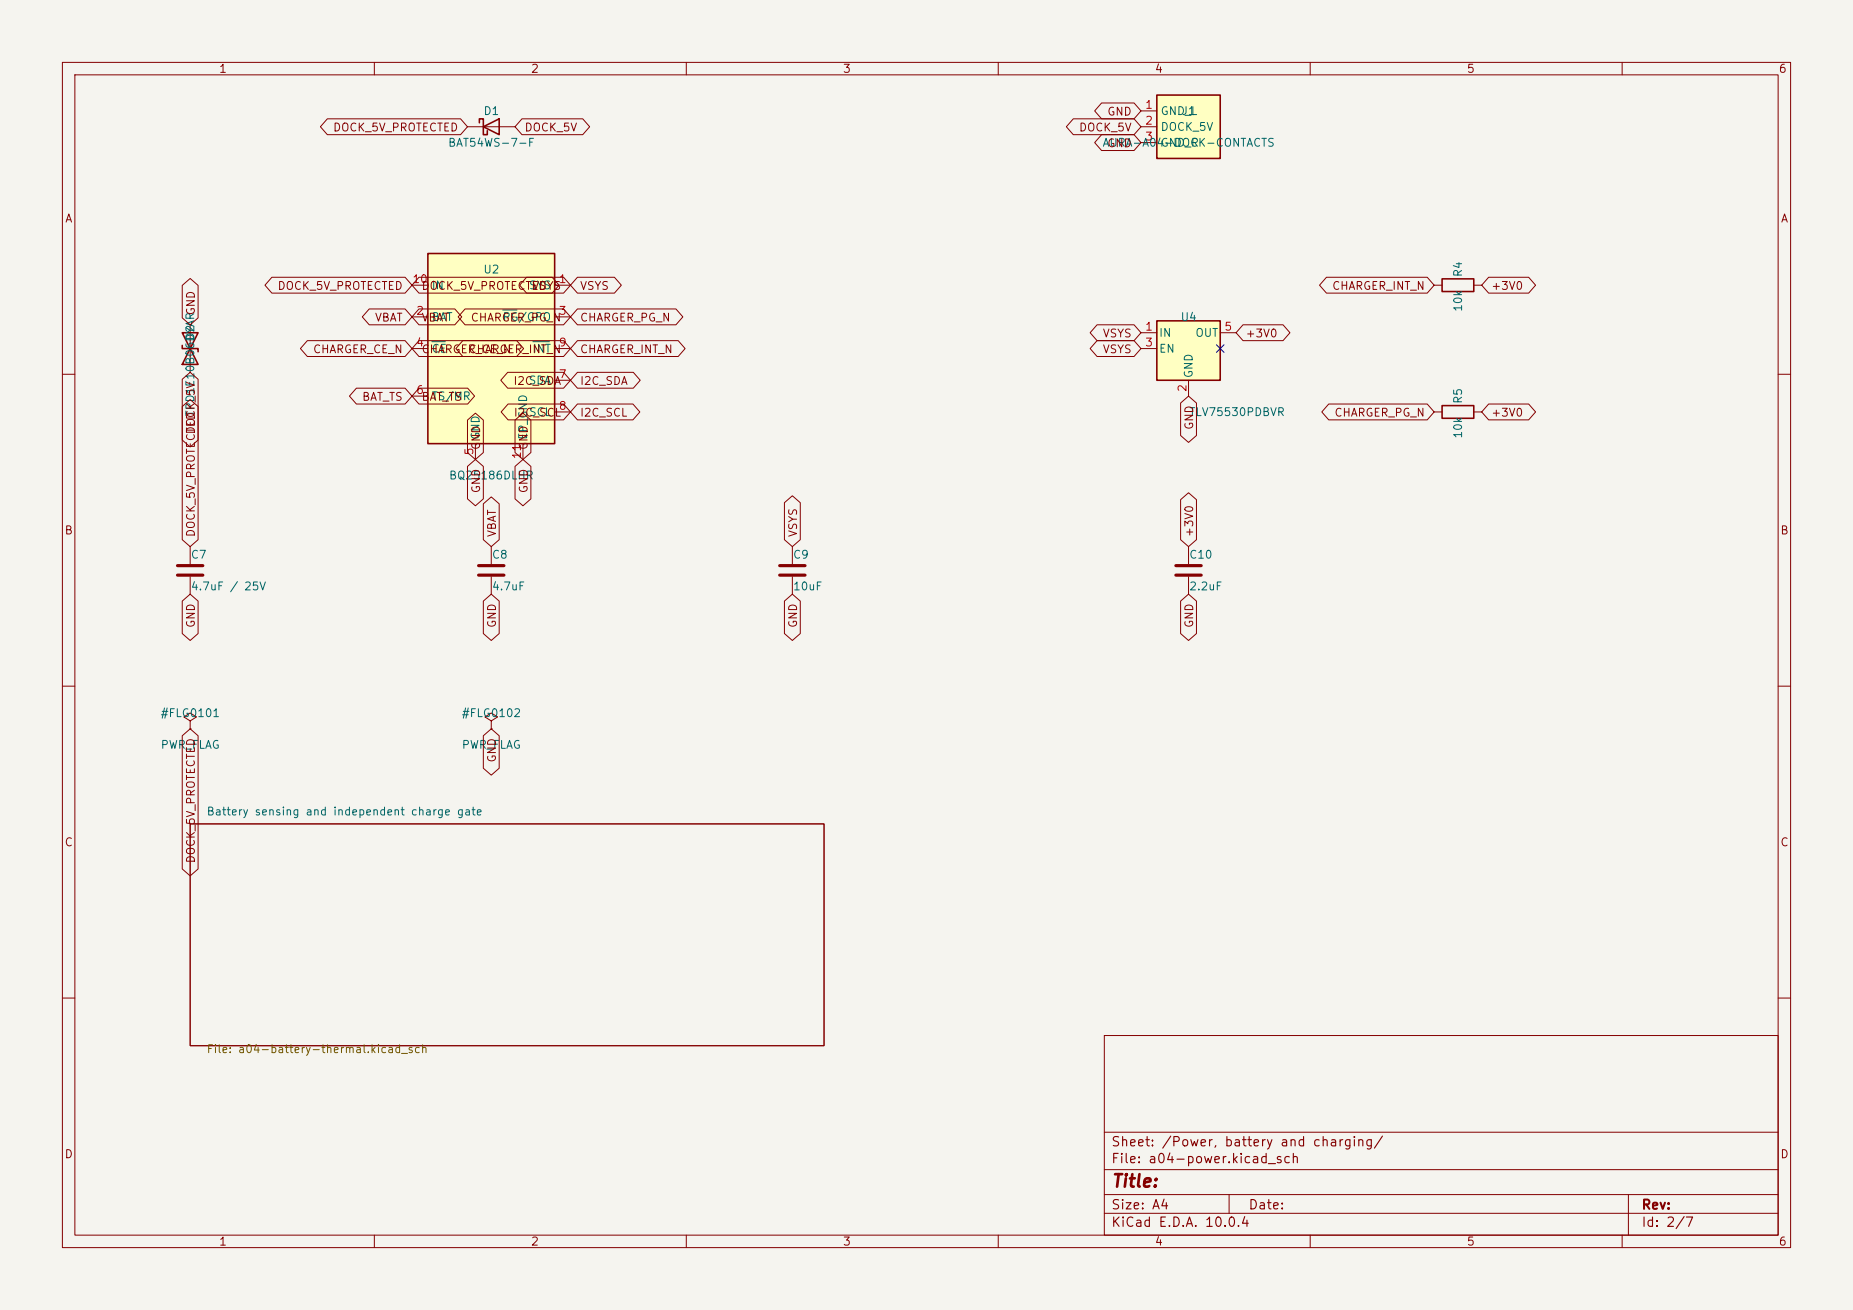
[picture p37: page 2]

Battery sensing and independent charge gate

Sheet: /Power, battery and charging/
File: a04-power.kicad_sch
Title:

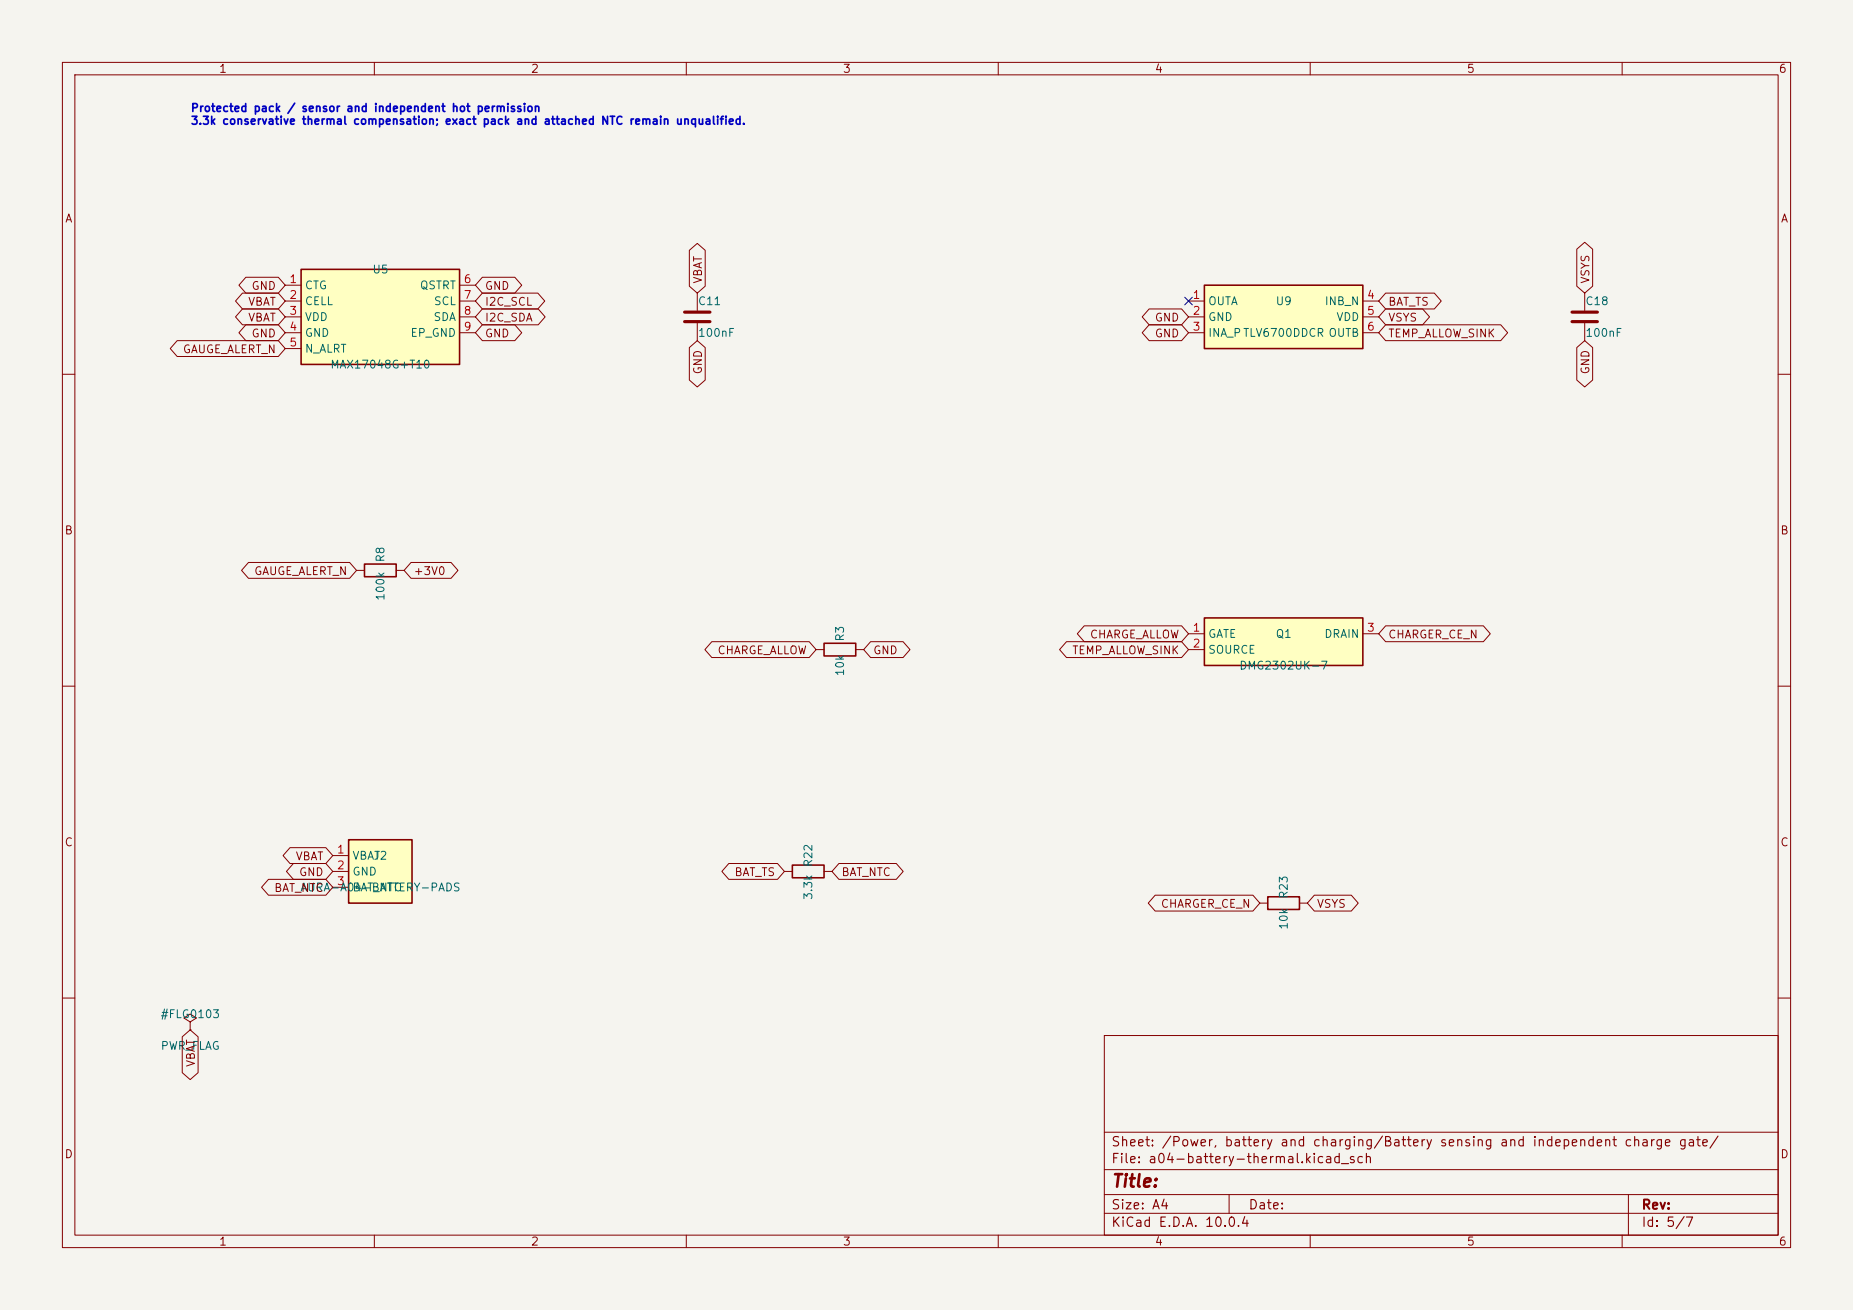
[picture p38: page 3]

I2C_SCL Protected pack / sensor and independent hot permission 3.3k conservative thermal compensation; exact pack and attached NTC remain unqualified.

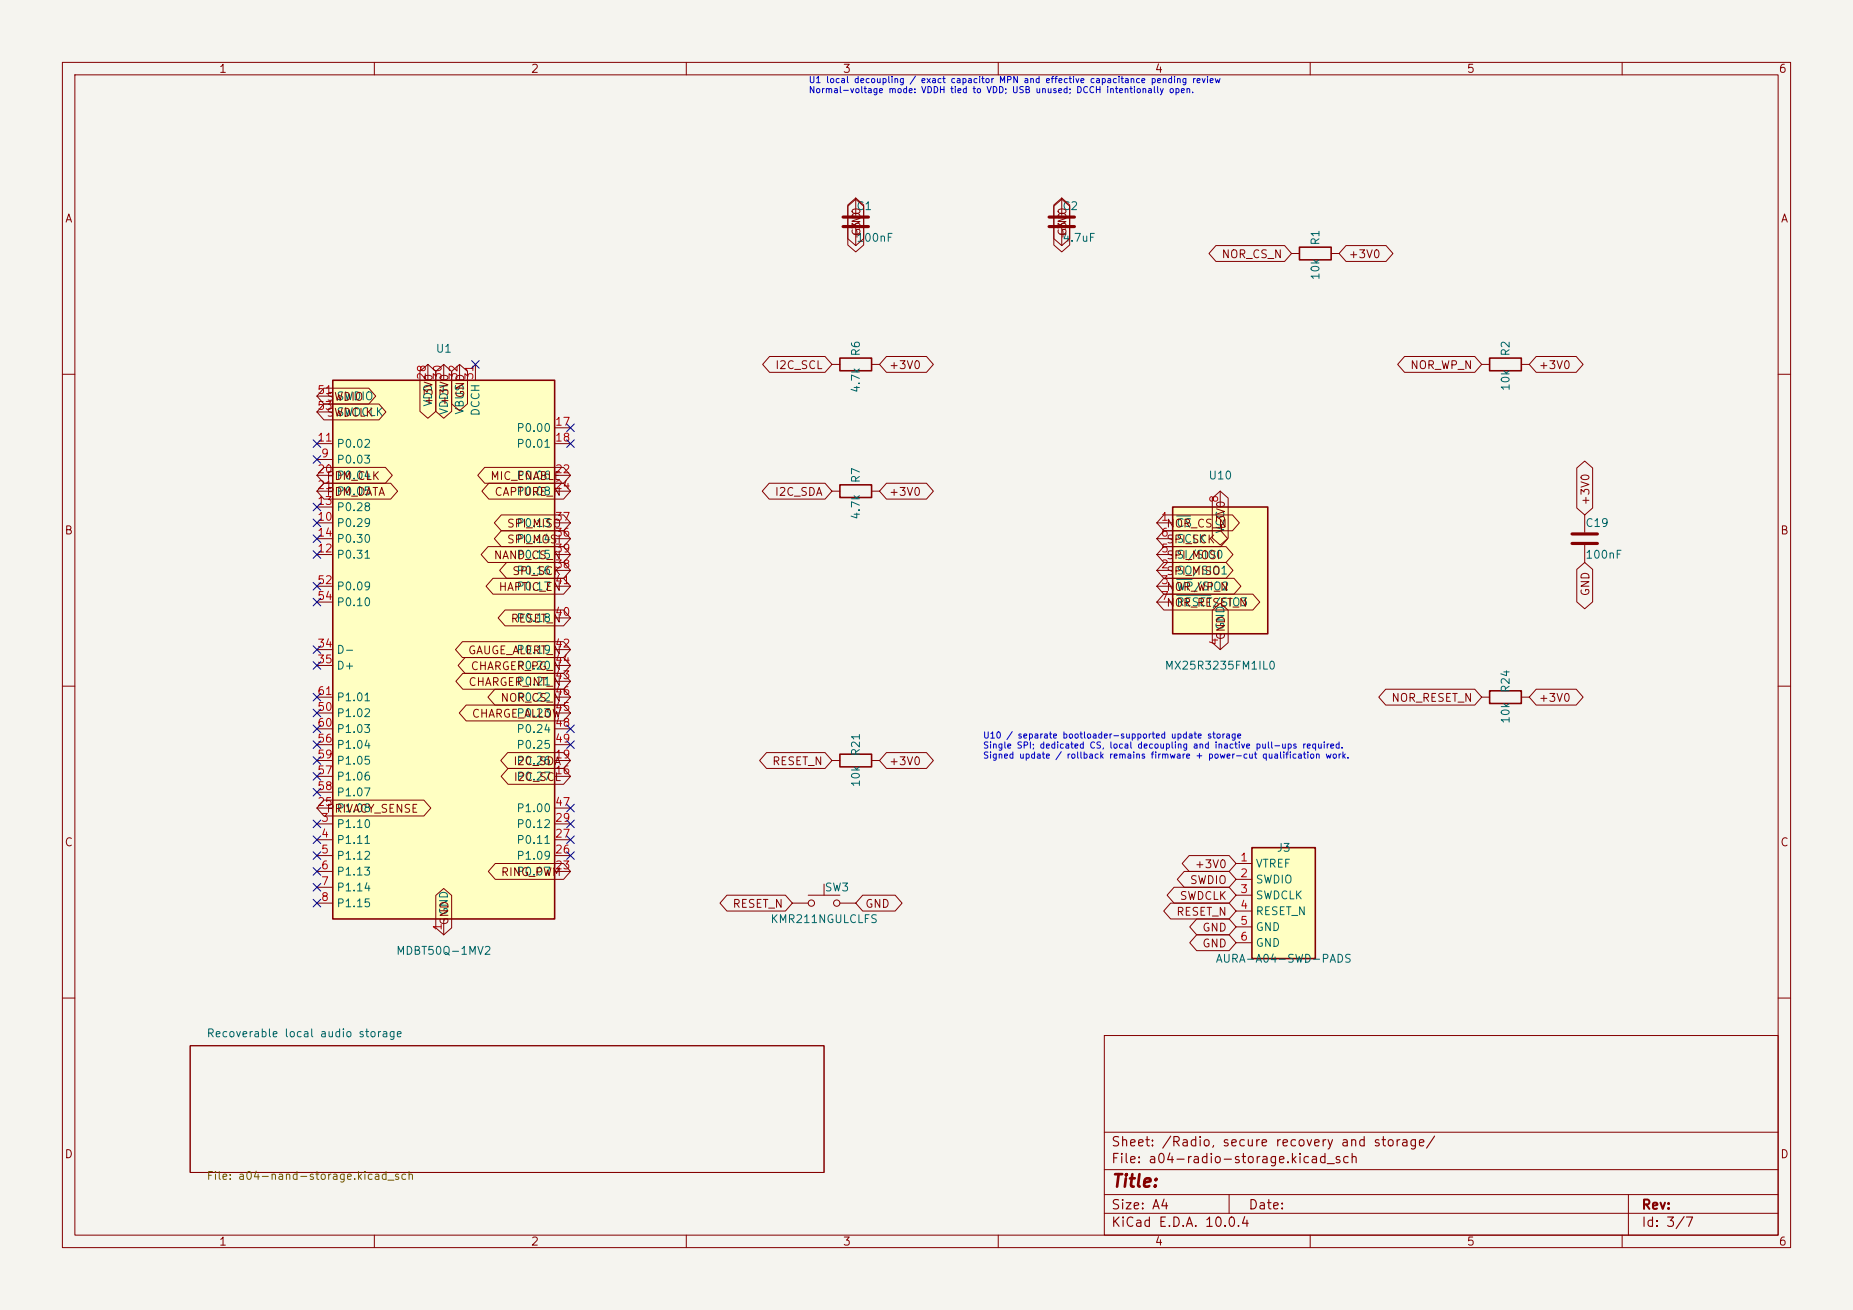
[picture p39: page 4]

U1 local decoupling / exact capacitor MPN and effective capacitance pending review
Normal-voltage mode: VDDH tied to VDD; USB unused; DCCH intentionally open. U10 / separate bootloader-supported update storage Single SPI; dedicated CS, local decoupling and inactive pull-ups required. Signed update / rollback remains firmware + power-cut qualification work.

1 P1.10 3 P1.11 4 P1.12 5 P1.13 6 P1.14 7 P1.15 8 P0.03 9 P0.29 10 P0.02 11 P0.31 12 P0.28 13 P0.30 14 P0.27 16 P0.00 17 P0.01 18 P0.26 19 P0.04 20 P0.05 21 P0.06 22 P0.07 23 P0.08 24 P1.08 25 P1.09 26 P0.11 27 VDD 28 P0.12 29 VDDH 30 DCCH 31 VBUS 32 D- 34 D+ 35 P0.14 36 P0.13 37 P0.16 38 P0.15 39 P0.18 40 P0.17 41 P0.19 42 P0.21 43 P0.20 44 P0.23 45 P0.22 46 P1.00 47 P0.24 48 P0.25 49 P1.02 50

Recoverable local audio storage

Sheet: /Radio, secure recovery and storage/
File: a04-radio-storage.kicad_sch
Title:

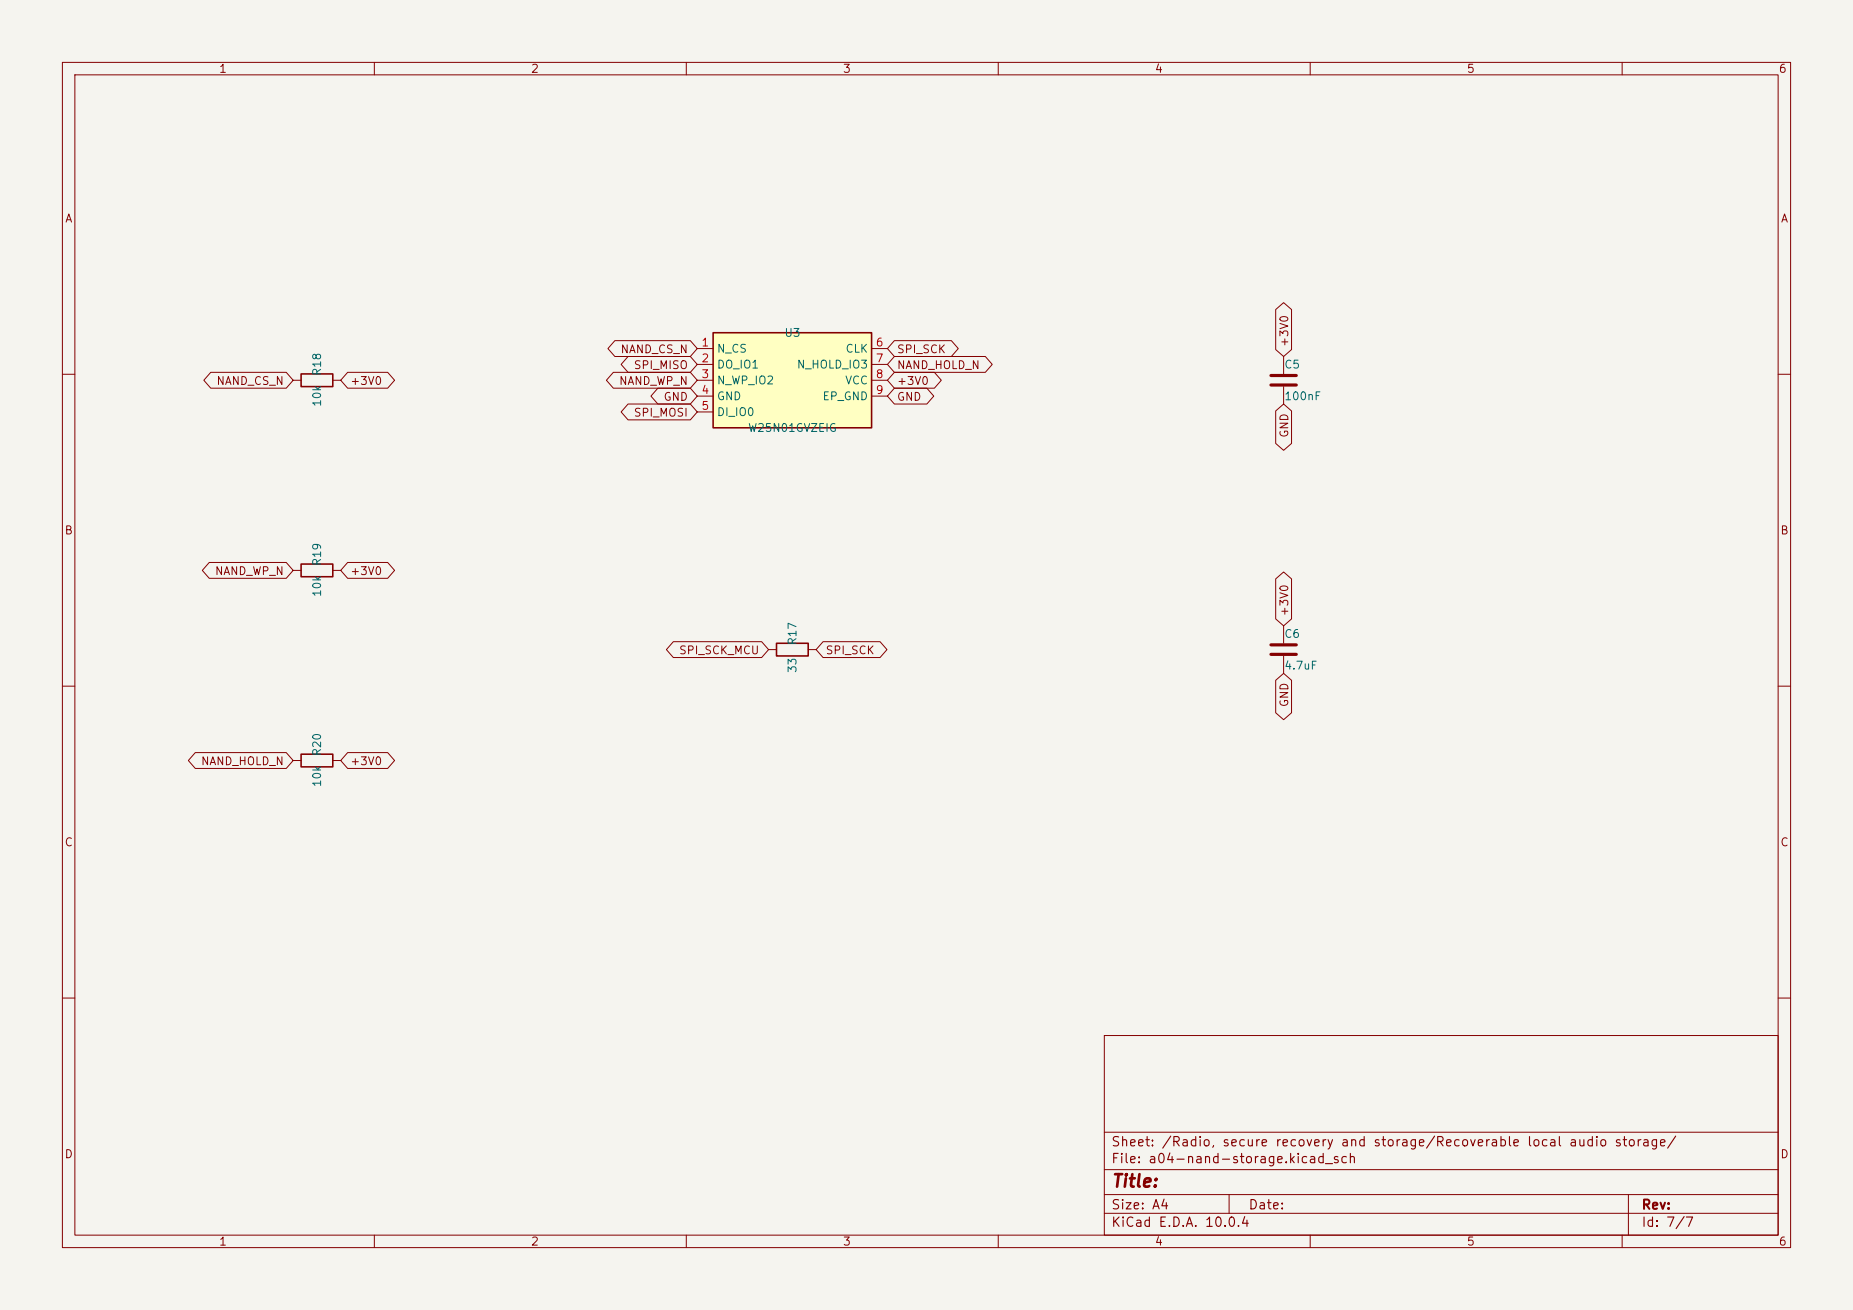
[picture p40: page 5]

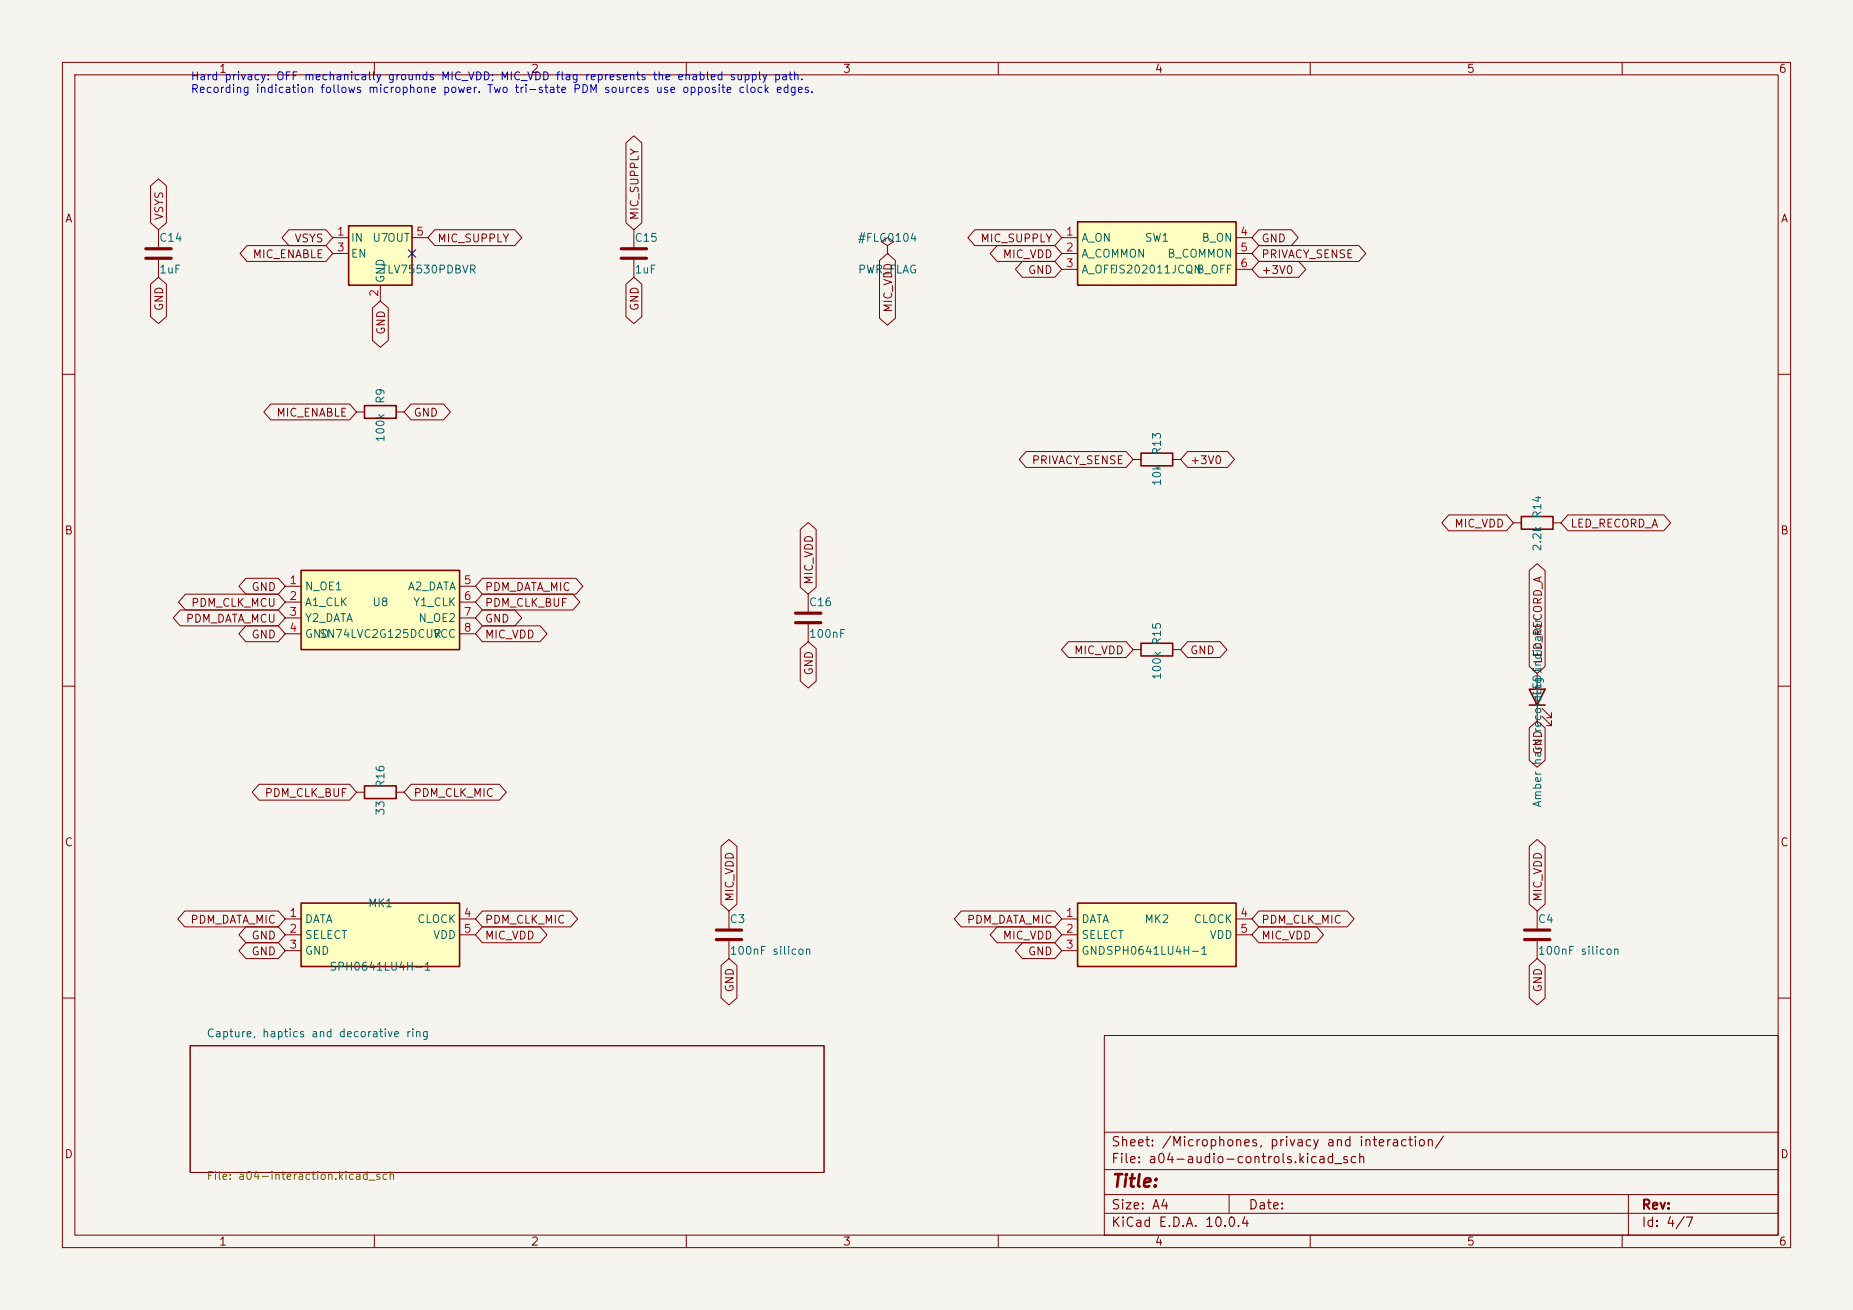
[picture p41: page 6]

PRIVACY_SENSE Hard privacy: OFF mechanically grounds MIC_VDD; MIC_VDD flag represents the enabled supply path.
Recording indication follows microphone power. Two tri-state PDM sources use opposite clock edges.
SN74LVC2G125DCUR R9 100k

Capture, haptics and decorative ring

Sheet: /Microphones, privacy and interaction/
File: a04-audio-controls.kicad_sch
Title:


Sheet: /Microphones, privacy and interaction/Capture, haptics and decorative ring/
File: a04-interaction.kicad_sch
Title:








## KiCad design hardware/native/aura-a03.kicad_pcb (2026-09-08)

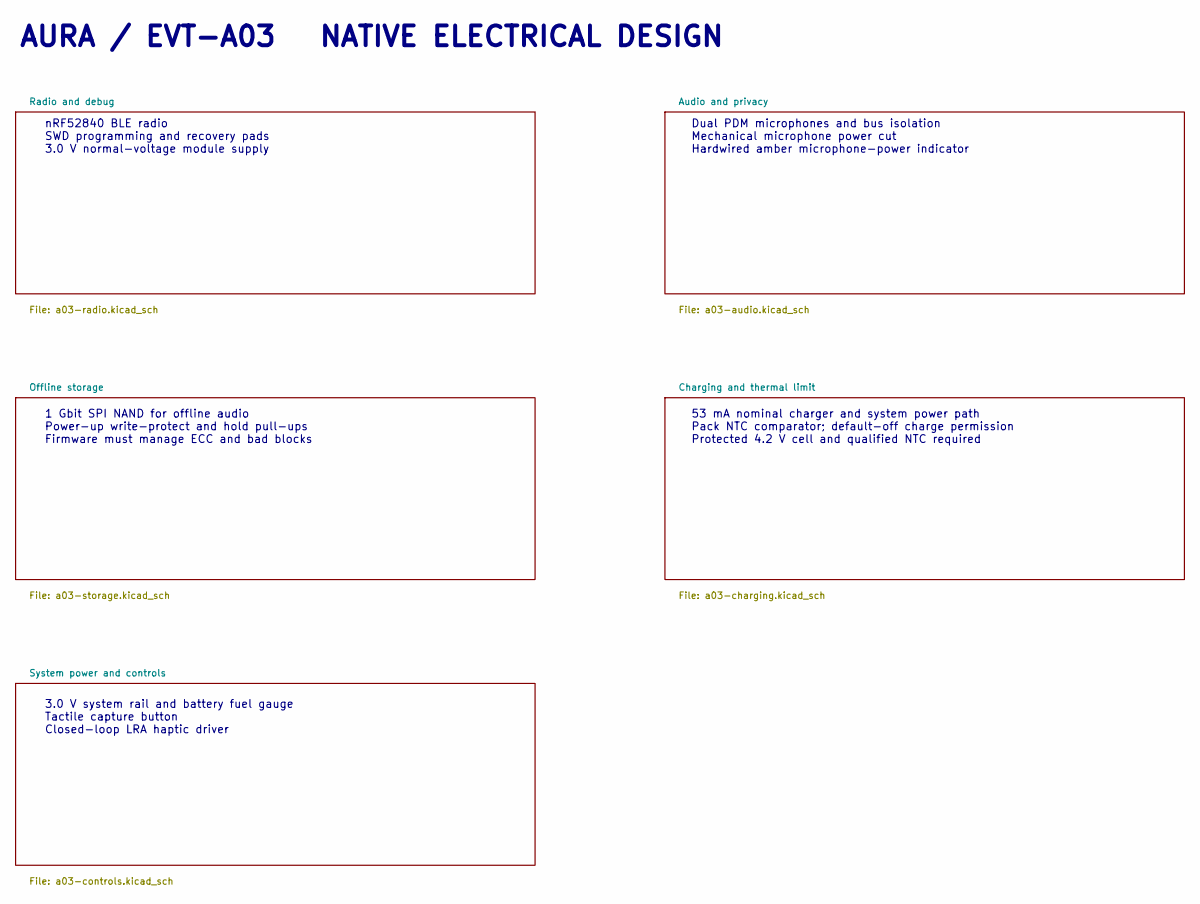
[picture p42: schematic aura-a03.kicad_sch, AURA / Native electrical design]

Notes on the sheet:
AURA / EVT-A03 NATIVE ELECTRICAL DESIGN
nRF52840 BLE radio SWD programming and recovery pads 3.0 V normal-voltage module supply
Dual PDM microphones and bus isolation Mechanical microphone power cut Hardwired amber microphone-power indicator
1 Gbit SPI NAND for offline audio Power-up write-protect and hold pull-ups Firmware must manage ECC and bad blocks
53 mA nominal charger and system power path Pack NTC comparator; default-off charge permission Protected 4.2 V cell and qualified NTC required
3.0 V system rail and battery fuel gauge Tactile capture button Closed-loop LRA haptic driver

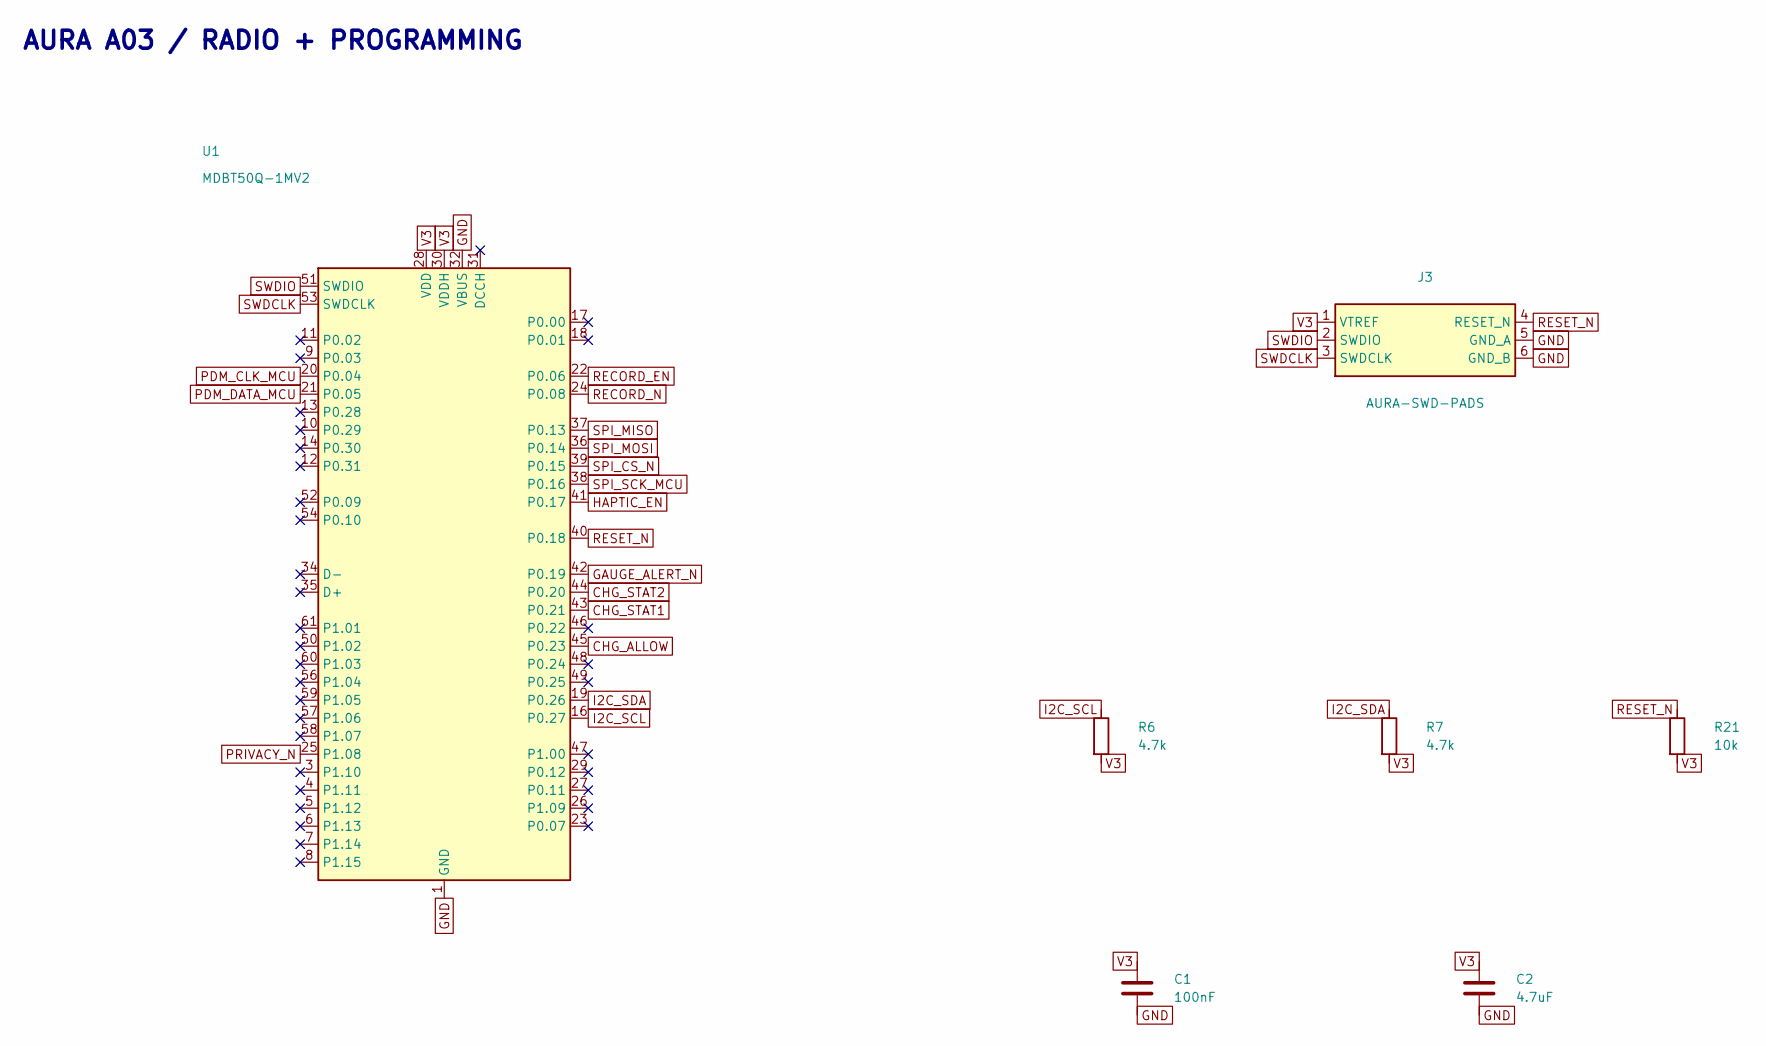
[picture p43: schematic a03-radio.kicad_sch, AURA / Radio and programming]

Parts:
C1: 100nF; A03_C1; MPN C0402C104K4RACTU
C2: 4.7uF; A03_C2; MPN C0603C475K8PACTU
J3: AURA-SWD-PADS; A03_J3; MPN AURA-SWD-PADS
R6: 4.7k; A03_R6; MPN RC0402FR-074K7L
R7: 4.7k; A03_R7; MPN RC0402FR-074K7L
R21: 10k; A03_R21; MPN RC0402FR-0710KL
U1: MDBT50Q-1MV2; A03_U1; MPN MDBT50Q-1MV2

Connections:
CHG_ALLOW: U1.45 (P0.23); also elsewhere on the board
CHG_STAT1: U1.43 (P0.21); also elsewhere on the board
CHG_STAT2: U1.44 (P0.20); also elsewhere on the board
GAUGE_ALERT_N: U1.42 (P0.19); also elsewhere on the board
GND: C1.2, C2.2, J3.5 (GND_A), J3.6 (GND_B), U1.1 (GND), U1.2 (GND), U1.15 (GND), U1.32 (VBUS), U1.33 (GND), U1.55 (GND); also elsewhere on the board
HAPTIC_EN: U1.41 (P0.17); also elsewhere on the board
I2C_SCL: R6.1, U1.16 (P0.27); also elsewhere on the board
I2C_SDA: R7.1, U1.19 (P0.26); also elsewhere on the board
PDM_CLK_MCU: U1.20 (P0.04); also elsewhere on the board
PDM_DATA_MCU: U1.21 (P0.05); also elsewhere on the board
PRIVACY_N: U1.25 (P1.08); also elsewhere on the board
RECORD_EN: U1.22 (P0.06); also elsewhere on the board
RECORD_N: U1.24 (P0.08); also elsewhere on the board
RESET_N: J3.4 (RESET_N), R21.1, U1.40 (P0.18)
SPI_CS_N: U1.39 (P0.15); also elsewhere on the board
SPI_MISO: U1.37 (P0.13); also elsewhere on the board
SPI_MOSI: U1.36 (P0.14); also elsewhere on the board
SPI_SCK_MCU: U1.38 (P0.16); also elsewhere on the board
SWDCLK: J3.3 (SWDCLK), U1.53 (SWDCLK)
SWDIO: J3.2 (SWDIO), U1.51 (SWDIO)
V3: C1.1, C2.1, J3.1 (VTREF), R6.2, R7.2, R21.2, U1.28 (VDD), U1.30 (VDDH); also elsewhere on the board

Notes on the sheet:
AURA A03 / RADIO + PROGRAMMING

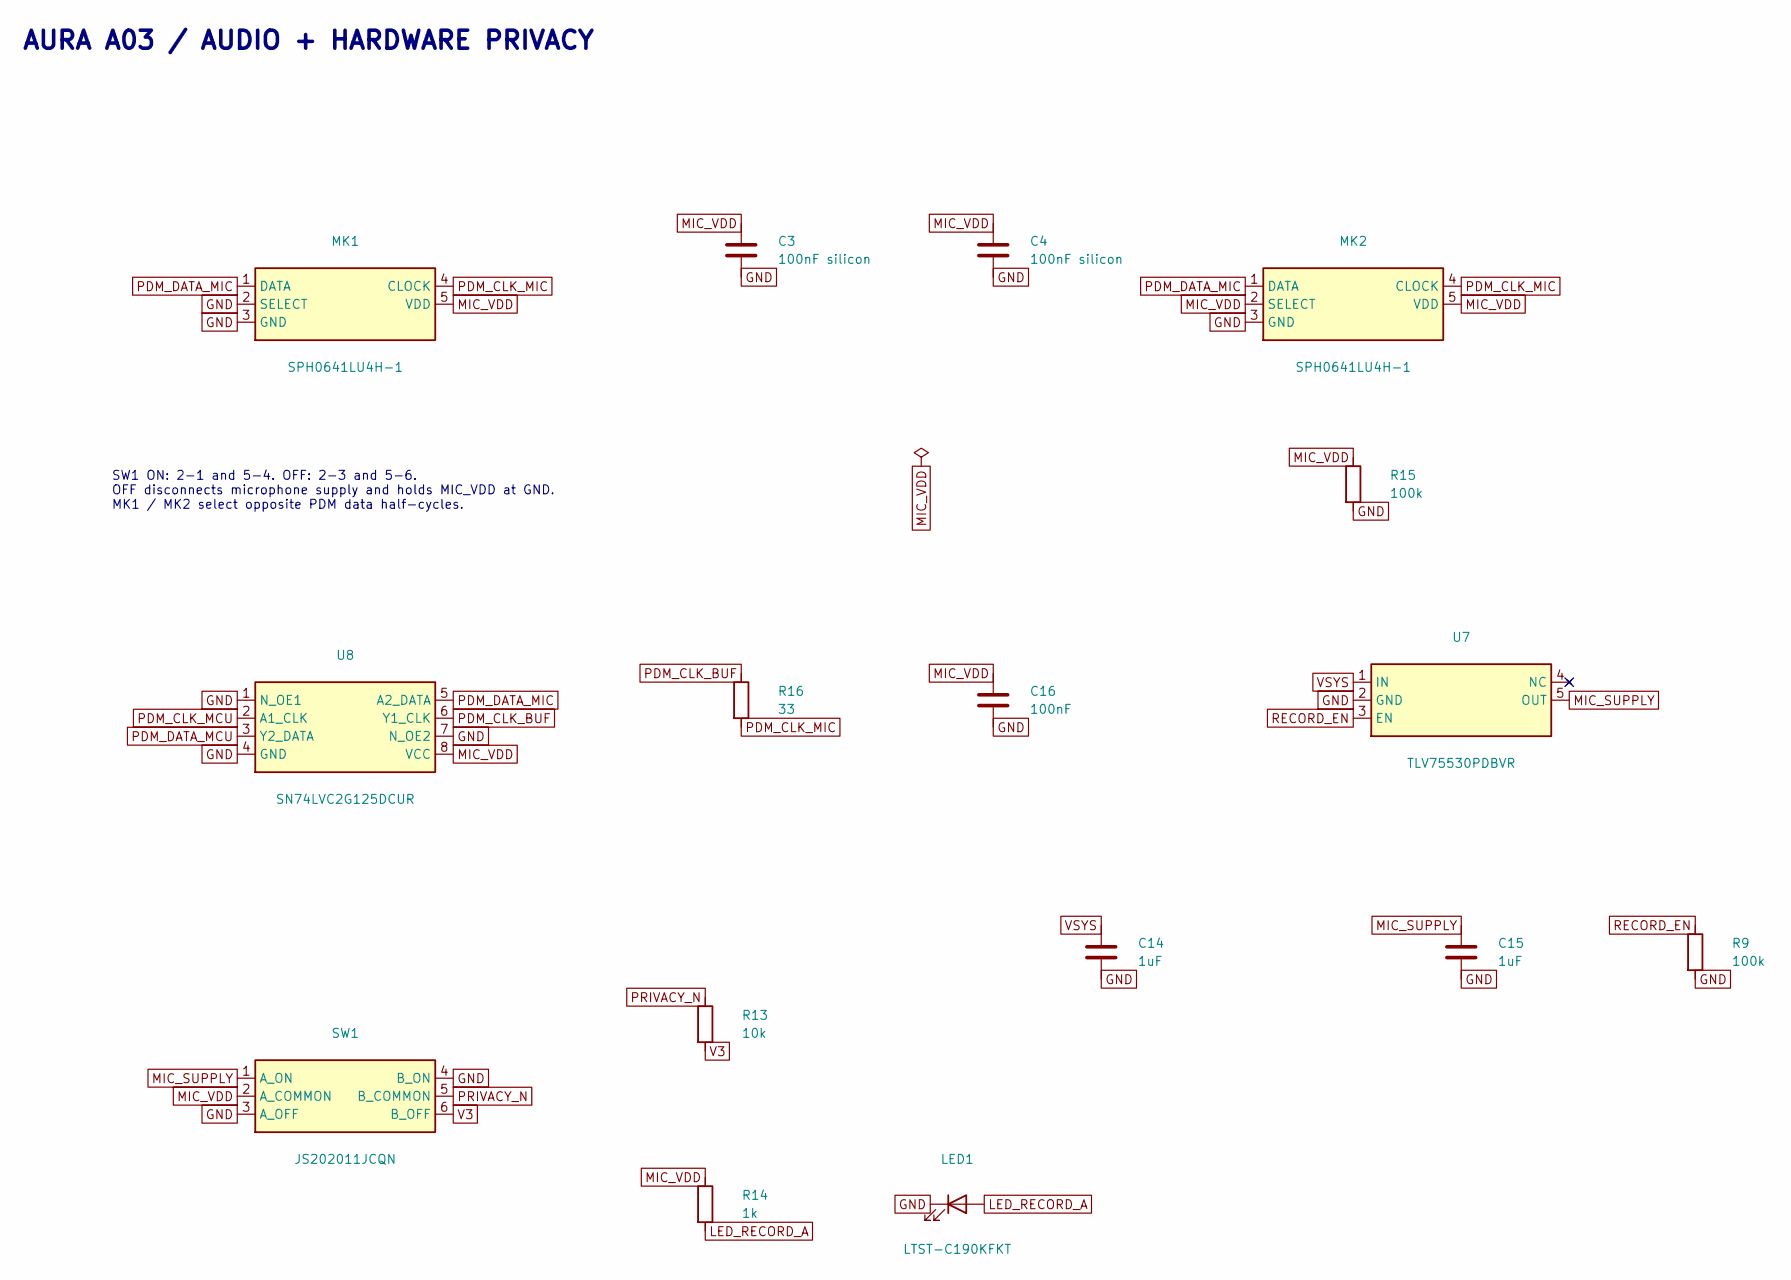
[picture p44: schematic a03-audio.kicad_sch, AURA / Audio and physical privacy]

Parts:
C3: 100nF silicon; A03_C3; MPN 939113424610-T3N
C4: 100nF silicon; A03_C4; MPN 939113424610-T3N
C14: 1uF; A03_C14; MPN C0603C105K4RACTU
C15: 1uF; A03_C15; MPN C0603C105K4RACTU
C16: 100nF; A03_C16; MPN C0402C104K4RACTU
LED1: LTST-C190KFKT; A03_LED1; MPN LTST-C190KFKT
MK1: SPH0641LU4H-1; A03_MK1; MPN SPH0641LU4H-1
MK2: SPH0641LU4H-1; A03_MK2; MPN SPH0641LU4H-1
R9: 100k; A03_R9; MPN RC0402FR-07100KL
R13: 10k; A03_R13; MPN RC0402FR-0710KL
R14: 1k; A03_R14; MPN RC0402FR-071KL
R15: 100k; A03_R15; MPN RC0402FR-07100KL
R16: 33; A03_R16; MPN RC0402FR-0733RL
SW1: JS202011JCQN; A03_SW1; MPN JS202011JCQN
U7: TLV75530PDBVR; A03_U7; MPN TLV75530PDBVR
U8: SN74LVC2G125DCUR; A03_U8; MPN SN74LVC2G125DCUR

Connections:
GND: C3.2, C4.2, C14.2, C15.2, C16.2, LED1.1 (K), MK1.2 (SELECT), MK1.3 (GND), MK2.3 (GND), R9.2, R15.2, SW1.3 (A_OFF), SW1.4 (B_ON), U7.2 (GND), U8.1 (N_OE1), U8.4 (GND), U8.7 (N_OE2); also elsewhere on the board
LED_RECORD_A: LED1.2 (A), R14.2
MIC_SUPPLY: C15.1, SW1.1 (A_ON), U7.5 (OUT)
MIC_VDD: C3.1, C4.1, C16.1, MK1.5 (VDD), MK2.2 (SELECT), MK2.5 (VDD), R14.1, R15.1, SW1.2 (A_COMMON), U8.8 (VCC)
PDM_CLK_BUF: R16.1, U8.6 (Y1_CLK)
PDM_CLK_MCU: U8.2 (A1_CLK); also elsewhere on the board
PDM_CLK_MIC: MK1.4 (CLOCK), MK2.4 (CLOCK), R16.2
PDM_DATA_MCU: U8.3 (Y2_DATA); also elsewhere on the board
PDM_DATA_MIC: MK1.1 (DATA), MK2.1 (DATA), U8.5 (A2_DATA)
PRIVACY_N: R13.1, SW1.5 (B_COMMON); also elsewhere on the board
RECORD_EN: R9.1, U7.3 (EN); also elsewhere on the board
V3: R13.2, SW1.6 (B_OFF); also elsewhere on the board
VSYS: C14.1, U7.1 (IN); also elsewhere on the board

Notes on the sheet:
AURA A03 / AUDIO + HARDWARE PRIVACY
SW1 ON: 2-1 and 5-4. OFF: 2-3 and 5-6. OFF disconnects microphone supply and holds MIC_VDD at GND. MK1 / MK2 select opposite PDM data half-cycles.

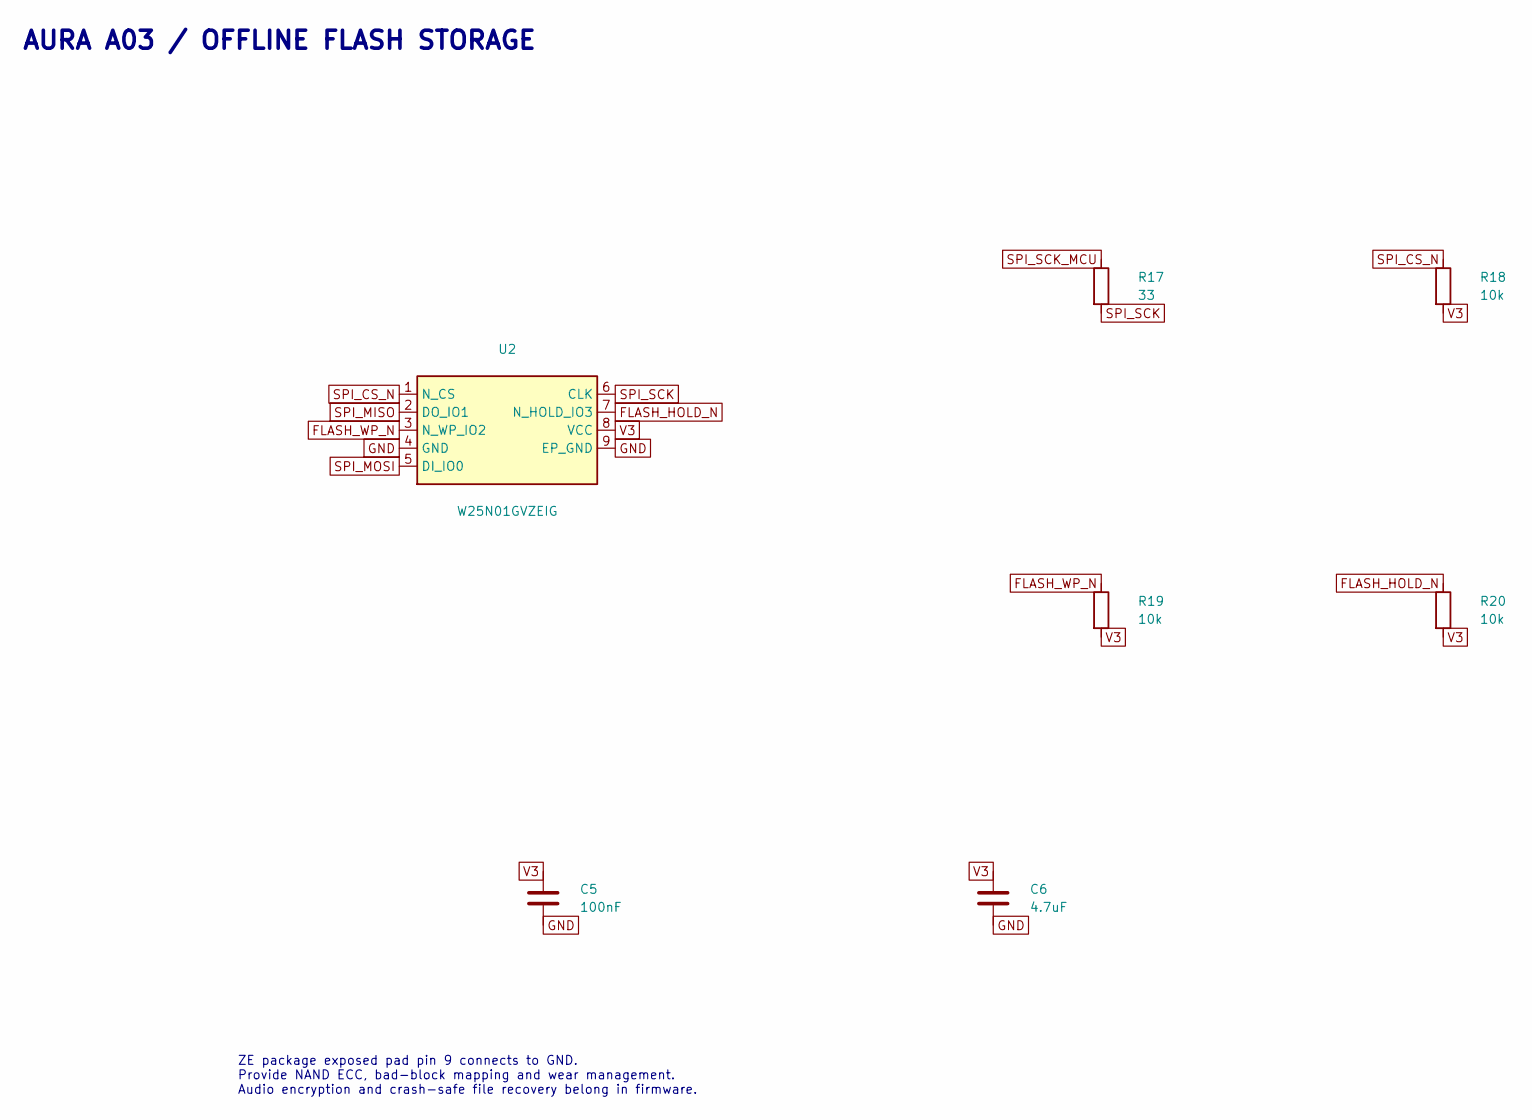
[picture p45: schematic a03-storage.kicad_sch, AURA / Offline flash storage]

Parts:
C5: 100nF; A03_C5; MPN C0402C104K4RACTU
C6: 4.7uF; A03_C6; MPN C0603C475K8PACTU
R17: 33; A03_R17; MPN RC0402FR-0733RL
R18: 10k; A03_R18; MPN RC0402FR-0710KL
R19: 10k; A03_R19; MPN RC0402FR-0710KL
R20: 10k; A03_R20; MPN RC0402FR-0710KL
U2: W25N01GVZEIG; A03_U2; MPN W25N01GVZEIG

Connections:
FLASH_HOLD_N: R20.1, U2.7 (N_HOLD_IO3)
FLASH_WP_N: R19.1, U2.3 (N_WP_IO2)
GND: C5.2, C6.2, U2.4 (GND), U2.9 (EP_GND); also elsewhere on the board
SPI_CS_N: R18.1, U2.1 (N_CS); also elsewhere on the board
SPI_MISO: U2.2 (DO_IO1); also elsewhere on the board
SPI_MOSI: U2.5 (DI_IO0); also elsewhere on the board
SPI_SCK: R17.2, U2.6 (CLK)
SPI_SCK_MCU: R17.1; also elsewhere on the board
V3: C5.1, C6.1, R18.2, R19.2, R20.2, U2.8 (VCC); also elsewhere on the board

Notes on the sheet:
AURA A03 / OFFLINE FLASH STORAGE
ZE package exposed pad pin 9 connects to GND. Provide NAND ECC, bad-block mapping and wear management. Audio encryption and crash-safe file recovery belong in firmware.

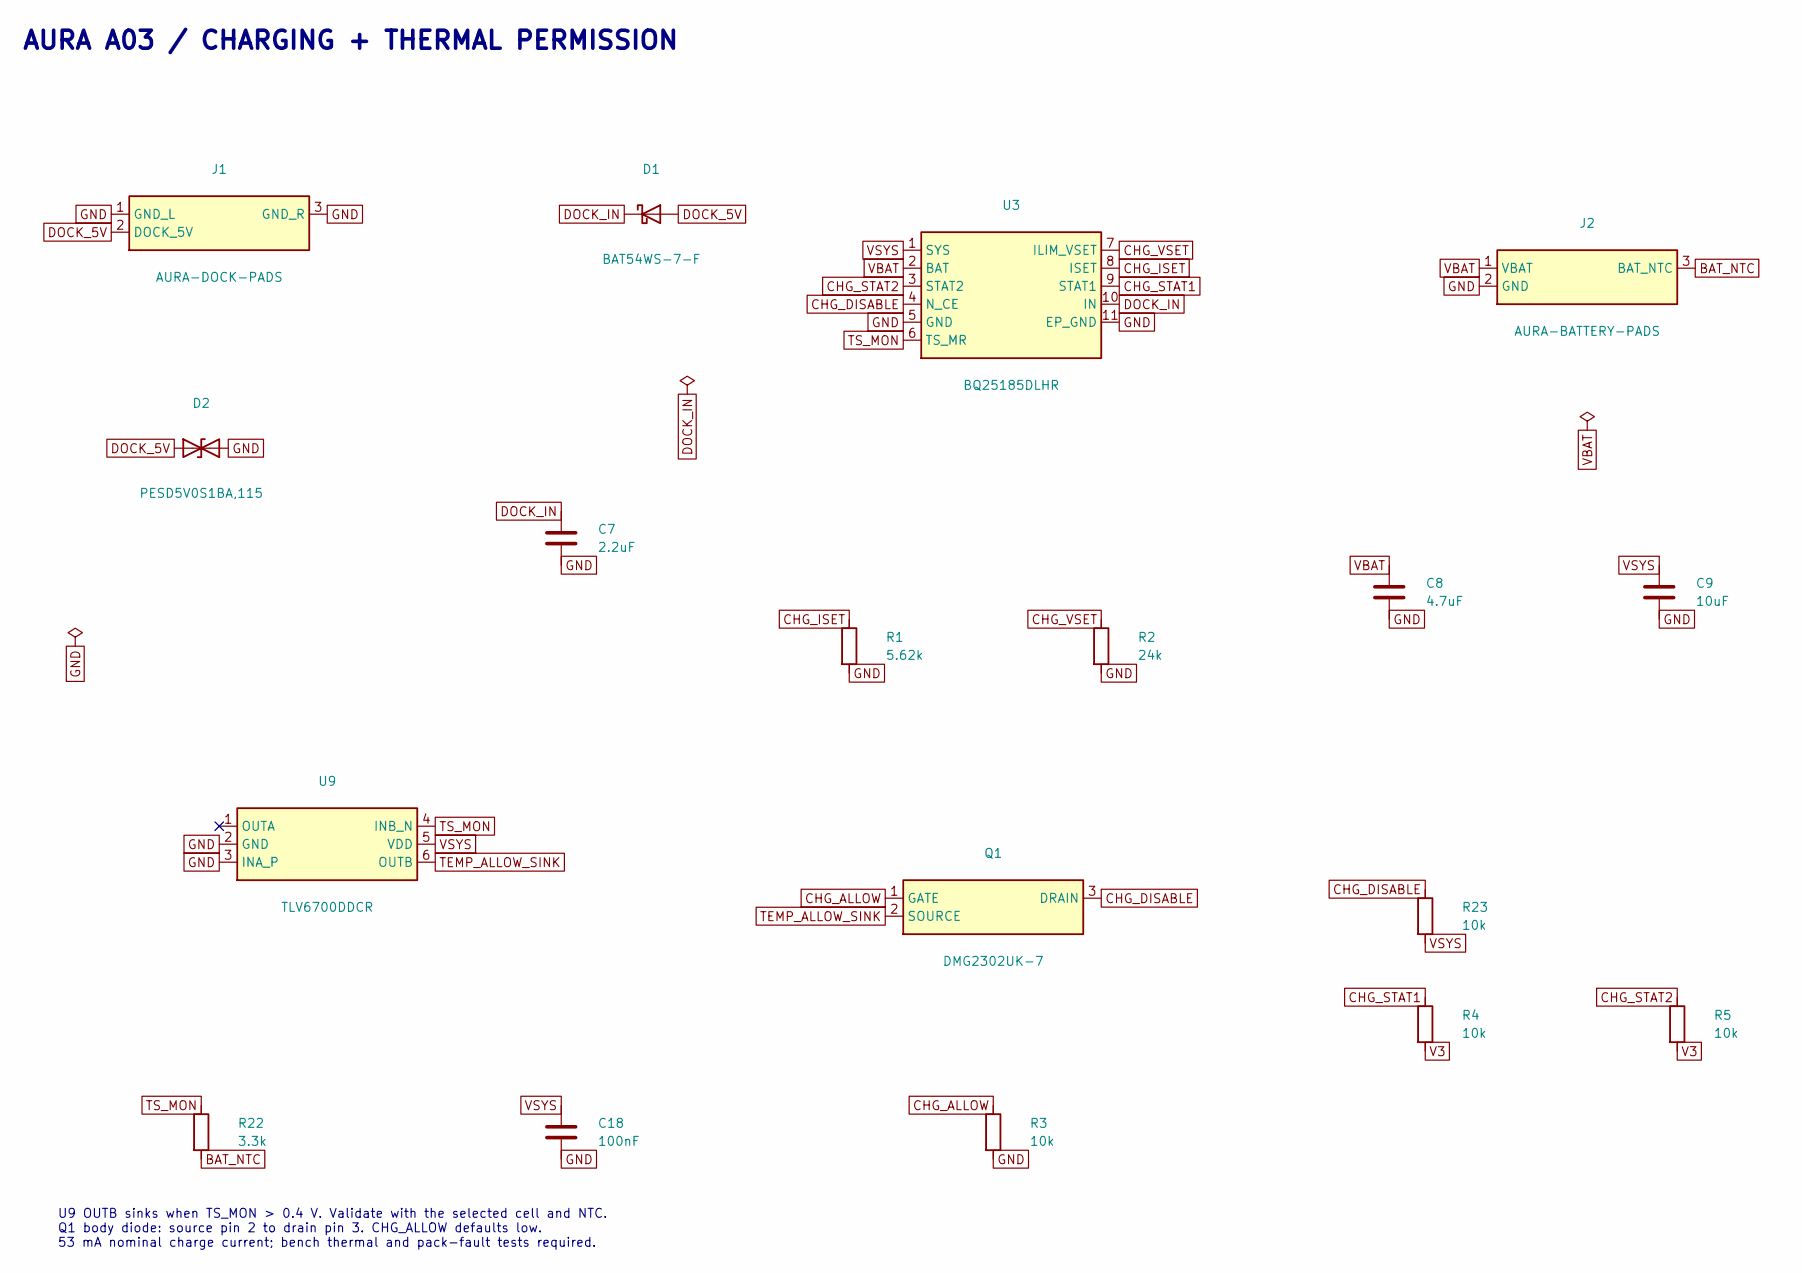
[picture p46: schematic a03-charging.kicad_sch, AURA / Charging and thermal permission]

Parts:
C7: 2.2uF; A03_C7; MPN C0603C225K8RACTU
C8: 4.7uF; A03_C8; MPN C0603C475K8PACTU
C9: 10uF; A03_C9; MPN C0805C106K8PACTU
C18: 100nF; A03_C18; MPN C0402C104K4RACTU
D1: BAT54WS-7-F; A03_D1; MPN BAT54WS-7-F
D2: PESD5V0S1BA,115; A03_D2; MPN PESD5V0S1BA,115
J1: AURA-DOCK-PADS; A03_J1; MPN AURA-DOCK-PADS
J2: AURA-BATTERY-PADS; A03_J2; MPN AURA-BATTERY-PADS
Q1: DMG2302UK-7; A03_Q1; MPN DMG2302UK-7
R1: 5.62k; A03_R1; MPN RC0402FR-075K62L
R2: 24k; A03_R2; MPN RC0402FR-0724KL
R3: 10k; A03_R3; MPN RC0402FR-0710KL
R4: 10k; A03_R4; MPN RC0402FR-0710KL
R5: 10k; A03_R5; MPN RC0402FR-0710KL
R22: 3.3k; A03_R22; MPN RC0402FR-073K3L
R23: 10k; A03_R23; MPN RC0402FR-0710KL
U3: BQ25185DLHR; A03_U3; MPN BQ25185DLHR
U9: TLV6700DDCR; A03_U9; MPN TLV6700DDCR

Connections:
BAT_NTC: J2.3 (BAT_NTC), R22.2
CHG_ALLOW: Q1.1 (GATE), R3.1; also elsewhere on the board
CHG_DISABLE: Q1.3 (DRAIN), R23.1, U3.4 (N_CE)
CHG_ISET: R1.1, U3.8 (ISET)
CHG_STAT1: R4.1, U3.9 (STAT1); also elsewhere on the board
CHG_STAT2: R5.1, U3.3 (STAT2); also elsewhere on the board
CHG_VSET: R2.1, U3.7 (ILIM_VSET)
DOCK_5V: D1.2 (A), D2.1 (A1), J1.2 (DOCK_5V)
DOCK_IN: C7.1, D1.1 (K), U3.10 (IN)
GND: C7.2, C8.2, C9.2, C18.2, D2.2 (A2), J1.1 (GND_L), J1.3 (GND_R), J2.2 (GND), R1.2, R2.2, R3.2, U3.5 (GND), U3.11 (EP_GND), U9.2 (GND), U9.3 (INA_P); also elsewhere on the board
TEMP_ALLOW_SINK: Q1.2 (SOURCE), U9.6 (OUTB)
TS_MON: R22.1, U3.6 (TS_MR), U9.4 (INB_N)
V3: R4.2, R5.2; also elsewhere on the board
VBAT: C8.1, J2.1 (VBAT), U3.2 (BAT); also elsewhere on the board
VSYS: C9.1, C18.1, R23.2, U3.1 (SYS), U9.5 (VDD); also elsewhere on the board

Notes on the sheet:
AURA A03 / CHARGING + THERMAL PERMISSION
U9 OUTB sinks when TS_MON > 0.4 V. Validate with the selected cell and NTC. Q1 body diode: source pin 2 to drain pin 3. CHG_ALLOW defaults low. 53 mA nominal charge current; bench thermal and pack-fault tests required.

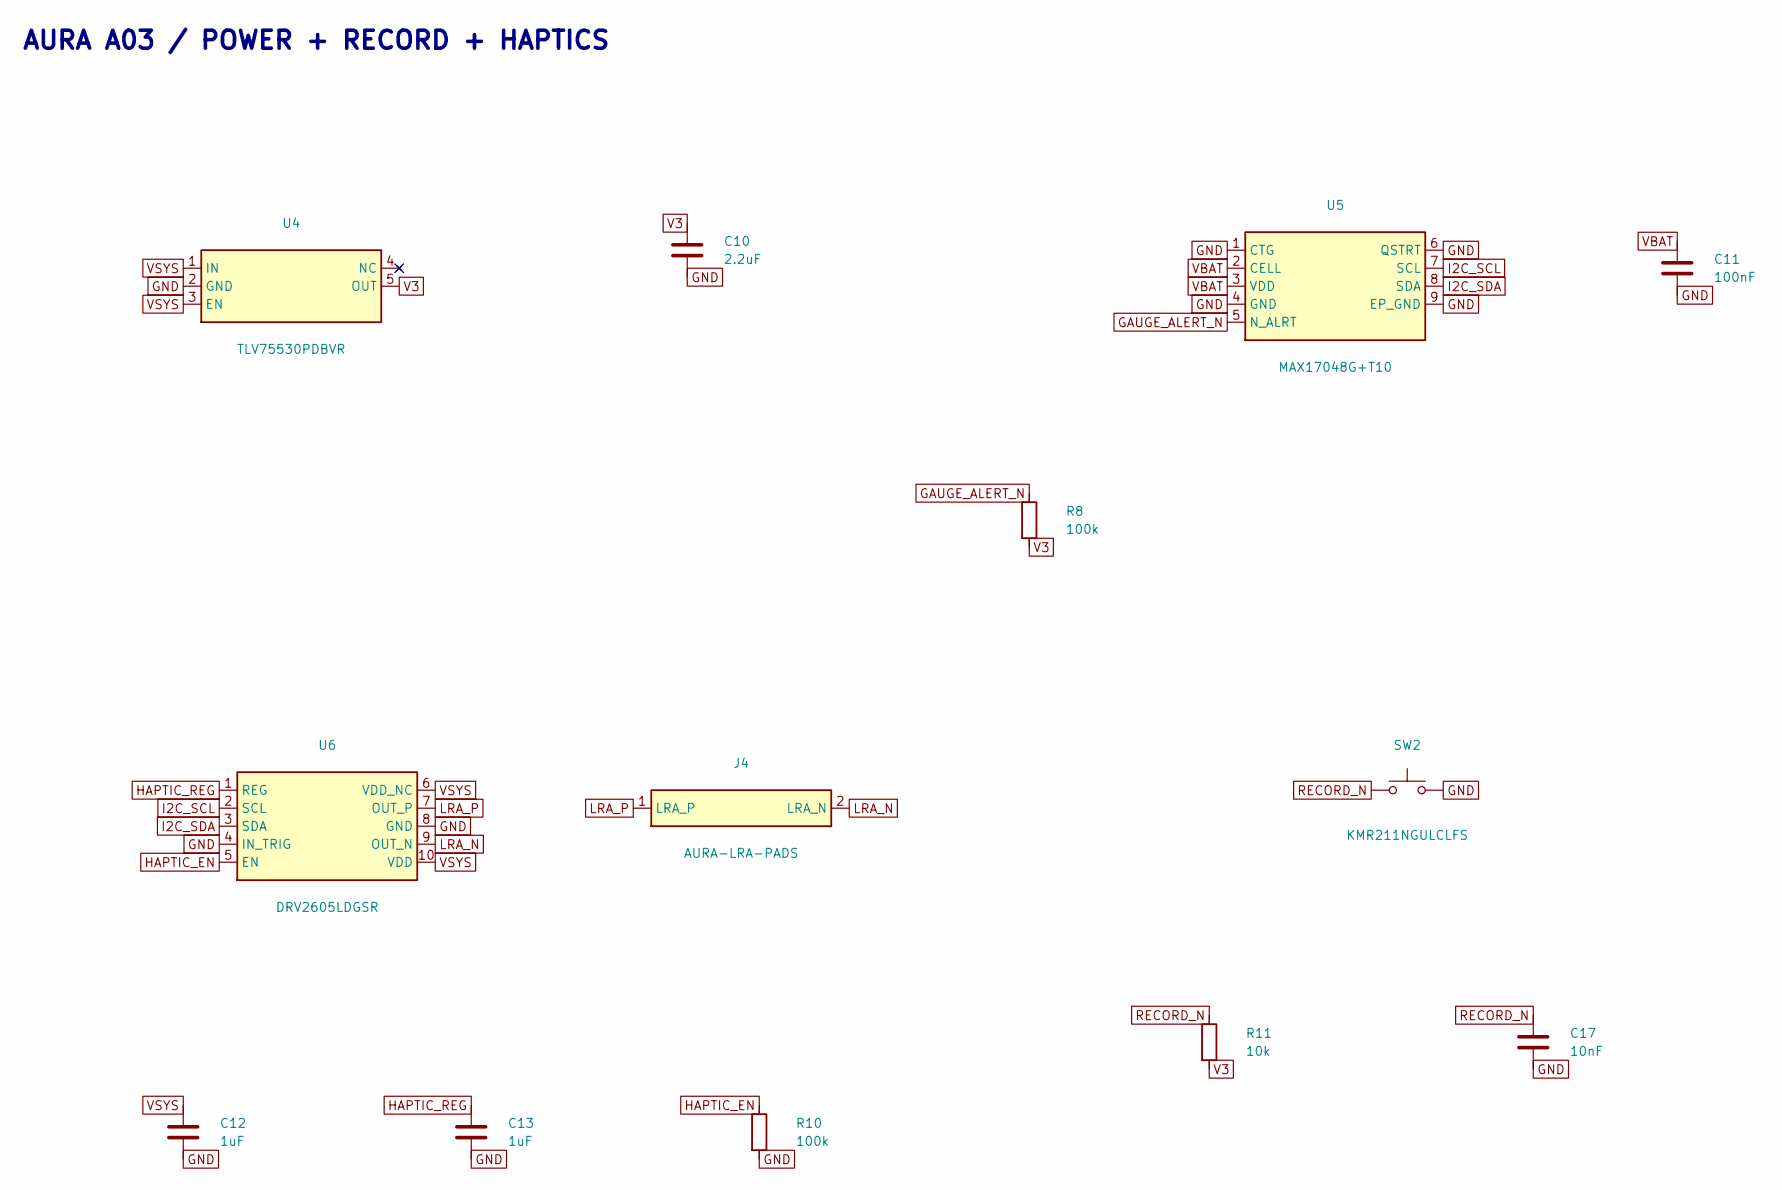
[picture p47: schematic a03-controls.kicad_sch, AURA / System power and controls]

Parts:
C10: 2.2uF; A03_C10; MPN C0603C225K8RACTU
C11: 100nF; A03_C11; MPN C0402C104K4RACTU
C12: 1uF; A03_C12; MPN C0603C105K4RACTU
C13: 1uF; A03_C13; MPN C0603C105K4RACTU
C17: 10nF; A03_C17; MPN C0402C103K5RACTU
J4: AURA-LRA-PADS; A03_J4; MPN AURA-LRA-PADS
R8: 100k; A03_R8; MPN RC0402FR-07100KL
R10: 100k; A03_R10; MPN RC0402FR-07100KL
R11: 10k; A03_R11; MPN RC0402FR-0710KL
SW2: KMR211NGULCLFS; A03_SW2; MPN KMR211NGULCLFS
U4: TLV75530PDBVR; A03_U4; MPN TLV75530PDBVR
U5: MAX17048G+T10; A03_U5; MPN MAX17048G+T10
U6: DRV2605LDGSR; A03_U6; MPN DRV2605LDGSR

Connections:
GAUGE_ALERT_N: R8.1, U5.5 (N_ALRT); also elsewhere on the board
GND: C10.2, C11.2, C12.2, C13.2, C17.2, R10.2, SW2.2, U4.2 (GND), U5.1 (CTG), U5.4 (GND), U5.6 (QSTRT), U5.9 (EP_GND), U6.4 (IN_TRIG), U6.8 (GND); also elsewhere on the board
HAPTIC_EN: R10.1, U6.5 (EN); also elsewhere on the board
HAPTIC_REG: C13.1, U6.1 (REG)
I2C_SCL: U5.7 (SCL), U6.2 (SCL); also elsewhere on the board
I2C_SDA: U5.8 (SDA), U6.3 (SDA); also elsewhere on the board
LRA_N: J4.2 (LRA_N), U6.9 (OUT_N)
LRA_P: J4.1 (LRA_P), U6.7 (OUT_P)
RECORD_N: C17.1, R11.1, SW2.1; also elsewhere on the board
V3: C10.1, R8.2, R11.2, U4.5 (OUT); also elsewhere on the board
VBAT: C11.1, U5.2 (CELL), U5.3 (VDD); also elsewhere on the board
VSYS: C12.1, U4.1 (IN), U4.3 (EN), U6.6 (VDD_NC), U6.10 (VDD); also elsewhere on the board

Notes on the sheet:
AURA A03 / POWER + RECORD + HAPTICS

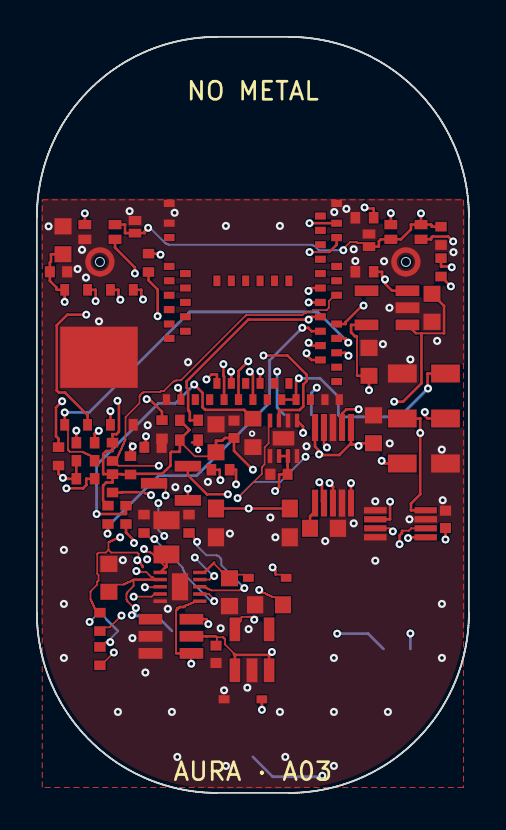
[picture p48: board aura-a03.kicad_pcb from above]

Board: 4 copper layers, 24.0 x 42.0 mm, 61 parts (0 on the bottom side), 43 nets.

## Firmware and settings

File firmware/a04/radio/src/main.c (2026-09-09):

/* SPDX-License-Identifier: MIT */
/* Separate nRF52840 DK radio development application. Actual PDM/NAND drivers,
 * explicit wired owner context, L4 pairing and owner proof. Never flash AURA.
 * No battery/charger, automatic format, audio release or signed OTA capability. */
#include <zephyr/kernel.h>
#include <zephyr/drivers/uart.h>
#include <zephyr/drivers/hwinfo.h>
#include <zephyr/sys/printk.h>
#include <zephyr/sys/byteorder.h>
#include "aura_audio_zephyr.h"
#include "aura_w25n01gv_zephyr.h"
#include "aura_storage.h"
#include "aura_transfer.h"
#include "aura_session_auth.h"
#include "aura_gatt_zephyr.h"
#include "aura_pairing_zephyr.h"
#include <zephyr/bluetooth/bluetooth.h>
#include <zephyr/bluetooth/conn.h>
#include <zephyr/bluetooth/uuid.h>
#include <zephyr/random/random.h>
#include <zephyr/settings/settings.h>
#include <errno.h>
#include <stdarg.h>
#include <stdio.h>
#include <stdlib.h>
#include <string.h>

#define REQUEST_BYTES 256u
#define MAX_CAPTURE_MS 60000u
static const struct device *const uart = DEVICE_DT_GET(DT_CHOSEN(zephyr_console));
static const struct gpio_dt_spec mic = GPIO_DT_SPEC_GET(DT_NODELABEL(bench_controls), mic_enable_gpios);
static const struct gpio_dt_spec privacy = GPIO_DT_SPEC_GET(DT_NODELABEL(bench_controls), privacy_gpios);
static const struct gpio_dt_spec led = GPIO_DT_SPEC_GET(DT_ALIAS(led0), gpios);
static const struct spi_dt_spec spi = SPI_DT_SPEC_GET(DT_NODELABEL(bench_nand),
                                                     SPI_WORD_SET(8) | SPI_TRANSFER_MSB, 0);
static struct aura_w25n01gv_zephyr nand;
static struct aura_storage storage;
static struct aura_control control;
static struct aura_journal journal = {.active=-1};
static struct aura_transfer transfer;
static struct aura_session_auth session_auth;
static uint64_t auth_link, requested_security, applied_auth_deadline;
static uint64_t observed_radio_generation;
static bool observed_radio_connected;
static bool transfer_ready;
static atomic_t radio_allowed, capture_requested;
static atomic_t radio_fault;
static bool advertising;
static uint64_t advertise_deadline;
static void radio_worker(struct k_work *work);
K_WORK_DELAYABLE_DEFINE(radio_work,radio_worker);
static const struct bt_data radio_ad[]={
    BT_DATA_BYTES(BT_DATA_FLAGS,BT_LE_AD_GENERAL|BT_LE_AD_NO_BREDR),
    BT_DATA_BYTES(BT_DATA_UUID128_ALL,BT_UUID_128_ENCODE(0x7f520000,0x1b15,0x4f0d,0x8fe5,0x3f942170a004))};
static const struct bt_data radio_sd[]={BT_DATA(BT_DATA_NAME_COMPLETE,"AURA-A04-DK",11)};
static struct aura_recorder recorder;
static struct aura_audio_zephyr audio;
static uint8_t snapshot[AURA_STORAGE_STATE_BYTES], device_id[16], capture_id[16];
static union { max_align_t alignment; uint8_t bytes[AURA_OPUS_STATE_LIMIT]; } encoder;
static struct gpio_callback privacy_callback;
static struct k_thread reader_thread, storage_thread;
K_THREAD_STACK_DEFINE(reader_stack, 4096);
K_THREAD_STACK_DEFINE(storage_stack, 49152);
struct request { char line[REQUEST_BYTES]; atomic_val_t stop_generation; };
K_MSGQ_DEFINE(requests, sizeof(struct request), 2, 4);
static struct request rx;
static size_t rx_size;
static bool discard_line;
static atomic_t cancellation, session_generation, startup_pending, capture_gate, initialized, rx_fault;
static int boot_fault;
static uint64_t epoch, started_ms;
static uint32_t service_max_us, late_services, fifo_high_water;
static bool have_stop_reply;
static uint32_t stop_reply_id;

/* Exactly one storage owner writes complete protocol lines. ISR/reader never
 * format or transmit; they only publish atomic state or bounded commands. */
static void reply(uint32_t id, const char *format, ...)
{
    char line[384];
    int prefix = snprintf(line, sizeof(line), "A04B %08x ", id);
    va_list arguments; va_start(arguments, format);
    int length = vsnprintf(line + prefix, sizeof(line) - (size_t)prefix - 1, format, arguments);
    va_end(arguments);
    if (length < 0 || (size_t)length >= sizeof(line) - (size_t)prefix - 1) {
        length = snprintf(line + prefix, sizeof(line) - (size_t)prefix, "ERROR %d", -EMSGSIZE);
    }
    size_t used = (size_t)prefix + (size_t)length;
    line[used++] = '\n';
    for (size_t i = 0; i < used; ++i) uart_poll_out(uart, line[i]);
}
static int nibble(char value)
{
    if (value >= '0' && value <= '9') return value - '0';
    if (value >= 'a' && value <= 'f') return value - 'a' + 10;
    if (value >= 'A' && value <= 'F') return value - 'A' + 10;
    return -1;
}
static int unhex(const char *text, uint8_t *bytes, size_t count)
{
    if (!text || strlen(text) != count * 2) return -EINVAL;
    for (size_t i = 0; i < count; ++i) {
        int high = nibble(text[2*i]), low = nibble(text[2*i+1]);
        if (high < 0 || low < 0) return -EINVAL;
        bytes[i] = (uint8_t)(high * 16 + low);
    }
    return 0;
}
static void hex(const uint8_t *bytes, size_t count, char *out)
{
    const char digits[] = "0123456789abcdef";
    for (size_t i = 0; i < count; ++i) { out[i*2] = digits[bytes[i] >> 4]; out[i*2+1] = digits[bytes[i] & 15]; }
    out[count*2] = 0;
}
static bool valid_prefix(const char *line)
{
    if (strlen(line) < 15 || memcmp(line, "A04B ", 5) || line[13] != ' ') return false;
    for (unsigned i = 5; i < 13; ++i) if (nibble(line[i]) < 0) return false;
    return true;
}
static void cancel_capture(bool physical)
{
    atomic_inc(&cancellation);
    if (atomic_get(&initialized)) {
        if (physical) aura_audio_zephyr_privacy_cutoff(&audio);
        else aura_audio_zephyr_request_stop(&audio);
    }
}
static void receive_byte(uint8_t value)
{
    if (value == '\r') return;
    if (value == '\n') {
        if (!discard_line) {
            rx.line[rx_size] = 0;
            if (valid_prefix(rx.line)) {
                if (!strcmp(rx.line + 14, "STOP")) cancel_capture(false);
                rx.stop_generation = atomic_get(&cancellation);
                if (k_msgq_put(&requests, &rx, K_NO_WAIT)) atomic_set(&rx_fault, 1);
                else if(!strcmp(rx.line + 14,"START"))atomic_inc(&capture_requested);
            } else atomic_set(&rx_fault, 1);
        }
        memset(&rx, 0, sizeof(rx)); rx_size = 0; discard_line = false;
    } else if (value < 32 || value > 126 || rx_size >= sizeof(rx.line) - 1) {
        discard_line = true; atomic_set(&rx_fault, 1);
    } else if (!discard_line) rx.line[rx_size++] = (char)value;
}
static void uart_input(const struct device *port, void *user)
{
    ARG_UNUSED(user);
    if (uart_err_check(port)) { discard_line = true; atomic_set(&rx_fault, 1); }
    while (uart_irq_update(port) && uart_irq_rx_ready(port)) {
        uint8_t bytes[16]; int count = uart_fifo_read(port, bytes, sizeof(bytes));
        if (count <= 0) break;
        for (int i = 0; i < count; ++i) receive_byte(bytes[i]);
    }
}
static bool permitted(void *user)
{
    ARG_UNUSED(user);
    return atomic_get(&capture_gate) &&
           (!atomic_get(&startup_pending) || atomic_get(&session_generation) == atomic_get(&cancellation)) &&
           gpio_pin_get_dt(&privacy) == 1;
}
static void privacy_changed(const struct device *port, struct gpio_callback *callback, gpio_port_pins_t pins)
{
    ARG_UNUSED(port); ARG_UNUSED(callback); ARG_UNUSED(pins);
    if (gpio_pin_get_dt(&privacy) != 1) cancel_capture(true);
}
static bool audio_pending(void)
{
    atomic_val_t state = atomic_get(&audio.state);
    return state == AURA_AUDIO_STARTING || state == AURA_AUDIO_CAPTURING || state == AURA_AUDIO_STOPPING ||
        !atomic_get(&audio.reader_done) || k_msgq_num_used_get(&audio.queue) ||
        recorder.state == AURA_RECORDER_RECORDING;
}
static bool busy(void) { return audio_pending() || journal.active >= 0; }
static void reader(void *one, void *two, void *three)
{
    ARG_UNUSED(one); ARG_UNUSED(two); ARG_UNUSED(three);
    for (;;) {
        if (atomic_get(&audio.reader_enabled)) {
            (void)aura_audio_zephyr_reader_step(&audio);
            if (atomic_get(&audio.state) == AURA_AUDIO_STOPPING) k_msleep(1);
        } else k_msleep(1);
    }
}
static unsigned free_blocks(void)
{
    unsigned count = 0;
    if (storage.ready) for (unsigned i=0; i<journal.io.blocks; ++i)
        count += journal.block_state[i] == AURA_BLOCK_FREE || journal.block_state[i] == AURA_BLOCK_PREPARED;
    return count;
}
static int owner_fault(void)
{
    /* The recorder may fail while sealing after the producer has stopped.
     * The audio adapter's producer fault alone cannot describe that failure. */
    int audio_fault = (int)atomic_get(&audio.fault);
    if (boot_fault) return boot_fault;
    if (storage.fault) return storage.fault;
    if (audio_fault) return audio_fault;
    if (recorder.close_error) return recorder.close_error;
    if (recorder.fault_reason) return recorder.fault_reason;
    return journal.fault;
}
static void info(uint32_t id)
{
    char identity[33]; hex(device_id, 16, identity);
    reply(id, "OK INFO %s %u %d %d %u %u", identity, storage.ready, (int)atomic_get(&audio.state),
          owner_fault(), storage.ready ? journal.count : 0, free_blocks());
}
static void stats(uint32_t id)
{
    size_t reader_free=0, storage_free=0;
    (void)k_thread_stack_space_get(&reader_thread, &reader_free);
    (void)k_thread_stack_space_get(&storage_thread, &storage_free);
    reply(id, "OK STATS %u %u %u %u %u %llu %u %u %u %u %u %u", service_max_us, late_services,
        fifo_high_water, (unsigned)reader_free, (unsigned)storage_free,
        (unsigned long long)(journal.metadata_reads+journal.payload_reads+control.reads),
        nand.device.program_attempts, nand.device.erase_attempts,
        audio.peak[0], audio.peak[1], audio.clipped[0], audio.clipped[1]);
}
static void radio_worker(struct k_work *work)
{
    ARG_UNUSED(work);
    if(atomic_get(&radio_fault))return;
    struct aura_gatt_link link;aura_gatt_link_snapshot(&link);
    if(!atomic_get(&radio_allowed)){
        if(advertising)(void)bt_le_adv_stop();
        advertising=false;advertise_deadline=0;return;
    }
    if(link.connected){advertising=false;advertise_deadline=0;return;}
    if(!advertising){
        int rc=bt_le_adv_start(BT_LE_ADV_CONN_FAST_2,radio_ad,ARRAY_SIZE(radio_ad),radio_sd,ARRAY_SIZE(radio_sd));
        if(!rc||rc==-EALREADY){advertising=true;advertise_deadline=0;}
        else if(rc==-EAGAIN||rc==-ENOMEM||rc==-EBUSY){
            uint64_t now=(uint64_t)k_uptime_get();
            if(!advertise_deadline)advertise_deadline=now+10000u;
            if(now<advertise_deadline)k_work_schedule(&radio_work,K_MSEC(100));
            else atomic_set(&radio_fault,rc);
        }else atomic_set(&radio_fault,rc);
    }
}
static int session_random(void *user,uint8_t *out,size_t bytes)
{ ARG_UNUSED(user);return sys_csrand_get(out,bytes); }
static void radio_lock(void)
{
    atomic_clear(&radio_allowed);aura_pairing_close();
    struct aura_gatt_link link;aura_gatt_link_snapshot(&link);
    if(link.generation)aura_gatt_disconnect(link.generation);
    struct aura_gatt_owner_gate gate={.authorization=AURA_GATT_DENIED};
    (void)aura_gatt_owner_tick(&transfer,&gate);
    aura_session_auth_forget(&session_auth);transfer_ready=false;auth_link=requested_security=applied_auth_deadline=0;
    k_work_schedule(&radio_work,K_NO_WAIT);
}
static void radio_owner_tick(bool active)
{
    uint64_t now=(uint64_t)k_uptime_get();
    struct aura_gatt_link link;aura_gatt_link_snapshot(&link);
    if(link.connected!=observed_radio_connected||link.generation!=observed_radio_generation){
        observed_radio_connected=link.connected;observed_radio_generation=link.generation;
        k_work_schedule(&radio_work,K_NO_WAIT);
    }
    struct aura_pairing_event event;
    if(aura_pairing_take(&event)){
        if(event.kind==AURA_PAIRING_PASSKEY)reply(0,"PAIR PASSKEY %06u",event.passkey);
        else if(event.kind==AURA_PAIRING_COMPLETE)reply(0,"PAIR COMPLETE");
        else if(event.kind==AURA_PAIRING_EXPIRED)reply(0,"PAIR EXPIRED");
        else reply(0,"PAIR CANCELLED");
        memset(&event,0,sizeof(event));
    }
    bool allowed=atomic_get(&radio_allowed)&&transfer_ready&&!atomic_get(&radio_fault);
    if(!allowed||!link.connected||!link.secure_l4){
        aura_session_auth_end(&session_auth);auth_link=applied_auth_deadline=0;
        if(link.connected){
            if(!allowed)aura_gatt_disconnect(link.generation);
            else if(requested_security!=link.generation){
                requested_security=link.generation;aura_gatt_request_security(link.generation);
            }
        }
    }else if(auth_link!=link.generation){
        auth_link=link.generation;applied_auth_deadline=0;
        if(aura_session_auth_bind(&session_auth,link.generation,now,true))aura_gatt_disconnect(link.generation);
    }
    struct aura_gatt_auth_frame frame;
    if(aura_gatt_auth_take(&frame)){
        int rc=aura_session_auth_receive(&session_auth,frame.generation,now,link.secure_l4,frame.data,frame.bytes);
        memset(&frame,0,sizeof(frame));
        if(rc)aura_gatt_disconnect(link.generation);
    }
    if(allowed&&link.connected&&link.secure_l4&&session_auth.deadline!=applied_auth_deadline){
        int rc=aura_gatt_auth_deadline(link.generation,(int64_t)session_auth.deadline);
        if(rc)aura_session_auth_end(&session_auth);
        else applied_auth_deadline=session_auth.deadline;
    }
    bool grant=allowed&&link.connected&&link.secure_l4&&
        aura_session_auth_granted(&session_auth,link.generation,now,true);
    struct aura_gatt_owner_gate gate={.connection_generation=link.generation,
        .authorization=grant?AURA_GATT_GRANTED:AURA_GATT_DENIED,
        .capture_preempt=active||atomic_get(&capture_requested)};
    int rc=aura_gatt_owner_tick(&transfer,&gate);
    if(rc)aura_session_auth_end(&session_auth);
    if(allowed&&link.connected&&link.secure_l4){
        uint8_t value[AURA_SESSION_CHALLENGE_BYTES];size_t bytes=0;
        rc=aura_session_auth_snapshot(&session_auth,link.generation,now,true,value,sizeof(value),&bytes);
        if(rc){aura_gatt_disconnect(link.generation);return;}
        struct aura_gatt_link fresh;aura_gatt_link_snapshot(&fresh);
        /* Confirmation is visible only after actual engine activation. */
        if(bytes!=AURA_SESSION_CONFIRM_BYTES||fresh.transfer_ready){
            if(!bytes){memcpy(value,"ASNO",4);bytes=4;}
            (void)aura_gatt_auth_publish(link.generation,value,bytes);
        }
        memset(value,0,sizeof(value));
    }
}
static int enroll(const char *argument, bool provision)
{
    radio_lock();
    uint8_t bytes[88]; int result = unhex(argument, bytes, sizeof(bytes));
    if (result) { memset(bytes, 0, sizeof(bytes)); return result; }
    struct aura_release_auth_context context;
    memcpy(context.device_id, bytes, 16); memcpy(context.storage_incarnation, bytes+16, 16);
    memcpy(context.owner_id, bytes+32, 16); context.owner_generation=sys_get_le64(bytes+48);
    memcpy(context.key, bytes+56, 32); memset(bytes, 0, sizeof(bytes));
    if (memcmp(context.device_id, device_id, 16)) result=-EACCES;
    else {
        struct aura_control_config config = {.blocks={1022,1023}};
        memcpy(config.domain, context.storage_incarnation, 16);
        struct aura_storage_io io = {.data=aura_w25n01gv_zephyr_io(&nand),
            .control=aura_w25n01gv_zephyr_control_io(&nand), .erase_released=NULL};
        if (provision) result=aura_storage_provision(&storage, io, &config, &context,
            &journal, &control, snapshot, sizeof(snapshot));
        else result=aura_storage_open(&storage, io, &config, &context,
            &journal, &control, snapshot, sizeof(snapshot));
    }
    if(!result){
        result=aura_transfer_init(&transfer,&journal,storage.authority.device_id,storage.authority.storage_incarnation);
        if(!result)result=aura_session_auth_init(&session_auth,&storage.authority,session_random,NULL);
        transfer_ready=result==0;
    }
    memset(&context, 0, sizeof(context)); return result;
}
static int begin(const struct request *request)
{
    /* New pairing/settings work must not begin during capture. Existing L4
     * owner sessions may survive the separate transfer preemption below. */
    aura_pairing_close();
    k_work_schedule(&radio_work,K_NO_WAIT);
    struct aura_gatt_link link;aura_gatt_link_snapshot(&link);
    struct aura_gatt_owner_gate preempt={.connection_generation=link.generation,
        .authorization=AURA_GATT_DENIED,.capture_preempt=true};
    if(aura_session_auth_granted(&session_auth,link.generation,(uint64_t)k_uptime_get(),link.secure_l4))
        preempt.authorization=AURA_GATT_GRANTED;
    (void)aura_gatt_owner_tick(&transfer,&preempt);
    if (epoch==UINT64_MAX || atomic_get(&audio.state)==AURA_AUDIO_QUARANTINED) return -EOVERFLOW;
    atomic_set(&session_generation, request->stop_generation); atomic_set(&startup_pending, 1);
    atomic_set(&capture_gate, 1);
    if (!permitted(NULL)) { atomic_clear(&capture_gate); atomic_clear(&startup_pending); return -EACCES; }
    struct aura_archive_manifest settings={.frame_samples=320,.pre_skip=40}, manifest;
    int result=aura_storage_prepare_capture(&storage, &settings, &manifest);
    if (result) { atomic_clear(&capture_gate); atomic_clear(&startup_pending); return result; }
    memcpy(capture_id, manifest.capture_id, 16); ++epoch;
    service_max_us=late_services=fifo_high_water=0;
    /* Retry only the same reserved manifest. Cancellation remains visible in
     * permitted() across all storage preparation and microphone-start races. */
    do {
        if (!permitted(NULL)) { result=-ECANCELED; break; }
        result=aura_audio_zephyr_begin(&audio, &manifest, epoch);
        if (result==AURA_JOURNAL_RETRY_PREPARE) k_msleep(1);
    } while (result==AURA_JOURNAL_RETRY_PREPARE);
    if (result && journal.active < 0 && journal.binding_pending)
        (void)aura_storage_cancel_prepared(&storage);
    if (result) atomic_clear(&capture_gate);
    else started_ms=(uint64_t)k_uptime_get();
    atomic_clear(&startup_pending);
    return result;
}
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
int main(void)
{
    if(!device_is_ready(uart)||!gpio_is_ready_dt(&privacy)||!gpio_is_ready_dt(&led))return -ENODEV;
    uint8_t uid[8],message[32]={0},digest[32];
    if(hwinfo_get_device_id(uid,sizeof(uid))!=sizeof(uid))return -ENODEV;
    memcpy(message,"AURA-A04-BENCH-DEVICE-v1",24);memcpy(message+24,uid,8);
    aura_archive_sha256(message,sizeof(message),digest);memcpy(device_id,digest,16);
    int result=gpio_pin_configure_dt(&privacy,GPIO_INPUT);
    if(!result)result=gpio_pin_configure_dt(&led,GPIO_OUTPUT_INACTIVE);
    if(!result)result=aura_recorder_init(&recorder,&journal,encoder.bytes,sizeof(encoder.bytes));
    if(!result)result=aura_audio_zephyr_init(&audio,DEVICE_DT_GET(DT_NODELABEL(pdm0)),mic,
                                          permitted,NULL,&recorder,AURA_AUDIO_MEAN);
    if(result)return result;
    atomic_set(&initialized,1);
    gpio_init_callback(&privacy_callback,privacy_changed,BIT(privacy.pin));
    result=gpio_add_callback(privacy.port,&privacy_callback);
    if(!result)result=gpio_pin_interrupt_configure_dt(&privacy,GPIO_INT_EDGE_BOTH);
    if(result)return result;
    result=uart_irq_callback_user_data_set(uart,uart_input,NULL);if(result)return result;
    aura_gatt_init();
    result=aura_pairing_init();
    if(!result)result=bt_enable(NULL);
    if(!result)result=settings_load();
    if(result)atomic_set(&radio_fault,result);
    printk("AURA radio DK development; microphone off; local OPEN/PROVISION then PAIR/RADIO; no wearable qualification.\n");
    uart_irq_rx_enable(uart);
    k_thread_create(&reader_thread,reader_stack,K_THREAD_STACK_SIZEOF(reader_stack),
                    reader,NULL,NULL,NULL,K_PRIO_PREEMPT(4),0,K_NO_WAIT);
    k_thread_create(&storage_thread,storage_stack,K_THREAD_STACK_SIZEOF(storage_stack),
                    owner,NULL,NULL,NULL,K_PRIO_PREEMPT(7),0,K_NO_WAIT);
    return 0;
}

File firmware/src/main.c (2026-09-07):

/* SPDX-License-Identifier: MIT */
#include "aura.h"
#include "nand.h"
#include "gestures.h"
#include "pcm.h"
#include "maintenance.h"
#include <zephyr/settings/settings.h>
#include <zephyr/audio/dmic.h>
#include <zephyr/drivers/gpio.h>
#include <zephyr/drivers/i2c.h>
#include <zephyr/drivers/watchdog.h>
#include <zephyr/sys/atomic.h>
#include <zephyr/sys/byteorder.h>
#include <zephyr/sys/reboot.h>
#include <zephyr/fatal.h>
#include <errno.h>
#include <string.h>
struct aj_store aura_store;
K_MUTEX_DEFINE(aura_store_lock);
volatile uint8_t aura_state;
volatile bool aura_privacy = true, aura_charge_allowed;
volatile uint16_t aura_battery_mv;
static const struct gpio_dt_spec mic = GPIO_DT_SPEC_GET(DT_PATH(zephyr_user), mic_enable_gpios),
                                 record = GPIO_DT_SPEC_GET(DT_PATH(zephyr_user), record_gpios),
                                 privacy =
                                     GPIO_DT_SPEC_GET(DT_PATH(zephyr_user), privacy_off_gpios),
                                 charge =
                                     GPIO_DT_SPEC_GET(DT_PATH(zephyr_user), charge_allow_gpios),
                                 haptic =
                                     GPIO_DT_SPEC_GET(DT_PATH(zephyr_user), haptic_enable_gpios);
static const struct device *pdm = DEVICE_DT_GET(DT_NODELABEL(pdm0)),
                           *i2c = DEVICE_DT_GET(DT_NODELABEL(i2c0)),
                           *wdt = DEVICE_DT_GET(DT_NODELABEL(wdt0));
static uint64_t unix_anchor;
static int64_t uptime_anchor;
static struct k_spinlock time_lock;
static atomic_t wanted, storage_ready, mark_pending;
static bool format_intent;
static uint32_t id_floor = 1;
static int64_t maintenance_until;
static bool haptic_ready;
static int watchdog_channel = -1;
static atomic_t audio_heartbeat;
static struct gpio_callback privacy_cb;
K_MEM_SLAB_DEFINE_STATIC(audio_slab, 2560, 8, 4);
K_THREAD_STACK_DEFINE(audio_stack, 4096);
static struct k_thread audio_thread;
bool aura_capture_pending(void)
{
    return atomic_get(&wanted) != 0;
}
static int load_maintenance(const char *key, size_t len, settings_read_cb read, void *arg)
{
    if (!strcmp(key, "nextid") && len == 4) {
        uint8_t bytes[4];
        if (read(arg, bytes, 4) != 4)
            return -EIO;
        id_floor = sys_get_le32(bytes);
        return id_floor ? 0 : -EINVAL;
    }
    if (strcmp(key, "erase") || len != 1)
        return -ENOENT;
    uint8_t value = 0;
    int r = read(arg, &value, 1);
    if (r != 1)
        return -EIO;
    format_intent = value != 0;
    return 0;
}
SETTINGS_STATIC_HANDLER_DEFINE(aura_persistence, "aura", NULL, load_maintenance, NULL, NULL);
static int save_intent(bool enabled)
{
    if (aura_store.next_id > id_floor)
        id_floor = aura_store.next_id;
    if (aura_store.next_id < id_floor)
        aura_store.next_id = id_floor;
    uint8_t id[4];
    sys_put_le32(id_floor, id);
    int r = settings_save_one("aura/nextid", id, 4);
    if (r)
        return r;
    uint8_t v = enabled ? 1 : 0;
    r = settings_save_one("aura/erase", &v, 1);
    if (!r)
        format_intent = enabled;
    return r;
}
int aura_format(void)
{
    /* Called with the storage mutex held; a new physical gesture is required per attempt. */
    if (!atomic_get(&storage_ready) || aura_store.fault || aura_state == 1 || aura_state == 2 ||
        atomic_get(&wanted) || k_uptime_get() >= maintenance_until ||
        !aura_all_deleted(&aura_store))
        return -EPERM;
    maintenance_until = 0;
    atomic_clear(&storage_ready);
    aura_state = 2;
    gpio_pin_set_dt(&charge, 0);
    aura_charge_allowed = false;
    int r = aura_erase_run(&aura_store,
                           (struct aura_maintenance_io){save_intent, aura_nand_erase_block}, false);
    if (r) {
        aura_store.fault = true;
        aura_state = 4;
    } else {
        atomic_set(&storage_ready, 1);
        aura_state = aura_privacy ? 3 : 0;
    }
    return r;
}
uint64_t aura_time(void)
{
    k_spinlock_key_t k = k_spin_lock(&time_lock);
    uint64_t t = unix_anchor ? unix_anchor + (k_uptime_get() - uptime_anchor) / 1000 : 0;
    k_spin_unlock(&time_lock, k);
    return t;
}
void aura_set_time(uint64_t time)
{
    k_spinlock_key_t k = k_spin_lock(&time_lock);
    unix_anchor = time;
    uptime_anchor = k_uptime_get();
    k_spin_unlock(&time_lock, k);
}
static void fail_off(void)
{
    gpio_pin_set_dt(&mic, 0);
    gpio_pin_set_dt(&charge, 0);
    aura_charge_allowed = false;
    atomic_clear(&wanted);
}
void k_sys_fatal_error_handler(unsigned int reason, const struct arch_esf *esf)
{
    ARG_UNUSED(reason);
    ARG_UNUSED(esf);
    if (gpio_is_ready_dt(&mic))
        gpio_pin_set_dt(&mic, 0);
    if (gpio_is_ready_dt(&charge))
        gpio_pin_set_dt(&charge, 0);
    if (gpio_is_ready_dt(&haptic))
        gpio_pin_set_dt(&haptic, 0);
    sys_reboot(SYS_REBOOT_COLD);
}
static void privacy_interrupt(const struct device *dev, struct gpio_callback *cb, uint32_t pins)
{
    ARG_UNUSED(dev);
    ARG_UNUSED(cb);
    ARG_UNUSED(pins);
    if (gpio_pin_get_dt(&privacy) != 0) {
        gpio_pin_set_dt(&mic, 0);
        atomic_clear(&wanted);
        aura_privacy = true;
    }
}
static int gauge_read(void)
{
    uint8_t bytes[2];
    int r = i2c_burst_read(i2c, 0x36, 0x02, bytes, 2);
    if (r) {
        aura_battery_mv = 0;
        return r;
    }
    aura_battery_mv = ((uint32_t)sys_get_be16(bytes) * 625) / 8000;
    return 0;
}
static int haptic_init(void)
{
    if (!IS_ENABLED(CONFIG_AURA_HAPTIC_QUALIFIED))
        return 0;
    /* Conservative engineering target only. C08-00A: 0.84 Vrms, 240 Hz.
     * DRV2605L datasheet equations: sample_time=300us, DRIVE_TIME=2.1ms.
     * Rated register round(0.84*sqrt(1-(4*.0003+.0003)*240)/.02058)=33.
     * Clamp round(1.20/.02133)=56, below candidate 1.25V maximum.
     * Scope RMS/peaks and verify resonant behavior before qualifying this option. */
    gpio_pin_set_dt(&haptic, 1);
    k_msleep(2);
    uint8_t status;
    int r = i2c_reg_read_byte(i2c, 0x5a, 0, &status);
    if (r || (status >> 5) != 7)
        goto fail;
    const uint8_t regs[][2] = {{1, 0},       {0x16, 33},   {0x17, 56},   {0x1a, 0xb6}, {0x1b, 0x14},
                               {0x1c, 0xf5}, {0x1d, 0x80}, {0x1e, 0x30}, {1, 7},       {0x0c, 1}};
    for (unsigned n = 0; n < ARRAY_SIZE(regs); n++)
        if (i2c_reg_write_byte(i2c, 0x5a, regs[n][0], regs[n][1]))
            goto fail;
    for (int n = 0; n < 100; n++) {
        uint8_t go;
        if (i2c_reg_read_byte(i2c, 0x5a, 0x0c, &go))
            goto fail;
        if (!go) {
            if (i2c_reg_read_byte(i2c, 0x5a, 0, &status) || status & 0x08)
                goto fail;
            haptic_ready = true;
            gpio_pin_set_dt(&haptic, 0);
            return 0;
        }
        k_msleep(10);
    }
fail:
    gpio_pin_set_dt(&haptic, 0);
    return -EIO;
}
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

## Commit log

2026-09-07 Integrate validated enclosure model and refine the product presentation
2026-09-07 Add Blender enclosure, printable shells, product renders and fit audits
    [aura-front-shell.stl, aura-product.blend, aura-rear-shell.stl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]
2026-09-07 Add interactive assembly explorer and refine A02 product presentation
2026-09-07 Publish A03 printable capsule, refreshed 3D showcase and cinematic launch film
    [aura-contact-carrier.stl, aura-dock-alignment-jig.stl, aura-fit-coupon.stl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]
2026-09-07 Document A03 engineering limits and verify private notes and public deployment
    [assembly-bom.csv, aura-a02-corrected.dsn, aura-a02-routing-draft.kicad_pcb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]
2026-09-07 Add reproducible 3D assembly sequence and film verification
2026-09-07 Synchronize final component model, printable package and assembly film
    [aura-product.blend]
2026-09-08 Publish connected A03 prototype package and synchronized product design
    [a03-audio.kicad_sch, a03-charging.kicad_sch, a03-controls.kicad_sch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]
2026-09-08 Add pendant, printable parts, PCB and launch film to README
2026-09-08 Study Omi, document A04 assembly blockers, and harden companion recovery
2026-09-08 Begin circular A04 MCP design with verified codec and fit studies
    [a04-audio-controls.kicad_sch, a04-battery-thermal.kicad_sch, a04-coupon-layout.blend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]
2026-09-08 Connect A04 audio archives to source-preserving local notes
    [host-configure.txt]
2026-09-08 Publish A04 mechanism trials with auditable assembly findings
    [01_front_housing_with_bail.stl, 02_captive_face_paddle.stl, 03_face_retainer.stl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]
2026-09-08 Add an audited MCP privacy-switch footprint candidate
2026-09-08 Keep footprint evidence paths portable across checkouts
2026-09-09 Audit A04 purchasing and assembly-export attributes
2026-09-09 Implement recoverable A04 Opus NAND storage and SPI driver
    [host-configure.txt]
2026-09-09 Add checked A04 M2 enclosure mechanism and inspection renders
    [01_fixed_cup.stl, 02_threaded_bezel.stl, 03_pcb_clamp_and_face_guide.stl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]
2026-09-09 Strengthen A04 M2 mechanism with captured spring-steel supports
    [01_fixed_cup.stl, 03_pcb_clamp_and_face_guide.stl, 04_captive_face.stl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]
2026-09-09 Add mesh-matched steel support development drawings
    [m2-s1-lower-support-profile.dxf, m2-s1-shoe-profile.dxf]
2026-09-09 Add durable capture ownership and authenticated release integration
    [host-configure.txt]
2026-09-09 Add nRF52840 audio and NAND bench with verified UART export
2026-09-09 Add bounded A04 journal export and phone response framing
    [host-configure.txt]
2026-09-09 Add verified A04 transfer command owner and Android wire codec
    [transfer-wire-golden.tsv]
